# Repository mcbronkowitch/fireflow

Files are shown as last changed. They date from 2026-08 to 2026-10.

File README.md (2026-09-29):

<p align="center">
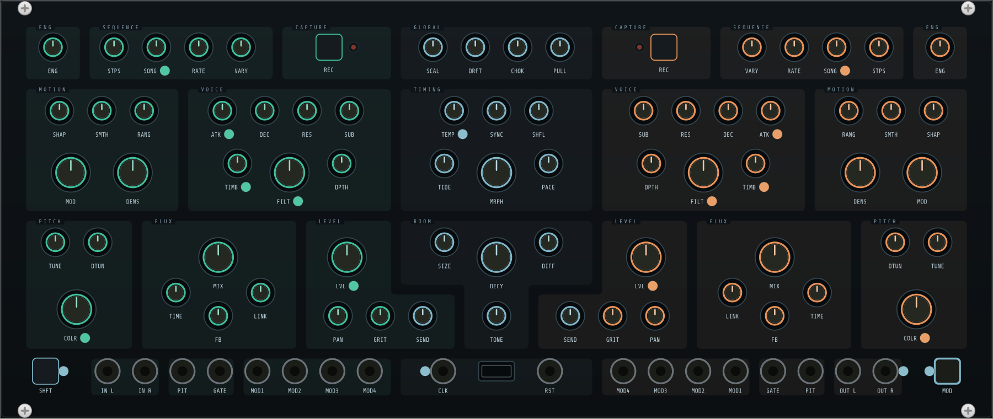
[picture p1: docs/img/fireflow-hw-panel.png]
The 60 HP FireFlow hardware panel: a dark plate with two mirrored halves — green A on the left, copper B on the right — each holding ENG, SEQUENCE and CAPTURE at the top, then MOTION and VOICE, then PITCH, FLUX and LEVEL. The centre column carries GLOBAL with SCAL, DRFT, CHOK and PULL, a TIMING gro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
  
</p>

# FireFlow — a modulation-first ambient groovebox

A digital instrument built around a single idea: **modulation is the
instrument**. Two symmetric parts, each driven by a performable modulation
engine, feeding a selectable sound source.

It runs today on the desktop and inside VCV Rack. The hardware target is a
**standalone Daisy Patch Submodule prototype**, brought up in milestone M6.

**Build log, audio demos and photos:** [fireflow.ton-k.de](https://fireflow.ton-k.de/)

> **⚠️ Not yet running on hardware.** The modulation engine currently exists
> only as a portable C++ core, verified with the desktop **offline renderer**
> (unit tests + audio/CV render) and playable through the VCV Rack host.
> Selected CPU workloads have been measured on a real Daisy Seed, and the control
> hardware is being measured on a test coupon; the firmware that turns the engine
> into a playable device is milestone M6, and it has not been built.

## What makes it different

The **modulation system is the primary interface**, and the sound engine is
whatever you point it at — not a sound engine you happen to be able to
modulate.

Each part currently points at one of five: a **polyphonic synth voice**, a
**granular texture deck** that granulates live input or a loaded sample,
**WAVE**, a digital-glassy PPG-style wavetable voice, **BODY**, a resonator
that morphs along a physical axis from plucked string through prepared piano to
struck bell, or **BBD**, a voiceless bucket-brigade delay that processes
whatever reaches it — audio input or the other deck — instead of playing
notes. The deck is deliberately not a second melodic instrument — it
is the room the synth part plays in; WAVE covers the bell, vocal-formant,
hollow-resonant, and bright-digital corner; BODY is the struck and bowed one,
and it can be excited by its own echo, by the other deck, or by the audio
input; BBD is the one deck with nothing to trigger — it has no notes, so its
five modulation lanes drive the delay's clock, feedback and mix instead of
pitch and timbre, and its own voice row retunes ATTACK/DECAY/RESONANCE/SUB/
FILT into the delay's freeze, tail, feedback tilt, input level and loss-pole
brightness. All five sit behind the same five modulation lanes and the same
voice row, so no knob goes dead when you flip the engine.

That voice-row **SOURCE** control is contextual — **TIMB** on Synth, **FRAME**
on WAVE, **MATL** on BODY, **ORG** on Sampler, and **DRIVE** on BBD — while
**Detune A/B** remains an independent per-part setting.

On the texture deck, **STEP** walks a `SliceMap` of transients marked while the
buffer is recorded or loaded: each phrase fire spawns one grain on a real
attack in the material. MOTION moves that walk from ordered playback at zero
toward free traversal. **DENS** controls runtime grain overlap; **COLOR**
becomes **FEEL** in STEP, deriving accents from the material, and spreads the
cloud's pitch in FLOW. Material without enough transients falls back to the
even tempo grid automatically, so drones and pads stay playable. FLOW still
moves continuously across the same lanes regardless of engine.

Melodic **STEP** lanes keep two persistent full-pattern snapshots, A and B.
**FORM** chooses how those phrases are composed — TWO MOTIFS, ONE + VAR,
HIERARCHICAL, CALL / RESPONSE, or OSTINATO — while **SONG** independently
arranges them as AAAB, ABAB, ABBB, BUILD, ROTATE, MIRROR, or OFF. Structural
changes land on phrase boundaries; OFF keeps A evolving while B remains stored.
On the Rack panel the PLAY row is **STEP · FORM · SONG · NEW**. NEW rebuilds
the A/B pair and, on a Sampler, also spawns a grain immediately.

Those STEP notes are not all the same note. Each deck already ranks the slots
of its groove, and **DENSE** decides how far down that ranking it fires — so
the first slot to sound is the anchor and the ones DENSE reveals sit under it.
That ranking *is* the accent: it scales how hard a note is struck and how long
it rings (the ring-time half only once **DEC** is up), which gives a dense
pattern a contour instead of a machine pulse. No knob was added for it.

Each of the two **parts** is a **SuperModulator** — one performable macro
surface (RATE, SHAPE, DENSITY, SMOOTH, RANGE, MOD) sitting on top of
**five independent modulation lanes**, one per target. Every lane has its own
phase, its own random stream and its own probability dice, running at a fixed
musical ratio of the master rate. Shared character, independent motion: the
melody can rise while the filter falls. (A single output driving all targets
would just move everything in unison — a tremolo, not an instrument.)

Each lane can run as a smooth LFO (**FLOW**), a stepped sequence (**STEP**), or
grow, loop, or erode over time (**ENTROPY**). A center section -- **MORPH / COUPLE / DRIFT / SPOT / SETTLE** -- makes the
interaction between the two parts playable. One shared **Oliverb**-based
ambient reverb turns the room into an instrument (Doppler SIZE and a DECAY that
blooms past 100 %), while each deck has its own **SEND** dry/send mix into that
shared room (the centre **ROOM** group holds the reverb itself). CV + gate
outputs extend the modulation to the rest of the rack.

The full design intent lives in
[`docs/superpowers/specs/`](docs/superpowers/specs/); this README is a
self-contained summary of it.

## Architecture at a glance

One portable engine core, three hosts. No hardware type ever crosses into
`engine/`, so the exact same code runs in the desktop renderer, the VCV Rack
module, and (later) on the hardware prototype.

<p align="center">
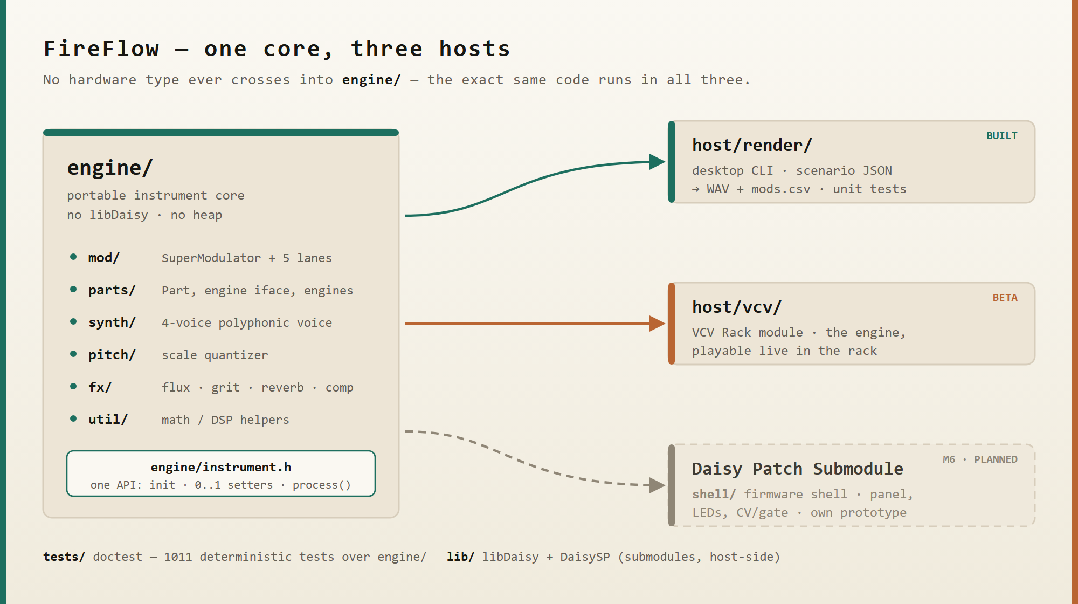
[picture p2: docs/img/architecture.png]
Architecture diagram: one portable engine/ core (mod, parts, synth, pitch, fx, util behind a single engine/instrument.h API) feeds three hosts — host/render (desktop CLI → WAV + mods.csv, built), host/vcv (VCV Rack module, beta) and the Daisy Patch Submodule prototype (shell/ firmware shell, M6, pl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
  
</p>

`Instrument` (`engine/instrument.h`) is the complete public API: `init(sample_rate)`,
normalized `0..1` parameter setters, and `process(in, out, size)`.

## Try it on the desktop (no hardware)

The engine is fully testable offline. You need a host C++ toolchain
(**clang** or gcc), **CMake**, and **Ninja**. doctest and nlohmann/json are
vendored under `third_party/`, so no test dependencies are fetched.

```bash
# optional: source a local env.sh to put your toolchain on PATH and set CC/CXX
source env.sh

cmake -S . -B build -DCMAKE_BUILD_TYPE=Release
cmake --build build
```

Run the unit tests:

```bash
ctest --test-dir build --output-on-failure
```

Configure with `-DCMAKE_BUILD_TYPE=Release`. Two of the six tests (`spky_tests`
and `ctrl_identity`) compare rendered audio against stored SHA-256 references,
and those were generated from an optimised build — a Debug configuration renders
slightly different floats and fails them with `SYNTH reference moved`.

Render a scenario to audio + a modulation trace. A scenario is a JSON timeline
of parameter changes (see `host/render/scenarios/`):

```bash
./build/render.exe host/render/scenarios/demo_step_melody.json out.wav mods.csv
```

This writes:

- **`out.wav`** — the rendered audio.
- **`mods.csv`** — every lane's output plus pitch CV / gate per part, decimated
  for plotting. Ideal for *seeing* what FLOW / STEP / MELODY actually do.

`demo_step_melody` is a good starting point: a fixed 16-step melody that loops
identically, then varies (GROW) or regenerates into new motivic phrases (RENEW)
as MELODY is dialled off center — and cycles the phrase principle.

## Play it now — VCV Rack (beta)

For a hands-on feel of the concept there's a **VCV Rack plugin** (`host/vcv/`)
that runs the same engine live — turn the knobs and hear the modulation engine
long before the M6 firmware. It's now a **beta**: real, playable Rack modules and
a permanent part of the workflow, not yet a finished instrument.

The plugin ships **two modules over the one engine core**. **FireFlow** is the
full surface: every engine setter on its own knob. **FireFlow HW Draft** is a
design study of the 60 HP hardware panel M6 is heading for, on the same engine.
Details in [`host/vcv/README.md`](host/vcv/README.md).

<p align="center">
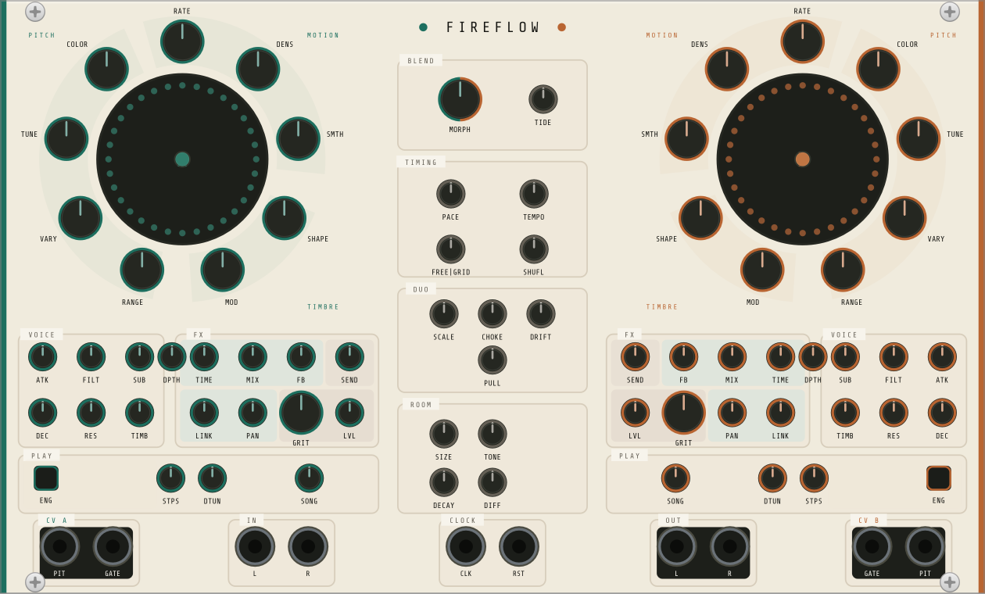
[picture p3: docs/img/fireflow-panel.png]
The FireFlow Rack module: two mirrored halves on a bone-coloured plate — green A on the left, copper B on the right — each with nine macro knobs orbiting an LED ring inside MOTION, TIMBRE and PITCH, above VOICE, FX and PLAY rows. The centre column holds BLEND, TIMING, DUO and ROOM, with the FIREFLO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
  
</p>

You can also just listen first: the [build log](https://fireflow.ton-k.de/)
carries recordings from most milestones, next to the story of how they came
about.

**[Download the latest release](https://github.com/mcbronkowitch/fireflow/releases/latest)**
— `.vcvplugin` builds for Windows, Apple Silicon and Linux, currently **2.22.0**
(both modules: Synth, Sampler, WAVE, BODY, BBD and FEED, the independent
FORM/SONG phrase arranger, the STEP mod grid lock, the PACE modulation
time-stretch, the redrawn 60 HP hardware plate with its excursion lamps, the
STEP accent, PULL's chord gravity, and the MOD layer — hold MOD and every
wreathed knob edits its own modulation depth). Unpack into Rack's user plugin
directory and restart Rack.

Building it yourself needs its own toolchain (a native MinGW/GCC compiler, not
the desktop clang path); the build, install and I/O details live in
[`host/vcv/README.md`](host/vcv/README.md).

## Roadmap

| Milestone | Scope | Status |
|---|---|---|
| **M1** | Portable engine foundation: SuperModulator, five lanes, `Instrument` API, desktop render host + tests | ✅ done |
| **M1.6** | FX: per-part FLUX (tape echo) + GRIT (drive/reduce), shared ambient reverb, FX params as modulation targets | **done** (engine + host) |
| **M2** | Polyphonic synth voice (replaces the M1 test tone) | **done** (engine + host) |
| **M3** | Capture sequencer (freeze the PITCH lane into a loop) | built, then **removed** 2026-07-14 as orthogonal to the melody rework; nothing replaced it |
| **M4** | Center section — MORPH / COUPLE / DRIFT / SPOT / SETTLE | **done** (engine + host) |
| **M4.5** | Ambient reverb v2 — Oliverb port: Doppler SIZE, DECAY > 100 % bloom, TONE; shimmer & LGPL removed | **done** (engine + host) |
| **M4.6** | Dynamics — one-knob comp per part + master limiter w/ master drive (captioned **PUSH** on the panel) | **done** (engine + host) |
| **M4.8** | Reverb dry/wet — equal-power MIX at the master join + clear-on-sleep CPU bypass | **done** (engine + host) |
| **M4.9** | Reverb DIFFUSION knob (replaces DEPTH) — room density 0–0.9, weak line-mod coupling | **done** (engine + host) |
| **M4.10** | Chord layer — COLOR knob, diatonic stacks, voice-leading, live FLOW surface | **done** (engine + hosts; hardware placement deferred) |
| **M5** | Sampler -- the texture deck: granular cloud, live recording + overdub, WAV load/save, Morphagene-style DENS/SCAN/NEW/LEN/ORG controls, clocked slice-groove, FEEL accents, and FLOW cloud dispersion | **done** (engine + hosts; released through 2.11.0) |
| **M5h** | Per-deck **SEND** mix: independent dry/send mix per deck into one shared Oliverb reverb | **done** (engine + VCV panel; released in 2.11.0) |
| **CPU** | Three measured rounds on real hardware: `instrument_worst`'s worst block went from ~156 % of the audio-block budget to 94 %, and back up to 102 % when M5j's tape tap landed (measured at 5.4 % of the block). Since then an optimization ladder (DTCM placement, an ITCM audio hotset, `-O3`) brought the selected gate `instrument_worst_bbd_dtcm` to **96.43 %** of the block on a Daisy Seed, and the whole signal path has been re-measured against it. **The engine's own worst case still does not fit**: on a Patch Submodule `instrument_worst` reads 102.27 % average / 108.62 % maximum, and whether that is a reachable operating point is an open question. Two more caveats live in `docs/roadmap.md`: every workload is more expensive on the submodule than on the Seed (reserve 2.17 points, so no Seed figure may be quoted for a submodule claim), and the intended ITCM placement does not currently link at the optimization level that ships. A debug probe is no longer needed — the bench also reports over USB-CDC. Method and every number in [`bench/`](bench/README.md) and [`docs/bench/`](docs/bench/) | **done** (ongoing as a tool) |
| **M5i** | WAVE: four-voice PPG-style wavetable part engine | **done** (engine + renderer + VCV; 65,024-byte mapped-QSPI bank; hardware-gated; released in 2.13.0) |
| **+ FORM/SONG** | Persistent A/B phrase snapshots: five FORM phrase engines plus AAAB, ABAB, ABBB, BUILD, ROTATE, MIRROR, and OFF SONG arrangements; boundary-safe changes and legacy patch migration | **done** (engine + renderer + VCV; released in 2.13.1) |
| **M5j** | BODY: one-voice-per-deck resonator part engine, morphing string -> metal -> bell, with a sympathetic excitation bus | **done** (engine + renderer + VCV; hardware-gated: `body_2x4` 295078 cycles, 30.7 % of the block, inside the spec's 29-32 % prediction and cheaper than SYNTH) |
| **BBD** | A bucket-brigade delay model, where the clock rate *is* the delay time — so RATE bends stored pitch **only transiently, while it moves**: held steady, a bucket-brigade line's pitch is unity at any clock rate. It first replaced FLUX's tape echo everywhere and now lives on as the fifth part engine only; FLUX itself is a plain tape echo again. `FXT_FLUX_TIME` is a genuine chorus/vibrato modulation lane, and STAGES has moved onto the BBD deck's own pitch lane, captioned **BEND** on the panel | **done** (engine + renderer + VCV; released in 2.17.0/2.17.1, measured on hardware — `inst_bbd_engine_worst` 96.91 % of the block at `-O3`) |
| **Modulation reachability** | Four rounds that made the modulation surface mean what it says: **PACE**, one global time-stretch from ×1/32 to ×4, because TEMPO was inert in the free world and TIDE never reached the melodic lane; the **FLOW melody engine**, so the free mode's melodic lane walks an 8-slot phrase instead of a continuous LFO; the same phrase in **STEP**, which makes FORM and SONG audible at every SHAPE position instead of only above 0.75; and **SMOOTH as a fraction of the lane interval** rather than absolute seconds, so the knob means the same thing at every rate | **done** (engine + hosts; released in 2.21.2) |
| **60 HP plate** | The hardware panel, drawn and playable in Rack as the second module: seven engine-grounded groups, eight CV inputs under the knobs they drive, and a dark anodised plate with framed fields and numbered legends | **done** as a design study (released in 2.21.2/2.21.3; still labelled `DRAFT`, no hardware ordered) |
| **STEP accent** | STEP notes get a contour from the groove rank the deck already computes: the anchor slot is loudest and longest, the slots DENSE reveals sit under it, on velocity and — once DEC is up — on ring time. No new control, no new randomness, FLOW unaffected; SYNTH, WAVE and BODY only | **done** (engine; released in 2.21.4) |
| **LED feedback** | What the panel shows while it runs: a lamp tracks the modulation **excursion**, never the knob position — one per texture lane, plus a phrase lamp per deck, a ceiling lamp for the limiter's audible onset, and the two modifier lamps. Nineteen lamps on the hardware plate, up from ten | **done** (engine + VCV `FireflowHW`; released in 2.21.5; four brightness constants still wait on real hardware) |
| **FEED** | Sixth part engine: a ring of six two-operator FM pairs per deck, free-running, where BOND morphs each modulator's input from its own feedback into its neighbour's output — the motion is the coupling, not an LFO on top | **done** (engine + hosts; released in 2.21.6; measured on a Patch Submodule, seventeen by-ear constants still first-try) |
| **M5l** | PULL: chord gravity between the two decks — a bipolar centre knob draws one deck's melody onto the other's sounding chord | **done** (engine + both VCV panels; released in 2.21.8; no listening pass yet) |
| **MOD layer** | Hold MOD and every wreathed knob shows and edits its own modulation depth instead of its sound value. The depth knobs are bipolar: right of noon the lane's continuous output, left of noon the same lane sampled and held on its own slots, noon off | **done** (engine + VCV `FireflowHW`; released in 2.21.7 and 2.21.10) |
| **AIR** | Noise/formant texture engine (working title): filtered noise through a resonant bank — wind, breath, vowel colours without sample material | planned (no spec yet) |
| **M5k** | ZAP: monophonic percussion part engine | planned (spec ready; not implemented) |
| **M6** | Hardware prototype: bring-up on a Daisy Patch Submodule — panel, controls, LEDs, CV/gate I/O, preset persistence | planned after AIR and M5k (panel design **done**, see above; **bring-up under way on a test coupon** — built 2026-09-17, measured in five rounds up to 2026-09-28; the panel scan's part 1 is built and measured on the coupon, part 2, the panel's table, waits on the pin map of Rev A, one board since 2026-09-28) |

Per-milestone detail and current status live in [`docs/roadmap.md`](docs/roadmap.md).

## Hardware prototype (M6)

The instrument's own hardware is a **standalone Daisy Patch Submodule**
prototype — panel, controls, LEDs, CV/gate I/O and preset persistence — planned
as milestone **M6**, after the two remaining engine milestones. Its **panel is
designed**, and you can turn it: the plugin's second module, **FireFlow HW
Draft**, is that 60 HP surface on the same engine, generated from
`host/vcv/res/gen_hw_panel.py` and guarded against the spec's own coordinates.

The **bring-up is under way on a test coupon** (`hardware/coupon/`): a small
board carrying the real multiplexers, shift registers, pots and reference
dividers, built on 2026-09-17 and driven by the probe firmware in `shell/`.
Five measurement rounds have run on it — settle time, crosstalk, the codec's
tone, the wait between conversions, and the pots themselves — each written up
under `docs/hardware/` (`settle-measured.md` … `pots-measured.md`). **Part 1 of
the panel scan is built and measured on the coupon**: it reads the mux pattern
cleanly and plays the engine from three of the coupon's pots
(`docs/hardware/scan-measured.md`). **Part 2**, the table for a whole panel —
70 pots, keycaps, LEDs — waits on the pin map of Rev A, which is one board
since 2026-09-28.

CPU headroom on the target MCU is not guesswork, though. Selected workloads are
measured on real Daisy hardware (a Daisy Seed, which carries the same STM32H750
at 480 MHz as the Patch Submodule) — method and every number in
[`bench/`](bench/README.md) and [`docs/bench/`](docs/bench/).

The original Spotykach firmware this project started from was removed from the
tree on 2026-09-29; [`docs/upstream-firmware.md`](docs/upstream-firmware.md)
says where it went and what of it stayed.

## License & credits

MIT — see [`LICENSE`](LICENSE) (Copyright © 2026 Synthux Academy, Bastian Tonk).

FireFlow began as a fork of
[Synthux-Academy/Spotykach](https://github.com/Synthux-Academy/Spotykach), the
official firmware for the Spotykach hardware, and reuses parts of it; it is now
an independent project with its own hardware target. It was called **spotymod**
until 2026-08-04 — releases up to and including 2.18.x carry that name.
Bundled and submodule dependencies are documented in
[`THIRD_PARTY.md`](THIRD_PARTY.md). Original firmware credits are in
[`CREDITS.md`](CREDITS.md).

Built with AI pair-programming — the **HAL 9000** co-author in the git history
is [Claude](https://www.anthropic.com/claude) (Anthropic). 🔴

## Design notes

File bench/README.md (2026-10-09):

# bench

## What this is

A measurement app that has never shipped and never will. It boots the Daisy
Seed straight into a cycle-counting harness instead of the FireFlow firmware,
runs a fixed table of workloads, and reports cycle counts and checksums back
over the debug probe. The shipping firmware is `shell/`, with its own
`Makefile` and `main.cpp`; nothing under `bench/` touches it, and the two
share exactly one board-init file, `src/hw/board.h`. This directory has its
own `Makefile`, its own `main.cpp`, and links against `alt_sram.lds` — the
same BOOT_SRAM placement `shell/` uses — so the timing context (SRAM vs SDRAM
latency) matches production.

## Profiles, and one command per profile

The bench image cannot hold every workload family at once — at `d294556` it
linked with 40 bytes of `SRAM_EXEC` and 24 bytes of `SRAM` to spare, and the
next engine took it over. A profile selects which families an image
contains.

`bench/profiles.py` is the source of truth for what ships. On this branch:

| profile | families | purpose |
|---|---|---|
| `system` | system | carries the WAVE acceptance gate; fits comfortably |
| `body` | system, body | the M5j gate: prices the BODY mode bank and KS pair |
| `bbd` | bbd | the BBD gate, on its own; no system anchor (reports undetermined) |
| `sweep` | system, sweep | the cost-curve round; system anchor prevents undetermined verdict |
| `regress` | system, bbd | gate rows and BBD kernel rows in one image, for any gate-versus-BBD A/B (introduced by the 2026-08-04 signal-path round); **`axi` only — `--itcm-hot` cannot pass placement at any optimization level, see below** |
| `ablate` | system, instr | the instrument-level ablation; measures the worst-case instrument build |
| `full` (default) | system, voice, mem, mod, abl, bbd, body, sampler | the complete run, as before profiles existed |

**`regress --itcm-hot` cannot produce a usable image, at any optimization
level, and the failure is not yours.** `spky::BbdLine::Process` is a weak
symbol; under `regress` the linker keeps the copy in the bench-harness TU
`build/workloads_bbd.o`, which `itcm_hot.lds` does not list, so the surviving
symbol lands outside ITCM and `itcm_placement.py` fail-closes. At `-O3` a
second, independent failure sits on top: the hot section overflows the 64 KiB
region and does not link. Do **not** add `workloads_bbd.o` to the hotset —
that places bench-harness code in ITCM and distorts every measurement ever
taken there. Run `regress` with `axi` until the hotset definition is reworked
(M6 work). Measured in
`../docs/bench/2026-08-04-2101349-signal-path-regression.md`.

**`full` currently fails to link, and that is deliberate, not broken.** The
engine has outgrown the image; no profile change fixes that on its own (see
the history above), and the point of profiles is to make forward progress
possible without hiding the debt. Running `python run.py` with no
`--profile` resolves to `full` and fails at the link step with an
SRAM/SRAM_EXEC region overflow. For a build that actually links and
measures today, name a profile:

```
python run.py --profile system
```

From `bench/`. This builds the bench firmware for the named profile,
verifies that the separately programmed WAVE bank matches the current
linked QSPI payload, loads only the SRAM side of the image through the
debug probe, and captures its semihosting output **twice** (`--repeat 2` is
the default — see "Anchor mode's audio" below for what that means out
loud), compares the two runs' unique row sets and checksums, enforces every
 gate the profile declares on every run, and writes both complete captures
 to `../docs/bench/YYYY-MM-DD-<githash>-<profile>-<layout>-<optimization>.md`
 and `.csv`. The layout is `axi` by default or `itcm-hot` with `--itcm-hot`.
 The optimization identity is `o2` (the default, `-O2`), `o3` (`-O3`), or
 `o3-lto` (`-O3 -flto`), selected with `--optimization`. The CSV carries a
 run index, the profile name, the execution layout, optimization identity, the live QSPI
 payload digest, and a SHA-256 device fingerprint on every row; the Markdown records those
identities, a gate ledger (which gates ran and passed, and which were not
applicable and why), and both offline/anchor tables. Exit code 0 means at
least two runs passed every gate the profile declares and both were
persisted. A missing/extra/duplicate row, checksum drift, identity drift,
non-numeric WAVE result, WAVE result slower than SYNTH, or WAVE maximum at
or above the 960,000-cycle block budget exits nonzero and writes no
accepted evidence. Every profile-derived callback anchor must appear exactly
once with finite numeric values, and every decision-gate row must be numeric;
malformed/timeout gate data exits nonzero before CSV, Markdown, or a combined
program-and-run receipt is persisted. A valid over-budget DTCM+BBD result is
still archived as rejected evidence rather than being treated as malformed.

Useful flags: `--profile NAME` (default `full`; see the table above and
`bench/profiles.py` for what ships), `--repeat N` (default and minimum 2),
`--out-dir DIR` (default `../docs/bench`), `--build-only`, `--no-build`,
 `--timeout SECONDS` (default 600, per run), `--interface CFG` (see below),
 `--program-qspi`, `--itcm-hot`, and `--optimization {o2,o3,o3-lto}`.
 `--itcm-hot` links the pre-registered audio hotset into ITCM and makes
 `run.py` inspect the linked ELF before any QSPI helper or benchmark SRAM load.
 The preflight fails closed if `nm`, `objdump`, or `readelf` is unavailable,
 or if the hot section, load segment, representative symbols, or DTCM
 instrument storage are missing or misplaced. Use the flag consistently for
 build, QSPI binding, and measurement so the host can reject an AXI/ITCM
 mix-up.

The bench builds without `-ffast-math -funroll-loops`. The Makefile used to
name them in `C_USR_FLAGS`, which libDaisy never reads; the completed
compiler-mode selection deliberately did not activate them, and the dead line
was removed on 2026-10-09. The benchmark reports its requested `o2`, `o3`, or `o3-lto`
identity; the measured winner is `o3`, the shipping firmware sets
`override OPT := -O3` (`shell/Makefile`), and LTO remains rejected.

## Programming the WAVE bank

The 65,024-byte bank is a loadable `.qspiflash_data` section at
`0x90100000`. It sat at `0x90040000` until 2026-08-07, which is the Daisy
bootloader's own target address for a `BOOT_SRAM` app image — see
*Two transports* below for the map and why that address is off limits.
It is deliberately not part of the debug probe's SRAM load. The build creates
four distinct artifacts:

- `build/bench.elf`: authoritative linked image and map source;
- `build/bench-sram.elf`: `.qspiflash_data` removed; the ELF OpenOCD loads
  for measurement;
- `build/bench-qspi.bin`: only `.qspiflash_data`, exactly 65,024 bytes;
- `qspi_programmer/build/qspi-programmer.elf`: a temporary SRAM-only helper
  used solely to erase, write, compare, and hash that raw payload.

Do not use `make program-dfu` for this custom layout. libDaisy's generic rule
expects one flat `build/bench.bin` beginning at the BOOT_SRAM app address;
an image spanning SRAM and QSPI is not that format. `run.py` builds only the
ELF and extracts the two physical payloads explicitly.

Before the first WAVE run, or whenever `bench-qspi.bin` changes, run the
four steps below. Every command names `--profile system`: it is the only
profile that links today (see "Profiles, and one command per profile"
above — the WAVE bank itself, `engine/synth/wt_bank.cpp`, is compiled
unconditionally regardless of profile, so any linking profile would carry
the same 65,024 bytes, but `system` is also the profile that exercises the
WAVE acceptance gate this bank is for), and steps 1, 3, and 4 must agree on
it exactly: the identity check in step 4 compares that rebuild's
ELF/SRAM-ELF/QSPI/programmer-ELF hashes against the receipt step 3 wrote,
and a different profile produces a different ELF even when the QSPI bytes
are unchanged.

1. Build with `python run.py --profile system --build-only`.
2. Connect the ST-Link to the Seed's SWD header and power the Seed.
3. Run `python run.py --profile system --no-build --program-qspi --build-only`.
   Do not put the Seed into DFU mode. (`--no-build` means this step doesn't
   use `--profile` to rebuild anything — it just re-derives the QSPI payload
   from whatever `bench.elf` step 1 left behind — but passing `system` here
   too keeps the sequence consistent and avoids relying on that detail.)
4. Run `python run.py --profile system --repeat 2`.

For an ITCM-hotset experiment, append `--itcm-hot` to commands 1, 3, and 4.
Each command then performs the same mandatory linked-placement preflight
before programming or loading the target.
Do not reuse an AXI QSPI receipt for an ITCM run (or vice versa): the receipt
is bound to the exact ELF, and the firmware-reported `BENCH_BEGIN` layout is
checked before any evidence is accepted.

The programming command uses OpenOCD to load the helper below `0x24040000`
and the raw payload at `0x24040000`; it never programs internal flash. The
helper erases one 64 KiB external-QSPI block at offset `0x100000`, writes
exactly 65,024 bytes, invalidates the mapped cache, compares every byte at
`0x90100000`, and reports the live SHA-256 plus the MCU UID over semihosting.
Only an exact success record writes `build/qspi-verified.json`. The receipt
binds that target-verified digest and UID to `bench.elf`,
`bench-sram.elf`, `bench-qspi.bin`, and the helper ELF.
Even with `--no-build`, `run.py` re-inspects `bench.elf` and regenerates both
physical artifacts before accepting the receipt.

### The receipt breaks on any engine change, and step 1 is not optional

The heading above says "whenever `bench-qspi.bin` changes", which understates
it. The receipt binds the verified digest to the **ELF hashes**, so *any*
change under `engine/` invalidates it even though the bank's 65,024 bytes are
untouched. The failure looks like this:

```
ERROR: QSPI verification receipt does not match current payload (artifacts)
```

That message names the artifacts, not the bank, and it does not mean the QSPI
is corrupt or that a different Seed is attached — those have their own checks
(the live digest comparison and the MCU UID match). It means the binding is
stale. The fix is to re-run steps 1 and 3; nothing needs erasing.

**Do not skip step 1 and go straight to step 3.** With `--no-build`, step 3
binds to whatever `bench.elf` is lying on disk. If step 4 then relinks
anything — and it will, after an engine change, because step 4 rebuilds — the
hashes it computes differ from the ones step 3 wrote and the run aborts with
the message above, having already reprogrammed the bank for nothing. Build
first, bind second, measure third. Running it in the other order costs a full
programming cycle and reads like a hardware fault.

Every measurement also SHA-256 hashes the 65,024 live bytes through the
Seed's memory-mapped QSPI interface before `BENCH_BEGIN`; the host compares
 that firmware-reported digest with the extracted payload. `BENCH_BEGIN` also
 reports the Seed's 96-bit MCU UID, the `axi` or `itcm-hot` execution layout,
 and the requested optimization identity. The UID must strictly match the
 programming receipt, and every repeat must report the requested layout and
 optimization. Together these checks catch a different
 Seed, a later QSPI overwrite, blank/wrong QSPI, or a stale/mixed execution
 layout even if an old local receipt remains. Public CSV and Markdown evidence
 persist the payload digest and a stable SHA-256 fingerprint of that UID,
 not the raw device identifier. The exact audit receipt
 (`qspi-verified.json`) intentionally retains the raw UID because it is the
 device-binding record used to reject a different Seed. The tracked O2/O3
 receipts already follow that policy; their bytes and hashes are unchanged by
 this documentation correction. Hardware evidence is refused from a dirty Git
 tree.

Programming this address overwrites the leading bank region and therefore
invalidates whatever BOOT_SRAM/BOOT_QSPI application was previously stored
in the Daisy bootloader's app slot; remnants beyond the 65,024-byte write may
remain. The bench itself starts directly from SRAM through OpenOCD.

## Hardware setup

The measurement itself uses the debug probe's SWD cable: 4 wires (SWDIO,
SWCLK, GND, and 3V3, or just GND+SWD if the probe supplies its own power)
from the ST-Link to the Seed's SWD header. The Seed's micro-USB port is usable
as a power source but is not used for DFU or reporting. If anchor mode is
going to run (it always does, as part of the family-1 sweep), have
monitors connected to the Seed's audio out at **low volume** first — see
below for what you'll actually hear.

## The probe

This desk's probe is an ST-Link V3, and openocd needs `stlink-dap.cfg` to
get a real DAP out of it — that's `run.py`'s default and the value
confirmed working in Task 1. Plain `stlink.cfg` auto-selects the older
`hla_swd` transport, under which `spotykach-sram.cfg`'s
`transport select dapdirect_swd` line is an error, not a fallback path.

If a different probe is on the desk, the other candidates to try via
`--interface` are `cmsis-dap.cfg` (CMSIS-DAP probes) and `stlink.cfg`
(older ST-Link V2/V2-1 hardware, accepting the `hla_swd` limitation). Both
are untested against this bench.

## Reading the table

- **avg cyc / max cyc** — DWT cycle counter reading for the workload's
  `process()`, averaged and maxed over the repeated calls in one bench pass.
- **avg % / max %** — the same, as a percentage of `BUDGET_CYCLES` (960 000
  cycles: 480 MHz core clock, 96-sample block, 48 kHz). Over 100% means the
  workload alone would blow the audio block budget.
- **checksum** — an 8-hex-digit accumulator folded from every sample the
  workload produced. It exists so the compiler cannot optimise the workload
  away as dead code, and it is what the `--repeat 2` determinism check
  compares between runs. A workload whose output legitimately depends on
  uninitialized memory or wall-clock timing will show up here as drift.
- **TIMEOUT** — the row's `avg_cyc` field reads the literal string `TIMEOUT`
  (and `pct_avg`/`pct_max` are empty) when the workload ran past 10× the
  block budget; the runner aborts it rather than letting one bad workload
  hang the whole sweep. A `TIMEOUT` row still carries a `max_cyc` and a
  `checksum` from the point it was cut off.

## Fallbacks

**(a) If the SRAM load ever stops working**, use `--transport usb`, which
is that bootloader image path and now exists. Still do not reach for
libDaisy's generic `make program-dfu`: it programs one flat
`build/bench.bin` covering SRAM *and* QSPI, which is not this layout.
`run.py` writes `build/bench-sram.bin` — the ELF with `.qspiflash_data`
removed, flattened — and the bank is a separate write.

**(b) If semihosting itself is not available** — a board with no debug pins
soldered on, for instance — use the USB transport. It is no longer a
fallback sketch; it is built, measured, and described in *Two transports*
below. It was written here as untested for a long time; it is not untested
any more, and what it costs is known to the cycle.

## Two transports

`BENCH_TRANSPORT` picks how a number leaves the board. `semihost` is the
default and the transport every capture in `docs/bench/` before 2026-08-07
was taken over.

| | `semihost` | `usb` |
|---|---|---|
| Wire | SWD, ARM `bkpt 0xAB` serviced by openocd | USB-CDC |
| Loader | openocd writes the SRAM image directly | `dfu-util` via the Daisy bootloader |
| Needs | an ST-Link on the SWD header | the bootloader in internal flash, and the cable that already powers the board |
| Repeats | openocd resets between them | the bench returns to the bootloader itself |
| Costs | nothing | **+0.66 % of the block budget** |

Run it with `python run.py --profile regress --transport usb`. `--port`
defaults to `auto`, which takes whichever serial port appears after the
image is loaded — the board is in DFU while being written and only
enumerates as CDC once the new image runs, so it cannot be named in
advance.

**The first run of a session needs two button presses**: tap RESET, then
BOOT during the bootloader's 2-second window. After that the bench jumps
back with `DAISY_INFINITE_TIMEOUT` after `BENCH_END` and waits there, so
every following repeat is unattended. If the Daisy bootloader is not on the
board at all, install it first: hold BOOT, tap RESET, release, then
`make program-boot`.

### Numbers from the two transports are not interchangeable

USB-CDC costs **6,370 cycles per block, 0.66 % of the budget**, measured on
one Seed with everything else held constant. The cause is not the memory
map — `g_axi_layout_guard` holds every measurement object at an identical
address in both branches — it is the peripheral: the host sends a
start-of-frame every 1 ms, a block is 2 ms, and two interrupts land inside
every measured window.

The full comparison is `docs/bench/2026-08-07-transport-semihost-vs-usb.md`.
Compare like with like: a submodule capture belongs against a Seed capture
over the *same* transport, where the surcharge cancels. USB captures carry
a `-usb` suffix in their filename for exactly this reason.

### The QSPI map

| Region | From | To | What |
|---|---|---|---|
| Bootloader | `0x90000000` | `0x90040000` | four 64 KiB sectors, reserved |
| App image | `0x90040000` | `0x90100000` | where `dfu-util` writes a `BOOT_SRAM` image |
| WAVE bank | `0x90100000` | +65,024 B | `.qspiflash_data` |
| Free | | `0x90800000` | |

**Do not put anything back at `0x90040000`.** libDaisy's
`core/Makefile` sets `FLASH_ADDRESS = QSPI_ADDRESS` for `APP_TYPE =
BOOT_SRAM`, so that is the address the next `dfu-util` invocation
overwrites. The bank lived there until 2026-08-07 and it was never
noticeable, because with a probe attached openocd loads SRAM directly and
QSPI belongs to the bank alone. Without a probe the two collide. The
shipping firmware links the same `alt_sram.lds` and had the same defect.

The bank can be written over DFU (`dfu-util -a 0 -s 0x90100000 -D
build/bench-qspi.bin -d ,0483:df11`) on a board with no probe. It cannot be
read back: the Daisy bootloader answers a QSPI *upload* with a single 4 KiB
block repeated across the whole range, identical at every address, so an
upload is not weaker evidence than a probe readback — it is none. The
probe-free proof is the firmware's own: it hashes the bank in place and
reports the digest in `BENCH_BEGIN`, which `run.py` checks as line one
arrives.

## The one hard rule, and which transport it belongs to

**On `semihost`,** the bench binary requires an attached, running openocd
session. Its `report.cpp` talks to the host by executing `bkpt 0xAB` (the
semihosting breakpoint) and blocking for a response; without a debugger
serving that breakpoint, the very first one halts the core forever. From
the outside that looks exactly like a hang — no crash, no error, just a
Seed that never gets anywhere near `BENCH_END`. If a run seems stuck, check
that openocd is actually attached before assuming the firmware is broken.

**On `usb`,** the equivalent trap is silence. `StartLog(true)` returns when
the CDC endpoint is configured, which is not when the host has opened the
port and started reading, and everything written in between is lost. This
already happened once: a capture arrived with 28 rows, no `BENCH_BEGIN`,
and the protocol starting in the middle. `transport_open()` therefore
spends three seconds sending throwaway lines before anything that counts —
`run.py` ignores every line before `BENCH_BEGIN`, so they are free.

## What anchor mode's audio actually proves, and what it does not

Anchor mode attempts five named workloads and re-runs the subset present in
the selected profile inside a real audio callback. The `system` profile emits
four anchors: Oliverb, the DTCM+BBD decision gate, its AXI comparison, and
`instrument_worst`. The callback drives `CpuLoadMeter` for the anchored
percentages. The DAC
output during that segment is **not** the workload's audio — it is one
value per block (`process()`'s return, the same checksum accumulator used
everywhere else in this bench) held flat across all 96 samples of that
block. That produces a roughly 500 Hz staircase built out of accumulator
sums, not a rendering of the reverb tail or the synth voice underneath it.

Consequently **every workload sounds like the same harsh buzz**, and the
anchored segments cannot be told apart by ear. This is a
**non-silence detector**, nothing more: it distinguishes "this callback
computed something" from "the optimiser deleted this workload as dead
code." The checksum is the actual anti-dead-code guarantee — it is
non-zero, it is reproducible across the two repeat runs, and it is
data-dependent by construction. Do not read the monitor output as a
listening test, and do not promise anyone they will hear a reverb, a
synth voice, or anything resembling FireFlow's actual sound in this mode.

**Anchor mode's final segment sounds broken on purpose.** `instrument_worst`
runs at roughly 160% of the block budget offline, so inside the real
callback it cannot finish before the next block is due; the DAC ends up
fed underrun garbage for that segment. That is not a bug in the bench — it
is the offline number, confirmed by ear. The block-count limit built into
the anchor callback (it stops itself after a fixed number of blocks) is
what ends that segment; an earlier version of this harness used a
foreground delay loop to pace itself instead, and because the over-budget
workload starves the very thread that delay loop needed to run on, that
version did not stop on its own — it ran for minutes until killed by hand.

Since `--repeat 2` is the default, anchor mode runs **twice** per `run.py`
invocation — expect two bursts of this harsh buzz, not one, with the
broken-on-purpose segment inside each.

One more thing the bench does that is easy to miss: it stamps
`boot_info.version` into the STM32H750's battery-backed backup SRAM and
does not restore the previous value afterwards. That marks the board as
having a "v6.1 bootloader present" for any firmware load that checks that
flag later. This has been judged harmless — it doesn't change what the
bootloader does — but it was undocumented until now, so future debugging
of boot-related oddities on this specific board should know the bench is a
possible source.

## `instrument_worst` measures the reverb in SRAM

`Instrument::init` wires its reverb pointer through `fx_mem()`, and
`bench/mem.cpp`'s `fx_mem()` hands back `&g_rev_sram` unconditionally --
there is no SDRAM variant reachable from the instrument rows. So
`instrument_worst` (and `instrument_init`) pay the SRAM reverb's cost, not
the SDRAM one. The bench's own SRAM-vs-SDRAM measurement for the same
Oliverb (`oliverb_solo_sram` vs `oliverb_sdram`, family 3) puts that
difference at roughly 1.1x -- small next to the grain-read proxy's 5.3x,
but not zero. If a future production build moves the reverb buffer to
SDRAM, expect `instrument_worst`'s headline percentage to rise by roughly
two points, not to hold at the figure recorded here.

## Row order is state, not just presentation

The `abl` instrument rows share one `Instrument` (`g_abl_inst`) and each
`setup_worst()` re-inits it, which clears the FLUX tape (`DeLine::Init`
memsets), the reverb buffer (`FxEngine::Init` calls `Clear`) and the reverb
loop filters (reset in `Oliverb::Init`). Even so, **inserting
`inst_worst_nogrit` before `inst_worst_choked` changed the choked row's
checksum** (`995dbd34` → `cd90d415`) while its cost moved 0.001 %
(841 869 → 841 859 cycles). Some state still carries between these rows and
the three obvious candidates above are not it; the cause is unpinned.

Consequences: a checksum shift on a row you did not touch, after inserting a
row *before* it, is expected rather than alarming — but it means **abl
checksums are only comparable between runs whose table order matches**, and
a genuine determinism regression could hide behind the same signature. The
same trap is documented in `workloads_system.cpp` for `g_inst_ctr`. Append
new `abl` rows at the end of the table when you can.

## The sampler family, and the two things it changed

`workloads_sampler.cpp` prices the M5 texture deck. Two structural
consequences worth knowing before touching anything near it:

**1. The bench's 64 KB arena left the SRAM region.** `Part` embeds a
`SamplerEngine` (1 392 B), and the bench's globals hold four bare `Part`s and
two `Instrument`s, so the sampler merge pushed `.bss` 6 168 bytes past the
256 KB `SRAM` region and the bench stopped linking. `alt_sram.lds` gained a
`.sram_exec_bss` section and `bench/mem.h` a `BENCH_SRAM_EXEC_BSS` macro;
`g_sram` now lives there.

This is **not** a change of measurement conditions. `SRAM_EXEC` and `SRAM` are
the same physical AXI SRAM — one 512 KB block at `0x24000000`, split into a
code half and a data half by the `MEMORY` block, same bus, same latency, same
MPU cache attributes. `grain_read_sram` measures exactly what it measured
before. The section is additive and empty in `shell/` (measured 2026-09-29),
so no shipping symbol moved either.

What it *is*: a warning. `SRAM_EXEC` now sits at **93 %** and `SRAM` at 82 %.
The next thing that overflows will be code, not data, and there is no third
half to move it to.

**2. The sampler rows own the SDRAM arena.** They run **last** in `main.cpp`
because `SamplerEngine::load_sample` takes two `float*`, so the 8 MB
`sdram_arena()` doubles as the source material both channels are copied from
(L from the front, R from an offset view — the offset is what makes both
windows land inside it exactly). Family 3 is done with the arena by then, and
every sampler `setup()` refills what it is about to read.
Anything appended after the sampler family must not assume the arena still
holds what family 3 put there.

Also note `fx_mem()` now fills `sampler_buf[]` and `sampler_frames` for every
`Instrument` the bench builds, not just the sampler rows. This costs the synth
rows nothing in the measured window — `SampleBuffer::init` → `clear()` takes
the `_size == 0` fast path on a buffer nothing has written to, and an
unselected engine's `process()` is never called — so their numbers are
unchanged. Only `setup()` touches it.

**What the rows found.** `inst_sampler_worst` is the same box as
`instrument_worst` with both parts swapped to the sampler, and it is *cheaper
on the mean block and more expensive on the worst* — the peak clears 100 % of
the budget while the mean stays under it. Anyone reading the sampler rows for
a "does it fit" answer has to read the max column, not the avg column.

The first reading of that shape was "a spawn burst," and it was wrong. The
ablation rows below exist because that guess did not survive being measured:
`inst_sampler_nomotion` moved the peak by 0.3 points, and `_slowspawn` — 75x
fewer spawns — made the peak *worse*. What it actually was is grain-count
variance. The spawn interval carries MOTION's ±75 % jitter while the grain
length does not, so short intervals stack grains and the live count wanders
5..11 where DENS asked for 8; per-block cost is linear in that count. Counted
exactly rather than timed (`Grain::process` calls per block), the worst case
spread 1.36x with the jitter and 1.01x without.

`kSpawnHeadroom` (`sampler_config.h`) caps the live count at
`ceil(overlap) + kSpawnHeadroom`. At the shipping value of 2,
`sampler_flow_worst` reads 1.18x peak-to-mean instead of 1.33x, and
`sampler_worst_nomotion` — the row that settles the mechanism, and the reason
it has to be a SOLO row — reads 1.01x on hardware, matching the offline count
exactly. The constant also sets how far tape mode may stretch a grain, so its
value is an ear decision; the table is at the constant.

Two traps this left behind, both worth knowing before adding a row here:

- **A `_nomotion` row at the instrument level does not remove MOTION.**
  `Part::_active` defaults to all-true, so zeroing a target's base leaves its
  lane still swinging it. The first version of that row measured the
  unablated peak and read as "not MOTION" — the wrong answer, arrived at
  confidently. It now calls `set_target_active(..., false)`.
- **After the cap, a high peak-to-mean ratio means a low mean, not a high
  peak.** The ceiling makes the worst block constant (the ceiling's worth of
  grains); what the SIZE lane varies is the mean, by sweeping `grain_len`
  over a factor of ~300. `inst_sampler_slowspawn`'s 1.6x is that, not a
  burst.

One thing deliberately **not** a row: `SamplerEngine::init()` on a buffer
holding content ends in `clear()`, which memsets 16 MB of SDRAM. That is real
and it is expensive — far past 10x the block budget, so as a table row it
would only ever print `TIMEOUT`. It belongs nowhere near an audio thread, and
this paragraph is the record of it.

## Adding a workload

Add one row to the relevant `kXxxWorkloads[]` table (`workloads_system.cpp`
for family 1, `workloads_daisysp.cpp` for family 2, `workloads_memory.cpp`
for family 3, `workloads_mod.cpp` for the modulation plane, `workloads_abl.cpp`
for the ablation rows, `workloads_bbd.cpp` for the bucket-brigade delay,
`workloads_sampler.cpp` for the texture deck) with a
family tag, a name, a setup function and a process function. A new *table*
additionally needs its `extern` in `workload.h`, an entry in `runner.cpp`'s
`find_workload` arrays (and its loop bound), a loop in `main.cpp`, and the
source in the `Makefile` — five places, none of them automatic, because table
order is execution order and must not depend on link order. Workload **basenames must stay unique across the whole bench**,
not just within one file's table — libDaisy's Makefile flattens every
source path with `notdir` when it builds the object list, so two files
named e.g. `voice.cpp` in different directories would collide at link time
even though their paths differ.

## The bbd family, and why its rows are worst cases on purpose

`bbd_ceiling` runs `BbdEcho` with the clock pinned to `kClockMaxHz` and
`STAGES` at `kMaxStages` — the combination that maximises tick rate and cell
array size at once. It is a ceiling, not a typical patch, because the design's
whole CPU claim ("the taps pay for the BBD and nothing more") is only settled
by the worst case: cost here is driven by clock Hz, not by delay time, so a
typical setting would still leave the ceiling unmeasured. `bbd_line_only`
strips the compander and drive path to split the ceiling's cost between the
model and the surrounding device; `bbd_walk_sdram` isolates the line's
sequential-write memory access pattern.

## WAVE direct-engine gate

`system/synth_2x4` and `system/wave_2x4` are an intentionally matched
direct-engine pair. Each row owns two engines seeded `3` and `4`, initializes
them at 48 kHz, sets decay to `1`, cycle to 2 s, and FLOW false, and triggers
the exact pitches `{0.25, 0.35, 0.45, 0.55}` on both engines. One measured
call processes both engines for exactly the 96-sample block, accumulates all
four L/R outputs, and folds both active-voice counts into the checksum.

The 2026-07-24 Task 8 firmware gate now builds. The generated ARM-only
placement puts the 65,024-byte `kBankSamples` at `0x90040000`. Serial system
rows construct their measured objects in one max-sized lifetime arena;
construction of the next row destroys the previous group before reusing the
same aligned AXI storage. The 64 KiB `g_sram` measurement arena remains in
physical AXI SRAM. The linker split was moved 736 bytes inside that same
contiguous 512 KiB AXI block; no measured object changed bus, cache, or
latency class.

The accepted build-only map is deliberately recorded because the margins are
tight:

```text
DTCMRAM     8,604 / 131,072 bytes   6.56%
SRAM_EXEC 262,864 / 262,880 bytes  99.99%  (16 bytes free)
SRAM      261,384 / 261,408 bytes  99.99%  (24 bytes free)
QSPIFLASH  65,024 / 8,126,464 bytes 0.80%
```

`build/bench.elf`, `build/bench-sram.elf`, and the exact 65,024-byte
`build/bench-qspi.bin` are produced. The receipt-bound `build/bench.elf` used
for the final runs is 3,728,648 bytes. `g_sram` maps to `0x240302d0`,
`g_system_arena` to `0x240606c0`, and `kBankSamples` to `0x90040000`.

The first full hardware traversal exposed a bench-only failure after
`modal_voice`, while setting up `string_voice`. The fault was an imprecise
bus error (`CFSR=0x00000400`) in newlib `rand`: its first call lazily
allocated a 24-byte state object, then allocator metadata/state writes crossed
the AXI boundary at `0x24080000`. The linked image had `_ebss=end=0x2407ffe8`,
leaving exactly 24 bytes and no room for allocator overhead.

The harness therefore supplies its own deterministic, heap-free `rand` and
`srand`. Its five-byte logical state occupies eight aligned bytes in DTCM;
the linked `rand` symbol comes from `build/rand_shim.o`, whose undefined-symbol
set is empty. A bench-only NOLOAD layout reservation absorbs the removed
newlib text so all measured engine objects retain the accepted AXI addresses.
Production firmware and DaisySP are unchanged. Before this shim, the corrected
accepted map used 8,596 DTCM bytes; the eight-byte state accounts for the
8,604-byte figure above.

Because `.dtcmram_bss` is NOLOAD and the startup handler clears only the AXI
`_sbss.._ebss` range, `main` explicitly calls the shim's `srand(1)` after
hardware initialization and before any workload. This both overwrites retained
DTCM state on every debug reset and keeps the target `srand` entry point in the
linked image. The final symbols are `srand=0x240010f4` and
`rand=0x24001104`; disassembly shows the call from `main` before the first
`run_workload`.

The controller completed two full hardware runs on 2026-07-25 from commit
`8c5f2e1`. Both reached `BENCH_END`; the fail-closed controller accepted
identical unique 68-row sets and checksums; and both verified that the live
QSPI SHA-256 and MCU UID matched the programming receipt. The persisted
payload digest is
`ac234ac7f7540ed5cd0e8b8496b84fca8084a3b2c05cc513aa4dad8ed811fc27`;
the stable, non-raw device fingerprint is
`1157cbd949e6c4100daa57d61d85e016d57e733f949f39e9a967add1e5e22dc8`.

| run | `synth_2x4` avg/max | `wave_2x4` avg/max |
|---|---:|---:|
| 1 | 340,347 / 346,106 | 308,497 / 312,180 |
| 2 | 340,342 / 346,105 | 308,503 / 311,962 |

In both runs WAVE is lower than Synth on both average and maximum cycles, and
both WAVE maxima are below the 960,000-cycle block budget. Task 8 therefore
passes its direct-engine acceptance gate. The generated
`docs/bench/2026-07-25-8c5f2e1.md` and `.csv` persist both complete runs,
including both anchor sets, the QSPI digest, and the hashed device fingerprint.

The `66d359d` attribution values came from minimal diagnostic binaries because
the full parent bench did not link. Those diagnostics retained the exact
parent engine code and the exact Task 8 workload setup/process: 96-sample
blocks, a 100-block warmup, then 1,000 blocks measured with DWT. Parent
`lane_step_shape00` measured 27,971 / 29,042 average/maximum cycles versus
28,040 / 29,050 in the current full bench, changes of +0.247% / +0.028%.
Parent `synth_1_voice` measured 52,967 / 53,880 versus 55,576 / 56,570,
changes of +4.925% / +4.993%. The displayed parent diagnostic average/maximum
cycle values—not a checksum claim—were exact repeats across two captures.
The current full captures differ slightly in cycles as recorded above, while
their checksum comparison reported no drift. Both parent/current changes are
within this bench's documented cross-build noise. The roughly 11,614-cycle
lane figure in an older report predates intervening lane and workload-shuffle
changes; it is not the `66d359d` diagnostic comparator.

The verdict is protected by the receipt-bound live-payload check, target UID
check, full-run terminator, repeat-run checksum comparison, heap-free random
shim, explicit reset-safe random seed, fixed QSPI bank placement, and unchanged
measured AXI object addresses. Production firmware and DaisySP remain
unchanged.

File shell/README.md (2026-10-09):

# `shell/` — die erste Firmware, die die Engine enthält

Der Shell ist die kleinste Firmware, die `engine/` auf einem Daisy Patch
Submodule laufen lässt: Board hoch, den Speicher injizieren, den `FxMem`
verdrahten, `spky::Instrument::process()` im Audio-Callback. Er ist der
Beweis, dass der portable Engine-Kern die Werkbank verlässt — bis hierhin
lief `engine/**` ausschließlich unter den Desktop-Hosts, den CMake-Tests und
der Bench. Seit dem 8. August 2026 läuft er auf dem Zielboard und liefert
dort messbar Signal (siehe „Der Selbsttest" unten).

Was er ausdrücklich **nicht** ist: kein UI, keine Panel-Logik, kein
Preset-System, keine Bedienelemente. Er startet an einem festen
Betriebspunkt (`set_rate 0.4`, `set_density 0.6` auf Part A, 96 BPM) und
bleibt dort. Dass dieser Punkt tatsächlich klingt, ist nicht geraten,
sondern vorher auf dem Desktop gemessen: derselbe Betriebspunkt als
Szenario durch `build/render.exe` liefert über 5 s Peak −7,5 dBFS und RMS
−26,9 dBFS. Die Boot-Default-Engine ist `ENGINE_SYNTH`, es muss also keine
Klangquelle erst gewählt werden. Der erste Poti kommt in Task 6 des
Phase-0-Plans dazu, nicht hier.

**The line against the other firmware tree**, because the two get confused:
**`bench/`** is the measuring tool — the same linkage, but packed with workload
families, a report transport and measurement arenas, and with full DaisySP
including the LGPL modules, because it never ships. **`shell/`** is the start
of the firmware that will ship. The two share exactly one board-init file,
`src/hw/board.h`, on purpose: if each had its own board init, no comparison
between bench numbers and shell behaviour would mean anything. (The repo root
used to hold a third tree, the upstream Spotykach firmware; it was removed on
2026-09-29 — see [`docs/upstream-firmware.md`](../docs/upstream-firmware.md).)

## Bauen

**Once per clone:** fetch the submodules and build the two libraries, from the
repo root. (This used to be the root `Makefile`'s `make libs` target.)

```bash
git submodule update --init --recursive
PATH="/c/Program Files/DaisyToolchain/bin:/c/Program Files/Git/usr/bin:$PATH"
make -C lib/libDaisy -j8
make -C lib/DaisySP -j8
```

Eigene Toolchain, ARM GCC über `make`. **Niemals `source env.sh`** — das ist
die Clang-Umgebung für Engine, Tests und Render-Host, und die beiden dürfen
sich nicht mischen.

```bash
PATH="/c/Program Files/DaisyToolchain/bin:/c/Program Files/Git/usr/bin:$PATH"
cd shell && make -j8 images
```

**Never use libDaisy's `make program-dfu` or `all` for this firmware**: they
build and flash the flat, unguarded `shell.bin`. Use `images` and the two
`dfu-util` commands below.

`images` (nicht `all`) ist der richtige Zielname. libDaisys Standardziel
baut ein flaches `shell.bin` über SRAM (`0x24000000`) **und** QSPI
(`0x90100000`) hinweg — rund 17 MB, fast alles Füllbytes, an die falsche
Adresse gezielt. `images` zerlegt stattdessen dieselbe gelinkte ELF in die
zwei physischen Artefakte, genau wie `bench/qspi_tools.py` es für die Bench
tut:

| Artefakt | Inhalt | Ziel |
|---|---|---|
| `build/shell-sram.bin` | everything except the bank and the boot-only code | DFU nach `0x90040000` |
| `build/shell-qspi.bin` | the bank, then the boot-only code | `0x90100000`; flash whenever its md5 changed |

Belegung beim ersten grünen Build (2026-08-08, `-O2`):

| Region | belegt | verfügbar | |
|---|---|---|---|
| SRAM_EXEC (Code) | 183 416 B | 262 880 B | 69,8 % |
| SRAM (`.bss`, davon ~131 KB Reverb) | 199 940 B | 261 408 B | 76,5 % |
| SDRAM (Echo, BBD, Sampler) | 36 581 376 B | 64 MiB | 54,5 % |

Läuft eine Region über, **nicht** an Puffergrößen drehen: `build/shell.map`
lesen und den Posten benennen, der überläuft. Die Bench kennt dasselbe
Problem und hat es dokumentiert.

## Flashen

Das Submodule hat **keine SWD-Pins**. Alles geht über DFU (USB), es gibt
keinen Debug-Probe-Weg und keinen Semihosting-Weg auf diesem Board.

```bash
dfu-util -a 0 -s 0x90100000 -D build/shell-qspi.bin
dfu-util -a 0 -s 0x90040000:leave -D build/shell-sram.bin
```

Das Board muss dafür im DFU-Modus sein: **RESET drücken, dann BOOT im
Zwei-Sekunden-Fenster.** Anders als die Bench springt der Shell am Ende
nicht selbst in den Bootloader zurück — die Bench tut das, weil sie
wiederholt geflasht wird, der Shell soll laufen. Jedes Neuflashen kostet
also die zwei Tastendrücke.

**Always flash both images, QSPI first**, as above. `shell-qspi.bin` carries
the wavetable bank (`.qspiflash_data`, at `0x90100000`) **and** the boot-only
code that executes in place from QSPI (`.qspi_cold`, at `0x90110000`; the list
and its rules are in `qspi_cold.ld`, the link-time guard is
`qspi_placement.py`). The SRAM image calls into that code at fixed addresses,
so the two images of one build are a pair. **A mismatched pair** -- a new
`shell-sram.bin` over an older shell's or the bench's QSPI contents -- jumps
into whatever lies at those addresses during boot: it hard-faults or hangs
before USB comes up, so the board stays dark and no serial port appears. The
cure is flashing the matching `shell-qspi.bin` (DFU buttons again), then the
SRAM image.

The QSPI command has no `:leave`, so the bootloader stays in DFU mode and the
SRAM command follows directly; only if dfu-util then reports no DFU device,
press RESET, then BOOT within two seconds, and run the SRAM command. The bank
keeps `0x90100000`, where `bench/` and `bench/audition` expect it; coming back
from a bench or audition session, flash both images again before the shell
runs.

## Der Selbsttest, und warum es ihn gibt

Das Submodule hat keine Klinkenbuchse. „Macht es Ton" lässt sich ohne
Verdrahtung also nicht hören — aber messen: mit `SHELL_SELFTEST=1` läuft der
Shell seinen eigenen Ausgang eine Sekunde lang (500 Blöcke à 96 Samples)
über einen Peak-Detektor und legt das Urteil auf die User-LED.

| LED | Bedeutung |
|---|---|
| dunkel, bleibt dunkel | `main()` kam nie bis `StartAudio` — Init, SDRAM oder Audio |
| schnelles Flackern, 10 Hz | wir warten, der Callback kommt nicht durch |
| **Dauerlicht** | Callback lief 500 Blöcke, der Ausgang führte Signal |
| langsames Blinken, 2 Hz | Callback lief, der Ausgang war still |

Vier Zustände statt zwei, weil „dunkel" sonst gleichzeitig *still* und
*hängt beim Booten* hieße — das wäre kein Beweis, sondern ein Rätsel.

```bash
make -j8 SHELL_SELFTEST=1 images
```

**Default ist aus, und das ist der wichtige Teil:** der Detektor sitzt im
Audio-Callback und kostet dort Zyklen. Task 6 misst an genau dieser Stelle
den Shell-Aufschlag; ein mitgeschleppter Selbsttest liefe in diese Zahl
hinein.

**Ergebnis 2026-08-08, Submodule `3859386B3330`: Dauerlicht.** Vorher wurde
einmal bewiesen, dass die LED überhaupt „still" sagen *kann* — dasselbe
Image mit `kSilenceFloor` künstlich auf `1.0f` (über dem erwarteten Peak von
0,42) blinkt langsam. Ohne diesen Gegenbeweis wäre Dauerlicht keine Messung,
sondern eine Zusicherung. Was damit **nicht** gezeigt ist: wie es klingt.
Der Ausgang ist nicht verdrahtet, das Hören steht aus.

## Offener Befund: ein Störton auf der Blockrate

**Der Shell klingt, aber er klingt nicht sauber.** Am 8. August 2026 auf dem
zweiten Submodule (Seriennummer `385138563330`, Audio auf 3,5-mm-Buchsen)
gehört und gemessen: ein Störton mit konstanter Amplitude auf der
Audio-Blockrate, dazu hörbares Zerren des Synths. **Der Shell ist damit
nicht fertig, sondern gerade so weit, dass man den Fehler sehen kann.**

Was gemessen ist — Aufnahme über ein Audiointerface, FFT, Vergleich gegen
den Desktop-Render desselben Betriebspunkts:

| Beobachtung | Zahl |
|---|---|
| Störton relativ zum Gesamt-RMS, Board | 4,9 dB darunter |
| dieselbe Größe, Desktop-Render | 33,0 dB darunter |
| **Überschuss** | **28 dB** |

Was dadurch **ausgeschlossen** ist, jeweils durch eine eigene Messung:

- **Die Hardware.** Ein intern erzeugter Sinus und ein reiner Durchleiter
  laufen durch denselben Codec, dieselbe DMA, dieselbe Analogstufe, dieselbe
  Masse und dasselbe USB — und sind sauber (Störton −90 dBFS statt
  −59 dBFS). Kein Lötfehler, kein Brummen, keine Versorgungsfrage.
- **Der Audioeingang.** Der Durchleiter zeigt ihn als praktisch still
  (RMS −73,8 dBFS, kein Anteil auf der Blockrate).
- **Die Optimierung.** Der Ton überlebt den Wechsel von `-O2` auf `-O3`
  unverändert (−58,5 → −59,5 dBFS). `-O2` war trotzdem ein echter Fehler in
  diesem Makefile und ist korrigiert.
- **Das Steuerraster der Engine.** `Center::kCtrlInterval` steht fest auf 96
  Samples und hängt nicht an der Blockgröße. Bei Blockgröße 192 **wandert**
  der Ton von 500 Hz auf 250 Hz mit. Er gehört also zur **Blockgrenze**,
  nicht zum Steuerraster.

- **Eine CPU-Überlast.** Das war die naheliegende Erklärung, und sie ist
  **widerlegt**. `SHELL_CPU_PROBE=1` misst an diesem Betriebspunkt
  **62,78 % avg, 65,30 % max, 48,42 % min** (5 000 Blöcke, `sr=48000`,
  `block=96`, vom Board selbst gemeldet). Das sind 35 Punkte Luft. Zur
  Einordnung: die Bench-Zeile `instrument_init` liegt bei 66,58 / 77,96 %,
  die Messung ist also plausibel. Der Callback hält seine Frist.

Die Sonde hat nebenbei eine falsche Annahme korrigiert: die Blockgröße ist
**96**, nicht 48. Eine frühere Schätzung aus Phasendauern eines
Diagnose-Images war falsch — deshalb meldet die Sonde `sr` und `block` jetzt
selbst mit, denn eine Last in Prozent ist ohne die Blockgröße, gegen die sie
gerechnet wurde, bedeutungslos.

- **Die Blockarithmetik der Engine.** `tests/test_block_size_invariance.cpp`
  rendert denselben Betriebspunkt mit `n=1` und mit `n=96` und verlangt
  Übereinstimmung besser als −60 dB relativ zum Signal. Der Test ist grün.
  (Er hat eine echte Lücke geschlossen: `host/render/main.cpp` ruft
  `process(..., 1)` auf — **ein** Sample pro Aufruf, die gesamte
  Desktop-Historie ist mit `n=1` entstanden, die Firmware ruft mit `n=96`
  auf.)

### Und was es stattdessen ist

**Der Störton steht nicht in den Samples.** Ein Bau, in dem die Engine voll
läuft, ihr Ergebnis aber verworfen wird und der Callback nur Nullen
schreibt, liefert den Ton bei **exakt demselben Pegel**:

| Bau | RMS | 500 Hz |
|---|---|---|
| Engine, Ausgang normal | −54,6 dBFS | −59,5 dBFS |
| Engine läuft, Ausgang auf Stille gezwungen | −59,7 dBFS | **−59,5 dBFS** |
| Engine läuft, Stille, **Blockzeit leergedreht** | −63,9 dBFS | **−67,0 dBFS** |
| Engine aus, Durchleiter (Referenz) | −73,8 dBFS | −90,1 dBFS |

Er erreicht den Ausgang also, **ohne den Signalweg zu benutzen** — eine
Einkopplung, kein Rechenfehler. Und er hängt daran, wie die Rechenaktivität
innerhalb des Blocks verteilt ist: wird die Leerlauflücke mit einer
`nop`-Schleife gefüllt, fällt er um **7,5 dB**.

Nicht um mehr, und das ist die ehrliche Einschränkung dieses Versuchs: die
Füllschleife ist nur *zeitlich* konstant, nicht *inhaltlich*. Der
Engine-Anteil rechnet mit SDRAM und FPU, der Füllanteil dreht `nop` — das
Stromprofil bleibt im Blocktakt moduliert, nur schwächer. Der Versuch stützt
die Erklärung „block-periodisches Aktivitätsprofil", er beweist sie nicht,
und **zwischen Versorgungsrippel, Masseeinkopplung und Abstrahlung trennt er
gar nicht.**

**Konsequenz, und sie ist wichtiger als die Ursache:** das ist ein Befund
über den **Aufbau**, nicht über die Engine. Kein Grund, an `engine/` etwas
zu ändern. Für Phase 1 heißt es dagegen sehr wohl etwas — Entkopplung,
Trennung von analoger und digitaler Versorgung und der Abstand zwischen
Codec-Analogteil und den Schaltströmen des MCU gehören auf dem eigenen PCB
bewusst entworfen und nicht gehofft.

**Der nächste Schritt, wenn jemand die Ursache wirklich will:** denselben
Betriebspunkt auf einem Daisy Seed mit dessen eigenem Audioausgang messen.
Zeigt der es auch, steckt es im Modul; zeigt er es nicht, im Trägerboard.
Das ist eine Messung und keine Vermutung, und sie kostet einen Boardwechsel.

## Panel scan part 2: Rev A's pin map (P6a)

Spec: `docs/superpowers/specs/2026-10-02-rev-a-p6a-panel-scan-design.md`.

**The step model.** Rev A enables one 4051 per sense pin per step (P2 §3),
so a step reads up to four channels: 24 steps, 48 ms a sweep. `mux_plan.h`
calls this *parallel*. The coupon probes keep the *sequential* model they
were measured with (`kCouponChain`, unchanged). The coupon play image
(`SHELL_PANEL_SCAN=1 SHELL_COUPON_PROBE=1`) runs the coupon's wiring with
Rev A's model (`kCouponPlayChain`): the 4067 and the 4051 live together.

Since P6a, `mux_plan.o` builds with `-Os` and the firmware drops the `kParams`
name strings (`SPKY_NO_PARAM_NAMES`), so a `SHELL_MUX_PROBE` re-run is not
like-for-like with the 2026-08-23 bench numbers.

**The table is generated.** `python shell/gen_panel_map.py` writes
`shell/generated_panel_map.h` from `hardware/reva/panel-map.json`,
`hardware/reva/blocks.py` and `control/params.hpp`. Never edit the header;
`shell_panel_map_guard` regenerates and compares it. Since P6b-1 the 73 rows
split 70 that send the shared control law's id of their own name (the
`FireflowHW` control at that position) and 3 reserved (`ROOT_A`, `ROOT_B`,
`REV_MOD`: pots on the plate that send nothing and have no parameter yet).
P6a's "safe"/"unmapped" split is retired. A pot added to the panel with no
`control/params.hpp` id stops the generator until it gets one or is reserved.

**Keys and LEDs.** Every step reads the 165 in the same pass as the write;
keys debounce over three reads (6 ms). LED bits only ever travel in the latch
that carries the mux address (P2 §4). On Rev A the keys have no function yet.

**The span** comes from CAL_GND and CAL_3V3 once per sweep; until a sweep has
measured a valid one, no knob reaches the engine.

**Reading it.** The coupon prints part 1's `SHELL_PLAY` line plus
`SHELL_PLAY_IO keys= presses= adc11= adc12=`. Rev A prints eight
`SHELL_PLAY_V r=<first row> <up to ten values>` lines — 73 rows, so the
last line carries three (row order and names are in
the generated header's comments; values ×1000, −1000 = never emitted: no valid span yet, i.e. calibration
never succeeded) and one
`SHELL_PLAY` summary line with key mask and press counts. Both images then
print `SHELL_PLAY_LAW cyc_last=<n> cyc_max=<n>`: the shared control law's
cost in DWT cycles, the last block's tick and the worst since the first
second (the first 500 blocks are left out of the maximum, which reads 0
until then, so a cold-cache boot tick cannot pin it) (spec
2026-10-09-rev-a-p6b1 §6: above 9600 cycles, one point, the tick moves to
every second block). **Measured on the coupon, init patch, `-O2`
(2026-10-09): `cyc_last` 11 800, `cyc_max` 13 900** (1.23 and 1.45 points),
over the 9600 budget; the tick stays once per block by decision (spec §6,
"Outcome"). Plan B is the two-block split, triggered by clicks or by
`cyc_max` above 2.9 points on the Rev A board with the full panel.

**Coupon session** (spec §7) on the coupon play image:
1. All three pots reach both stops; at rest their printed values do not change.
2. Press SW1 five times: `presses=5`; LED_1 is lit while SW1 is held.
3. Hold SW1, pots untouched: `rv2`/`rv4`/`rv6` do not change.
4. Jumper `TP_ADC12` (D9) to `TP_AGND` and `TP_ADC11` (D8) to `TP_A3V3`:
   `adc11` reads near `zero`, `adc12` near `rail`. Swap the jumpers: they
   swap. (The coupon's test points carry its netlist's old D8/D9 names; P2 §2
   corrected them.)

## The shared control law (P6b-1)

Spec: `docs/superpowers/specs/2026-10-09-rev-a-p6b1-shared-control-law-design.md`.

The playing images no longer hand a pot to an engine setter. A pot that
emits writes `lo + v·(hi − lo)` of its parameter's VCV range into a knob
vector (`knob_from_pot()`, rounded for a parameter Rack snaps), and once per
audio block `control_tick()` runs the whole vector through
`control::ControlLaw` — the law `FireflowHW` runs in Rack — so every pot
drives what its VCV twin drives. At boot the vector is the init patch,
depths included, and the law is re-armed as for a patch restore. Rev A's
ATTACK rows carry STAGES as an alternate id (`ControlEntry::alt`, from
`panel-map.json`'s `ids`), written while the deck is on the BBD
(`knob_target()`). The law
builds with `-O2` (`control_tick.o`; it was `-Os` first, like `mux_plan.o`): at `-O3` the Rev A
image kept 2.7 KB of `SRAM_EXEC` free, under the spec's 8 KB floor; with
`-Os` it keeps 10 088 B. The generated tables in `control/params.hpp` being
`inline` and linked once brought that to 11 584 B; the ATTACK alternate and
the `cyc_max` warm-up then cost 376 B, leaving 11 208 B (2026-10-09).
After the retiming setters' unchanged-value early-outs and the repeated
squaring in `ModLane::_update_slew`, which took newlib's double `pow` out of
the image (it had no other caller), 19 592 B are free (2026-10-09). The
law's sent-value cache (a setter is called only when its value changed) and
two reorderings in `mv()` and the depth loop then cost 1 704 B, leaving
17 888 B (2026-10-09). `-O2` for the law instead of `-Os` cost 960 B more
and took the tick from 15 800 to 11 800 cycles: 16 928 B free (2026-10-09).

**Known divergences from VCV (P6b-1)** — spec §8:

- Depths are the init patch's and cannot be edited (P6b-2).
- After a BBD edge the hardware's FLUX stays at its pot value; VCV's knob
  drops to zero. The law's events are ignored: a physical pot cannot be
  turned back.
- A Sampler deck is silent: no factory sample, no REC yet.
- No CLOCK, RESET or CV on the hardware.
- The ATTACK pot is two Rack knobs at one position: it writes STAGES
  ("BBD Bend") while its deck's ENGINE is on the BBD and ATTACK otherwise,
  as FireflowHW shows them. Turning ENGINE does not copy the pot's position
  into the newly shown parameter: that one keeps its last value until the
  pot moves, where Rack shows the other knob at its own value.

## Where the work stands, and where it goes next

*Rewritten 2026-09-28 in English, like everything added to the repo since
mid-August. The section it replaces (German, last touched 2026-08-23) still
pointed at a first pot on a breadboard `74HC4051`; that path was overtaken by
the test coupon. Git history has the old text.*

**What this shell is today: the measuring firmware for the control
hardware.** Since 2026-09-17 it drives the test coupon (`hardware/coupon/`) —
a small board with the real 74HC4067/4051 multiplexers, the 595/165 chain,
seven pots and fixed reference dividers — through a family of probe images,
each behind its own build switch, each with a host reader and a guard, each
written up under `docs/hardware/`:

| switch | what it measures | reader | write-up |
|---|---|---|---|
| `SHELL_COUPON_PROBE=1` (alone) | bring-up: every channel, rescanned live | `read_coupon.py` | `hardware/coupon/README.md` |
| `+ SHELL_SETTLE_PROBE=1` | settle time after a channel change | `read_settle.py` | `settle-measured.md` |
| `+ SHELL_XTALK_PROBE=1` (`SHELL_XTALK_RV4`) | crosstalk from the board's own digital edges | `read_xtalk.py` | `crosstalk-measured.md` |
| `+ SHELL_TONE_PROBE=1` (`SHELL_TONE_DC`) | the codec's own output against a settled channel | `read_tone.py` | `codec-tone-measured.md` |
| `+ SHELL_WAIT_PROBE=1` | the wait between conversions | `read_wait.py` | `wait-measured.md` |
| `+ SHELL_POT_ROUND=1` (on settle or wait) | the pots at mid travel, both questions | `read_pots.py` | `pots-measured.md` |
| `+ SHELL_SCAN_CHECK=1` | the panel scan's pattern: clean at one step per block, with the engine running | `read_scan_check.py` | `scan-measured.md` |
| `SHELL_PANEL_SCAN=1` (± `SHELL_COUPON_PROBE=1`) | the playing image: the scan drives the engine through the board's control table | `SHELL_PLAY` line | — |

The probe switches are mutually exclusive; the Makefile refuses a
combination that makes no sense. Older switches still in the Makefile —
`SHELL_SELFTEST`, `SHELL_CPU_PROBE`, `SHELL_MUX_PROBE`, `SHELL_IDLE_FILL` —
belong to the August engine-on-board work above.

**Two results from August still hold and still steer the design.** The mux
scan goes **in the audio callback**: it costs less than the CPU measurement
resolves, and a foreground scan raised the block-rate tone by 7.3 dB while
the callback left it unmoved (2026-08-23,
[`docs/bench/2026-08-23-978cbaf-shell-mux-placement.md`](../docs/bench/2026-08-23-978cbaf-shell-mux-placement.md)).
And the engine's CPU reserve on this board is **~2.9 points**, measured
directly (`docs/bench/2026-08-19-3def5d5-feed-axi-o2-patch_sm-usb.md`) — no
Seed number may stand in for it.

**What the coupon has settled** (details in the write-ups): the ADC clock is
6.146 MHz, not the 12.29 MHz libDaisy's comments imply; a channel change
settles within 2.0–4.8 µs at pot impedance, measured on real pots; and a
channel read once per audio block at the working sampling rung reads a pot up
to ~650 counts low, which the 387.5-cycle rung removes at every wait.

**And the scan budget is done** (arithmetic,
[`docs/hardware/scan-budget.md`](../docs/hardware/scan-budget.md)): the long
rung is not needed. The ~650 counts come from converting after an idle. The
pattern this shell already runs never idles: libDaisy's free-running DMA,
twelve channels, `SPEED_16CYCLES_5`, `OVS_32`. It reads at pot impedance what
the long rung reads, and it fits one mux step per block, written in the
callback and read one block later, with ~300 µs to spare. Full sweep 64 ms on
the 16:1, 48 ms on the 8:1.

**Next, in order:**

1. **Part 1 of the panel scan is done.** Spec
   [`docs/superpowers/specs/2026-09-28-coupon-panel-scan-design.md`](../docs/superpowers/specs/2026-09-28-coupon-panel-scan-design.md),
   measured on the coupon and written up in
   [`docs/hardware/scan-measured.md`](../docs/hardware/scan-measured.md).
   Board session 2 played `SHELL_PANEL_SCAN` on the coupon, and RV2, RV4 and
   RV6 all moved the engine audibly, and all three reached both stops (RV4's
   low stop in a later read the same day). **Part 2 (P6a) is built**: the
   Rev A scan, the generated table (70 rows at P6a, 73 since the 9 mm panel pass; keyed by global mux 0-9 plus
   channel, unique; the sense pin rides along as a host-tested check field),
   35 pots sending, the four keys on the 165, and the span calibrated from
   two channels. Code space is tight: `SRAM_EXEC` is 99.10 % on the coupon
   play image and 99.35 % on the Rev A play image. The coupon session
   (2026-10-03, `docs/hardware/scan-measured.md`) passed checks 1–3; check 4,
   D8/D9 as ADC_12/ADC_11, is deferred to P7 bring-up by decision.
2. **Skipped on the coupon, by decision (Bastian, 2026-09-28):** round one's
   four RV4 cases (`SHELL_XTALK_RV4=1`) — the scan check already read every
   channel clean in the real pattern, with the engine running — and a second
   populated board, which is worth building only once a control-PCB decision
   hangs on the LED-word finding (`crosstalk-measured.md` row 7). Both remain
   runnable; neither blocks anything.

**The switch headers are written while the Makefile is parsed, not by a
rule** — with a rule, the build produced two byte-identical images for two
switch positions on 2026-08-23, because make has one-second resolution here
and the header landed in the same second as `main.o`. The reasoning sits in
the Makefile above `SWITCH_HEADERS`; whoever tidies it away reopens a
measurement trap. `cmp` two switch positions before flashing either.

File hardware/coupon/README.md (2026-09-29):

# The FireFlow test coupon

A 100 x 80 mm, 4-layer board built around one **Daisy Patch Submodule**, whose
sole job is answering the eight measurement points the M6 hardware envelope
spec puts before panel layout can start —
[`docs/superpowers/specs/2026-08-08-fireflow-hardware-envelope-design.md`](../../docs/superpowers/specs/2026-08-08-fireflow-hardware-envelope-design.md)
§5, addendum 2026-08-30 — chief among them the ADC mux settle time
(`docs/hardware/settle-budget.md`'s prediction, confirmed here rather than on
a breadboard, because the model is linear in node capacitance and a
breadboard's jumper-wire capacitance has no defined value). It is not a
prototype of the instrument: both mux chip footprints, an unpopulated `COM`
capacitor pad, a probe point on `COM`, two pot values side by side, hard-tied
rail neighbours, fixed-divider reference channels, the real 74HC595/74HC165
chain, and the supply topology as a switchable 0R link are the whole circuit.
The full layout act — placement, zone plan, routing — and its reasoning live
in [`docs/superpowers/specs/2026-08-31-coupon-layout-design.md`](../../docs/superpowers/specs/2026-08-31-coupon-layout-design.md).

## Building it

Two generators, run in order, each under a different interpreter:

```
"C:\Users\bernd\AppData\Local\Programs\KiCad\10.0\bin\python.exe" scripts\build.py
"C:\Users\bernd\AppData\Local\Programs\KiCad\10.0\bin\python.exe" scripts\build_pcb.py
```

Both need KiCad's own Python (`pcbnew` is not on the system interpreter's
path) — `build.py` first, because `build_pcb.py` places parts from
`netlist.build()`, the same intent `build.py`'s own proof chain already
checked against the exported schematic netlist. `build.py` writes
`coupon.kicad_sch`, the ERC report and the schematic PDF; `build_pcb.py`
writes `coupon.kicad_pcb` and runs ten proof steps in order, aborting on the
first red one — net comparison, courtyard/shadow placement sanity, plane
connectivity, stitch-copper hygiene, ratsnest, the five analog rules of the
layout spec's Section 4, a final DRC pass (`proof/drc.rpt`), and render +
Gerber/drill export. `scripts/review.py` (same interpreter, once
`build_pcb.py` has written a board — Section 6 of its output reads
`coupon.kicad_pcb` through `check_layout.py`) writes `proof/review.md`, the
sheet meant for actually reading: requirements, channel plan, the Eurorack
connector, BOM, known ERC violations, and the layout section — placement
table, the four numeric analog-rule measurements, and the two families of
measured-but-not-gated deviations (the long 0R ties and the moat-crossing
address bus, both below).

## Stuffing it

`scripts/assembly_plan.py` draws the sheet you actually solder from, because
the fabricated board cannot be read: 0805 parts sit on a 2 mm pitch and their
reference designators need about 5 mm, so the silkscreen overlaps itself and
the analog corner is one grey smear. The board renders under `proof/` have the
same problem for the same reason.

```
python scripts\assembly_plan.py
```

**This one runs under the system interpreter** — it reads `coupon.kicad_pcb`
and nothing else, so no `pcbnew`, no symbol libraries, no KiCad install. Every
number in it is read rather than transcribed: placement, rotation, courtyard
and pad positions come from the footprints, and the part values come from each
footprint's own `Value` property — the same field the BOM in `proof/review.md`
reports. Re-run it after any placement change and the drawing follows; there is
no hand-kept table to drift.

It writes two sheets:

- **`proof/coupon-assembly.svg`** — the working sheet. The whole board, the
  analog corner enlarged, and a stuffing list with one row per reel. All 78
  parts named, coloured by value, with pad 1 marked at its measured position
  (the notch end on the SOIC chips) and a bar on each LED's `_K` pad.
- **`proof/coupon-overview.svg`** — the same geometry at a width that survives
  a narrow column, with eight numbered zones instead of 78 labels. This is the
  one the journal prints, with the assembly sheet linked beside it.

Labels are placed by search, and the script checks its own work: a slot is
rejected if it touches a part body, another label, a leader already drawn or
the board outline, and a leader may not cross a part unless nothing legal is
left. It prints how many labels needed that fallback (one, as of this writing)
and exits non-zero if any part ends up unlabelled or any two labels overlap.

The website keeps its own copies under different names:

```
python scripts\assembly_plan.py --out-dir ..\..\..\FireFlow_Website\public\media\site --prefix fireflow-hw-coupon
```

**`coupon.kicad_pcb` is generated fresh by every `build_pcb.py` run, but the
file is byte-reproducible.** `pcbnew` orders every UUID-keyed item —
footprints, the individual track/via segments sharing a net, and the zone
filler's own bookkeeping — by whatever random UUIDs that run happened to
mint, so an unseeded build reorders on every run even with no source edit
at all (measured, fix-round probe, 2026-09-02: two unseeded builds from the
identical committed source diffed at 26226 lines — `git diff --no-index`,
default context, `| wc -l`; the exact count varies run to run since it
depends on which random UUIDs each pair of builds draws, but it is
reliably five figures).
`hardware/gen/kipcb.py`'s `new_board()` seeds `pcbnew`'s UUID generator with a fixed constant
before creating anything, which makes that whole order reproduce identically
— two from-scratch builds under the same seed produced a 0-diff
`coupon.kicad_pcb`. Regenerating and committing the file is therefore safe
and expected; a real content change is the only thing that should still show
up in `git diff`.

**Every other generated file still shows as modified after each run — that
is expected, and it is timestamps only.** All 32 of them (every gerber,
`coupon.drl`, both board PNGs, `drc.rpt` and `drc-placement.rpt`) embed a
`CreationDate`/wall-clock line KiCad regenerates on every export; the
content underneath is unchanged (confirmed by diffing a gerber with its
`CreationDate`/`Created by ... date` lines excluded: 0 lines differ). Discard
this churn with `git checkout -- hardware/coupon/fab` and, under `proof/`,
every file EXCEPT `review.md` (`coupon-board-front.png`,
`coupon-board-back.png`, `drc.rpt`, `drc-placement.rpt`) — `review.md` is
`review.py`'s own real content, not timestamp noise, and committing it is
the point of that step.

## The two solder jumpers switch one way only

Envelope spec §5 point 8 asks for the supply and ground topology "as a
switchable 0R link, not as a second board variant: the same copy with and
without is the better measurement." **On this board the "without" half of
that does not exist.** `AGND` and `A+3V3` reach the rest of the world
through `JP_GND` and `JP_3V3` and through nothing else — the Eurorack header
grounds pins 3..6 to `GND` (`scripts/netlist.py:139`) and the submodule's A10
feeds `+3V3` (`:97`). Open both jumpers and the analog island is unpowered
and unreferenced; both muxes lose VCC. Point 8 is not met as built, and no
ordering of the measurements recovers it. A second board does not either:
its open state is the same off state.

**What the open state is still good for, and only before the jumpers are
soldered:** meter `TP_AGND` against `TP_GND`, and `TP_A3V3` against
`TP_3V3`. Both must read open. Continuity there means copper crosses the
1.0 mm moat somewhere it should not — a defect in exactly the separation
point 8 is about, and one that is invisible for good once the jumpers are
bridged. A continuity check is an unpowered measurement anyway, so this costs
nothing but the order it is done in.

**Do not power the board with the jumpers open.** It is tempting — the
digital half needs neither of them — but the six address and enable nets run
from `U_SR1` straight into both muxes, whose `VCC` is `A+3V3` and whose `GND`
is `AGND` (`scripts/netlist.py:149`). With `JP_3V3` open that `VCC` floats
while `U_SR1` drives those inputs at 3.3 V, which forward-biases the muxes'
input clamp diodes and powers the chips parasitically through their own
address pins — above the absolute maximum rating of `VCC + 0.5 V`, with
latch-up as the failure mode. The current involved is microamps and it will
very probably survive, but nothing is gained by finding out. Nor can it be
avoided by not running the scan: `~OE` is tied to `GND` and `~SRCLR` to
`+3V3` (`:258`), so the 595 outputs are driven from the instant power is
applied, with whatever the shift register powered up holding. **Meter first,
then bridge both jumpers, then apply power** — in that order, once.

**What does not work is a second join by wire.** The only two places where
both planes are probeable are `TP_AGND` at (10.00, 66.00) and `TP_GND` at
(94.00, 3.00) — 105.0 mm apart, the board's full diagonal. A wire that long
is a component and not a connection, the same trap the `COM` rule below
names.

**A substitute for the lost A/B, neither reviewed nor measured:** change the
link's impedance instead of removing it. A ferrite bead or a small resistor
across `JP_GND`'s pads answers "how good does the single join have to be" at
the designed star point. It costs one rework cycle on a pad, and whether an
0603 lands cleanly on `SolderJumper-2_P1.3mm_Open_Pad1.0x1.5mm`'s 1.3 mm
pitch is unchecked.

**Struck 2026-09-28: point 2's "capacitor at `COM`" case will not be
measured.** Bastian decided against the capacitor test; `C_COM16`/`C_COM8`
stay unpopulated on every board, and "fit none" (`docs/hardware/settle-budget.md`
§4 finding 1) stays arithmetic. The paragraph below is kept as the record of
what that board would have needed.

**A second board for point 2's "capacitor at `COM`" case need not be fully
stuffed.** It needs the submodule and its sockets, `J_PWR`, the bulk caps,
both jumpers, `U_SR1`/`U_SR2`, one mux, `R_REFA1`/`R_REFA2`, the decoupling
caps and the capacitor under test. No pots, no button, no 165, no LEDs —
LEDs only if the round is chasing noise rather than time, which is the load
they are there for (`scripts/design.py:115`).

## Bringing it up

**First powered board, 2026-09-17.** Everything populated except the seven
pots, both solder jumpers bridged, and every measurement below taken with the
Patch Submodule *out* of its sockets. That is the whole scope of what a
module-less power-up can prove: `+3V3` reaches the board only through the
submodule's A10 (`scripts/netlist.py:97`), so with the module out no chip on
either side of the moat has a supply. A dead board is the expected state here,
not a fault.

**Nothing has to be counted, and no reference designator has to be read off
the silkscreen.** Two signatures identify everything:

- **Which bulk-cap pad is ground.** Probe between a pad of `C_BP12` and a pad
  of `C_BN12`, all four combinations: exactly one reads 0 Ω, and those are the
  two ground pads. The opposite combination is +12 V against -12 V.
- **Which socket pin is which.** With one probe on a ground pad, walk the
  other along bank A's ten pins. Exactly two read 0 Ω (A4, A7 — same column,
  one per row), exactly one reads ~1.6 kΩ (A10, `+3V3`), the rest are open.
  A1 and A5 being open is correct: with no module, ±12 V has no DC path to
  ground at all.

Bank A is the 2×5 group at the lower right of the module outline, beside
`J_PWR`, long axis horizontal. Holding the board component side up with the
pot/jack edge at the bottom and the header to the right: **lower row, right to
left, is A1..A5; upper row, right to left, is A10..A6**, so A1 and A10 share
the column nearest the header. (Pad coordinates: `scripts/placement.py`'s
module docstring, transformed by the 180° placement.)

Measured, in the order taken:

| check | reading | what it proves |
|---|---|---|
| across `C_BP12`, across `C_BN12` | 16–17 MΩ, climbing | no short on either ±12 V rail; nothing but the cap loads them |
| `C_BP12` pad vs `C_BN12` pad, 4 combinations | one at 0 Ω, opposite open | rails separated; identifies both ground pads |
| across `C_B3V3` (`+3V3` vs `GND`) | **1.6 kΩ** | see below |
| same, with `SW1` held down | **1.4 kΩ** | `R_BTN` and the button |
| bank A sweep against ground | A4, A7 at 0 Ω; A10 at 1.6 kΩ; rest open | the pin numbering, without counting |
| A1 vs `J_PWR`'s north pins, A5 vs its south pins | 0 Ω (0.1 Ω probe contact) | the ±12 V copper reaches the module |
| **powered:** A1, A5, A10 against A7 | -12 V, +12 V, **0 V** | polarity, and that nothing feeds `+3V3` |

**The 1.6 kΩ is the single most informative reading on the board, and it is
not a fault.** Three reference dividers sit across the analog rail —
`R_REFA1/A2` 20k, `R_REFC1/C2` 20k, `R_REFB1/B2` **2k** — and in parallel
they predict 1.67 kΩ, with the 1k divider dominating. Pressing `SW1` puts
`R_BTN`'s 10k in parallel and predicts 1.43 kΩ. Both landed. Because the
dividers hang on `A+3V3`/`AGND` while the meter sat on `+3V3`/`GND`, that one
reading also proves **both jumpers conduct** — the current goes out through
`JP_3V3` and back through `JP_GND`.

Two practical notes:

- **Park the black probe in A7, not A4.** Both are ground. A7's neighbours A6
  and A8 are unconnected, so a slipped probe there does nothing; A4's
  neighbour is A5 at +12 V.
- **The bulk caps hold ±12 V for minutes after power-off.** Against their own
  measured 16 MΩ leakage and nothing else, the time constant is about 160 s
  (arithmetic from the measured value, not timed). Meter A1 and A5 down to
  ~0 V before the module goes in, or bleed them through a resistor.

**What was not measured, and cannot be any more:** the moat continuity check
this README asks for above — `TP_AGND` open against `TP_GND`, `TP_A3V3` open
against `TP_3V3`. The jumpers were bridged first, and after that both pairs
read 0 Ω whether the moat is clean or shorted. On this board that answer is
gone for good.

**The seven pots went in the same evening, 2026-09-17** — the RV09 vertical
parts from `order-bom.md`, RV3/RV4/RV7 at 20 k and the other four at 10 k. The
support lugs were slightly too large for the board's slots and were clipped
off; each pot hangs on its three solder joints alone, with no glue under the
body. RV4, the tight position between `JP_GND` and `R_SP11`, clears both
with a visible gap, and its case reads open against GND (checked
2026-09-28, board unpowered). (This README said "still unpopulated" until 2026-09-28; the board had
not been in that state since the 17th.)

With the pots in, the bring-up scan read all seven wipers at **63481…63485**
at the clockwise stop, against 63484…63486 on the rail-tied reference channels
(commit `084d702`'s message; no capture is committed). The counter-clockwise
readings were taken but not recorded. That is a **wiring check, not a
characterisation**: at either stop a pot's source impedance is near zero, so
neither reading says anything about settle time or the wait effect. The
hard case — mid travel, R/4, 2.5 kΩ at 10 k and 5 kΩ at 20 k — was measured
on 2026-09-28 on RV2, RV4 and RV6: [`docs/hardware/pots-measured.md`](../../docs/hardware/pots-measured.md).
For that round the pots were set to mid travel on the bring-up scan, to what
`REF_A` reads there, and not touched until both probe images had run.

## Layer and zone map

4 copper layers, y growing downward from the board's top-left corner:

| layer | carries |
|---|---|
| `F.Cu` | signal routing, both plane nets' stitching vias/tracks |
| `In1.Cu` | ground -- **two filled zones**, `GND` under the digital half of the board and `AGND` under the analog half, joined only at `JP_GND` |
| `In2.Cu` | supply -- **two filled zones**, `+3V3` under digital and `A+3V3` under analog, joined only at `JP_3V3`, sourced from the module's own A10 (+3V3 OUT) |
| `B.Cu` | signal overflow where `F.Cu` is blocked, plus the address/enable bus (see below) |

`±12V` is never a plane -- it runs as short, wide (0.8 mm) point-to-point
track, IDC header -> SM supply pins -> bulk caps, per the layout spec's
Section 3.

The board splits into two domains, full board width each, with a 1.0 mm moat
between them (narrow enough that both solder jumpers' fixed 1.3 mm pad pitch
still straddles it): **digital**, y 1..47.6 mm (the shift-register chain,
LEDs, Eurorack header, bulk caps), and **analog**, y 48.6..79 mm (both
muxes, the pots, reference dividers, the audio jack). This is a horizontal
split, not the left/right one the layout spec's Section 3 describes on
paper -- the Patch Submodule's own pad layout decided it: rotated 180 deg so
its sense pins (A2/A3) and audio pins (B1/B2) face the board's bottom edge,
both analog anchors end up on the module's south side, so analog is
everything below it and digital is everything else. `placement.py`'s module
docstring has the full measured reasoning (probed pad coordinates, why 90/270
deg were never an option).

**Two known deviations are measured, printed by `check_layout.py` and
`review.py`'s Section 6, and deliberately not gated** -- fixing either is a
placement-level rework, not something Task 6 (or any task before an order)
attempts:

- **Six of the eight 0R neighbour ties sit well away from the mux pin they
  carry**, against "directly at the mux pin" of the layout spec's Section 4
  rule 3. The measured spread is a continuum, not a few outliers — only
  `R_LO3` (5.99 mm) and `R_HI1` (8.88 mm) are genuinely at their pin, and
  the three longest (`R_HI3` 20.56 mm, `R_HI4` 22.53 mm, `R_LO4` 22.77 mm)
  are barely further out than `R_HI2` (18.97 mm) and `R_LO2` (20.05 mm).
  Read the table in `proof/review.md`, not a count. The longest three sit
  where they do because the only F.Cu approach within reach also carries the
  8:1 mux's own enable pin, which cannot lose its route.

  **What this is expected to cost — reasoned, not measured.** These ties
  hold the *neighbour* channels at a rail while the measured channel settles
  (`docs/hardware/settle-budget.md` §6). A neighbour tied through 0 R is a
  static node: 22 mm of copper leaves it essentially at the rail, and a node
  held at constant DC is a poor aggressor. Charge injection at the address
  switch decays through the extra trace inductance in nanoseconds, against a
  1.6 µs window. So this is expected to be irrelevant to the experiment the
  coupon exists to run — rule 3 is good hygiene here, not a hard
  requirement. The coupon itself is the instrument that would settle it;
  settle-budget.md §5 names crosstalk as what its model is blindest to.
- **Five of the address/enable bus's six nets cross the moat on the board's
  west edge, 70-74 mm from the star point** `JP_GND`, against Section 3's
  "beside the star point." All six originate at `U_SR1`, which sits in the
  far-west digital column (beside the LEDs) rather than beside `JP_GND` on
  the far east -- the crossing follows the source pin, not a routing choice
  that could have moved it without re-placing `U_SR1`.

The same fix (re-pitching the 8:1's column and its west approach) would
touch both. Nobody has done that work yet.

## Before this board is ordered

**Populate copies, never rework one board** -- the fab ships a handful of
identical boards either way, and any question a stuffed board could answer
by soldering something differently is answered by populating a second copy,
not by reworking the first. **Jumper the digital side freely, but never the
`COM` node or the audio path** -- everywhere else a wire is a connection;
on `COM` or on `AUDIO_OUT_L`/`AUDIO_OUT_R` a wire is a component, and the
whole point of measuring on a board instead of a breadboard is that neither
of those paths carries an unmodelled jumper-wire capacitance.

One thing still needs hands on a real board, and one that used to is now
closed (`docs/roadmap.md`'s M6 section carries the up-to-date status):

1. ~~**The Eurorack bus board**~~ -- **closed 2026-09-02, metered.** This
   was the one connection on the whole board with no part datasheet behind
   it: an IDC 2x5 box header's own drawing is mechanical only, and the
   pinout comes from Doepfer's A-100 standard instead.

   **The standard was read first, and it does answer pins 7/8** -- the
   16-pin ribbon runs in pairs (-12V, GND, GND, GND, +12V, +5V, CV, Gate)
   and the 10-pin connector is its first ten conductors, so 3..8 are all
   `GND` and +5 V starts no earlier than 11/12. `review.py`'s Section 3
   carries the sources. **7/8 stay open regardless**, as insurance against a
   non-standard board rather than against a +5 V that the standard does not
   put there; it costs two ground pins.

   **Then the bench answered the part no document could:** Bastian metered
   the bus board and it follows the standard -- red stripe on `-12V`, `GND`
   on 3..8, `+12V` on 9/10. Polarity was the only failure mode that costs
   the board, and it is confirmed the right way round, so this stops being
   an order blocker. Pins 7/8 stop mattering altogether rather than merely
   reading as expected: they are open here, so whatever the bus carries
   there cannot arrive.

   **The shroud deviates from Doepfer's own advice on purpose.** Doepfer
   recommends against keyed headers on bus boards, because mis-keyed boards
   and cables are common. This board keeps one anyway: a rotated or
   row-shifted plug is +/-12 V into the Patch SM, and the notch is what
   makes that impossible. Its one cost cannot be tested until the board
   exists -- a cable keyed the other way will not seat at all -- so that is
   an assembly-time check, not an order blocker. If the plug does not go in,
   the fault is the key and the answer is a different cable, never a cut-off
   nose.

   **Where the notch actually points, measured from the committed
   `coupon.kicad_pcb` on 2026-09-02** -- so nobody re-measures it: the header
   sits at (88.00, 22.00), rotation 0 deg, its pins running south to
   (90.54, 32.16), so the long axis is north-south. The shroud's outer wall
   is x 84.82..93.72, y 16.90..37.26; its **west** inner wall (x 86.02)
   breaks between y 25.03 and y 29.13, with both break ends running out to
   x 84.82. That gap is the polarising notch: 4.10 mm wide, centred on
   y 27.08, which is the pin-5/6 row and the header's own centre. Pin 1 is
   in the x 88.00 column, the notch side. **So the notch faces west, into
   the board.** That was never a free choice -- the footprint fixes the
   notch against the pin numbering and the numbering comes from the
   netlist; the only free parameter was the rotation, and it is 0 deg.

   **Mechanically this is clear on both sides.** Nothing is placed west of
   the header in the y 17..37 band (the nearest neighbour that way is `SW1`
   at y 8, well north). East of it, `C_BN12`/`C_B3V3`/`C_BP12`/`TP_3V3` sit
   on x 96.5 between the shroud and the board's east edge at x 100, but they
   are flat 0805/testpoint parts passing under a plug that rests on the
   shroud. The ribbon can therefore fold either way: 6.3 mm to the east
   edge, or out over open board to the west.
2. **The Patch Submodule's own land-pattern dimensions** -- vendored from
   Electrosmith's KiCad library
   ([`hardware/lib/README.md`](../lib/README.md)), unproven until a module
   actually seats in a fabricated board.

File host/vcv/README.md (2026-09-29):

# FireFlow — VCV Rack host

A third host over the shared portable engine (`engine/`), alongside the desktop
render host (`host/render/`) and the future Daisy firmware shell (M6). **No
engine code is duplicated**: this plugin compiles the exact same `engine/*.cpp`
sources against the VCV Rack SDK.

```
host/vcv/
├── Makefile              Rack plugin build (points SOURCES at ../../engine)
├── plugin.json           Rack plugin manifest
├── src/
│   ├── plugin.{hpp,cpp}  plugin entry + model registration
│   ├── Fireflow.cpp      Module: param→engine mapping, process(), widget
│   ├── generated_panel.hpp      GENERATED (enums + control table)
│   └── generated_hw_panel.hpp   GENERATED, the HW draft's table
└── res/
    ├── gen_panel.py      single source of truth for the panel layout
    ├── Fireflow.svg      GENERATED faceplate
    ├── gen_hw_panel.py   the same, for the 60 HP hardware draft
    └── FireflowHW.svg    GENERATED faceplate (see "FireFlow HW Draft" below)
```

## Design: one control per function (VCV-native)

The hardware Spotykach drives its ~60 parameters through capacitive pads +
hold/combo gestures (a layer that is firmware milestone **M6**, not yet built).
VCV has no clean equivalent for pad gestures, so this host deliberately maps
**every engine setter to its own dedicated knob/switch/button** — a wider panel
than the hardware, but the full engine is playable today without waiting on M6.

The visual language follows the residency devlog ("workbench paper"): a warm
paper plate with ink lettering, solder-green accents on part A (left) and
copper-orange on part B (right); MORPH wears a split green/copper collar
because it bridges the two parts. Each part's
32-LED ring is a **live** custom widget (`SpkyRing` in `src/Fireflow.cpp`): it
draws in the light layer and lights a moving dot per modulation lane from
`Instrument::lane_output()` / `lane_fired()`, so the rings animate with the
engine (mirroring the upstream Spotykach firmware's LED ring). The SVG only
provides the dim housing.
The shared centre column beside MORPH used to also carry **PUSH**, the
master drive into the output limiter; PUSH is gone (spec 2026-08-09
hw-control-reduction task 9, "push steht immer auf 0.4") and the drive is
now a fixed-by-ear constant — see [COUPLE, DRIFT, and
LVL/COMP](#couple-drift-and-lvlcomp) below for it and its two siblings.

## TIMING

**SHUFFLE** is one shared control for both parts: `0` is a straight grid and
full travel gives a classic `2:1` long/short pair. It warps only STEP timing;
FLOW stays straight. Live changes latch at each lane's next pair boundary so
the active pair finishes intact, while external CLOCK pulses, resets, phrase
downbeats, and the transport's raw-phase anchors stay straight.

## SONG

Each Part's PLAY row reads **STEP · SONG**. FORM and the NEW pad are gone
(spec 2026-08-09 hw-control-reduction): SONG alone walks a curated 14-rung
ladder through the (Principle, SongMode) grid and re-rolls the phrase on
every rung change — turn the knob, the melody develops differently.

Every rung pairs one of five phrase engines with one of seven arrangements.
The five phrase engines are **TWO MOTIFS**, **ONE + VAR**, **HIERARCHICAL**,
**CALL / RESPONSE**, and **OSTINATO** — they create the musical material.
The seven arrangements decide when the two persistent phrase snapshots A and
B are heard:

- **AAAB**, **ABAB**, and **ABBB** repeat their named four-phrase sequence.
- **BUILD** follows `AAAB · AABB · ABBB · AABB`.
- **ROTATE** follows `AAAB · AABA · ABAA · BAAA`.
- **MIRROR** follows the deterministic, non-repeating Thue–Morse A/B stream.
- **OFF** disables arrangement by playing A continuously; A still evolves,
  while the stored B phrase is retained for returning to another rung.

The factory SONG setting is rung **6** (`{0, 6}`, "no alternation, two
generators"), not the ladder's first rung — chosen to preserve the approved
HIERARCHICAL/AAAB boot sound (`song_ladder_at(6)`). SONG changes wait for
the next STEP phrase boundary, and every rung change queues a fresh A/B pair
and restarts the arrangement at its first phrase — the gesture the retired
NEW pad used to fire on demand. On a Sampler it also jumps the tape head back
to ORGANIZE and spawns a grain immediately.

## DENSITY

Each part's **DENSITY** knob (orbit caption `DENS`) picks how many of a
phrase's slots are actually used, out of however many the current mode has.
In **STEP** that has always meant thinning the step grid — k of the deck's
`STEPS` fire, the rest hold the previous note. **As of the FLOW melody
engine, it means the same thing in FLOW too**: the free mode's melodic lane
now walks an 8-slot phrase instead of running a continuous LFO, and DENSITY
selects how many of those eight notes the drone actually plays — one
standing note at the low end, up to a full eight-note melody at the top.
Before this, DENSITY was a step-grid-only control and moved no audio at all
in FLOW (`docs/attic/2026-08-13-glow-macro-audit.md`, Result 3); it is not
step-grid-only any more, on either part. On a Sampler deck DENSITY is
repurposed entirely — see the Sampler controls table below.

## SOURCE and Detune

Each part has one physical **SOURCE** control. Its live caption follows the
selected ENG — see [Engine-dependent captions](#engine-dependent-captions)
below for the full table across all five engines. SOURCE-lane modulation
moves the selected source around the knob's base value.

Each part also has one physical **DETUNE** knob, independent of SOURCE
(spec 2026-08-09 hw-control-reduction task 10) and no longer a
context-menu spread — it is a panel control now, applying a quadratic
taper: the first ~20 ct of travel is where the fine beating lives, so a
linear map would squeeze it into a fifth of the knob. The ceiling is
`105 ct` on Synth/Wave; on Body the engine's own `kDetuneScale` (4/3)
stretches the same 0..105 spread to a 0..140 ct rail. Deck A boots on
Synth and defaults to `6 ct`; deck B boots on Body and defaults to
`24 ct` (the same by-ear spread the old shared knob produced there).

The **Drive A** / **Drive B** context-menu sliders are gone (task 9):
they never reached the engine (BBD's drive target has always been a mod
lane, not a panel/menu control — see `bbd_engine.cpp`), so the dead
menu-only patch state was retired along with its `DriveQuantity`.

## COUPLE, DRIFT, and LVL/COMP

**COUPLE** swallowed the old SYNC switch (task 7): SYNC was the right-hand
end of COUPLE's own axis. Below the knob's midpoint (`kCoupleZoneSplit =
0.5`) is the **FREE** world — SYNC off, COUPLE drives the Kuramoto phase
lock between the two parts. At or above the midpoint is the **GRID**
world — SYNC on, COUPLE instead sets how tightly the texture lanes follow
the shared grid. Each zone sweeps its own 0..1 range across its half of
the knob's travel, so both worlds keep their full spread.

**DRIFT**'s left stop (the bottom `kDriftSettleZone = 0.02` of travel, not
just the literal zero) is the old **SETL** panic pad: parking the knob
there fires `Instrument::settle()` once, on the edge into the zone, not
continuously while held — a knob is not a momentary button, so this is
edge-triggered (`DriftSettleState`/`driftSettled` in `Fireflow.cpp`) rather
than re-firing on every control tick the knob spends parked there. Above
the zone, DRIFT's own 0..1 range is rescaled to fill the remaining travel.

**LVL/COMP** is one physical knob (`COMP_A`/`COMP_B`, printed `LVL`): the
lower four-fifths (`kLvlCompSplit = 0.8`) is pure per-part output level —
the engines are quiet by design, so this knob was always used as a volume
control in practice. The top fifth instead engages the compressor with
make-up gain, topping out at `kCompTop = 0.7` — the old knob's working
compression amount — so full compressor drive is no longer reachable from
the panel (deliberate: task 5/9's factory patches never asked for more).

Three controls are fixed-by-ear constants with no panel control at all
(task 9): the shared centre column's old **PUSH** master-drive knob is
pinned to `0.40`, and the reverb's **REV_SMEAR** (diffuser-LFO wash) and
**REV_MOD** (tail-delay wobble) are pinned to `0.30` and `0.15`.

## Engine-dependent captions

Nine controls change their caption with the deck's `ENG`. The words live in
`DYNAMIC_CAPTIONS` in `res/gen_panel.py` and reach both the SVG and Rack from
there — the C++ holds no caption word at all.

| Control | Synth | Sampler | Wave | Body | BBD | Feed |
|---|---|---|---|---|---|---|
| MELODY | `VARY` | `SCAN` | `VARY` | `VARY` | `VARY` | `VARY` |
| ATTACK | `ATK` | `ATK` | `ATK` | `HIT` | — (`BEND` occupies the slot) | `RISE` |
| DECAY | `DEC` | `DEC` | `DEC` | `DAMP` | `TAIL` | `FALL` |
| RES | `RES` | `RES` | `RES` | `CHAR` | `TILT` | `RATIO` |
| SUB | `SUB` | `LEN` | `SUB` | `EXCIT` | `INPUT` | `SUB` |
| FILT | `FILT` | `FILT` | `FILT` | `BRITE` | `LOSS` | `BRITE` |
| SOURCE | `TIMB` | `ORG` | `FRAME` | `MATL` | `DRIVE` | `BOND` |
| DETUNE | `DTUN` | `DTUN` | `DTUN` | `DTUN` | `DTUN` | `SPRD` |
| DEPTH | `DPTH` | `SCAT` | `DPTH` | `SWAY` | `RPTS` | `DPTH` |

DETUNE joined the table with FEED (spec 2026-08-18). It had been a fixed
`DTUN` plate, and on a FEED deck a fixed plate would lie: there the knob is
SPREAD, and it reaches the engine as `LANE_SIZE`'s base rather than through
`set_voice_detune` — the same re-point the sampler's SUB → `LANE_SIZE` already
uses.

DEPTH is the base of `LANE_MOTION`, the lane every engine already reads as
something (spec 2026-08-19 voice-knobs-dpth-edge): stereo width and per-voice
drift on Synth/Wave, drift alone on Body (`SWAY`), grain spawn-position and
spawn-interval jitter on the Sampler (`SCAT`), the feedback amount on the BBD
(`RPTS`), and the FM index on Feed. The host never wrote this base at all
until 2026-08-18, when Feed's `DPTH` knob reached it through a per-engine
ternary that left the other five pinned to Part's compiled-in `0.5`; this
pulls the ternary so DPTH reaches all six. The knob's init default stays
`0.5`, which is that same compiled-in base and `feed_cfg::kDepthBase`, so an
untouched patch sounds the same as before on five engines. The Sampler is the
exception: it reads the base through `sampler_cfg::kMotionBaseScale = 0.5`, so
the knob's default lands at base `0.25` there, not the degenerate `0.5` that
used to flatten the spawn-position jitter.

EDGE was a fourth VOICE knob, a bipolar trim on each engine's own "second
filter" (spec 2026-08-19 voice-knobs-dpth-edge, §4), shipped alongside DEPTH
2026-08-19 and withdrawn 2026-08-20 after a listening pass found it did not
earn its panel space (plan `2026-08-20-edge-knob-removal`; the
measurements are in the repo root's `docs/by-ear-decisions.md`). The knob
slot is free space by decision, not re-flowed.

GRIT itself is bipolar (spec 2026-08-09 hw-control-reduction task 4): there is
no separate mode pad any more. The knob's sign picks the mode -- left of
centre is Reduce (bit-crush), right of centre is Drive (saturation) -- and its
magnitude is the mix. A small dead zone around centre gives "off" a reachable
resting spot on a real pot.

`REC` is drawn only on a Sampler deck; it has never done anything on the other
four.

## Sampler

ENG is patch-compatible in the exact order **Synth = 0**, **Sampler = 1**,
**Wave = 2**, **Body = 3**. States 2 and 3 select the portable wavetable and
resonator engines and are never treated as Sampler. Patches saved before Body
existed store only 0..2, so their meaning is unchanged. The context-menu
test-tone development override remains limited to state 1; it cannot replace
Wave or Body. The latch has no halo for Synth, a warm halo for Sampler, an
ice-blue halo for Wave, and a green one for Body.

**ENG** (per part, latched) selects **Synth**, **Sampler**, **Wave**, or
**Body**. **Body** is a resonator that morphs from plucked string through
prepared piano to struck bell; its excitation sources — the deck's own FLUX
echo, the other deck, and the audio input — are checkboxes in the same
context menu.

**The "other deck" checkbox (menu item `Route: other deck (BODY excite,
SAMPLER feed+rec, BBD feed)`) is not Body-only.** It also drives the
audio-rate cross-deck bus (spec 2026-07-31 bbd-part-engine): the engines
that consume that bus today are **Sampler** and **BBD**, so turning this on
for either deck audibly routes (and, for Sampler, records) the neighbouring
deck's output — where on earlier releases the same checkbox did nothing for
either. A patch saved with it on for a Sampler or BBD part will sound
different after updating to a build with the cross-deck bus. It also has a
second, easy-to-miss effect regardless of whether the neighbour is making
sound: the external **audio input** is summed with the neighbour's tap and
the sum is soft-clipped (`fast_tanh`) before reaching the engine, so
enabling this checkbox puts the deck's own audio-in monitoring/recording
through that same soft clip — audibly softer than the normal dry-at-unity
monitor, even with a silent neighbour. Neither behaviour is a bug; it is
what routing two decks' audio through one shared flag necessarily does. A
**BBD** deck defaults this checkbox ON the moment ENG lands on BBD (see
below) precisely so it always has something to echo.

**Sampler** is a granular texture deck over the shared record buffer. Flipping ENG to
Sampler on an empty part autoloads the embedded first four bars of the
project author's own 110 BPM bass loop (`res/factory.wav`) so the deck makes
sound on the very first gesture; it never overwrites content already in the
buffer, and a deliberate *Clear sample* stays cleared even if you flip ENG
back and forth. On a Synth, Wave or Body part, ENG is the only mode control — REC is inert
there.

**REC** (per part, latched) records from **IN L/R** into that part's buffer
while the sampler is free to keep playing what it already has (fill-follows:
the granular cloud reads whatever's been written so far, so the deck never
goes silent while filling). Starting a recording clears any remembered
sample path/factory flag — once REC has touched the buffer, its content no
longer matches a file on disk or the factory sample, so *Save sample…* is
the only way to keep it. The REC LED has three states: **pulsing** (2 Hz)
while recording, a **steady brightness proportional to fill level** once the
part holds content and isn't recording, and **dark** when the part is empty
or on a non-Sampler engine — the light tracks ENG, not leftover buffer state, so switching
a part away from Sampler doesn't relight it.

**Four controls take on a different job the moment ENG says Sampler.**
The parameter IDs don't change — for the hardware this is a merge of existing
controls, not a new set of them — only what turning the knob does:

| Control | Sampler caption | Sampler meaning | Range |
|---|---|---|---|
| MELODY | `SCAN` | tape-head advance; the deck's VARY job is parked at LOOP here | centre is a true dead zone; linear out to real time at three-quarters of travel, then linear up to 4×; sign is direction |
| DENSITY | `DENS` | groove density *and* grain overlap — one word because both mean sparser | 1…8, continuous; the MOTION lane modulates around it |
| SUB | `LEN` | grain length | 1 ms…42 s |
| SOURCE | `ORG` | read position in the material | full material length |

MELODY drove variation and scan at once until 2026-08-03. It now drives scan
alone on a Sampler deck, so the deck's phrases stop renewing by themselves —
a `SONG` rung change is the gesture that asks for a fresh pair.

SCAN's dead zone is exact and deliberate: a frozen tape head has to stay
frozen even through knob noise, so nothing moves for the first couple of
percent off centre. From there it ramps in gently and linearly, and real
time lands on a fixed, refindable knob position three-quarters of the way
out rather than somewhere you have to hunt for — the last quarter is the
steepest stretch of the curve, carrying the head up to four times real time
in either direction.

**SCAN springt beim ENG-Flip sofort auf die Knopfposition — offene Frage
(F-07, Review 2026-07-22).** VARY trägt im Synth VARIATION und im Sampler
SCAN, und die Init-Werte stehen für VARIATION an den Extremen (−0.728 und
−1.0). Als SCAN gelesen sind das −0.97× und −4× Realtime rückwärts: der
erste Flip auf Sampler lädt die Factory-Drone und schickt den Lesekopf im
selben Control-Tick rückwärts los, praktisch schon bei Realtime, ohne dass
jemand etwas angefasst hat. (Seit 2026-08-03 parkt die VARIATION-Hälfte
selbst bei LOOP, sobald ENG auf Sampler steht — SCAN liest aber weiterhin
direkt dieselbe rohe Knopfposition, unabhängig von diesem Park, also bleibt
das hier beschriebene Verhalten unverändert.)

Das ist als Fehler gemeldet worden, ist aber genau das Verhalten, das
"Known limitations" weiter unten bewusst wählt: Knopfposition gilt über den
Engine-Wechsel hinweg, ohne getrenntes Gedächtnis und ohne Soft-Takeover,
weil die Hardware kein Soft-Takeover hat. Ein Soft-Takeover wurde gebaut und
wieder zurückgenommen — über Patch-Laden hinweg dicht zu bekommen verlangt
persistenten Zustand, also genau das, was diese Zeile ausschließt. Die
Entscheidung liegt beim Autor des Instruments, nicht in der Engine.
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

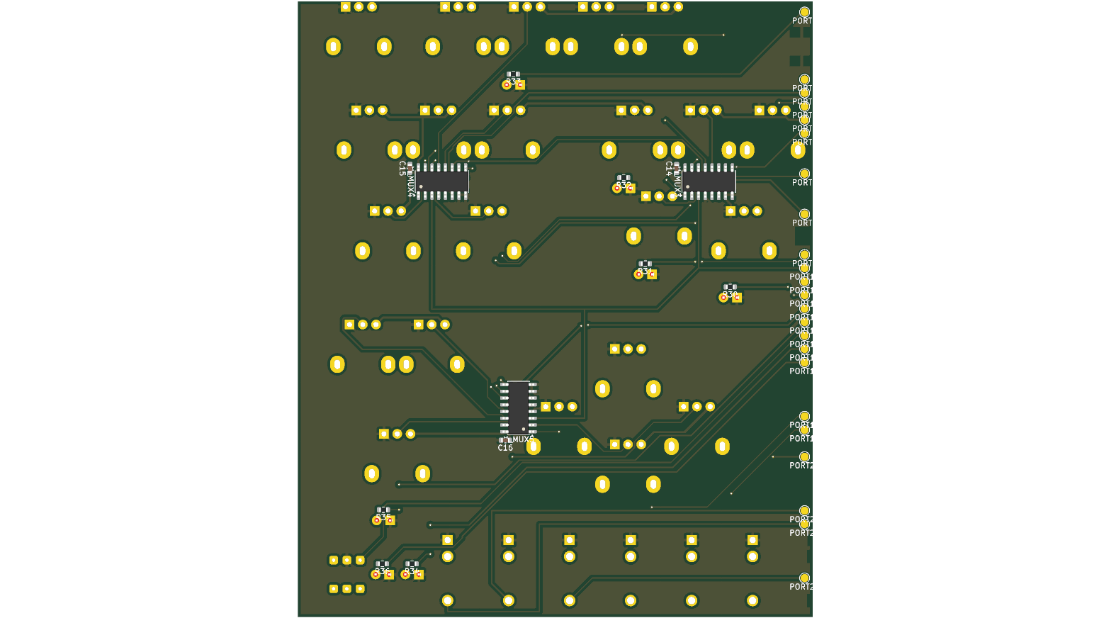
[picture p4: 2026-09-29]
docs/hardware/routing-spike/freerouting-2L-bottom.png

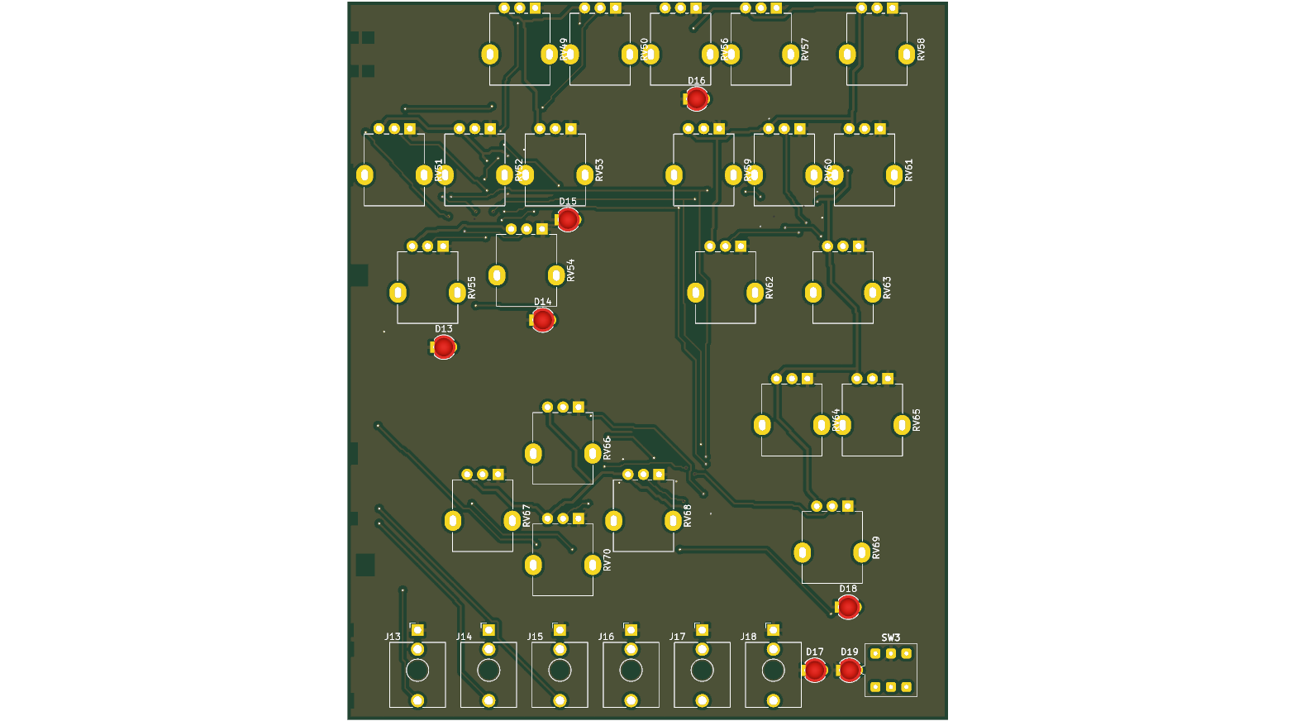
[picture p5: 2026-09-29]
docs/hardware/routing-spike/own-2L-top.png

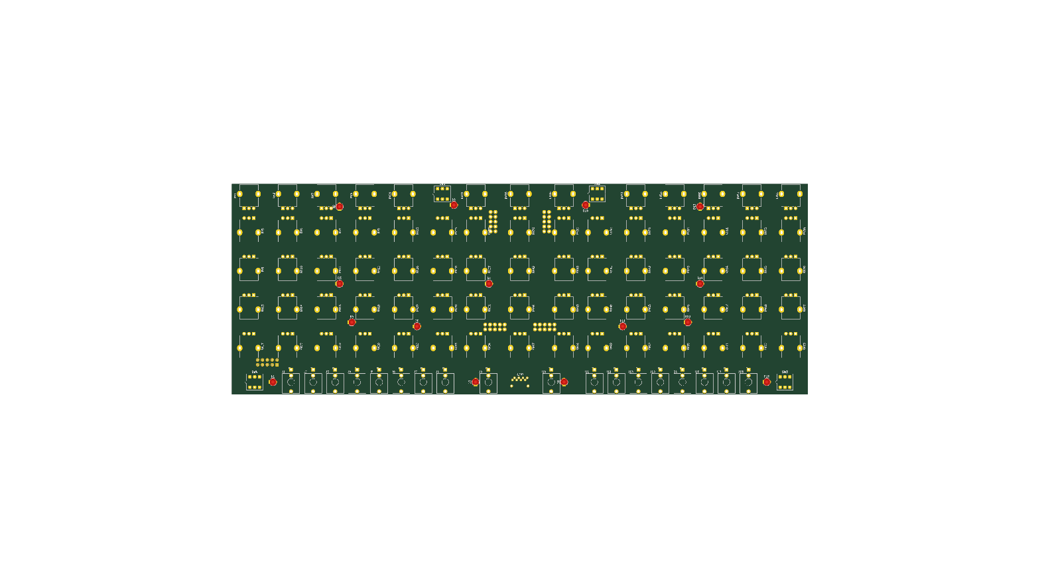
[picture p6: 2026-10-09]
docs/hardware/placement/reva-placed-top.png

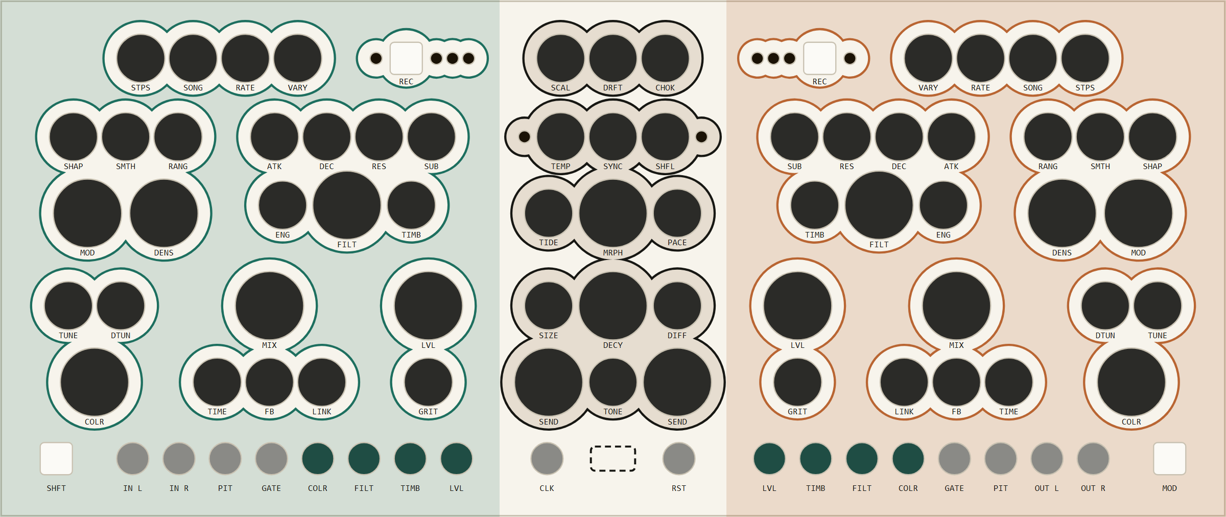
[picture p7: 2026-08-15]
docs/hardware/2026-08-10-hw-panel-redistribution.png

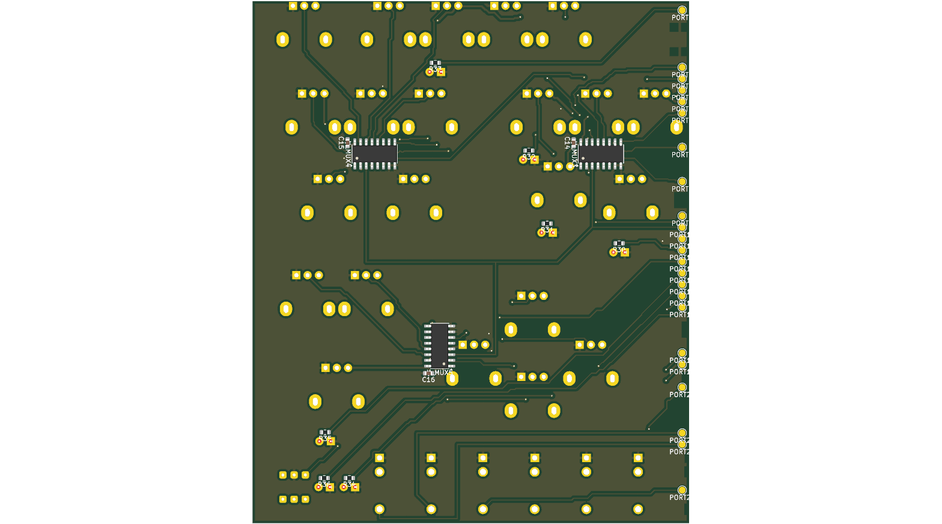
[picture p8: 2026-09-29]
docs/hardware/routing-spike/own-2L-bottom.png

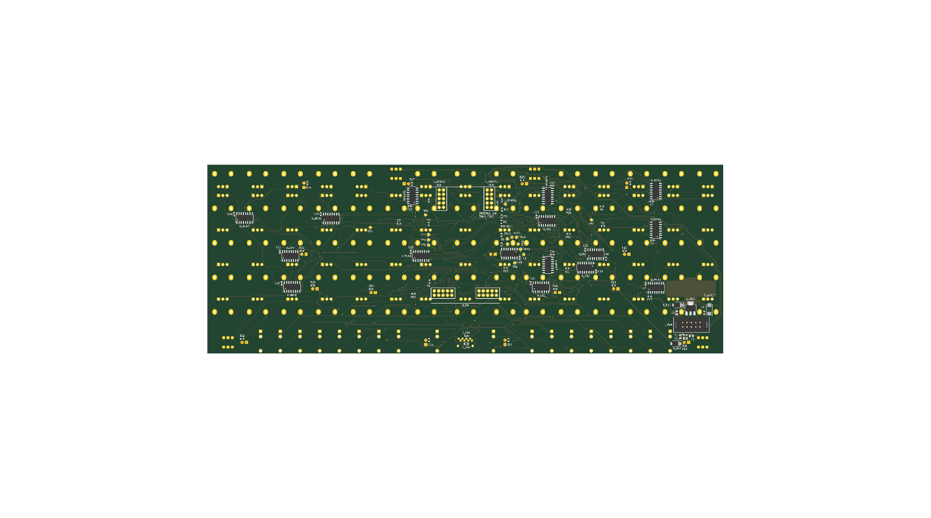
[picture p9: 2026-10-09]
docs/hardware/routing/reva-routed-bottom.png

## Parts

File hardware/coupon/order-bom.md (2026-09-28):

# Coupon parts order

**Both orders are placed. Boards: JLCPCB, 2026-09-02, $22.02. Parts: Reichelt,
2026-09-03, 14.19 € + 5.95 € shipping.** This file stays as the record of what
was bought and why, and as the list to repeat from if a second board gets
populated. The pots, which stopped being a stock item on 2026-09-16, were
bought separately from Amazon and are soldered in since 2026-09-17 — see "The
pots" below. **Nothing is left to order for the first board.**

What to buy to populate one coupon. The board itself was ordered from JLCPCB
on 2026-09-02 (5 pieces, bare boards, no assembly), so everything here is
hand-soldered. Derived from `proof/review.md` Section 4, which stays the
authority on what the design contains — this file only adds where to get it
and how much of it.

Prices and stock checked 2026-09-03 at reichelt.de, incl. 19 % VAT. They will
drift; the article numbers are the durable part.

## One supplier: Reichelt

Everything that has to be bought fits in a single domestic order — no customs,
no second shipping fee. **14.19 € + 5.95 € shipping**, in stock, 1–2 working
days. (That total is the cart's own figure, checked 2026-09-03 with all
thirteen lines in it; the per-line sums below add to 14.21 € because the
tiered resistor prices round differently line by line.)

| qty | part | Reichelt no. | needed | each | sum |
|---:|---|---|---:|---:|---:|
| 50 | Resistor 0805, 0 Ω, 1 % | `SMD-0805 0,00` | 16 | 0.015 € | 0.75 € |
| 25 | Resistor 0805, 1.0 kΩ, 1 % | `SMD-0805 1,00K` | 10 | 0.015 € | 0.38 € |
| 25 | Resistor 0805, 10 kΩ, 1 % | `SMD-0805 10,0K` | 5 | 0.015 € | 0.38 € |
| 25 | MLCC 0805, 100 nF, 50 V, X7R | `CL21B104KBCNNNC` | 5 | 0.05 € | 1.25 € |
| 10 | MLCC 0805, 10 µF, **25 V**, X5R | `CL21A106KAYNNNE` | 4 | 0.13 € | 1.30 € |
| 20 | LED 0805 green, 500 mcd | `0805G3C-KHC-B` | 8 | 0.13 € | 2.60 € |
| 4 | 74HC595, SO-16 | `74HC 595D NXP` | 2 | 0.24 € | 0.96 € |
| 2 | 74HC165, SO-16 | `74HC 165D NXP` | 1 | 0.25 € | 0.50 € |
| 2 | 74HC4051, SO-16 | `74HC 4051D NXP` | 1 | 0.35 € | 0.70 € |
| 2 | 74HC4067, SO-24 | `SMD HC 4067` | 1 | 0.83 € | 1.66 € |
| 4 | Female header 2×10, 2.54 mm, straight — **cut to 2×5, see below** | `MPE 094-2-020` | 4 | 0.67 € | 2.68 € |
| 2 | Box header 10-pin, straight | `WSL 10G` | 1 | 0.15 € | 0.30 € |
| 5 | Tactile switch 6×6 mm, h 8 mm | `TASTER 9305` | 1 | 0.15 € | 0.75 € |

Order quantities are above the per-board need on purpose: 0805 parts get lost,
and the fab ships five boards while `README.md`'s rule is to populate a second
copy rather than rework the first.

### Two things to check rather than trust

- **The module sits on four 2×5 sockets, not two 2×10.** The landing
  pattern (`hardware/lib/DaisyKiCad/Daisy-Boards.pretty/DAISY_PATCH_SM.kicad_mod`,
  pad coordinates read 2026-09-15) is four separate 2×5 groups: banks A and
  D lie horizontally on the module's left edge with 25.5 mm between the two
  groups, banks B and C vertically on its right edge with 15.8 mm between
  them. No straight 2×10 strip fits either side. The four 2×10 strips above
  are still the right purchase: cut each one down to a 2×5 — the position
  under the cut is lost, so a 2×10 yields one intact 2×5 plus a 2×4 offcut —
  and the four cuts give exactly the four sockets the pattern needs. Buying
  four 2×5 female headers outright is the cleaner alternative. The asymmetry
  is also what makes a rotated module impossible to seat: horizontal groups
  on one edge, vertical on the other.

- **The LED must be a bright type, not a cheap one.** `R_LED*` is 1 kΩ off the
  3V3 rail, so the LEDs run at roughly **1.2 mA**, not 20 mA. A 12 mcd@20 mA
  part lands near 0.7 mcd and is barely visible; the 500 mcd part above gives
  about 30 mcd at the same current. Any high-efficiency green 0805 will do —
  the brightness figure is what matters, not the article number.
- **`SMD HC 4067` is the right part — checked 2026-09-03, no longer an open
  question.** The board's footprint is `SOIC-24W` and the narrow SO-24 variant
  would not fit, and Reichelt's search listing states only "SO-24" without a
  width. The article page settles it: manufacturer part number
  **`CD74HC4067M`** (Texas Instruments), which is exactly what `netlist.py`
  names, and the `M` suffix is the wide body.

## Not bought, and why

- **The seven pots (RV1–RV7)** — 4 × 10 k and 3 × 20 k linear. Were "from
  stock" until 2026-09-16, when the stock parts turned out to be bodies too
  large to reach the board without flying leads. Bought from Amazon instead
  and fitted on 2026-09-17: see "The pots" below.
- **`J_AUDIO`, the 3.5 mm jack** — left unpopulated for now. It serves **none
  of the eight measurement points** in `proof/review.md` Section 1, the
  measurement rig is mono anyway (see `netlist.py`'s comment on the part), and
  the left channel already reaches a probe pad at `TP_AUDIO_L`. Reichelt does
  not carry the CUI SJ1 series and has no part with this pad pattern; a
  Thonkiconn does not substitute (measured: its three pins sit in a straight
  line at y 0 / 3.1 / 11.4 mm with 1.2–1.4 mm drills, against this footprint's
  scattered 2.0 mm holes at (0,0), (3.5,4.5) and (8.3,−5.0) — and it is mono,
  with no ring contact). If the jack is wanted later, buy the actual
  **SJ1-3513N** from Digikey or Mouser on the back of an order that already
  clears their free-shipping threshold.
- **`C_COM16` / `C_COM8`** — deliberately unpopulated, per requirement 2, and
  staying that way: the capacitor test they existed for was struck on
  2026-09-28, so no capacitor for them is ever bought.
- **The ten test points and both solder jumpers** — bare pads; the jumpers are
  bridged with solder.

## The pots: RV09 vertical, and what to check

The stock parts turned out to be oversized bodies that reach the board only on
flying leads, and that is the one thing this coupon may not be built with:
`docs/hardware/settle-budget.md` §6 puts the confirmation on a fabricated board
precisely because a wired node is an undefined multiple of the assumed 65 pF.
Run through `tools/settle_budget.py` with the wire modelled as extra node
capacitance at `COM` (1.5 pF/cm, the pessimistic placement), 5 cm still lands
inside the same 16.5-cycle sampling window and the same 0.16 block — but at
20 cm the 74HC4067 falls into the next window, and the crosstalk and noise
points stop meaning anything long before that. So the pots go on the board.

**What was bought: an RV09 9 mm vertical, 2.5 mm pitch, in 10 k and 20 k** —
Amazon `B01HO8EFXI` (10 k) and `B01HO8ELFA` (20 k), 6.99 € per 10 pieces each,
checked 2026-09-16, which covers all seven positions with spares. **Fitted on
the first board on 2026-09-17**, RV3/RV4/RV7 at 20 k and the rest at 10 k. The
pin row went in; the support lugs were slightly too large for the slots and
were clipped off, and the pots hang on their three solder joints with no glue.
The checks below were written before the parts arrived and stay as the list
for the next board.

**Reichelt cannot supply the pair.** Its only 9 mm vertical part is the ALPS
`RK09K113-LIN10K` (manufacturer `RK09K1130A0H`, 1.10 €), and that line carries
10 k, 50 k and 100 k — **no 20 k**, so requirement 4 of `proof/review.md`
Section 1 ("10 k and 20 k side by side on one mux") cannot be met from there.
The package is electrically irrelevant either way; the resistance is the device
under test.

Board figures below read from the committed board and the footprint,
2026-09-03 and 2026-09-16.

- **Pin row:** three 1.0 mm holes at **2.5 mm pitch**, spanning 5.0 mm. The
  RV09 pitch matches, but check the legs are round enough for a 1.0 mm hole
  rather than flattened.
- **Support lugs — expect them not to fit.** The board draws the Alpha
  RD901F-40-00D pattern: two oval slots 1.1 × 1.8 mm, **7.5 mm to the side** of
  the pin row and **9.6 mm between centres**. Other 9 mm families use their own
  spacing; the ALPS `RK09K1130A0H` drawing, for one, gives 1.6 × 2.1 mm holes
  at 7.0 mm from the pin row and 10.6 mm across the pair — a miss on every
  count, whether that 10.6 is read outer-to-outer or centre-to-centre. Measure
  the lugs before pressing anything down. If they miss, clip them off; the pot
  then hangs on three solder joints, so add a dab of hot glue under the body
  before anything gets turned. **On the first board the Amazon RV09's lugs
  missed (slightly too large) and were clipped; no glue was added.**
- **A standing body claims far less board area** — roughly the 9.8 mm square
  between the pin row and the lug slots, instead of a 20 mm body reaching out
  over its neighbours. **Checked on the first board, 2026-09-28:** RV4's body
  clears both `JP_GND` and `R_SP11` with a visible gap, and its case reads
  open against GND on a continuity meter (board unpowered). No Kapton is
  fitted, and none is needed there.
- **If a right-angle part gets used after all**, the old clearance measurements
  still apply: the pots sit in two rows, RV1–RV4 at y 50.5 mm and RV5–RV7 at
  y 65.0 mm, pin rows running east–west, leaving **14.5 mm between the rows**
  and **15.0 mm from the lower row to the board's south edge** — point the
  lower row's shafts south, over the edge, and the upper row's north. **RV4 is
  the tight one:** `JP_GND` sits 1.5 mm north of it and `R_SP11` 1.3 mm south,
  so its body rests on neighbours whichever way it faces. A pot case is metal
  and would lie flat across the analog section's parts and traces, so Kapton
  under every body.
- **If short of pots:** the channel plan measures only **RV2 (10 k), RV4
  (20 k) and RV6 (10 k)**; the rest are companion channels. Populate those
  three first.
- **If the pots are log rather than linear:** still usable. Peak source
  impedance is R/4 regardless of taper — it just no longer occurs at mid
  travel but where the track splits 50/50, far to one side on a log part. Find
  that position with a meter instead of trusting the knob.

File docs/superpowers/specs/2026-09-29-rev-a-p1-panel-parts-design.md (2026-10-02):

# Rev A P1 — panel parts, cut file and grip test

**Date:** 2026-09-29
**Status:** approved in conversation (Bastian), to be reviewed as written
**Parent:** [`2026-09-28-rev-a-master-plan-design.md`](2026-09-28-rev-a-master-plan-design.md), sub-project P1
**Deadlines:** parts and acrylic ordered **Fri 9 Oct 2026**; panel freeze (H1)
**Fri 6 Nov 2026**

P1 is the mechanical track of Rev A: choose every panel-mounted part, export
a cut file from the panel generator, build a mechanical-only acrylic plate
with the real parts in it, test it by hand, and freeze the panel.

## 1. Parts — decided

Counted from the generator on 2026-09-28 (`gen_hw_panel.py`, positions with
`hw_class`): **14 big and 56 small knob positions = 70 pots** (`ATTACK_A/B`
and `STAGES_A/B` share a knob each), **4 keys** (`REC_A`, `REC_B`, `MODBTN`,
`SHIFTBTN`), **18 jacks**, **19 LEDs**, one SD slot.

| Part | Type | Qty (+spare) | Source |
|---|---|---|---|
| Pots | **Genuine Alpha 9 mm vertical, RD901F-40 family, T18 knurled shaft, B10K linear** — one type for all 70 positions; big and small differ by cap only | 70 (+7) | Thonk |
| Big caps | Davies 1900H clone, T18 (12 mm Ø × 16 mm) | 14 (+2) | Thonk |
| Small caps | Thonk Micro Knobs, T18 (7.7 mm Ø × 13.85 mm) | 56 (+6) | Thonk |
| Jacks | Thonkiconn PJ398SM mono | 18 (+2) | Thonk |
| Jack nuts | Knurled nuts, bag of 50 — the jacks ship without nuts (the pots bring their own nut and washer) | 1 bag | Thonk |
| Keys | Thonk low-profile push buttons, round cap (caps sold separately, packs of 5) | 4 (+2) | Thonk |
| LEDs | 3 mm flat-top THT | 19 (+6) | Thonk |

**Cap colours (Bastian, 2026-10-02)** follow the plate's part colours: part A
green, the centre dark blue, part B orange. Counted from the generator by
region (`_A` / `_B` suffix, everything else centre; every suffix agrees with
its side of the 152.40 centre line):

| Region | Colour | Big (1900H) | Small (Micro) | Keys |
|---|---|---|---|---|
| Part A | Green | 6 (+1) | 22 (+2) | 1 (`REC_A`) |
| Centre (GLOBAL, TIMING, ROOM) | Dark Blue | 2 | 12 (+2) | 2 (`SHIFTBTN`, `MODBTN`) |
| Part B | Orange | 6 (+1) | 22 (+2) | 1 (`REC_B`) |

`REV_MIX_A/B` (SEND) sit in their part's LEVEL frame and count with that part.
The key caps come as Thonk's taster pack (3 each red, yellow, green, blue):
no orange key cap exists, so `REC_B` takes red or yellow, chosen on the board.

Rationale and rejected options, briefly:

- **Genuine Alpha, not a clone.** The coupon's Amazon RV09 clone missed the
  footprint's support-lug slots. The coupon footprint is KiCad's own
  `Potentiometer_Alpha_RD901F-40-00D_Single_Vertical`, i.e. drawn for the
  genuine part; the fit is *expected*, not yet confirmed (§6).
- **One pot type.** One footprint, one hole size, one order line, and the
  coupon's measured pot facts apply everywhere.
- **Rejected: ALPS RK09K with a capless 6 mm knurled plastic shaft** for the
  small knobs (Reichelt, 1.10 €). It would have saved about 90 € per set, but
  it has no threaded bushing — the pot hangs on its solder joints — and a
  different footprint. Bastian's decision: Alphas throughout.
- **Rejected: 8 mm square keycaps** (E-Switch TL1105 + cap). Not stocked by
  Thonk, and the switch needs a riser to reach the panel. The drawing changes
  from an 8 mm square to a round cap (§3).
- **No standoffs.** The 70 pots and 18 jacks, all nutted to the panel across
  the full 305 mm, hold the board — the usual Eurorack construction (Mutable,
  Befaco). The plate therefore gets no M3 holes. The envelope spec's
  2026-09-28 note calling for mid-board standoffs is corrected the same day
  as this spec.
- **LEDs without spacers.** They are soldered with the panel screwed on and
  pushed into their holes, so they sit flush by construction.
- **Centre detents: none for now.** The bipolar knobs (at least `CHOKE` and
  `PULL`; the full list is taken from the engine ranges in
  `engine/param_table.h` during planning) get the plain pot and a firmware
  dead zone at centre. Thonk's centre-detent B10K was out of stock on
  2026-09-28; if it is back by the Rev A order, those positions take it.
- **ENGINE** stays a plain pot that the firmware splits into five zones. No
  9 mm Alpha with five detents exists; the matching Alpha rotary switch
  (`SR1712F`) is hard to get.

**Order: one set now, the second in December.** One set is about £170 of
parts at Thonk's listed prices (pots ~£96 at the 50+ break, caps ~£53, the
rest ~£20), roughly **240 € delivered** once shipping, 19 % import VAT and the
carrier's fee are added — an estimate; the cart is read back before ordering.
The second set, for the second Rev A board, is ordered in the Rev A review
week (11–18 Dec) after the grip test has had its say. Thonk (UK) charges no
VAT at checkout for EU orders, and its FAQ warns that import charges fall due
on delivery.

## 2. The acrylic plate — decided

- **Clear acrylic GS, 3 mm**, laser-cut at formulor.de, with a **1:1 paper
  print of the real plate artwork** underneath (A3, holes cut out). The clear
  plate carries the parts; the print shows the legends, so the grip test also
  tests readability, with no engraving cost.
- **Price:** 20.49 € for 3 mm opaque black and 23.15 € for 3 mm fluorescent
  (Formulor quote 2026-09-28, neutral test file of the same size and hole
  count, shipping extra). Clear is not quoted yet; expected in that range.
- **Thickness:** 3 mm acrylic against the 2 mm aluminium of Rev A. The pot
  and jack threads are expected to take the extra millimetre (to check on the
  parts, §6).
- **One correction cut** (~20 €, a few days) is budgeted.
- **Order timing:** the acrylic is ordered on 9 Oct together with the parts,
  with hole sizes from the datasheets, not after the parts arrive. If a hole
  is wrong, the budgeted correction cut pays for it; waiting would cost two
  weeks of the grip test.

## 3. Generator changes

Hole sizes and the satellite rule live in `host/vcv/res/gen_hw_panel.py`; the
three outputs come from a separate generator, `host/vcv/res/gen_hw_cut.py`,
which places nothing. Nothing is drawn by hand.

1. ~~**Body radii follow the real caps.**~~ **Deferred 2026-09-29 (Bastian)**
   to the correction round after the grip test, before the freeze.
   `BODY_R["S"]` feeds the LEVEL band's x positions and the derivation of
   `Y_B2K`, so shrinking it to the Micro Knob's 3.85 moves controls; and the
   header's `kFfPadR` is also used by the big module's ENGINE latch. The cut
   file needs only hole sizes, which are independent, so the drawing gets one
   round, after the test, instead of two.
2. **Cut export.** A new output, `res/FireflowHW-cut.svg`, in Formulor's
   convention: pure blue (RGB 0,0,255) hairlines are cut, units are mm, one
   closed path per hole. Contents:

   | Feature | Size |
   |---|---|
   | Plate outline | 128.5 mm high; width **304.4 mm** — 304.8 nominal minus 0.4, trimmed 0.2 off each side (assumption from Doepfer's A-100 table, where 20 HP is 101.30 of 101.60 mm; to check against a bought 60 HP blank) |
   | Pot hole | 7.0 mm (Alpha M7 bushing; to confirm on the part) |
   | Jack hole | 6.0 mm |
   | Key hole | 6.2 mm (Thonk low-profile button, recommended cutout) |
   | LED hole | 3.1 mm |
   | SD slot | 11 × 6 mm, as the generator already places it |
   | Mounting | four 5.2 × 3.2 mm stadium slots, 7.5 mm in from the left edge and 57 HP apart, 3.0 mm from top and bottom (DIY convention; assumption) |

3. **Print export.** `res/FireflowHW-print.pdf` (or SVG): the plate artwork at
   exactly 1:1, with each hole's outline drawn so it can be cut out, and a
   100 mm scale bar to check the printer did not scale.
4. **Hole list.** `res/FireflowHW-holes.json`: one entry per hole —
   `{id, kind, x_mm, y_mm, d_mm}` (or `w_mm`/`h_mm` for the slot), origin at
   the plate's top-left, y down. This is the single source P4 places the
   board's parts from; the cut file and the print are drawn from the same
   list, never from separate coordinates.

## 4. The guard

A new guard next to `res/test_hw_panel.py`, wired into ctest the same way
(`CMakeLists.txt`, the block that already runs the two panel guards). It
asserts:

- every pot, jack, key and LED of the generated panel has **exactly one**
  hole in `FireflowHW-holes.json`, at its own coordinate (0.01 mm), and the
  cut file contains exactly those holes;
- no two holes overlap, and **at least 2.0 mm of material** stays between
  any two hole edges (acrylic cracks at thin webs);
- no hole enters the rail zones; holes keep 2.0 mm to the plate edges, the
  rail slots the Eurorack-standard 1.4 mm;
- the print export's scale bar measures 100 mm in the file.

Each assertion is shown red once (a shifted hole, a thin web) before it is
trusted.

**Found by the guard before anything was cut (2026-09-29):** the four jack-row
satellite LEDs (`MODBTN_L`, `SHIFTBTN_L`, `SYNC_L`, `CEIL_L`) sat at their
anchor's class radius + 1.5 mm, leaving 0.85–0.95 mm of material to the real
key and jack holes. They now sit at `SAT_D` = 6.7 mm (key hole 3.1 + web
2.0 + LED hole 1.55, rounded up). Whether the jack nuts cover `SYNC_L` and
`CEIL_L` is a §6 measurement; the keys have no nut, so `MODBTN_L` and
`SHIFTBTN_L` stay uncovered.

## 5. Grip test and freeze

**Checklist**, results written to `docs/hardware/grip-test.md`:

1. Pinch two neighbouring knobs at once, in every group.
2. Turn each knob without brushing its neighbours' caps.
3. Patch all 18 jacks with real cables; note every knob, key, LED and legend
   a cable or plug covers.
4. Read every legend from playing distance, through the print.
5. Press all four keys; note reach and accidental presses. **Moved to the
   first Rev A board (2026-10-02):** the keys sit on the board, not in the
   acrylic (§6), so the plate cannot hold them.
6. Note anything that fails as *position*, *size* or *legend*; each gets a
   fix in the generator, not in a file.

**Freeze, Fri 6 Nov (H1):** the generator commit that passes the grip test is
tagged `panel-freeze-2026-11-06`. After that tag the panel geometry changes
only with Bastian's explicit approval.

## 6. What gets measured, not assumed

When the parts arrive, before the grip test (a caliper and the coupon, which
carries the RD901F footprint):

- the genuine Alpha's support lugs in the coupon's slots — confirms the P4
  footprint;
- pot bushing thread and length against 3 mm acrylic and 2 mm aluminium;
- jack thread against 3 mm. The keys have no thread and no nut (Thonk
  datasheet, checked 2026-10-02): an 8.5 × 8.5 mm body sits on the board and
  only the 6 mm cap passes the 6.2 mm hole, so the acrylic plate does not
  hold them and they are not tested on it;
- **the panel-to-board height** set by a pot and a jack seated on a board —
  the number the depth budget (15 mm module + 1.6 mm board + this gap, about
  10 mm expected) is still missing;
- whether the Alpha has an anti-rotation tab, and where.

Each result goes into `docs/hardware/grip-test.md` with the date.

## Out of scope

Rev A footprints and placement (P4), the aluminium plate's finish and maker
(P5), anything electrical (P2/P3).

## Sources

Thonk: [Alpha 9 mm T18](https://www.thonk.co.uk/shop/alpha-9mm-pots-vertical-t18/),
[1900H T18](https://www.thonk.co.uk/shop/1900h-t18/),
[Micro Knobs](https://www.thonk.co.uk/shop/micro-knobs/),
[Thonkiconn](https://www.thonk.co.uk/shop/thonkiconn/),
[low-profile buttons](https://www.thonk.co.uk/shop/low-profile-push-buttons/),
[3 mm LEDs](https://www.thonk.co.uk/shop/new-style-flat-top-leds/),
[EU customs FAQ](https://www.thonk.co.uk/ufaqs/as-an-eu-customer-will-i-have-to-pay-customs-charges-and-vat-when-i-receive-my-thonk-parcel/).
Rejected alternative: [Reichelt RK09K113-LIN10K](https://www.reichelt.com/de/en/alps-rotary-potentiometer-linear-6-mm-mono-10-k-vertical-rk09k113-lin10k-p73815.html).
Laser: [formulor.de](https://www.formulor.de/so-funktionierts).

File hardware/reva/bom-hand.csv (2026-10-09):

Source | Qty | Part | Footprint | Designators
Electrosmith | 1 | Patch Submodule, socketed | DAISY_PATCH_SM | U_SM
Thonk | 15 | 3 mm flat-top LED | LED_D3.0mm | D1,D2,D3,D4,D5,D6,D7,D8,D9,D10,D11,D12,D13,D14,D15
Thonk | 73 | Alpha RD901F-40 9 mm, T18 shaft, B10K | Potentiometer_Alpha_RD901F-40-00D_Single_Vertical | RV1,RV2,RV3,RV4,RV5,RV6,RV7,RV8,RV9,RV10,RV11,RV12,RV13,RV14,RV15,RV16,RV17,RV18,RV19,RV20,RV21,RV22,RV23,RV24,RV25,RV26,RV27,RV28,RV29,RV30,RV31,RV32,RV33,RV34,RV35,RV36,RV37,RV38,RV39,RV40,RV41,RV42,RV43,RV44,RV45,RV46,RV47,RV48,RV49,RV50,RV51,RV52,RV53,RV54,RV55,RV56,RV57,RV58,RV59,RV60,RV61,RV62,RV63,RV64,RV65,RV66,RV67,RV68,RV69,RV70,RV71,RV72,RV73
Thonk | 4 | Thonk low-profile button, momentary; pin 1 closes to 2 | SW_Push_LP_Button | SW1,SW2,SW3,SW4
Thonk | 18 | Thonkiconn PJ398SM mono | Jack_3.5mm_QingPu_WQP-PJ398SM_Vertical_CircularHoles | J1,J2,J3,J4,J5,J6,J7,J8,J9,J10,J11,J12,J13,J14,J15,J16,J17,J18
hand-soldered | 4 | 2x5 female socket for the Patch SM, cut from a 2x10 strip; its holes belong to U_SM's footprint | (no footprint) | J_SM1,J_SM2,J_SM3,J_SM4
hand-soldered | 1 | Yamaichi PJS008U-3000-0 vertical microSD, THT (P4-1 spec §4.2) | SD_Yamaichi_PJS008U-3000-0 | J_SD
hand-soldered | 1 | shrouded keyed 2x5 box header; pin 1 = -12 V | IDC-Header_2x05_P2.54mm_Vertical | J_PWR

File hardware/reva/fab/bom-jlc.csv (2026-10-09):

Comment | Designator | Footprint | LCSC
10u 25V | C1,C3,C5 | C_0805_2012Metric | C15850
100n | C2,C4,C7,C8,C9,C10,C11,C12,C13,C14,C15,C16,C17,C18,C19,C20,C21,C22,C_SD1 | C_0603_1608Metric | C14663
22u 25V | C6 | C_0805_2012Metric | C45783
SS14 | D_N12,D_P12 | D_SMA | C2480
1k | R1,R2,R3,R4,R5,R6,R7,R8,R9,R10,R11,R12,R13,R18,R19,R20,R21,R22,R23,R24,R25,R26,R27,R28,R29,R30,R31,R32 | R_0603_1608Metric | C21190
10k | R14,R15,R16,R17 | R_0603_1608Metric | C25804
74HC165 | U_IN1 | SOIC-16_3.9x9.9mm_P1.27mm | C5613
74HC4051 | U_MUX0,U_MUX1,U_MUX2,U_MUX3,U_MUX4,U_MUX5,U_MUX6,U_MUX7,U_MUX8,U_MUX9 | SOIC-16_3.9x9.9mm_P1.27mm | C9386
AMS1117-3.3 | U_REG | SOT-223-3_TabPin2 | C6186
74HC595 | U_SR1,U_SR2,U_SR3,U_SR4,U_SR5 | SOIC-16_3.9x9.9mm_P1.27mm | C5947

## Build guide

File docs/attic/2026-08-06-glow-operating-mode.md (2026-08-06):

# Glow Operating Mode (P_MODE) Implementation Plan

> **For agentic workers:** REQUIRED SUB-SKILL: Use superpowers:subagent-driven-development (recommended) or superpowers:executing-plans to implement this plan task-by-task. Steps use checkbox (`- [ ]`) syntax for tracking.

**Goal:** Give the Glow flow layer a drawn operating mode — FLOW/free or STEP/synced — so terrains stop being step sequencers with no grid, and re-measure every gate that mode change moves.

**Architecture:** One new global parameter `P_MODE` (2 steps) appended at the tail of `SPKY_FLOW_PARAMS`, drawn per terrain from archetype weights. Because `Instrument::set_sync` is global and `set_step` takes mode *and* count together, the three parameters `P_MODE`/`P_STEPS_A`/`P_STEPS_B` move out of the stateless `apply_param` into a helper owned by `Flow`, which holds all three values in `_pushed[]`. During a blend `P_MODE` switches at phase 0 and ducks both decks together, deliberately collapsing the per-deck stagger for that one press.

> **CORRECTION 2026-08-06, post-implementation — the last sentence above is WRONG; do not re-execute it.** Collapsing the stagger was built, escalated as **Critical** in review, and replaced. It leaves the carrier deck's `P_ENGINE` switch — which stays at `kCarrierStaggerFrac`, the stagger being a by-ear decision the project owner re-affirmed — unducked in the open at `press + 1.5 s`, where `duck()` computes `u = 6` and returns the send unchanged. What shipped: the carrier gets a **second** duck at the press for the global `set_sync` flip, and **keeps** its stagger duck. Authority is `engine/flow/flow.cpp` `begin_blend()` and the corrected spec §5.2.

**Tech Stack:** C++17, clang + Ninja, doctest (vendored in `third_party/`), CTest.

**Spec:** `docs/superpowers/specs/2026-08-06-glow-taste-structure-design.md` §5, §5.1–5.3, §8.

## Global Constraints

- Build engine/tests with clang + Ninja, never MSVC. `source env.sh` first, then
  `cmake -S . -B build -DCMAKE_BUILD_TYPE=Release`. **`-DCMAKE_BUILD_TYPE=Release`
  is not optional** — a Debug configure makes `spky_tests` and `ctrl_identity`
  fail with "SYNTH reference moved".
- Run tests with `ctest --test-dir build --output-on-failure`, or the single
  binary `./build/spky_tests -ts="<test suite>"` for a faster loop.
- Commit trailer is `Co-Authored-By: HAL 9000 <293417720+bea-ton-k@users.noreply.github.com>`.
- **Every test must be proven RED once** before its implementation lands. A test
  that cannot fail gets fixed, even if this plan mandated it.
- No bit-exactness gates. Renders are sanity checks, not checksums.
- FireFlow is in dev alpha: saved patches may change what they sound like. Do
  not add migrations or compatibility shims.
- `P_MODE` **must be the last entry** of `SPKY_FLOW_PARAMS`. Base draws are keyed
  `kStreamParamBase + uint32_t(param)` (`terrain.cpp:160`); inserting it anywhere
  else re-seeds every later parameter's stream.

## File Structure

| File | Responsibility after this plan |
|---|---|
| `engine/flow/flow_params.h` | `P_MODE` at enum tail; `apply_param` no longer handles `P_MODE`/`P_STEPS_A`/`P_STEPS_B` |
| `engine/flow/taste.h` | `kModeW[ARCH_COUNT]`; placeholder `P_MODE` base rule |
| `engine/flow/terrain.cpp` | draws `P_MODE` from `kModeW` in a new stage |
| `engine/flow/flow.cpp` | `push_mode_and_steps()` helper; `switch_phase_for` and the duck schedule know about `P_MODE` |
| `engine/flow/flow.h` | declares the helper |
| `tests/test_flow_mode.cpp` | **new** — enum tail, routing invariant, draw distribution, blend behaviour |
| `tests/test_flow_taste.cpp` | completeness check still green with `P_MODE` |
| `engine/flow/terrain.cpp` (comment) | re-measured `distance()` commentary |
| `tests/test_flow_audio.cpp` | re-measured RMS band, blend gate, churn gate |

---

### Task 1: P_MODE exists, at the tail, with a placeholder row

**Files:**
- Modify: `engine/flow/flow_params.h:70` (append to `SPKY_FLOW_PARAMS`)
- Modify: `engine/flow/taste.h` (add `kModeW`, add placeholder base rule)
- Create: `tests/test_flow_mode.cpp`
- Modify: `CMakeLists.txt:165` (register the new test file)

**Interfaces:**
- Produces: `P_MODE` (ParamId, range `0..1`, 2 steps; 0 = FLOW/free, 1 = STEP/synced);
  `inline const float kModeW[ARCH_COUNT]` = probability of STEP/synced per archetype.

- [ ] **Step 1: Write the failing test**

Create `tests/test_flow_mode.cpp`:

```cpp
// tests/test_flow_mode.cpp
#include "doctest/doctest.h"
#include "flow/taste.h"
#include "flow/flow_params.h"
using namespace spky::flow;

TEST_CASE("flow mode: P_MODE is the last parameter") {
    // Base draws are keyed kStreamParamBase + param (terrain.cpp). If P_MODE
    // is not last, every parameter after it gets a different RNG stream and
    // every existing terrain code resolves to a different sound.
    CHECK(P_MODE == P_COUNT - 1);
    CHECK(kParams[P_MODE].lo == 0.f);
    CHECK(kParams[P_MODE].hi == 1.f);
    CHECK(kParams[P_MODE].steps == 2);
}

TEST_CASE("flow mode: archetype weights are probabilities, drone lowest") {
    for (int a = 0; a < ARCH_COUNT; ++a) {
        CAPTURE(a);
        CHECK(kModeW[a] >= 0.f);
        CHECK(kModeW[a] <= 1.f);
    }
    // A drone is the archetype that normally wants no step sequencer.
    for (int a = 0; a < ARCH_COUNT; ++a)
        if (a != ARCH_DRONE) CHECK(kModeW[ARCH_DRONE] < kModeW[a]);
}
```

- [ ] **Step 2: Run test to verify it fails**

Register the file first — add `tests/test_flow_mode.cpp` to the `spky_tests`
source list in `CMakeLists.txt` after line 165, then:

```bash
source env.sh
cmake -S . -B build -DCMAKE_BUILD_TYPE=Release && cmake --build build
```

Expected: **compile error**, `'P_MODE' was not declared in this scope`. That is
the RED for this task.

- [ ] **Step 3: Append P_MODE at the enum tail**

In `engine/flow/flow_params.h`, extend the last line of the `SPKY_FLOW_PARAMS`
macro (currently `X(P_TEMPO_BPM, 50.f, 140.f, 0)`):

```cpp
  X(P_TEMPO_BPM, 50.f, 140.f, 0) \
  /* The terrain's operating mode, spec 2026-08-06 §5. 0 = FLOW/free (lanes
     breathe in their own kLaneRatio relationships, no grid), 1 = STEP/synced
     (step sequencer on the divisions.h ladder). ONE global value, not one per
     deck: Instrument::set_sync is global (instrument.h:274), so a per-deck
     mode would need SYNC on and off at once.
     MUST STAY LAST. Base draws are keyed kStreamParamBase + param
     (terrain.cpp:160) -- inserting a param before this one re-seeds every
     later stream and re-resolves every terrain code. */ \
  X(P_MODE,       0.f, 1.f,  2)
```

- [ ] **Step 4: Add kModeW and the placeholder base rule**

In `engine/flow/taste.h`, after the `kTextureW` block:

```cpp
// P_MODE draw weights (spec 2026-08-06 §5): probability that a terrain of this
// archetype comes out STEP/synced rather than FLOW/free. A drone normally has
// no step sequencer at all; an arp is one almost by definition.
// Order: {ARCH_DRONE, ARCH_PULSE, ARCH_ARP, ARCH_FRAGMENT}.
inline const float kModeW[ARCH_COUNT] = { 0.15f, 0.90f, 0.95f, 0.75f };
```

And in `kBaseRules`, alongside the other discrete world picks:

```cpp
// P_MODE: drawn from kModeW, NOT from this span. The row exists only so the
// coverage test has no hole -- exactly like the P_ENGINE_A/B rows above. Do
// not tune it expecting audible effect.
{ P_MODE,     {{0.f,1.f},{0.f,1.f},{0.f,1.f},{0.f,1.f}} },
```

- [ ] **Step 5: Run tests to verify they pass**

```bash
cmake --build build && ./build/spky_tests -ts="*" -tc="flow mode:*"
ctest --test-dir build --output-on-failure
```

Expected: the two new cases PASS, and `test_flow_taste.cpp`'s existing
"every param is owned" coverage check stays green because of the placeholder row.

- [ ] **Step 6: Commit**

```bash
git add engine/flow/flow_params.h engine/flow/taste.h tests/test_flow_mode.cpp CMakeLists.txt
git commit -m "feat(flow): the terrain gets an operating mode, and it sits at the enum tail"
```

---

### Task 2: Route mode and steps together, out of apply_param

**Files:**
- Modify: `engine/flow/flow_params.h:95-163` (`apply_param`: drop three cases)
- Modify: `engine/flow/flow.h:76` (declare the helper)
- Modify: `engine/flow/flow.cpp:434-441` (push tail calls the helper)
- Modify: `tests/test_flow_mode.cpp`

**Interfaces:**
- Consumes: `P_MODE` from Task 1.
- Produces: `void Flow::push_mode_and_steps(bool force);` — private; reads
  `_pushed[P_MODE]`, `_pushed[P_STEPS_A]`, `_pushed[P_STEPS_B]` and issues
  `set_sync` plus both `set_step` calls.

- [ ] **Step 1: Write the failing test**

Append to `tests/test_flow_mode.cpp`:

```cpp
#include "flow/flow.h"
#include "instrument.h"

TEST_CASE("flow mode: steps never run without a grid") {
    // The failure this guards: STEP mode on with SYNC off is a step sequencer
    // at a free-running rate, which is what Glow shipped with. No reachable
    // tick may show that combination.
    for (uint32_t master = 1; master <= 200; ++master) {
        spky::Instrument inst;
        inst.init(48000.f);
        Flow f;
        f.init(&inst, 100.f);
        TerrainState st; st.master = master;
        f.wake(st);
        for (int i = 0; i < 50; ++i) f.tick();
        CAPTURE(master);
        CHECK(inst.step_on(spky::PART_A) == inst.synced(spky::PART_A));
        CHECK(inst.step_on(spky::PART_B) == inst.synced(spky::PART_B));
    }
}
```

`Instrument` has no public part accessor — it exposes named observers instead
(`form(p)`, `song(p)` at `instrument.h:62-66`). Add two more in that style:

```cpp
    // Observers for the mode invariant (spec 2026-08-06 §5): steps and grid
    // are one decision, and a test must be able to see both halves of it.
    bool step_on(int p) const { return _parts[p].mod().step_on(); }
    bool synced(int p) const  { return _parts[p].mod().synced(); }
```

`SuperModulator::synced()` already exists (`super_modulator.h:160`); add its
twin beside it:

```cpp
bool step_on() const { return _step_on; }
```

- [ ] **Step 2: Run test to verify it fails**

```bash
cmake --build build && ./build/spky_tests -tc="flow mode: steps never run without a grid"
```

Expected: FAIL on the first master — `step_on()` is true (hardcoded at
`flow_params.h:107`) while `synced()` is false (nothing ever calls `set_sync`).
This is the RED that proves the bug the whole plan exists for. Record the
failure output in the commit message.

- [ ] **Step 3: Remove the three cases from apply_param**

In `engine/flow/flow_params.h`, delete the `P_STEPS_A` and `P_STEPS_B` cases and
add a comment where they were:

```cpp
    // P_MODE, P_STEPS_A and P_STEPS_B are deliberately NOT handled here.
    // set_step() takes mode AND count together and set_sync() is global, so
    // routing them needs all three values at once -- which this per-param,
    // stateless function cannot see. Flow::push_mode_and_steps() owns them.
    case P_MODE: case P_STEPS_A: case P_STEPS_B: break;
```

- [ ] **Step 4: Add the helper**

Declare in `engine/flow/flow.h` beside the other private helpers:

```cpp
    void push_mode_and_steps(bool force);
```

Implement in `engine/flow/flow.cpp`, above `recompute_and_push`:

```cpp
// P_MODE + P_STEPS_A/B, pushed as one unit (spec 2026-08-06 §5.3).
// apply_param cannot express this: set_step takes mode and count together, and
// set_sync is global across both parts (instrument.h:274). Issuing them here,
// from _pushed[], means no tick can ever observe steps without a grid.
void Flow::push_mode_and_steps(bool force) {
    if (!_inst) return;
    const bool step = _pushed[P_MODE] > 0.5f;
    const int  sa = int(clamp_to(kParams[P_STEPS_A], _pushed[P_STEPS_A]) + 0.5f);
    const int  sb = int(clamp_to(kParams[P_STEPS_B], _pushed[P_STEPS_B]) + 0.5f);
    if (!force && step == _mode_now && sa == _steps_now[0] && sb == _steps_now[1])
        return;
    _mode_now = step; _steps_now[0] = sa; _steps_now[1] = sb;
    _inst->set_sync(step);
    _inst->set_step(PART_A, step, sa);
    _inst->set_step(PART_B, step, sb);
}
```

Add the three state members to `engine/flow/flow.h` beside `_pushed`:

```cpp
    bool _mode_now = false;         // last pushed mode, for the change guard
    int  _steps_now[2] = { -1, -1 }; // last pushed step counts
```

- [ ] **Step 5: Call it from the push tail**

In `recompute_and_push`, after the per-parameter loop closes (`flow.cpp:441`):

```cpp
    }
    // All three of this unit's values are now in _pushed[]; route them as one.
    push_mode_and_steps(force);
}
```

- [ ] **Step 6: Run tests to verify they pass**

```bash
cmake --build build && ctest --test-dir build --output-on-failure
```

Expected: the invariant case PASSES for all 200 masters. Other flow tests may
now fail on changed audio — that is Task 5's work; note which, do not fix here.

- [ ] **Step 7: Commit**

```bash
git add engine/flow/flow_params.h engine/flow/flow.h engine/flow/flow.cpp engine/mod/super_modulator.h tests/test_flow_mode.cpp
git commit -m "fix(flow): mode and step count are one push, so steps can never run without a grid"
```

---

### Task 3: Draw P_MODE from the archetype weights

**Files:**
- Modify: `engine/flow/terrain.cpp:164-168` (after the stage 1-2 overrides)
- Modify: `tests/test_flow_mode.cpp`

**Interfaces:**
- Consumes: `kModeW` (Task 1), `pick_weighted` (already in `terrain.cpp:20`).
- Produces: `Terrain::base[P_MODE]` is 0.f or 1.f, never an intermediate value.

- [ ] **Step 1: Write the failing test**

Append to `tests/test_flow_mode.cpp`:

```cpp
#include "flow/terrain.h"

TEST_CASE("flow mode: the draw follows kModeW per archetype") {
    int n[ARCH_COUNT] = {}, step[ARCH_COUNT] = {};
    for (uint32_t master = 1; master <= 4000; ++master) {
        TerrainState st; st.master = master;
        const Terrain t = generate(st);
        // The value is a clean discrete, never something in between.
        CHECK((t.base[P_MODE] == 0.f || t.base[P_MODE] == 1.f));
        n[t.arch]++;
        if (t.base[P_MODE] > 0.5f) step[t.arch]++;
    }
    for (int a = 0; a < ARCH_COUNT; ++a) {
        if (n[a] < 100) continue;              // too few to judge
        const float got = float(step[a]) / float(n[a]);
        CAPTURE(a); CAPTURE(got); CAPTURE(kModeW[a]);
        CHECK(got > kModeW[a] - 0.08f);
        CHECK(got < kModeW[a] + 0.08f);
    }
}
```

- [ ] **Step 2: Run test to verify it fails**

```bash
cmake --build build && ./build/spky_tests -tc="flow mode: the draw follows kModeW per archetype"
```

Expected: FAIL — `base[P_MODE]` comes from the placeholder base rule's uniform
`{0,1}` span, so it is a continuous value (the first `CHECK` fires immediately)
and the STEP share sits near 0.5 for every archetype.

- [ ] **Step 3: Draw it in terrain.cpp**

In `generate()`, directly after the stage 1-2 override block
(`t.base[P_ROOT] = float(root);`):

```cpp
    // Stage 3b: operating mode (spec 2026-08-06 §5). Its base-rule row is a
    // placeholder like the ENGINE rows -- the real draw is this weighted coin,
    // taken from the param's OWN stream so it rerolls exactly when a full
    // terrain does. Written as a clean 0/1 so nothing downstream has to guess
    // where the rounding boundary is.
    {
        Rng r = make_stream(st.master, kStreamParamBase + uint32_t(P_MODE), 0);
        const float w[2] = { 1.f - kModeW[t.arch], kModeW[t.arch] };
        t.base[P_MODE] = float(pick_weighted(r, w, 2));
    }
```

- [ ] **Step 4: Run tests to verify they pass**

```bash
cmake --build build && ./build/spky_tests -tc="flow mode:*"
```

Expected: PASS. Every archetype's measured STEP share sits within 0.08 of its
weight.

- [ ] **Step 5: Prove the test can fail**

Temporarily change `kModeW[ARCH_DRONE]` to `0.90f`, rebuild, confirm the case
goes RED with the drone row out of tolerance, then revert.

> **CORRECTION 2026-08-06, post-implementation — this perturbation cannot work.**
> It is self-referential: `kModeW` feeds **both** the draw in `terrain.cpp` and
> the tolerance window the test asserts against (`got > kModeW[a] - 0.08f`).
> Moving the weight moves the target and the goalposts by the same amount, so
> the case stays green by construction. To redden it, perturb only one side —
> e.g. hard-code a literal probability in the generator's `P_MODE` draw, or
> assert against a literal in the test. A genuine RED was obtained instead on
> that case's other new assertion (`judged == ARCH_COUNT`) by raising the
> `n[a] < 100` skip threshold.

- [ ] **Step 6: Commit**

```bash
git add engine/flow/terrain.cpp tests/test_flow_mode.cpp
git commit -m "feat(flow): drones stop drawing a step sequencer they never wanted"
```

---

### Task 4: P_MODE switches at phase 0, under a double duck

**Files:**
- Modify: `engine/flow/flow.cpp:288-292` (`switch_phase_for`)
- Modify: `engine/flow/flow.cpp` (`begin_blend`, the `_duck_t` schedule)
- Modify: `tests/test_flow_mode.cpp`

**Interfaces:**
- Consumes: `P_MODE` draw (Task 3), `push_mode_and_steps` (Task 2).
- Produces: `switch_phase_for(P_MODE) == 0.f`; on a mode-changing press both
  `_duck_t[0]` and `_duck_t[1]` are set to the press instant.

- [ ] **Step 1: Write the failing test**

> **CORRECTION 2026-08-06, post-implementation — the sentinel in this snippet is
> vacuous.** `if (a.master && b.master) break;` is meant to stop once both a FLOW
> and a STEP terrain have been found, but `TerrainState::master` **defaults to 1,
> not 0** (`engine/flow/terrain.h`), so both sides are already truthy on entry and
> the loop breaks on its first iteration with `a` and `b` possibly unset. The
> `REQUIRE(a.master != 0)` guards below are vacuous for the same reason. Use
> explicit `have_flow` / `have_step` bools instead — which is what the shipped
> cases in `tests/test_flow_mode.cpp` do. Note also that this case's premise
> (both decks ducked *instead of* the stagger) is superseded; see the Task 4
> Step 4 correction below.

Append to `tests/test_flow_mode.cpp`:

```cpp
TEST_CASE("flow mode: a mode change ducks both decks at the press") {
    // P_MODE belongs to no deck, and set_sync is global -- so it cannot ride
    // the carrier stagger without flipping the texture deck's whole clocking
    // 1.5 s after that deck's own duck had already closed. A mode change is a
    // whole-terrain event: it goes at phase 0 with BOTH decks ducked.
    spky::Instrument inst;
    inst.init(48000.f);
    Flow f;
    f.init(&inst, 100.f);

    // Find two terrains that differ in mode.
    TerrainState a, b;
    for (uint32_t m = 1; m < 500; ++m) {
        TerrainState s; s.master = m;
        if (generate(s).base[P_MODE] > 0.5f) { b = s; } else { a = s; }
        if (a.master && b.master) break;
    }
    REQUIRE(a.master != 0);
    REQUIRE(b.master != 0);

    f.wake(a);
    for (int i = 0; i < 20; ++i) f.tick();
    const bool before = inst.step_on(spky::PART_A);

    f.wake(b);                       // instant, no blend: the mode really moved
    f.tick();
    CHECK(inst.step_on(spky::PART_A) != before);

    // Now the blended path: the mode must be live within one tick of the
    // press, not a quarter of the ramp later.
    f.wake(a);
    for (int i = 0; i < 20; ++i) f.tick();
    f.restore_undo(b, true);
    REQUIRE(f.undo());               // blends toward b
    f.tick();
    CHECK(f.blend_phase() < kCarrierStaggerFrac);
    CHECK(inst.step_on(spky::PART_A) == (generate(b).base[P_MODE] > 0.5f));
}

TEST_CASE("flow mode: P_MODE is scheduled with the texture deck, not the carrier") {
    CHECK(spky::flow::switch_phase_for_test(P_MODE) == 0.f);
}
```

Expose the scheduler for the test next to the existing `terrain_for_test`
pattern in `engine/flow/flow.h`:

```cpp
#ifdef SPKY_TESTING
    float switch_phase_for_test(int p) const { return switch_phase_for(p); }
#endif
```

and a free wrapper beside `terrain_of`:

```cpp
#ifdef SPKY_TESTING
inline float switch_phase_for_test(int p) {
    static Flow probe; return probe.switch_phase_for_test(p);
}
#endif
```

- [ ] **Step 2: Run test to verify it fails**

```bash
cmake --build build && ./build/spky_tests -tc="flow mode: P_MODE is scheduled*"
```

Expected: FAIL — `deck_of(P_MODE)` returns −1, so `switch_phase_for` falls
through to `_carrier_deck` and returns `kCarrierStaggerFrac` (0.25), not 0.

- [ ] **Step 3: Schedule P_MODE at phase 0**

In `engine/flow/flow.cpp`, amend `switch_phase_for`:

```cpp
float Flow::switch_phase_for(int p) const {
    // P_MODE is a whole-terrain event, not a per-deck one: set_sync is global
    // (instrument.h:274), so its switch flips BOTH decks' rate mapping at once.
    // Riding the carrier would jump the texture deck's clocking 1.5 s after
    // that deck's own duck had closed -- exactly what the stagger prevents. So
    // it goes at the press, with the texture deck, and begin_blend() opens both
    // ducks for it.
    if (p == P_MODE) return 0.f;
    int d = deck_of(p);
    if (d < 0) d = _carrier_deck;
    return d == _carrier_deck ? kCarrierStaggerFrac : 0.f;
}
```

- [ ] **Step 4: Duck both decks when the mode moves**

> **CORRECTION 2026-08-06, post-implementation — DO NOT RE-EXECUTE THIS STEP AS
> WRITTEN.** The `if (mode_moves) _duck_t[0] = _duck_t[1] = _t;` line below (and
> the comment block above it, which repeats the collapse and the gate-coverage
> claim) was built and then escalated as **Critical** in review. Overwriting the
> carrier's slot moves its duck off `kCarrierStaggerFrac`, leaving the carrier
> deck's own `P_ENGINE` switch — which stays at 1.5 s, the stagger being a by-ear
> decision the project owner re-affirmed — in the open, where `duck()` computes
> `u = 6` and returns the send unchanged. The shipped design instead makes
> `_duck_t` a **two-slot-per-deck** schedule and *adds* a duck:
> `if (mode_moves) _duck_t[_carrier_deck][1] = _t;`, with `duck()` combining a
> deck's slots by maximum. The gate-coverage claim in the snippet's comment is
> also wrong: only the press-instant duck lands inside `kBlendGateWindowS`; the
> stagger duck is still structurally outside it. Authority: `engine/flow/flow.cpp`
> `begin_blend()`, the corrected spec §5.2, and the `kBlendGateWindowS` comment
> in `engine/flow/taste.h`.

In `begin_blend`, where `_duck_t` is scheduled, add the mode case. The existing
code sets the texture deck's duck at `_t` and the carrier's at
`_t + kCarrierStaggerFrac * kBlendS`; override the carrier when the incoming
terrain's mode differs from the outgoing one:

```cpp
    // A mode change collapses the stagger on purpose: both decks' clocking
    // flips at the press, so both ducks open there too. A mode-changing NEW is
    // a harder cut than a same-mode one, which is honest -- the terrain is
    // going from ambient to rhythm or back. Both ducks then fall inside
    // kBlendGateWindowS, so the level gate actually covers this transition.
    const bool mode_moves =
        (_terrain.base[P_MODE] > 0.5f) != (_prev_terrain.base[P_MODE] > 0.5f);
    if (mode_moves) _duck_t[0] = _duck_t[1] = _t;
```

- [ ] **Step 5: Run tests to verify they pass**

```bash
cmake --build build && ./build/spky_tests -tc="flow mode:*"
```

Expected: both new cases PASS.

- [ ] **Step 6: Listen to it once**

Build the VCV module and press NEW until a mode change happens (a drone
followed by an arp will usually do it):

```bash
cd host/vcv && ./build-local.sh
```

`ModLane::set_step` entering step mode sets `_song.new_pending`
(`lane.cpp:156-158`), so a mode flip regenerates phrase material under the
double duck. Confirm by ear that this reads as a transition rather than a
glitch. If it does not, record what you heard in the plan — do not retune the
duck constants silently, they are by-ear values.

- [ ] **Step 7: Commit**

```bash
git add engine/flow/flow.cpp engine/flow/flow.h tests/test_flow_mode.cpp
git commit -m "feat(flow): a mode change is a whole-terrain cut, ducked on both decks"
```

---

### Task 5: Re-measure every gate the mode moved

**Files:**
- Modify: `engine/flow/terrain.cpp:241-257` (the `distance()` commentary)
- Modify: `engine/flow/taste.h` (`kFixedSeedRmsMin/Max`, `kBlendSpikeDb`, `kBlendDropDb`, `kDiscreteChurnMax` if they move)
- Modify: `tests/test_flow_audio.cpp`
- Create: `bench/measure_mode_gates.cpp` (throwaway measuring harness, deleted in the last step)

**Interfaces:**
- Consumes: everything from Tasks 1–4.
- Produces: re-measured constants, each with a comment naming the measurement
  that produced it.

**This task is measurement, not tuning.** Every number below is *measured and
then written down*, never nudged until a test goes green. If a gate cannot be
made green by an honest measurement, that is a finding about the mode change,
and it gets reported rather than absorbed.

- [ ] **Step 1: Run the full suite and record what is red**

```bash
source env.sh && cmake --build build && ctest --test-dir build --output-on-failure 2>&1 | tee /tmp/mode-gates-before.txt
```

Write the list of failing cases into the commit message draft. Expect
`test_flow_audio.cpp` cases; `check_render_hash.cmake` should stay green (it
drives the render host over engine scenarios, not the flow layer) — if it went
red, stop and investigate, because that means the mode work touched the engine
core.

- [ ] **Step 2: Measure the terrain distance distribution**

Write `bench/measure_mode_gates.cpp`:

```cpp
// Throwaway: re-measures the numbers quoted in terrain.cpp's distance()
// comment after P_MODE joined the parameter table. Deleted once the comment
// is updated.
#include "flow/terrain.h"
#include "flow/taste.h"
#include <cstdio>
#include <algorithm>
using namespace spky::flow;

int main() {
    float mn = 1e9f, mx = -1e9f, sum = 0.f;
    int same_arch = 0, same_arch_clears = 0, n = 0;
    for (uint32_t i = 1; i <= 20000; ++i) {
        TerrainState a, b; a.master = i * 2 - 1; b.master = i * 2;
        const Terrain ta = generate(a), tb = generate(b);
        float base = 0.f;
        for (int p = 0; p < P_COUNT; ++p)
            base += std::fabs(ta.base[p] - tb.base[p])
                  / (kParams[p].hi - kParams[p].lo);
        base /= float(P_COUNT);
        mn = std::min(mn, base); mx = std::max(mx, base); sum += base; ++n;
        if (ta.arch == tb.arch) {
            ++same_arch;
            if (base >= kDistanceMin) ++same_arch_clears;
        }
    }
    std::printf("base-patch mean: min %.4f mean %.4f max %.4f (n=%d)\n",
                mn, sum / float(n), mx, n);
    std::printf("same-archetype pairs %d, of which clear kDistanceMin: %d\n",
                same_arch, same_arch_clears);

    Rng seq; seq.seed(12345);
    TerrainState cur; cur.master = 1;
    int same = 0;
    for (int i = 0; i < 3000; ++i) {
        const TerrainState nxt = draw_new(cur, seq);
        if (generate(nxt).arch == generate(cur).arch) ++same;
        cur = nxt;
    }
    std::printf("draw_new returned a same-archetype terrain %d times in 3000\n",
                same);
    return 0;
}
```

Add it to `bench/CMakeLists.txt` following the pattern of the existing bench
targets, build, and run it:

```bash
cmake --build build --target measure_mode_gates && ./build/bench/measure_mode_gates
```

- [ ] **Step 3: Rewrite the distance() commentary with the measured numbers**

Replace the numbers in `terrain.cpp:241-257` with what Step 2 printed, and add
one sentence naming why they moved:

```cpp
// Re-measured 2026-08-06 after P_MODE joined the parameter table (spec
// §5.1): the mean is over P_COUNT params, so one more param changes the
// denominator, and a mode mismatch contributes a full 1.0/P_COUNT of its own.
// Over 20 000 random terrain pairs the base-patch mean spans
// <MIN> (min) / <MEAN> (mean) / <MAX> (max) ... draw_new returned a
// same-archetype terrain <N> times in 3 000 calls.
```

Keep the closing paragraph unchanged: `kDistanceMin` and the flat `0.25` stay
by-ear knobs and must not be "fixed" from the code side.

- [ ] **Step 4: Re-measure the audio gates**

For each red case in `test_flow_audio.cpp`, read the comment in `taste.h` that
records how its constant was originally measured, and repeat *that* measurement
against the new mode-drawing generator:

- `kFixedSeedRmsMin/Max` — windowed RMS across the same 8 terrains at all macros
  0.5. Record the new band and set the constants with the same margins the old
  comment describes (two orders of magnitude below `kCalmCornerRmsMax` on the
  low side, below full scale on the high side).
- `kBlendSpikeDb` / `kBlendDropDb` — the differential press-vs-control
  comparison inside `kBlendGateWindowS`. The mode change now ducks **both**
  decks at phase 0, which falls inside the 1.0 s window, so the carrier deck's
  transition is measured here for the first time. If the measured spike exceeds
  6 dB, report it: it means the double duck is not covering the transition, and
  that is a design finding for the spec, not a constant to raise.
- `kDiscreteChurnMax` — `P_MODE` is a discrete and can now change; confirm the
  per-60 s churn count with static macros still fits, and if not, state the new
  measured maximum.

Update each constant's comment to say it was re-measured on 2026-08-06 and what
the measurement was.

- [ ] **Step 5: Re-choose kHouseCode by ear**

`kHouseCode` is documented in `taste.h:43-49` as a placeholder chosen by a
render pass that could only judge level, to be re-chosen by ear once Glow could
be played. Build the VCV module, press NEW until a terrain is worth waking on,
and read its code from the module:

```bash
cd host/vcv && ./build-local.sh
```

Replace `kHouseCode` and rewrite its comment to say it was chosen by ear on
2026-08-06, naming what it sounds like. Delete the paragraph explaining the
render-pass placeholder.

- [ ] **Step 6: Delete the measuring harness and run everything**

```bash
git rm bench/measure_mode_gates.cpp
# revert the bench/CMakeLists.txt entry too
cmake -S . -B build -DCMAKE_BUILD_TYPE=Release && cmake --build build
ctest --test-dir build --output-on-failure
```

Expected: fully green.

- [ ] **Step 7: Commit**

```bash
git add engine/flow/terrain.cpp engine/flow/taste.h tests/test_flow_audio.cpp bench/CMakeLists.txt
git commit -m "test(flow): the mode change moved four gates, so all four were measured again"
```

---

## Done when

- `ctest --test-dir build --output-on-failure` is green.
- No reachable tick has `step_on() != synced()` on either deck.
- `P_MODE == P_COUNT - 1`, asserted by test.
- Every constant that moved carries a comment naming its new measurement and
  its date.
- `kHouseCode` was chosen by ear, not by render.

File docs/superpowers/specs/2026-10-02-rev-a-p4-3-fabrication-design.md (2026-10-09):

# FireFlow Rev A — P4-3: fabrication data

**Date:** 2026-10-02
**Status:** approved (Bastian, 2026-10-02); implemented on branch reva-p4-3-fab
**Parent:** the Rev A master plan
(`docs/superpowers/specs/2026-09-28-rev-a-master-plan-design.md`), sub-project
P4, the layout generator. Follows P4-1
(`docs/superpowers/specs/2026-09-29-rev-a-p4-1-placement-design.md`) and P4-2
(`docs/superpowers/specs/2026-09-30-rev-a-p4-2-routing-design.md`, merged
2026-10-01).

## 1. What P4-3 delivers

P4-1 §1 cut P4 into three parts; P4-3 is the last one: **silkscreen (master
plan working rule 3), assembly sheet, Gerbers, JLC BOM and CPL.** It also
closes P4-1's hand-off: the placed footprints carry no schematic `(path …)`
links, so "Update PCB from schematic" and parity checks do not match them
(roadmap, 2026-09-30; P4-2 spec §8).

P4-3 has two halves:

- **(a) Board content, inside the existing chain.** The committed
  `hardware/reva/kicad/reva.kicad_pcb` stays the one finished board. It gains
  schematic links, footprint fields, DNP flags and a readable silkscreen, and
  KiCad's schematic parity reports nothing against it.
- **(b) Export, a new stage.** `hardware/reva/fab.py` turns the committed board
  into the order package: Gerbers, drill files, the JLC CPL, the JLC BOM, the
  assembly sheet and renders, with its own checks and guard.

Like P4-1 and P4-2, P4-3 runs now, before the panel freeze (6 Nov). The
pipeline and every check are built and green against today's board. The
order-ready package is **not** committed until the panel pass has left no
known entry without a sign-off; it is then one re-run (§9). *(Amended
2026-10-08, §4.4.6: this said "has emptied the known lists"; a deliberate
entry with a sign-off no longer blocks.)*

## 2. Decisions taken in brainstorming (Bastian, 2026-10-02)

1. **Pipeline now, package later.** Everything in §1 is built and runs on
   today's board. Outputs land in `hardware/reva/out/fab/` (gitignored).
   `fab.py --release` writes the committed package to `hardware/reva/fab/` and
   refuses while a known entry has no sign-off or a rotation entry is
   unverified (§4.4.3, §4.4.6). The refusal is not a ctest gate, so ctest
   stays green before the freeze. *(Amended 2026-10-08: this said "while a
   known list is non-empty"; see §4.4.6.)*
2. **Front silkscreen: outlines and polarity only.** The front disappears
   behind the plate and carries only the 112 hand-soldered panel parts.
   Footprint outlines and polarity marks (LED flat, pin 1) stay; reference
   texts are hidden. Which part goes where is on the assembly sheet.
3. **Back references: search, otherwise a list.** Every back-side reference
   gets a free spot near its part found by search. If none exists, it is
   hidden and listed in `NO_ROOM`, a tight known list (a stale or a new entry
   is red). The assembly sheet shows every part.
4. **Approach 1 of three: board content inside the chain.** Schematic links and
   DNP are set at placement; the silkscreen pass is the last step of
   `route.build()`; export is a separate stage. Rejected: a post-processing
   stage that writes the committed board after routing (two board states, and
   `reva_route_guard`'s byte-identity would move to an intermediate file), and
   silkscreen only in the fabrication copy (the committed board would not be
   what gets made, and KiCad parity would stay broken).
5. **Real parity.** The schematic generator writes every Rev A net label as a
   global label, so KiCad names the nets exactly as the board does; the board
   gives unconnected pins KiCad's `unconnected-(…)` net names. KiCad's parity
   check then reports zero and "Update PCB from schematic" changes nothing.
   Fallback, also approved: if the wider global labels do not fit the A3
   sheets (§7), keep local labels and gate parity with an exact naming rule
   (`/<sheet of the symbol>/NAME` ≡ `NAME`, `unconnected-(…)` ≡ no net).
6. **Rule 6 holds for the assembly sheet.** The general part of
   `hardware/coupon/scripts/assembly_plan.py` moves to `hardware/gen/`; the
   coupon keeps its own classes and its output stays byte-identical.

## 3. Measured facts this spec rests on

Probed 2026-10-02 under KiCad 10.0.5 (`kicad-cli`, KiCad's Python) against the
committed board at `91628e8f`, on a scratch copy of `hardware/reva/kicad/` and
`hardware/lib/`. The probe scripts were scratch; the plan's tasks re-derive
every number through the real code.

**Board as committed** (from the file and `out/reva-routed-drc.rpt`):

- 213 footprints. F.Cu: 112 THT panel parts (70 pots, 19 LEDs, 18 jacks,
  4 keys, J_SD). B.Cu: 101 parts — 84 with attribute `smd` (36 R0603,
  23 C0603, 5 C0805, 1 tantalum, 2 D_SMA, 16 SOIC-16, 1 SOT-223), 15 test
  points (`exclude_from_pos_files exclude_from_bom`), U_SM and J_PWR (THT,
  hand-soldered).
- The 84 `smd` parts include the six DNP options (C_LDO_T, C_SENSE0–3, C_SD2);
  `bom-jlc.csv` places 78. **No footprint carries a DNP attribute.**
- References: all visible, 1.0 × 1.0 mm, 0.15 mm stroke (U_SM 1.27 mm), front
  parts on F.SilkS, back parts on B.SilkS. Values on F.Fab/B.Fab. One
  footprint-internal B.SilkS text: U_SM's "INSTALL ON …". No board-level silk.
- DRC silk classes (none gated today, `GATED_DRC` in `route_check.py`):
  `silk_over_copper` 127 (103 of them reference fields), `silk_overlap` 56
  (55 reference fields; 54 entries involve footprint silk shapes on
  B.Silkscreen), `silk_edge_clearance` 38 (36 jack outline segments past the
  edge, 2 jack references). U_SM's "INSTALL ON" text is in 10 entries.
- Vias are tented on both sides (`(tenting (front yes) (back yes))`), so silk
  over a via is not over exposed copper.
- 0 `(path …)` on any footprint; footprint IDs carry no library nickname
  (`C_0805_2012Metric`, not `Capacitor_SMD:C_0805_2012Metric`).

**Gerbers and drill** (`kicad-cli pcb export gerbers` / `drill`, defaults):

- 27 files: 26 layers plus `reva-job.gbrjob`; drill is one combined
  `reva.drl` (1207 coordinate lines). `--excellon-separate-th` exists.
- Two runs four seconds apart differ in all 27 Gerber files and the drill
  file, only in date lines: `%TF.CreationDate,…*%` and `G04 Created by KiCad
  (PCBNEW 10.0.5) date …*` in every Gerber, `; DRILL file KiCad 10.0.5 date …`
  and `; #@! TF.CreationDate,…` in the drill file, `"CreationDate"` in the job
  file. With those lines removed, 0 of 27 Gerber files and the drill file
  differ. `--no-x2` does not help: the date moves into a `G04 #@!` comment.

**Positions** (`kicad-cli pcb export pos --format csv --units mm --side both`):

- 198 rows (213 − 15 test points), header
  `Ref,Val,Package,PosX,PosY,Rot,Side`, side `bottom` for back parts.
- PosY is negated against the board: C1 is `70.62, -57.48` in the file and
  `(70.62, 57.48)` in the DRC report.
- Filters exist: `--smd-only`, `--exclude-dnp`, `--exclude-fp-th`,
  `--bottom-negate-x`, `--use-drill-file-origin`.

**Schematic parity** (`kicad-cli pcb drc --schematic-parity --format json`):

- Committed board: 597 items, 199 each of `footprint_symbol_mismatch` (the
  library nickname), `footprint_symbol_field_mismatch` (missing `LCSC` and the
  other symbol fields) and `net_conflict`.
- With path, full footprint ID, every symbol field and DNP set on each
  footprint (pcbnew API: `SetPath`, `SetFPID`, `SetField`, `SetDNP`,
  `SetSheetname`, `SetSheetfile`, `SetExcludedFromPosFiles` all exist): 199
  items, all `net_conflict`, all naming:
  - 177: the schematic names a net from a local label `/<sheet>/NAME`
    (sheets `chains`, `mux_sense_0`–`3`, `power`), the board `NAME`.
  - the rest (22 in this first probe; **40 as measured in Task 3, see the
    correction below**): an unconnected pin, which the schematic names
    `unconnected-(…)` and the board leaves without a net.
- The schematic has 120 local label names, **none on more than one sheet**,
  and 180 global labels. Turning every local label global merges no nets.
- **Parity matches footprints to symbols by reference, not by path.** The same
  199 items came back with correct paths, with paths that keep the root sheet
  (wrong) and with R1's and R2's paths swapped. Parity therefore cannot prove
  the paths; §5.1 checks them separately.
- KiCad's netlist (`kicad-cli sch export netlist --format kicadsexpr`) gives
  each component `(sheetpath (tstamps "/<sheet uuid>/"))` and
  `(tstamps "<symbol uuid>")` — C1: sheet `565f096c-…`, symbol `7b439dd9-…`.
  The footprint path is their concatenation; the root sheet does not appear.
  The export prints "the schematic has annotation errors" and still writes the
  file; the cause is probed in the next bullet.
- Probed during execution, 2026-10-02: the annotation warning comes from the
  five references without a trailing digit (`C_LDO_T`, `J_PWR`, `J_SD`,
  `U_REG`, `U_SM`). Appended a 9 to each in a copy of the schematic, the same
  export printed nothing. The export exits 0 while warning and writes the full
  file. The netlist holds 213 components, one per board footprint, and every
  one carries `tstamps`, the five bare-named ones included (U_REG:
  `bde6db50-…`). The other four of the 217 schematic references, J_SM1–J_SM4,
  are `(on_board no)` and absent from the netlist, as they are from the board.
  The netlist is multi-line s-expression text; read it with a parser, not a
  single-line regex. `kicad-cli sch erc` on the same schematic reports 3
  violations (`pin_not_driven` 2, `pin_to_pin` 1) and no annotation class.
- 217 schematic symbols carry references, 213 footprints. J_SM1–J_SM4 (the
  module's sockets) have no footprint, and parity did not report them.
- **Correction, 2026-10-02 (Task 3).** Task 3 measured 40 single-pad
  `unconnected-(…)` nets, not 22: the jacks' TN pins have no pin name, and
  KiCad names their net `unconnected-(J1-PadTN)`. The earlier "199 each"
  counts were very likely capped by KiCad's per-type report limit (an
  inference, not probed).
- Probed during execution, 2026-10-02 (Task 6), `kicad-cli` 10.0.5 on the
  committed board after Task 4, with the plan's flags (`--layers` the 11 names,
  `export drill --excellon-separate-th`, `export pos --format csv --units mm
  --side both --smd-only --exclude-dnp`):
  - Gerber files, 11 plus the job file `reva-job.gbrjob` (dropped from the
    package): `reva-F_Cu.gtl`, `reva-In1_Cu.g1`, `reva-In2_Cu.g2`,
    `reva-B_Cu.gbl`, `reva-F_Mask.gts`, `reva-B_Mask.gbs`,
    `reva-F_Silkscreen.gto`, `reva-B_Silkscreen.gbo`, `reva-F_Paste.gtp`,
    `reva-B_Paste.gbp`, `reva-Edge_Cuts.gm1`.
  - Drill files: `reva-PTH.drl` with 1207 coordinate lines (slots are one line
    with `G85`) and `reva-NPTH.drl`, written with 0 holes: the board has no
    NPTH pad. Both counts equal pcbnew's (vias plus pads with a drill).
  - CPL: 78 data rows plus the header `Ref,Val,Package,PosX,PosY,Rot,Side`
    (English, fields quoted), all `bottom`. The six package names:
    `C_0603_1608Metric` (19), `C_0805_2012Metric` (4), `D_SMA` (2),
    `R_0603_1608Metric` (36), `SOIC-16_3.9x9.9mm_P1.27mm` (16),
    `SOT-223-3_TabPin2` (1). The 78 designators are those of `bom-jlc.csv`.
  - Edge.Cuts in the Gerber spans X 2 to 302.8 mm and Y -9.25 to -119.25 mm
    (300.8 x 110.0): Gerber y is the board's y negated, as the CPL's is, so one
    extent serves both checks.
  - Date forms: the five patterns in `normalise()` cover every one; after
    normalising, `grep 20[0-9][0-9]-` finds only the fixed date.

**Line endings.** On the development machine (`core.autocrlf=true`)
`hardware/reva/build.py` writes `bom-hand.csv`, `bom-jlc.csv`, `review.md`,
`kicad/fp-lib-table` and `kicad/sym-lib-table` with LF over a CRLF checkout;
`git status` then lists all five as modified with an empty diff. With
`text eol=lf` for those paths in `.gitattributes`, a fresh checkout should
write LF and `git status` should stay empty after `build.py` (the expected
effect). Observed: after the change, `build.py` left `git status` clean in the
P4-3 worktree; the "modified" state did not reproduce there before the change,
so the trap and its fix were not seen side by side.

**Router.** `route.py:271` skips any net with fewer than two terminals, so the
single-pad `unconnected-(…)` nets (40, not 22: see the Task 3 correction in the
parity bullets above) add no routing work.

## 4. Design

### 4.1 Pipeline and files

```
python hardware/reva/build.py            schematic (global labels), BOMs, review
KIPY   hardware/reva/place.py            placed board; paths, fields, DNP set here
KIPY   hardware/reva/route.py [--write]  routed board; silk.apply() last; commits
KIPY   hardware/reva/fab.py [--release]  order package from the committed board
```

| File | Role |
|---|---|
| `hardware/gen/sch_writer.py` | option: every label global (Rev A on, coupon off) |
| `hardware/gen/kipcb.py` | `link_part` sets path, full footprint ID, fields, DNP, sheet name/file on a placed footprint; `set_pad_net` |
| `hardware/reva/place.py` | computes each footprint's link from the schematic module; names unconnected pads |
| `hardware/reva/silk.py` (new) | the silkscreen pass, a pure function on a board |
| `hardware/reva/route.py` | calls `silk.apply()` after the zone fill |
| `hardware/reva/route_check.py` | new steps §5.1 |
| `hardware/reva/fab.py` (new) | the export stage |
| `hardware/reva/fab_check.py` (new) | its checks, §5.2 |
| `hardware/gen/assembly.py` (new) | label search, overlap check and SVG, from the coupon |
| `hardware/reva/test_fab.py` (new) | `reva_fab_guard` |
| `.gitattributes` | `text eol=lf` for the five generated text files |

### 4.2 Schematic links (board half)

- **Global labels.** `sch_writer` gains a switch that emits every net label as
  a global label. Rev A's `build.py` sets it; the coupon does not, and its
  regenerated schematic must come out byte-identical to the committed one.
  `hw_gen_coupon_guard` compares nets only, so the plan proves the bytes
  itself. The P3
  files are regenerated; `reva_build_guard` and `reva_check_guard` (ERC
  against the waivers) must stay green on the new files.
- **Footprint links.** `place.py` reads, for each reference, the symbol UUID
  and its sheet's UUID from the module that builds the schematic (the uuid5
  keys in `sch_writer.Uuids`), never from a hand-copied table. After all parts
  are placed, `kipcb.link_part` gives each footprint the path
  `/<sheet uuid>/<symbol uuid>`, the full footprint ID (`nickname:name`),
  every symbol field (LCSC, Description, Datasheet …), DNP, Sheetname and
  Sheetfile. (One pass at the end rather than inside `add_part`, which has
  six call sites in `place.py`; amended with the plan, 2026-10-02.) The 15 test points keep
  `exclude_from_pos_files` and `exclude_from_bom`.
- **Unconnected pads.** `place.py` gives each pad whose pin the schematic
  leaves unconnected KiCad's `unconnected-(<ref>-<pin name>-Pad<n>)` net
  (measured form: `unconnected-(J_PWR-Pin_7-Pad7)`,
  `unconnected-(U_IN1-~{Q7}-Pad7)`). The name is composed in `place.py`;
  parity (§5.1) is the independent check that KiCad names it the same.
- **Docstring debt.** `kipcb.new_board`'s docstring says `SetPath` is never
  called and matching is by reference; it is rewritten with this change.

### 4.3 Silkscreen (`silk.py`)

`silk.apply(board)` runs last in `route.build()`, after the zone fill, so
`reva_route_guard`'s byte-identity covers it. For development it runs alone on
`out/reva-routed.kicad_pcb` in seconds (`KIPY hardware/reva/silk.py`), without
a 223 s route.

- **Front.** Every front footprint's reference is hidden. Outlines and
  polarity marks stay as the footprint draws them.
- **Back.** Every back reference is set to 1.0 mm height, 0.15 mm stroke.
  Candidates are generated around the footprint's courtyard: four sides,
  rotation 0° or 90°, growing distance in fixed steps up to a cap. The first
  candidate wins that lies entirely inside the board edge with margin, over no
  mask opening (pads; vias are tented) and over no other silk (text or
  footprint graphic, including references already placed). Placement order is
  fixed (sorted by reference) so the result is deterministic.
- **No room.** A reference without a free candidate is hidden and must be in
  `NO_ROOM`, a module-level set in `silk.py` with one reason comment per
  entry. The plan's first silk run measures the list; it is not guessed here.
- **Footprint-internal text** (U_SM's "INSTALL ON …"): moved like a
  reference if it is free-standing user text, otherwise hidden and printed on
  the assembly sheet instead. The plan measures which applies.
- **What is gated is text**, as rule 3 says: height, and no text over a pad or
  over other silk. The verdict comes from KiCad's DRC, not from the placer's
  own collision model (§5.1), so the check does not grade its own homework.
  Overlap of pure footprint graphics is counted and printed, not gated; JLC
  clips silk off pads in any case.

### 4.4 Export (`fab.py`)

`KIPY hardware/reva/fab.py [--release] [--sabotage NAME] [--out DIR]` reads
the committed board and its project (schematic next to it) and writes to
`hardware/reva/out/fab/`:

#### 4.4.1 Gerbers and drill

- `kicad-cli pcb export gerbers --layers` with exactly eleven layers: F.Cu,
  In1.Cu, In2.Cu, B.Cu, F.Mask, B.Mask, F.Silkscreen, B.Silkscreen, F.Paste,
  B.Paste, Edge.Cuts. Protel extensions (the default).
- `kicad-cli pcb export drill --excellon-separate-th`: PTH and NPTH files.
- **Dates are normalised, not deleted:** each date field in the lines listed
  in §3 is replaced by one fixed constant, so every file stays a valid Gerber
  or Excellon file and two exports are byte-identical. The job file is not
  part of the package.
- `reva-gerbers.zip` is written with fixed member timestamps and sorted
  members, so the zip is byte-stable too.

#### 4.4.2 CPL

- Source: `kicad-cli pcb export pos --format csv --units mm --side both
  --smd-only --exclude-dnp`. Expected 78 rows, the BOM's placements; the plan
  measures it.
- Rewritten to JLC's columns `Designator,Mid X,Mid Y,Layer,Rotation`: layer
  `Bottom` for KiCad side `bottom`, coordinates as KiCad writes them (the
  Gerbers use the same absolute origin), rotation plus the correction of
  §4.4.3.

#### 4.4.3 Rotation corrections (`ROT_FIX`)

JLC's part library does not always share KiCad's zero orientation. `ROT_FIX`
in `fab.py` has one entry per footprint name in the CPL (today R0603, C0603,
C0805, D_SMA, SOIC-16, SOT-223): a correction in degrees and a `verified`
field. `verified` stays empty until Bastian has looked at JLC's placement
preview, which JLC shows on a quote upload, free and without an order; it then
carries the date. **No machine can prove a rotation**, and the table says so.

A per-footprint offset cannot fix a bottom-side sign error, because that error
depends on each part's own rotation. So `BOTTOM_SIGN` (+1 or −1, with its own
`verified` field) is separate: the CPL rotation of a bottom part is
`(BOTTOM_SIGN × KiCad rotation + ROT_FIX[package]) mod 360` (amended with the
plan, 2026-10-02). `--release` refuses while any entry or `BOTTOM_SIGN` is
unverified.

#### 4.4.4 BOM

`fab.py` copies P3's `hardware/reva/bom-jlc.csv` into the package unchanged.
There is no second BOM writer; §5.2 checks the copy against the board.

#### 4.4.5 Assembly sheet

The general part of `hardware/coupon/scripts/assembly_plan.py` — board
reading, label search, overlap check, SVG writing — moves to
`hardware/gen/assembly.py`; the coupon script keeps its own part classes and
calls it. Gate for the move: the coupon's `proof/coupon-assembly.svg` and
`coupon-overview.svg` come out byte-identical.

Rev A gets two sheets, `reva-assembly-front.svg` and
`reva-assembly-back.svg`:

- **Front:** the 112 panel parts, each labelled with its panel id (the
  footprint Value), LED polarity marked.
- **Back:** the hand-soldered parts (U_SM's sockets, J_PWR with pin 1, J_SD's
  pins), every SMD reference including those in `NO_ROOM`, and the DNP parts
  marked as such.

#### 4.4.6 Renders and release

- Front and back renders of the committed board (`kicad-cli pcb render`),
  looked at every iteration (rule 2).
- `order_ready` prints the open items: every entry of the known lists of
  `place_check.py` and `route_check.py` that has no sign-off (see the
  amendment below), every `NO_ROOM` entry (informational
  only — the assembly sheet covers them), and every unverified `ROT_FIX` entry.
- `--release` runs every check, refuses on any open known-list entry or
  unverified rotation, and otherwise writes the package to
  `hardware/reva/fab/`: `gerbers/`, `reva-gerbers.zip`, `bom-jlc.csv`,
  `cpl-jlc.csv`, both assembly sheets, both renders.
- *Amended 2026-10-08 (Task 7c, Bastian): release sign-off.* A known-list
  entry that is deliberate design, not an open defect, carries a sign-off
  next to its list: `SIGNED_OFF[(check, key)] = {"by", "date", "why"}` in
  `place_check.py` / `route_check.py`, in the style of `BOTTOM_SIGN`'s
  `verified`.
  - "Open" means a known entry without a complete sign-off. Only those block
    `--release` and count in `order_ready`.
  - A sign-off whose entry is no longer listed also blocks, so it cannot go
    stale.
  - The checks' own gating is unchanged: a signed-off entry is still a known
    item there.
  - First use: the two audio jack zones IN_L/SHIFTBTN_L and MODBTN_L/OUT_R
    (spec 2026-10-07 §5.3: the lamp sits between key and jack).

### 4.5 Line endings

`.gitattributes` gets `text eol=lf` for `hardware/reva/bom-*.csv`,
`hardware/reva/review.md` and `hardware/reva/kicad/*-lib-table`, with a comment
on why (§3). It is committed with the schematic regeneration (§4.2), which
rewrites those files anyway.

## 5. Checks

Same pattern as P4-1 and P4-2: every gated step has a sabotage `<step>` and a
sabotage `<step>_missing` that proves the step is red when it measures
nothing, plus a WHY phrase that must appear on the step's own lines.
`check_sabotage_coverage` enforces completeness. Net names, footprint names and
references come from the modules that build the board, never copied as
literals; thresholds live in the check file.

### 5.1 Board content (`route_check.py`, `reva_route_guard`)

| Step | Green means | Sabotage | `_missing` |
|---|---|---|---|
| `silk_height` | every visible silk text ≥ 1.0 mm | one reference at 0.8 mm | no text examined |
| `silk_front` | no visible reference on a front footprint | one front reference shown | no front footprint examined |
| `silk_clear` | DRC: no `silk_over_copper`, no `silk_overlap` with a text among its items, except entries in a new `KNOWN_PANEL["silk"]` (expected empty once front references are hidden; the plan measures it) | one back reference moved onto its own pad | the DRC report's silk entries not read |
| `no_room` | hidden back references == `NO_ROOM` (judged by `check_kit.judge`) | one entry added; one hidden reference shown | no back footprint examined |
| `paths` | every footprint's path == KiCad netlist's `sheetpath tstamps` + `tstamps` for that reference; every netlist component except those without a footprint has one | R1's and R2's paths swapped | no component read from the netlist |
| `parity` | `--schematic-parity` reports 0 items, **and** a board copy with one field changed (R1's LCSC) reports ≥ 1 (positive control, every run; a path change would not show, §3) | one footprint field changed | the schematic hidden from the run |

The `paths` check exists because parity matches by reference (§3); its
independent reader is KiCad's own netlist export, not our uuid5 function. The
parity positive control exists because a parity run that does not find the
schematic could report zero.

### 5.2 Export (`fab_check.py`, `reva_fab_guard`)

| Step | Green means | Sabotage |
|---|---|---|
| `gerber_set` | exactly the eleven layer files and two drill files, none empty; Edge.Cuts extent == the board outline (300.8 × 110 mm) at its absolute position (`place`'s X0, −Y1, X1, −Y0, Gerber y up); `reva-gerbers.zip` holds exactly the directory's files, sorted, byte for byte | one layer dropped from the export list; the zip rewritten without `reva-PTH.drl` |
| `drill` | hole count in the PTH and NPTH files == PTH pads + vias and NPTH holes counted by pcbnew | one hole line deleted |
| `cpl` | designators: CPL == BOM == board SMD footprints without DNP; every position within 0.01 mm of pcbnew's footprint position (Y sign per §3); every layer `Bottom`; every point inside the Gerber's Edge.Cuts extent; every rotation == `(sign × Rot + ROT_FIX[Package]) mod 360` recomputed from kicad-cli's raw position file with the run's tables (sign = `BOTTOM_SIGN` on the bottom side), within 0.001° | one row dropped; one row shifted 0.1 mm; one row's Y sign flipped; one row's rotation +90°; a DNP flag cleared |
| `rot_table` | every footprint name in the CPL has a `ROT_FIX` entry; `BOTTOM_SIGN` is ±1 | one entry removed; `BOTTOM_SIGN` set to 0 |
| `bom_lcsc` | every BOM line's LCSC == the `LCSC` field of each of its footprints | one footprint field changed |
| `assembly` | every part labelled on its sheet, no label overlaps another | one label forced onto another |

Each has a `_missing` sabotage (empty output directory, empty CPL, empty table,
empty BOM, no part read). Determinism is the guard's (§6), not a step.

## 6. Guard and outputs

- `reva_route_guard` (existing) keeps rebuilding the committed board byte for
  byte, now including links and silkscreen, and proves §5.1 red.
- `reva_fab_guard` (new, `test_fab.py`, re-execs under KiCad's Python like
  `test_route.py`): two exports byte-identical after normalisation; every
  §5.2 step green on the committed board; every sabotage red with its WHY
  phrase on its own lines.
- The coupon: a regenerated `coupon.kicad_sch` and regenerated assembly SVGs
  byte-identical to the committed ones prove the label switch and the
  `assembly.py` move. No existing guard compares those bytes
  (`hw_gen_coupon_guard` compares nets); the plan decides whether the
  comparison becomes a permanent guard or a one-time proof in a task.
  Probed during execution, 2026-10-02: the committed `coupon.kicad_sch` is
  not byte-equal to the generator's output even before this change (it
  differs in 74LS165 vs 74HC165, the U_SM position, the generator string and
  the root uuid). The label switch is proven instead by generator output
  before == after, byte for byte.
- Committed now: the board, the regenerated schematic and BOMs, renders under
  `docs/hardware/fab/`. Committed at release: `hardware/reva/fab/`.

## 7. Risks, and what the plan does about them

- **Global labels are wider.** `sch_writer.label_width` charges a global label
  its arrow (`LABEL_PAD`), so sheets grow. The plan's first task probes whether
  all ten sheets still fit A3. If not, the fallback of decision 5 applies, and
  the spec is amended before work continues.
- **ERC on global labels.** KiCad warns "Global label only appears once in the
  schematic". Every local-label net today has at least two pins on its sheet,
  so this should not fire; `reva_check_guard` decides.
- **Annotation warning.** The netlist export warns of annotation errors that
  ERC does not show. Probed 2026-10-02 (§3): the cause is the five references
  without a trailing digit (`C_LDO_T`, `J_PWR`, `J_SD`, `U_REG`, `U_SM`); the
  export exits 0 and every component carries `tstamps`, so the `paths` step
  can rely on it. The warning stays until those references are renamed, which
  this spec does not do.
- **Named unconnected pads change the board.** Pads that had no net now have
  one. The router skips them (§3), but DRC and the routed checks may see new
  items; one re-route measures it.
- **A back reference may have no room in the dense field west of the
  module.** That is decision 3's list, not a failure.
- **JLC assembly of a 300.8 × 110 mm board on the bottom side** is assumed,
  not confirmed, and the price is not quoted. Both are checked on the first
  quote upload, together with the rotation preview; anything above about 50 €
  is Bastian's call (rule 9).

## 8. Not in P4-3

- The panel pass and its re-run (place → route → fab): after the grip test.
- The aluminium plate: P5.
- JLC stock check: at the schematic freeze (13 Nov) and before the order
  (rule 5).
- Silkscreen artwork beyond references, outlines and polarity marks.

## 9. Timeline

- **Now, before 6 Nov:** the whole pipeline; the committed board gains links
  and silkscreen; ctest green with `reva_fab_guard`.
- **After the panel pass:** `place.py` → `route.py --write` → `fab.py`;
  a quote upload to verify `ROT_FIX` and the assembly assumptions;
  `fab.py --release`; order on 18 Dec.

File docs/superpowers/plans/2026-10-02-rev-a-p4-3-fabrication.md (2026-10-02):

# Rev A P4-3 Fabrication Data Implementation Plan

> **For agentic workers:** REQUIRED SUB-SKILL: Use superpowers:subagent-driven-development (recommended) or superpowers:executing-plans to implement this plan task-by-task. Steps use checkbox (`- [ ]`) syntax for tracking.

**Goal:** Give the committed Rev A board schematic links with real KiCad parity and a readable silkscreen, and build the export stage that turns it into JLC's order package (Gerbers, drill, CPL, BOM, assembly sheets), every step gated by checks that can each go red.

**Architecture:** The schematic writer gains an all-global-labels switch so KiCad names nets as the board does. Placement links every footprint to its symbol (path, full footprint ID, fields, DNP) and names unconnected pads. A new pure pass `hardware/reva/silk.py` runs last in `route.build()`. `route_check.py` gains `paths`, `parity` and four silk steps. A new stage `hardware/reva/fab.py` with `fab_check.py` and the guard `reva_fab_guard` exports the package to `hardware/reva/out/fab/`, and to `hardware/reva/fab/` only on `--release` with empty known lists and verified rotations. The coupon's assembly-sheet code moves to `hardware/gen/assembly.py` and draws Rev A's two sheets.

**Tech Stack:** Python 3.11 under KiCad 10.0.5 (`pcbnew`), `kicad-cli` (netlist, DRC with schematic parity, Gerber/drill/position export, render), plain-script guards wired into ctest.

**Spec:** `docs/superpowers/specs/2026-10-02-rev-a-p4-3-fabrication-design.md`

## Global Constraints

- Work happens in the worktree `C:\Users\bernd\Documents\AI\FireFlow\.claude\worktrees\reva-p4-3-fab` on branch `reva-p4-3-fab`. Another agent works in the main checkout at the same time: never write there, never `git stash` (the stack is shared), never merge or push.
- Units mm, y down; board coordinates equal panel coordinates. Outline x 2.0–302.8, y 9.25–119.25 (`place.X0, Y0, X1, Y1`).
- Silkscreen (master plan rule 3): every visible silk text ≥ **1.0 mm** high, stroke **0.15 mm**; no text over a pad (mask opening) or over other silk. Front references hidden; front outlines and polarity marks stay. Back references placed by search; a reference with no free spot is hidden and listed in `silk.NO_ROOM`.
- Parity: `kicad-cli pcb drc --schematic-parity` reports **0** items on the committed board. Footprint paths are `/<sheet uuid>/<symbol uuid>` (no root), checked against KiCad's own netlist export, because parity matches by reference (spec §3).
- Gerbers: exactly F.Cu, In1.Cu, In2.Cu, B.Cu, F.Mask, B.Mask, F.Silkscreen, B.Silkscreen, F.Paste, B.Paste, Edge.Cuts. Drill with `--excellon-separate-th`. Every date field replaced by `FIXED_DATE = "2000-01-01T00:00:00+00:00"` (Gerber/drill ISO form) or `"2000-01-01 00:00:00"` (the `G04 Created by` line). Zip with fixed member timestamps, sorted members.
- CPL: from `kicad-cli pcb export pos --format csv --units mm --side both --smd-only --exclude-dnp`; columns `Designator,Mid X,Mid Y,Layer,Rotation`; Layer `Bottom`; rotation `(BOTTOM_SIGN * rot + ROT_FIX[package]) % 360`. `ROT_FIX` entries and `BOTTOM_SIGN` each carry a `verified` date that stays `None` until Bastian has looked at JLC's placement preview.
- BOM: P3's `hardware/reva/bom-jlc.csv`, copied unchanged. No second BOM writer.
- `fab.py --release` refuses while any `KNOWN_PANEL` list (place_check, route_check) is non-empty or any rotation entry is unverified. The refusal is not a ctest gate.
- Checks: every gated step has a sabotage `<step>` and `<step>_missing`, and each sabotage has a phrase (WHY) only its failure prints, on that step's own lines. A step that examined nothing is red. Thresholds live in the check file. Net names, footprint names and references are imported from the module that builds them, never copied as literals. Overlap of pure silk graphics is counted, never gated.
- The coupon: `hardware/coupon/coupon.kicad_sch`, `proof/coupon-assembly.svg` and `proof/coupon-overview.svg` stay byte-identical.
- Findings are not the implementer's to paper over. STOP and report verbatim when: a Rev A sheet does not fit A3 with global labels; parity leaves an item that is not one of the spec's two naming forms; `NO_ROOM` would exceed 25 references; the CPL does not have 78 rows; drill hole counts disagree with pcbnew; a `KNOWN_PANEL` list would need a new entry.
- Never commit `hardware/reva/bom-hand.csv`, `bom-jlc.csv`, `review.md`, `kicad/fp-lib-table` or `kicad/sym-lib-table` (Bastian's rule; their content does not change in this plan — if it does, STOP). Never commit anything under `hardware/reva/out/`.
- Tooling: KIPY = `/c/Users/bernd/AppData/Local/Programs/KiCad/10.0/bin/python.exe`; system `python` has no pcbnew. KICAD_CLI = `/c/Users/bernd/AppData/Local/Programs/KiCad/10.0/bin/kicad-cli.exe`. Never prefix a shell command with `cd`; no shell writes to repo files (Edit/Write only — no `sed -i`, `>`, `>>`, `tee`); no write (`rm`, `mv`, `git add`, `git commit`) behind `&&` or `;`. Long compounds go into a scratchpad script.
- ctest (after committing, from the worktree): `source env.sh` then `cmake -S . -B build -DCMAKE_BUILD_TYPE=Release` then `ctest --test-dir build -R "hw_gen|reva|coupon" --output-on-failure`. **The controller re-runs the suite at every task boundary; on this project implementers have reported green suites that were red. Paste the real summary line.**
- Before sabotaging a file by hand for a RED proof, copy it to the scratchpad and restore from there — never `git checkout <file>` (it discards uncommitted implementation). Python files edited by a script come back LF; use Edit.
- pcbnew traps: `board.Remove` corrupts the next save (use `board.Delete`); a flipped footprint's pads report F.Cu from `GetLayerName()` (use `IsOnLayer`); `kipcb.new_board()` seeds the UUIDs and must be the first pcbnew object; `SaveBoard` writes a `.kicad_pro` beside the board; delete `__pycache__` before a size-neutral RED proof.
- Everything written into the repo is English. Commit trailer: `Co-Authored-By: HAL 9000 <293417720+bea-ton-k@users.noreply.github.com>`.

## Review Focus

1. **JLC's bottom-side rotation convention.** A per-footprint offset cannot fix a sign error that depends on the part's own rotation, so `BOTTOM_SIGN` is separate from `ROT_FIX` and verified on its own. Pinned in Task 6: `rot_table` red when `BOTTOM_SIGN` is not ±1, and the guard proves `--release` refuses an unverified `BOTTOM_SIGN`.
2. **The panel pass re-run.** After the hole list changes, stale `NO_ROOM` or `KNOWN_PANEL` entries must turn red rather than ride along, and `--release` must accept once the lists are empty. Pinned in Task 8: the guard runs `release_blockers()` against emptied lists and verified rotations and expects none.
3. **CPL and Gerbers on one origin.** JLC overlays the CPL on the Gerbers; a sign or origin slip puts every part off the board. Pinned in Task 6: `cpl` requires every CPL point inside the Edge.Cuts extent read from the exported Gerber, proven red by the `cpl_outside` sabotage.
4. **DNP and test points leaking into the order.** DNP parts and the 15 test points have footprints but must not be placed by JLC. Pinned in Task 6: `cpl` compares against the board's `smd` footprints minus DNP minus `exclude_from_pos_files`, and a sabotage clears C_LDO_T's DNP flag.
5. **Dates in another time zone or locale.** The normaliser must catch every date form, not just today's. Pinned in Task 6: `normalise()` unit cases with `+02:00`, `Z`, `-05:00` and both `G04` forms.

## File map

| File | Status | Responsibility |
|---|---|---|
| `.gitattributes` | modify | `text eol=lf` for the five generated text files (spec §4.5) |
| `hardware/gen/project.py` | modify | `Project(..., global_labels=False)` |
| `hardware/gen/sch_writer.py` | modify | `kind()` honours `global_labels`; `symbol_uuid()`, `sheet_uuid()`, `symbol_path()` pure helpers |
| `hardware/gen/test_sch_writer.py` | modify | the switch and the helpers |
| `hardware/reva/build.py` | modify | sets `global_labels=True` |
| `hardware/reva/kicad/*.kicad_sch` | regenerate | global labels |
| `hardware/gen/kipcb.py` | modify | `link_part()`, `set_pad_net()`; `new_board` docstring |
| `hardware/reva/place.py` | modify | `link_footprints()` at the end of `build()` |
| `hardware/reva/route.py` | modify | calls `silk.apply()` after the fill |
| `hardware/reva/silk.py` | create | the silkscreen pass and `NO_ROOM` |
| `hardware/reva/route_check.py` | modify | steps `paths`, `parity`, `silk_height`, `silk_front`, `silk_clear`, `no_room` |
| `hardware/reva/test_route.py` | modify | sections for the new steps (coverage is automatic) |
| `hardware/reva/kicad/reva.kicad_pcb` | regenerate | linked, silkscreened board |
| `hardware/gen/assembly.py` | create | board reader, label search, overlap check, SVG (from the coupon) |
| `hardware/coupon/scripts/assembly_plan.py` | modify | imports the moved code |
| `hardware/gen/test_assembly.py` | create | coupon SVGs byte-identical; `hw_gen_assembly_guard` |
| `hardware/reva/fab.py` | create | the export stage |
| `hardware/reva/fab_check.py` | create | the export checks and sabotages |
| `hardware/reva/test_fab.py` | create | `reva_fab_guard` |
| `CMakeLists.txt` | modify | `hw_gen_assembly_guard`, `reva_fab_guard` |
| `docs/hardware/fab/` | create | renders and assembly sheets of the first green run |
| `docs/superpowers/specs/2026-10-02-rev-a-p4-3-fabrication-design.md` | modify | dated amendments from the probes |
| `docs/roadmap.md` | modify | entry |

---

### Task 1: Worktree setup, baseline, and the annotation warning

No production code. Sets up the worktree's build, records the baseline, and finds the cause of the netlist export's annotation warning (spec §7) before Task 3 relies on that export.

**Files:**
- Create (untracked, gitignored): `env.sh` in the worktree root, a copy of the main checkout's `env.sh`
- Create (scratchpad, not committed): `probe_annotation.py`
- Modify: `docs/superpowers/specs/2026-10-02-rev-a-p4-3-fabrication-design.md` (§3, a bullet "Probed during execution, 2026-MM-DD")

**Interfaces:**
- Consumes: nothing.
- Produces: a working `source env.sh`; the baseline ctest line; the annotation warning's cause, and whether `kicad-cli sch export netlist` exits 0 while printing it.

- [ ] **Step 1: Copy env.sh into the worktree**

Read `C:\Users\bernd\Documents\AI\FireFlow\env.sh` with the Read tool and write the identical content to `C:\Users\bernd\Documents\AI\FireFlow\.claude\worktrees\reva-p4-3-fab\env.sh` with the Write tool. It is gitignored (`.gitignore:10`). Then:

Run: `git status --short`
Expected: empty (env.sh does not show).

- [ ] **Step 2: Baseline ctest**

Run: `source env.sh` then `cmake -S . -B build -DCMAKE_BUILD_TYPE=Release` then `cmake --build build` then `ctest --test-dir build -R "hw_gen|reva|coupon" --output-on-failure`
Expected: every listed test passes. Write the summary line (`100% tests passed, 0 tests failed out of N`) into your report. If anything is red on the untouched branch, STOP and report it.

- [ ] **Step 3: Write the annotation probe**

`<scratchpad>/probe_annotation.py` (system Python):

```python
"""Why does kicad-cli's netlist export warn of annotation errors? Throwaway."""
import os, re, shutil, subprocess, tempfile
WT = r"C:\Users\bernd\Documents\AI\FireFlow\.claude\worktrees\reva-p4-3-fab"
CLI = r"C:\Users\bernd\AppData\Local\Programs\KiCad\10.0\bin\kicad-cli.exe"
K = os.path.join(WT, "hardware", "reva", "kicad")

def export(kdir):
    out = os.path.join(kdir, "probe.net")
    r = subprocess.run([CLI, "sch", "export", "netlist", "--format", "kicadsexpr",
                        "-o", out, os.path.join(kdir, "reva.kicad_sch")],
                       capture_output=True, text=True, encoding="utf-8", errors="replace")
    return r.returncode, (r.stdout + r.stderr).strip(), out

tmp = tempfile.mkdtemp()
kd = os.path.join(tmp, "hardware", "reva", "kicad")
shutil.copytree(K, kd)
shutil.copytree(os.path.join(WT, "hardware", "lib"), os.path.join(tmp, "hardware", "lib"))
rc, msg, out = export(kd)
print("as committed: rc", rc, "|", msg)
refs = set()
for f in os.listdir(kd):
    if f.endswith(".kicad_sch"):
        refs |= set(re.findall(r'\(reference "([^"#][^"]*)"\)', open(os.path.join(kd, f), encoding="utf-8").read()))
bare = sorted(r for r in refs if not r[-1].isdigit())
print("references without a trailing digit:", bare)
# hypothesis: KiCad treats a reference without a trailing number as unannotated
for f in os.listdir(kd):
    if f.endswith(".kicad_sch"):
        p = os.path.join(kd, f)
        t = open(p, encoding="utf-8").read()
        for r in bare:
            t = t.replace('"%s"' % r, '"%s9"' % r)
        open(p, "w", encoding="utf-8", newline="\n").write(t)
rc2, msg2, _ = export(kd)
print("with a digit appended: rc", rc2, "|", msg2)
net = open(out, encoding="utf-8").read()
for r in bare:
    m = re.search(r'\(comp \(ref "%s"\).*?\(tstamps "([^"]+)"\)\s*\(units' % re.escape(r), net, re.S)
    print("netlist", r, "tstamps", m.group(1) if m else "MISSING")
shutil.rmtree(tmp, ignore_errors=True)
```

- [ ] **Step 4: Run it**

Run: `python <scratchpad>/probe_annotation.py`
Expected: three answers. (a) Does the export exit 0 while warning? (b) Does appending a digit silence the warning (hypothesis)? (c) Does every bare-named part still carry `tstamps` in the netlist? If the warning has another cause, find it (try `kicad-cli sch erc --format json` on the same copy and look for annotation classes) and report it. If any part is missing from the netlist or lacks `tstamps`, STOP: Task 3's `paths` step cannot rely on the export.

- [ ] **Step 5: Amend the spec and commit**

Add a bullet to spec §3 under "Schematic parity": "Probed during execution, 2026-MM-DD: the annotation warning comes from …; the export exits …; every component carries `tstamps`." Replace the matching §7 risk bullet's guess with the finding.

```bash
git add docs/superpowers/specs/2026-10-02-rev-a-p4-3-fabrication-design.md
git commit -m "docs(spec): P4-3 the netlist export's annotation warning, probed" -m "Co-Authored-By: HAL 9000 <293417720+bea-ton-k@users.noreply.github.com>"
```

---

### Task 2: Global labels for Rev A, and line endings

**Files:**
- Modify: `hardware/gen/project.py` (constructor), `hardware/gen/sch_writer.py` (`kind()` in `write_project`, new helpers after `class Uuids`), `hardware/gen/test_sch_writer.py`, `hardware/reva/build.py` (`project()`), `.gitattributes`
- Regenerate: `hardware/reva/kicad/*.kicad_sch` (and whatever else `build.py` writes — see the never-commit list)

**Interfaces:**
- Consumes: nothing new.
- Produces:
  - `Project(..., global_labels=False)`; attribute `project.global_labels: bool`.
  - `sch_writer.sheet_uuid(project_name: str, sheet_name: str) -> str`
  - `sch_writer.symbol_uuid(project_name: str, ref: str, unit: int = 1) -> str`
  - `sch_writer.symbol_path(project_name: str, sheet_name: str, ref: str, unit: int = 1) -> str` — `"/<sheet uuid>/<symbol uuid>"`, the footprint path KiCad uses (root sheet omitted).
  All three compute the same uuid5 as `Uuids.__call__` without touching its used-key set.

- [ ] **Step 1: Write the failing tests**

Append to `hardware/gen/test_sch_writer.py`, before `main()`:

```python
def check_global_labels(failures):
    """Spec P4-3 §4.2: with global_labels every net label is global, and
    KiCad's netlist names the demo's sheet-local net without a sheet prefix."""
    proj = demo.project()
    local_nets = [n for n in {net for p in proj.parts() for net in p.nets.values()}
                  if n not in proj.power
                  and len({s.name for s in proj.sheets for p in s.parts if n in p.nets.values()}) == 1]
    if not local_nets:
        failures.append("global_labels: the demo fixture has no sheet-local net to test")
        return
    proj.global_labels = True
    with tempfile.TemporaryDirectory() as d:
        W.write_project(proj, d)
        text = "".join(open(os.path.join(d, f), encoding="utf-8").read()
                       for f in sorted(os.listdir(d)) if f.endswith(".kicad_sch"))
        if "(label " in text:
            failures.append("global_labels: a local label was written")
        # Raw names on purpose: check.export_netlist() normalizes the
        # "/sheet/" prefix away, which is exactly what this test must see.
        sch = os.path.join(d, proj.name + ".kicad_sch")
        net = os.path.join(d, proj.name + ".net")
        rc, _out = check.run([ksexp.KICAD_CLI, "sch", "export", "netlist", "-o", net, sch],
                             "kicad-cli sch export netlist", quiet=True)
        names = check.parse_exported_netlist(net) if rc == 0 else {}
        for n in local_nets:
            if n not in names:
                failures.append("global_labels: KiCad does not name %r without a prefix (has %s)"
                                % (n, sorted(k for k in names if n in k)))

def check_path_helpers(failures):
    """symbol_path() equals the instance path the writer puts in the file,
    minus the root sheet -- the form KiCad's netlist gives a footprint."""
    proj = demo.project()
    with tempfile.TemporaryDirectory() as d:
        W.write_project(proj, d)
        seen = 0
        for s in proj.sheets:
            text = open(os.path.join(d, s.name + ".kicad_sch"), encoding="utf-8").read()
            for p in s.parts:
                if p.ref.startswith("#"):
                    continue
                # The file carries the instance path "/<root>/<sheet>" and the
                # symbol's own (uuid ...); the footprint path joins sheet and symbol.
                want = W.symbol_path(proj.name, s.name, p.ref)
                sheet, sym = W.sheet_uuid(proj.name, s.name), W.symbol_uuid(proj.name, p.ref)
                inst = '(path "/%s/%s" (reference "%s")' % (W.Uuids(proj.name)("root"), sheet, p.ref)
                if want != "/%s/%s" % (sheet, sym) or inst not in text or '(uuid "%s")' % sym not in text:
                    failures.append("symbol_path(%s) %s does not match %s.kicad_sch" % (p.ref, want, s.name))
                seen += 1
        if not seen:
            failures.append("path helpers: no symbol examined")
```

Add `check_global_labels(failures)` and `check_path_helpers(failures)` to `main()` next to the existing calls. `check.run(args, what, quiet)` returns `(rc, output)` and `check.parse_exported_netlist(path)` returns `{net name: {(ref, pin)}}` (`hardware/gen/check.py:28`, `:39`). The demo fixture (`hardware/gen/fixtures/demo.py`) has a sheet-local net by its docstring; the test fails loudly if it does not.

**RED proof for `check_global_labels`:** it must fail before Step 3 for the right reason — the output must contain "a local label was written" (the demo writes its local net as a local label today), not an AttributeError from the attribute assignment.

- [ ] **Step 2: Run them to verify they fail**

Run: `python hardware/gen/test_sch_writer.py`
Expected: FAIL — `AttributeError: module 'gen.sch_writer' has no attribute 'symbol_path'`, or the global-label failure lines.

- [ ] **Step 3: Implement**

`hardware/gen/project.py`, constructor signature and body:

```python
    def __init__(self, name, title, sheets, power=None, domain_rails=None,
                 holes=None, waivers=None, paper="A3", flat=False, comments=(),
                 lib_dirs=None, ground="GND", global_labels=False):
        ...
        self.ground = ground
        # P4-3: every net label global, so KiCad names each net exactly as
        # the board does (no "/sheet/" prefix) and schematic parity holds.
        self.global_labels = global_labels
```

`hardware/gen/sch_writer.py`, in `write_project`'s `kind()`:

```python
    def kind(net):
        if net in project.power:
            return "power"
        if project.flat or project.global_labels or len(net_sheets[net]) > 1:
            return "global"
        return "local"
```

and after `class Uuids`:

```python
def _uuid5(project_name, *key):
    return str(uuid.uuid5(Uuids.NS, "/".join(str(x) for x in (project_name,) + key)))

def sheet_uuid(project_name, sheet_name):
    """The UUID write_project gives sheet `sheet_name` (key "sheet", name)."""
    return _uuid5(project_name, "sheet", sheet_name)

def symbol_uuid(project_name, ref, unit=1):
    """The UUID write_project gives unit `unit` of symbol `ref` (key "sym")."""
    return _uuid5(project_name, "sym", ref, unit)

def symbol_path(project_name, sheet_name, ref, unit=1):
    """A footprint's schematic link: "/<sheet uuid>/<symbol uuid>". KiCad's
    netlist omits the root sheet (probed 2026-10-02, P4-3 spec §3)."""
    return "/%s/%s" % (sheet_uuid(project_name, sheet_name), symbol_uuid(project_name, ref, unit))
```

`Uuids.__call__` keeps its own body (it also honours `Uuids.random` for the check tool's sabotage); the helpers must produce the same strings, which `check_path_helpers` proves.

`hardware/reva/build.py`, in `project()`: add `global_labels=True,` to the `Project(...)` call.

- [ ] **Step 4: Run the writer test**

Run: `python hardware/gen/test_sch_writer.py`
Expected: PASS (no failure lines, exit 0).

- [ ] **Step 5: Regenerate Rev A and measure the A3 fit**

Run: `python hardware/reva/build.py`
Then: `python hardware/gen/check.py --project hardware/reva/build.py --full --out <scratchpad>/reva-check`
Expected: the check tool's full level is green, including the paper-fit rule (`W.fits`). If any sheet no longer fits A3, STOP: report the sheet and its height. The spec's fallback (decision 5) needs Bastian before it is built.

Run: `git status --short`
Expected: only `hardware/reva/kicad/*.kicad_sch` (and `.gitattributes` after Step 6). If `bom-*.csv`, `review.md` or a lib table show up, run `git diff --ignore-cr-at-eol --stat -- <file>`; a real content change is a STOP.

- [ ] **Step 6: Line endings**

Append to `.gitattributes`:

```
# 2026-10-02 (P4-3 spec §4.5): build.py writes these five files with LF. With
# core.autocrlf=true a checkout writes CRLF, the index keeps the CRLF size, and
# every build.py run then leaves them "modified" with an empty diff. eol=lf
# makes the checkout write LF too. Proven: fresh checkout + build.py, status empty.
hardware/reva/bom-*.csv          text eol=lf
hardware/reva/review.md          text eol=lf
hardware/reva/kicad/*-lib-table  text eol=lf
```

Then prove it: delete the five files with the shell (`rm hardware/reva/bom-hand.csv hardware/reva/bom-jlc.csv hardware/reva/review.md hardware/reva/kicad/fp-lib-table hardware/reva/kicad/sym-lib-table`, one call), restore them (`git checkout -- <the five paths>`, one call — safe here: they carry no uncommitted work), run `python hardware/reva/build.py`, then `git status --short`.
Expected: only `.gitattributes` and the regenerated `.kicad_sch` files.

- [ ] **Step 7: Prove the coupon untouched**

`generate_schematic.main(out_dir)` takes the output directory (`hardware/coupon/scripts/generate_schematic.py:41`). Put this in `<scratchpad>/coupon_sch.py` and run it with system `python`:

```python
import filecmp, os, sys, tempfile
WT = r"C:\Users\bernd\Documents\AI\FireFlow\.claude\worktrees\reva-p4-3-fab"
sys.path[:0] = [os.path.join(WT, "hardware"), os.path.join(WT, "hardware", "coupon", "scripts")]
import generate_schematic as g
d = tempfile.mkdtemp()
g.main(d)
same = filecmp.cmp(os.path.join(d, "coupon.kicad_sch"),
                   os.path.join(WT, "hardware", "coupon", "coupon.kicad_sch"), shallow=False)
print("coupon schematic byte-identical:", same)
sys.exit(0 if same else 1)
```

Expected: `True` (the coupon is flat, so `kind()` already returned "global" for it).

- [ ] **Step 8: Guards, then commit**

Run: `python hardware/reva/test_build.py` and `python hardware/gen/test_coupon_netlist.py`
Expected: both exit 0.

```bash
git add .gitattributes hardware/gen/project.py hardware/gen/sch_writer.py hardware/gen/test_sch_writer.py hardware/reva/build.py hardware/reva/kicad/*.kicad_sch
git commit -m "hw(reva): P4-3 Rev A writes every net label global; generated text files are LF" -m "Co-Authored-By: HAL 9000 <293417720+bea-ton-k@users.noreply.github.com>"
```

Then ctest as in Global Constraints; the controller re-runs it.

---

### Task 3: Schematic links on the board, gated by `paths` and `parity`

**Files:**
- Modify: `hardware/gen/kipcb.py` (new `link_part`, `set_pad_net`; `new_board` docstring), `hardware/reva/place.py` (new `link_footprints`, called last in `build()`), `hardware/reva/route_check.py` (steps `paths`, `parity`, their sabotages), `hardware/reva/test_route.py` (only if a new step needs an `EXTRA`/`PROBES` entry — coverage of the sabotage tables is automatic)
- Regenerate: `hardware/reva/kicad/reva.kicad_pcb` (via `route.py --write`), `docs/hardware/routing/*.png`

**Interfaces:**
- Consumes: `sch_writer.symbol_path(project_name, sheet_name, ref, unit=1)` (Task 2); `build.project()` with `global_labels=True`.
- Produces:
  - `kipcb.link_part(fp, part, path: str, sheet_name: str, sheet_file: str) -> None`
  - `kipcb.set_pad_net(board, fp, number: str, net_name: str) -> int` (pads changed)
  - `place.link_footprints(s, proj) -> list[str]` (the unconnected net names it created, sorted)
  - `route_check` steps `"paths"` and `"parity"`; module constants `KICAD_DIR`, `LIB_DIR`, `SCH`; `PATHS_EMPTY`, `PARITY_EMPTY` phrases.
  - On the board: every footprint has `GetPath().AsString() == "/<sheet uuid>/<symbol uuid>"`, `GetFPIDAsString() == part.footprint`, fields `Datasheet`, `Description`, plus `LCSC`/`Source`/`PanelId` where the part has them, `IsDNP() == part.dnp`.

- [ ] **Step 1: Write the failing steps in `route_check.py`**

Add near the other module constants (after `PLANE_NETS`):

```python
HERE_RC = os.path.dirname(os.path.abspath(__file__))
KICAD_DIR = os.path.join(HERE_RC, "kicad")
LIB_DIR = os.path.normpath(os.path.join(HERE_RC, "..", "lib"))
SCH = os.path.join(KICAD_DIR, "reva.kicad_sch")
PATHS_EMPTY = "paths measured nothing: no component read from KiCad's netlist"
PARITY_EMPTY = "parity positive control found nothing"
PARITY_CONTROL = ("R1", "LCSC", "C0")   # this field, changed on a copy, must show up
_NETLIST_PATHS = None                    # {ref: path}, per process: the schematic does not change in a run
_PARITY_CACHE = {}                       # link key -> parity items
```

Add the steps (before `STEPS`):

```python
def _netlist_paths():
    """{ref: footprint path} from KiCad's own netlist export of the committed
    schematic: the component's sheetpath tstamps joined with its tstamps
    (P4-3 spec §3). Components without a footprint (J_SM1..4) are left out.
    This is the independent reader: it never calls sch_writer's uuid5."""
    global _NETLIST_PATHS
    if _NETLIST_PATHS is None:
        tmp = tempfile.mkdtemp(prefix="reva_net_")
        try:
            net = os.path.join(tmp, "reva.net")
            subprocess.run([ksexp.KICAD_CLI, "sch", "export", "netlist", "--format", "kicadsexpr",
                            "-o", net, SCH], capture_output=True)
            out = {}
            if os.path.exists(net):
                root = ksexp.parse_file(net)
                for c in ksexp.children(ksexp.child(root, "components"), "comp"):
                    if not ksexp.children(c, "footprint"):
                        continue
                    sheet = str(ksexp.child(ksexp.child(c, "sheetpath"), "tstamps")[1])
                    out[str(ksexp.child(c, "ref")[1])] = sheet + str(ksexp.child(c, "tstamps")[1])
            _NETLIST_PATHS = out
        finally:
            shutil.rmtree(tmp, ignore_errors=True)
    return dict(_NETLIST_PATHS)

def check_paths(s, pcb_path, prefix):
    want = {} if getattr(s, "paths_missing", False) else _netlist_paths()
    if not want:
        return False, PATHS_EMPTY, []
    have = {fp.GetReference(): fp.GetPath().AsString() for fp in s.board.GetFootprints()}
    bad = []
    for ref in sorted(set(want) | set(have)):
        if ref not in have:
            bad.append("%s: in KiCad's netlist, no footprint on the board" % ref)
        elif ref not in want:
            bad.append("%s: footprint with no component in KiCad's netlist" % ref)
        elif have[ref] != want[ref]:
            bad.append("%s: path %s, KiCad's netlist says %s" % (ref, have[ref] or "(none)", want[ref]))
    return not bad, "%d footprints against KiCad's netlist, %d wrong" % (len(have), len(bad)), bad

def _link_key(board):
    """What schematic parity depends on: footprint ids, fields, DNP, pad nets."""
    key = []
    for fp in sorted(board.GetFootprints(), key=lambda f: f.GetReference()):
        fields = tuple(sorted((f.GetName(), f.GetText()) for f in fp.GetFields()))
        nets = tuple(sorted((str(p.GetNumber()), p.GetNetname()) for p in fp.Pads()))
        key.append((fp.GetReference(), fp.GetFPIDAsString(), fp.IsDNP(), fields, nets))
    return tuple(key)

def _parity_items(pcb_path, with_schematic=True):
    """kicad-cli's schematic-parity items for a copy of `pcb_path` laid out as
    the committed project (schematic, project file, lib tables, hardware/lib),
    or None when kicad-cli wrote no report."""
    tmp = tempfile.mkdtemp(prefix="reva_parity_")
    try:
        kd = os.path.join(tmp, "hardware", "reva", "kicad")
        os.makedirs(kd)
        for name in sorted(os.listdir(KICAD_DIR)):
            sch = name.endswith(".kicad_sch")
            if (sch and with_schematic) or name.endswith(".kicad_pro") or name.endswith("-lib-table"):
                shutil.copyfile(os.path.join(KICAD_DIR, name), os.path.join(kd, name))
        shutil.copytree(LIB_DIR, os.path.join(tmp, "hardware", "lib"))
        board = os.path.join(kd, "reva.kicad_pcb")
        shutil.copyfile(pcb_path, board)
        out = os.path.join(tmp, "parity.json")
        subprocess.run([ksexp.KICAD_CLI, "pcb", "drc", "--schematic-parity", "--format", "json",
                        "-o", out, board], capture_output=True)
        if not os.path.exists(out):
            return None
        with open(out, encoding="utf-8") as fh:
            return json.load(fh).get("schematic_parity", [])
    finally:
        shutil.rmtree(tmp, ignore_errors=True)

_PARITY_REF_RE = re.compile(r"(?:Footprint|of) (\S+)")

def _parity_lines(items):
    out = []
    for it in items:
        refs = sorted({m for x in it.get("items", []) for m in _PARITY_REF_RE.findall(x.get("description", ""))})
        out.append("parity item %s on %s" % (it.get("type"), "/".join(refs) or "?"))
    return sorted(out)

def check_parity(s, pcb_path, prefix):
    with_sch = not getattr(s, "parity_missing", False)
    key = (with_sch, _link_key(s.board))
    if key not in _PARITY_CACHE:
        items = _parity_items(pcb_path, with_sch)
        # positive control: the same board with one field changed must show it
        ctrl_pcb = prefix + "-parity-control.kicad_pcb"
        b = pcbnew.LoadBoard(pcb_path)
        ref, field, val = PARITY_CONTROL
        b.FindFootprintByReference(ref).SetField(field, val)
        pcbnew.SaveBoard(ctrl_pcb, b)
        control = _parity_items(ctrl_pcb, with_sch)
        _PARITY_CACHE[key] = (items, control)
    items, control = _PARITY_CACHE[key]
    if items is None or not control:
        return False, "%s (control %s)" % (PARITY_EMPTY, "no report" if control is None else "0 items"), []
    lines = _parity_lines(items)
    return not lines, "schematic parity: %d items (positive control %d)" % (len(lines), len(control)), lines
```

Add the imports the module lacks (`json`, `shutil`, `subprocess`, `tempfile`, `from gen import ksexp`) — check the existing import block first. Add `("paths", check_paths), ("parity", check_parity),` to `STEPS` before `("report", report)`.

Sabotages (next to the others) and their table entries:

```python
def _sab_paths(s):
    """R1's and R2's schematic links swapped: parity cannot see it (it matches
    by reference, spec §3), only the netlist comparison can."""
    a, b = s.board.FindFootprintByReference("R1"), s.board.FindFootprintByReference("R2")
    pa, pb = a.GetPath(), b.GetPath()
    a.SetPath(pb)
    b.SetPath(pa)

def _sab_paths_missing(s):
    s.paths_missing = True

def _sab_parity(s):
    """C2's LCSC field changed: one footprint_symbol_field_mismatch."""
    s.board.FindFootprintByReference("C2").SetField("LCSC", "C1")

def _sab_parity_missing(s):
    """The schematic left out of the parity copy: the positive control finds nothing."""
    s.parity_missing = True
```

```python
SABOTAGES.update({"paths": _sab_paths, "paths_missing": _sab_paths_missing,
                  "parity": _sab_parity, "parity_missing": _sab_parity_missing})
TURNS_RED.update({"paths": "paths", "paths_missing": "paths",
                  "parity": "parity", "parity_missing": "parity"})
WHY.update({"paths": "KiCad's netlist says", "paths_missing": PATHS_EMPTY,
            "parity": "parity item footprint_symbol_field_mismatch on C2",
            "parity_missing": PARITY_EMPTY})
```

Write these into the existing dict literals rather than with `.update()` if that reads better next to the others; the content is what matters.

- [ ] **Step 2: Run the route checks on today's committed board to see them RED**

Put in `<scratchpad>/rc_on_committed.py` (KIPY) — it runs the checks on a copy of the committed board without routing:

```python
import os, shutil, sys
WT = r"C:\Users\bernd\Documents\AI\FireFlow\.claude\worktrees\reva-p4-3-fab"
sys.path[:0] = [os.path.join(WT, "hardware"), os.path.join(WT, "hardware", "reva")]
import route as R, route_check as RC, check_kit as CK
out = os.path.join(WT, "hardware", "reva", "out", "probe")
os.makedirs(out, exist_ok=True)
pcb = os.path.join(out, "committed.kicad_pcb")
shutil.copyfile(R.COMMITTED, pcb)
s = R.Routed().reload(pcb)
s.known = {k: set(v) for k, v in RC.KNOWN_PANEL.items()}
s.skip_render = True
names = sys.argv[1:] or ["paths", "parity"]
CK.run_steps([st for st in RC.STEPS if st[0] in names], s, pcb, os.path.join(out, "committed"))
```

Run: `"$KIPY" <scratchpad>/rc_on_committed.py paths parity`
Expected: `RED ... paths` with 213 "path (none)" lines and `RED ... parity` with ~199 items. If either is green, the check is vacuous — fix it before going on. Note the wall time of one parity call (two DRC runs).

- [ ] **Step 3: Implement the links**

`hardware/gen/kipcb.py`, after `add_part`:

```python
def link_part(fp, part, path, sheet_name, sheet_file):
    """The footprint's schematic link (P4-3 spec §4.2): KiCad path, the full
    footprint ID with its library nickname, the symbol's fields, DNP and the
    sheet it sits on -- everything schematic parity compares."""
    lib, _, name = part.footprint.partition(":")
    fp.SetFPID(pcbnew.LIB_ID(lib, name))
    fp.SetPath(pcbnew.KIID_PATH(path))
    fp.SetSheetname(sheet_name)
    fp.SetSheetfile(sheet_file)
    # the same properties sch_writer gives the symbol, in the same order
    fp.SetField("Datasheet", "")
    fp.SetField("Description", part.note)
    for key, val in (("LCSC", part.lcsc), ("Source", part.source), ("PanelId", part.panel_id)):
        if val:
            fp.SetField(key, val)
    fp.SetDNP(bool(part.dnp))

def set_pad_net(board, fp, number, net_name):
    """Put every pad of `fp` numbered `number` on `net_name`; returns the count."""
    n = 0
    for pad in fp.Pads():
        if str(pad.GetNumber()) == str(number):
            pad.SetNet(_net(board, net_name))
            n += 1
    return n
```

Rewrite the `new_board` docstring paragraph that says `SetPath`/`GetPath` are never called: paths are now set by `link_part` from the schematic's deterministic uuid5s, and the seeded KIID generator is unrelated to them (a second board in one process would still collide on KIIDs, which is the remaining reason for the warning).

`hardware/reva/place.py`:

```python
from gen import sch_writer as W   # with the other gen imports

def unconnected_net(part, number):
    """KiCad's name for the net of a pin the schematic leaves unconnected
    (forms probed 2026-10-02: unconnected-(J_PWR-Pin_7-Pad7),
    unconnected-(U_IN1-~{Q7}-Pad7)); schematic parity checks it."""
    return "unconnected-(%s-%s-Pad%s)" % (part.ref, part.sym.pin(number)["name"], number)

def link_footprints(s, proj):
    """P4-3 spec §4.2: every footprint linked to its symbol, every unconnected
    pin on KiCad's unconnected-(...) net. Returns the net names created."""
    sheet_of = proj.sheet_of()
    made = []
    for p in proj.parts():
        fp = s.board.FindFootprintByReference(p.ref)
        if fp is None:
            continue
        sheet = sheet_of[p.ref]
        kipcb.link_part(fp, p, W.symbol_path(proj.name, sheet, p.ref), sheet, sheet + ".kicad_sch")
        for number in p.unconnected():
            name = unconnected_net(p, number)
            if kipcb.set_pad_net(s.board, fp, number, name):
                made.append(name)
    return sorted(made)
```

and at the end of `build()`, after `place_smd(s, proj)`: `s.unconnected = link_footprints(s, proj)` (add `self.unconnected = []` to `Placed.__init__`).

- [ ] **Step 4: Probe the placed board's parity before routing**

Run: `"$KIPY" hardware/reva/place.py`
Expected: GREEN as before (place_check does not look at net names it does not know; if a step goes red over the new nets, report which and why before changing the check).

Then run the parity part of Step 2's script against `hardware/reva/out/reva-placed.kicad_pcb` (copy the script, swap the path). Expected: 0 parity items and a positive control ≥ 1; `paths` green. If `unconnected-` items remain, compare the names KiCad expects (item text) with `unconnected_net()`: pins carrying a no-connect flag (`p.nc`) are the likely difference. Fix the rule so KiCad agrees and say what you changed. Any other residue is a STOP (spec §2.5).

- [ ] **Step 5: Re-route and commit the board**

Run: `"$KIPY" hardware/reva/route.py --write`
Expected: GREEN in every step including `paths` and `parity`; "copied to hardware/reva/kicad/reva.kicad_pcb". Report the router line (nets, vias, length, seconds) against P4-2's (580 vias, 11803.5 mm): the 22 single-pad nets are skipped by the router (`route.py:271`), so routing should be unchanged; a change is reported, not hidden.

- [ ] **Step 6: The guard, including the RED proofs**

Run: `python hardware/reva/test_route.py`
Expected: "all routing checks passed"; the four new sabotages are each red on their own step with their own phrase. Note the wall time and compare it to the 3600 s ctest TIMEOUT; if it exceeds 2400 s, report it (the parity cache keys on the link state, so only the parity sabotages should pay for new DRC runs).

- [ ] **Step 7: Commit**

```bash
git add hardware/gen/kipcb.py hardware/reva/place.py hardware/reva/route_check.py hardware/reva/test_route.py hardware/reva/kicad/reva.kicad_pcb docs/hardware/routing
git commit -m "hw(reva): P4-3 footprints carry their schematic links; paths and parity checks" -m "Co-Authored-By: HAL 9000 <293417720+bea-ton-k@users.noreply.github.com>"
```

ctest; the controller re-runs it.

---

### Task 4: The silkscreen pass, gated by four silk steps

**Files:**
- Create: `hardware/reva/silk.py`
- Modify: `hardware/reva/route.py` (`Routed.__init__`, `build()`), `hardware/reva/route_check.py` (steps `silk_height`, `silk_front`, `silk_clear`, `no_room`; `KNOWN_PANEL["silk"]`; sabotages), `hardware/reva/test_route.py` (only if `check_known_names`' name rule must learn the `"silk"` key — it is empty, so it should not)
- Regenerate: `hardware/reva/kicad/reva.kicad_pcb`, `docs/hardware/routing/*.png`

**Interfaces:**
- Consumes: the linked board of Task 3; `kipcb.courtyard_boxes(board) -> {ref: (l, t, r, b)}` in mm.
- Produces:
  - `silk.apply(board) -> silk.Report` with `report.placed: dict[str, tuple]` (ref → (side, gap_mm, angle)), `report.hidden: list[str]` (sorted; a hidden U_SM user text appears as `"U_SM:text"`).
  - `silk.NO_ROOM: dict[str, str]` (ref → measured reason).
  - `Routed.silk` (the report) set by `route.build()`.
  - `route_check` steps `"silk_height"`, `"silk_front"`, `"silk_clear"`, `"no_room"`; phrases `SILK_EMPTY`, `FRONT_EMPTY`, `CLEAR_EMPTY`, `ROOM_EMPTY`; constant `SILK_MIN_MM = 1.0`.

- [ ] **Step 1: Write the failing steps in `route_check.py`**

```python
SILK_MIN_MM = 1.0       # master plan working rule 3 (the check's own copy, not silk.py's)
SILK_TEXT_CLASSES = ("silk_over_copper", "silk_overlap")
# kicad-cli 10.0.5 item lines for silk text (probed 2026-10-02 on the routed board):
#   @(281.9400 mm, 73.6100 mm): Reference field of RV64
#   @(...): Footprint text of U_SM (INSTALL ON
_TEXT_ITEM_RE = re.compile(r"^\s*@\([^)]*\): (?:Reference field|Value field|Footprint text|Text) ", re.M)
SILK_EMPTY = "silk_height measured nothing: no visible silkscreen text"
FRONT_EMPTY = "silk_front measured nothing: no front footprint"
CLEAR_EMPTY = "silk_clear measured nothing: no silk text judged"
ROOM_EMPTY = "no_room measured nothing: no back footprint"

def _silk_texts(board):
    """(ref, kind, height mm, side) of every visible text on F/B.Silkscreen."""
    out = []
    for fp in board.GetFootprints():
        items = [("reference", fp.Reference()), ("value", fp.Value())]
        items += [("text", it) for it in fp.GraphicalItems() if isinstance(it, pcbnew.PCB_TEXT)]
        for kind, t in items:
            if t.IsVisible() and t.GetLayer() in (pcbnew.F_SilkS, pcbnew.B_SilkS):
                out.append((fp.GetReference(), kind, pcbnew.ToMM(t.GetTextSize().y),
                            "B" if t.GetLayer() == pcbnew.B_SilkS else "F"))
    return out

def check_silk_height(s, pcb_path, prefix):
    texts = [] if getattr(s, "silk_height_missing", False) else _silk_texts(s.board)
    if not texts:
        return False, SILK_EMPTY, []
    low = sorted(t for t in texts if t[2] < SILK_MIN_MM - 1e-6)
    return (not low, "%d silk texts, %d below %.1f mm" % (len(texts), len(low), SILK_MIN_MM),
            ["silk text below %.1f mm: %s %s %.2f mm" % (SILK_MIN_MM, r, k, h) for r, k, h, _ in low])

def check_silk_front(s, pcb_path, prefix):
    front = [] if getattr(s, "silk_front_missing", False) else \
        [fp for fp in s.board.GetFootprints() if not fp.IsFlipped()]
    if not front:
        return False, FRONT_EMPTY, []
    shown = sorted(fp.GetReference() for fp in front if fp.Reference().IsVisible())
    return (not shown, "%d front footprints, %d with a visible reference" % (len(front), len(shown)),
            ["visible front reference: %s" % r for r in shown])

def check_silk_clear(s, pcb_path, prefix):
    texts = [] if getattr(s, "silk_clear_missing", False) else _silk_texts(s.board)
    if not texts:
        return False, CLEAR_EMPTY, []
    txt, err = _drc(s, pcb_path, prefix)
    if err:
        return False, err, []
    found = {}
    for block in re.split(r"(?=^\[)", txt, flags=re.M):
        m = re.match(r"^\[([a-z0-9_]+)\]", block)
        if not m or m.group(1) not in SILK_TEXT_CLASSES or not _TEXT_ITEM_RE.search(block):
            continue
        refs = sorted(set(CK._REF_RE.findall(block)))
        found["%s %s" % (m.group(1), "/".join(refs))] = "silk text over a pad or other silk"
    ok, details, n_known = _judge(s, "silk", found)
    return ok, "%d silk texts judged, %d text entries (%d known)" % (len(texts), len(found), n_known), details
```

Add `"silk": set()` to `KNOWN_PANEL` with the comment `# silk text entries the panel pass must clear; expected none (P4-3 spec §5.1)`. Check `CK._REF_RE` matches "Reference field of RV64" and "Footprint text of U_SM (INSTALL ON" (it ends at line end with an optional layer; the U_SM line has a trailing "(INSTALL ON" — if `_REF_RE` misses it, use a local regex `r"(?:field|text|pad \S+ \[[^\]]*\]|PTH pad \S* ?\[[^\]]*\]|Pad \S+ \[[^\]]*\]) of ([A-Za-z_]+[A-Za-z_0-9]*)"` and say so).

```python
def check_no_room(s, pcb_path, prefix):
    import silk as SK
    back = [] if getattr(s, "no_room_missing", False) else \
        [fp for fp in s.board.GetFootprints() if fp.IsFlipped()]
    if not back:
        return False, ROOM_EMPTY, []
    found = {fp.GetReference(): "reference hidden, no free spot"
             for fp in back if not fp.Reference().IsVisible()}
    for fp in back:
        for it in fp.GraphicalItems():
            if isinstance(it, pcbnew.PCB_TEXT) and it.GetLayer() == pcbnew.B_SilkS and not it.IsVisible():
                found[fp.GetReference() + ":text"] = "footprint text hidden, no free spot"
    known = set(SK.NO_ROOM) | set(getattr(s, "extra_no_room", ()))
    ok, details, n_known = CK.judge(known, found)
    details = [d.replace("[NEW]", "[NEW] hidden back reference not in NO_ROOM") for d in details]
    return ok, "%d back footprints, %d hidden (%d listed)" % (len(back), len(found), n_known), details
```

Add the four steps to `STEPS` before `("report", report)`, after `parity`.

Sabotages:

```python
def _sab_silk_height(s):
    """R1's reference at 0.8 mm."""
    s.board.FindFootprintByReference("R1").Reference().SetTextSize(
        pcbnew.VECTOR2I(pcbnew.FromMM(0.8), pcbnew.FromMM(0.8)))

def _sab_silk_height_missing(s):
    s.silk_height_missing = True

def _sab_silk_front(s):
    s.board.FindFootprintByReference("RV1").Reference().SetVisible(True)

def _sab_silk_front_missing(s):
    s.silk_front_missing = True

def _sab_silk_clear(s):
    """R1's reference moved onto its own pad 1 and shown."""
    fp = s.board.FindFootprintByReference("R1")
    pad = [p for p in fp.Pads() if str(p.GetNumber()) == "1"][0]
    fp.Reference().SetVisible(True)
    fp.Reference().SetPosition(pad.GetPosition())

def _sab_silk_clear_missing(s):
    s.silk_clear_missing = True

def _sab_no_room(s):
    """R1's reference hidden although it had room: a NEW hidden reference."""
    s.board.FindFootprintByReference("R1").Reference().SetVisible(False)

def _sab_no_room_stale(s):
    """R2 listed although its reference is shown: a stale entry."""
    s.extra_no_room = ("R2",)

def _sab_no_room_missing(s):
    s.no_room_missing = True
```

Table entries: `TURNS_RED` maps each to its step (`no_room_stale` → `no_room`); `WHY`: `silk_height` → `"silk text below 1.0 mm: R1"`, `silk_height_missing` → `SILK_EMPTY`, `silk_front` → `"visible front reference: RV1"`, `silk_front_missing` → `FRONT_EMPTY`, `silk_clear` → `"silk_over_copper R1"`, `silk_clear_missing` → `CLEAR_EMPTY`, `no_room` → `"hidden back reference not in NO_ROOM"`, `no_room_stale` → `"listed as known but no longer fails"`, `no_room_missing` → `ROOM_EMPTY`. If R1 turns out to be in `NO_ROOM` after Step 4, pick another listed-free resistor for the three R1 sabotages and say which.

Create `hardware/reva/silk.py` with only `NO_ROOM = {}` for now (so `check_no_room` imports).

- [ ] **Step 2: See the steps RED on today's board**

Run: `"$KIPY" <scratchpad>/rc_on_committed.py silk_height silk_front silk_clear no_room`
Expected: `silk_height` green (all references are 1.0 mm today, spec §3); `silk_front` RED with 112 lines; `silk_clear` RED with many `silk_over_copper …`/`silk_overlap …` NEW entries; `no_room` green (nothing hidden yet). A green `silk_front` or `silk_clear` here means the check is vacuous.

- [ ] **Step 3: Write `silk.py`**

```python
#!/usr/bin/env python3
"""Rev A silkscreen pass (P4-3 spec §4.3). A pure function on a board:

    silk.apply(board) -> Report

route.build() calls it last, after the zone fill. Standalone, to iterate in
seconds on a saved board without routing:

    KIPY hardware/reva/silk.py [board.kicad_pcb]   (default out/reva-routed.kicad_pcb)

writes out/reva-silk.kicad_pcb, runs kicad-cli DRC on it and prints the silk
text entries, and renders the back to out/reva-silk-bottom.png.

Front: references hidden (the plate covers the front; the assembly sheet says
what goes where). Back: every reference 1.0 mm, placed by a search around its
courtyard; a reference with no free spot is hidden and must be in NO_ROOM.
Collision boxes are deliberately simple (KiCad's own text bounding box, pad
and silk-graphic bounding boxes grown by a gap); KiCad's DRC is the judge
(route_check silk_clear), so a miss here shows up there, never silently.
"""
import os
import re
import sys

HERE = os.path.dirname(os.path.abspath(__file__))
HW = os.path.normpath(os.path.join(HERE, ".."))
for _p in (HW, HERE):
    if _p not in sys.path:
        sys.path.insert(0, _p)

import pcbnew               # noqa: E402
from gen import kipcb      # noqa: E402

TEXT_MM = 1.0                                   # rule 3's floor, used as the size
STROKE_MM = 0.15
PAD_GAP_MM = 0.15                               # text box to a mask opening
SILK_GAP_MM = 0.15                              # text box to other silk
EDGE_GAP_MM = 0.5                               # text box to the board edge
GAPS_MM = (0.2, 0.5, 0.9, 1.4, 2.0, 2.7, 3.5)   # from the courtyard, nearest first
SLIDES_MM = (0.0, 0.8, -0.8)
SIDES = ("S", "N", "E", "W")
ANGLES = (0, 90)

# Back references (and footprint texts, "<ref>:text") with no free spot,
# measured by the first run (P4-3 Task 4); each entry says what blocked it.
NO_ROOM = {
}

class Report:
    def __init__(self):
        self.placed = {}
        self.hidden = []

def _natural(ref):
    m = re.match(r"([A-Za-z_]+?)(\d*)$", ref)
    return (m.group(1), int(m.group(2)) if m.group(2) else -1) if m else (ref, -1)

def _grow(bb, mm):
    g = pcbnew.FromMM(mm)
    return (bb.GetLeft() - g, bb.GetTop() - g, bb.GetRight() + g, bb.GetBottom() + g)

def _hits(a, boxes):
    return any(a[0] < b[2] and a[2] > b[0] and a[1] < b[3] and a[3] > b[1] for b in boxes)

def _inside(a, area):
    return a[0] >= area[0] and a[1] >= area[1] and a[2] <= area[2] and a[3] <= area[3]

def _obstacles(board):
    """Back mask openings and back silk graphics, as grown boxes (nm)."""
    out = []
    for fp in board.GetFootprints():
        for pad in fp.Pads():
            if pad.IsOnLayer(pcbnew.B_Mask):
                out.append(_grow(pad.GetBoundingBox(), PAD_GAP_MM))
        for it in fp.GraphicalItems():
            if it.GetLayer() == pcbnew.B_SilkS and not isinstance(it, pcbnew.PCB_TEXT):
                out.append(_grow(it.GetBoundingBox(), SILK_GAP_MM))
    return out

def _candidates(box_mm, w_mm, h_mm):
    """Text centres around a box (l, t, r, b), nearest ring first."""
    l, t, r, b = box_mm
    cx, cy = (l + r) / 2, (t + b) / 2
    for gap in GAPS_MM:
        for side in SIDES:
            for slide in SLIDES_MM:
                if side == "S":
                    yield side, gap, (cx + slide, b + gap + h_mm / 2)
                elif side == "N":
                    yield side, gap, (cx + slide, t - gap - h_mm / 2)
                elif side == "E":
                    yield side, gap, (r + gap + w_mm / 2, cy + slide)
                else:
                    yield side, gap, (l - gap - w_mm / 2, cy + slide)

def _search(text, box_mm, area, blocked):
    """Move `text` to the first free candidate; returns (side, gap, angle) or None."""
    for angle in ANGLES:
        text.SetTextAngleDegrees(angle)
        text.SetPosition(kipcb._pt((box_mm[0] + box_mm[2]) / 2, (box_mm[1] + box_mm[3]) / 2))
        bb = text.GetBoundingBox()
        w, h = pcbnew.ToMM(bb.GetWidth()), pcbnew.ToMM(bb.GetHeight())
        for side, gap, (x, y) in _candidates(box_mm, w, h):
            text.SetPosition(kipcb._pt(x, y))
            tb = _grow(text.GetBoundingBox(), 0.0)
            if _inside(tb, area) and not _hits(tb, blocked):
                return side, gap, angle
    return None

def apply(board):
    rep = Report()
    edge = board.GetBoardEdgesBoundingBox()
    area = _grow(edge, -EDGE_GAP_MM)
    blocked = _obstacles(board)
    size = pcbnew.VECTOR2I(pcbnew.FromMM(TEXT_MM), pcbnew.FromMM(TEXT_MM))
    court = kipcb.courtyard_boxes(board)
    fps = sorted(board.GetFootprints(), key=lambda f: _natural(f.GetReference()))
    for fp in fps:
        if not fp.IsFlipped():
            fp.Reference().SetVisible(False)
    # footprint texts on the back first (U_SM's "INSTALL ON THIS SIDE"), so the
    # references avoid them; searched around their own box, starting in place
    for fp in fps:
        for it in fp.GraphicalItems():
            if not (isinstance(it, pcbnew.PCB_TEXT) and it.GetLayer() == pcbnew.B_SilkS):
                continue
            key = fp.GetReference() + ":text"
            here = _grow(it.GetBoundingBox(), 0.0)
            if _inside(here, area) and not _hits(here, blocked):
                rep.placed[key] = ("in place", 0.0, it.GetTextAngleDegrees())
            else:
                b = it.GetBoundingBox()
                spot = _search(it, (pcbnew.ToMM(b.GetLeft()), pcbnew.ToMM(b.GetTop()),
                                    pcbnew.ToMM(b.GetRight()), pcbnew.ToMM(b.GetBottom())), area, blocked)
                if spot is None:
                    it.SetVisible(False)
                    rep.hidden.append(key)
                    continue
                rep.placed[key] = spot
            blocked.append(_grow(it.GetBoundingBox(), SILK_GAP_MM))
    for fp in fps:
        if not fp.IsFlipped():
            continue
        ref = fp.GetReference()
        t = fp.Reference()
        t.SetVisible(True)
        t.SetTextSize(size)
        t.SetTextThickness(pcbnew.FromMM(STROKE_MM))
        spot = _search(t, court[ref], area, blocked)
        if spot is None:
            t.SetVisible(False)
            rep.hidden.append(ref)
            continue
        rep.placed[ref] = spot
        blocked.append(_grow(t.GetBoundingBox(), SILK_GAP_MM))
    rep.hidden.sort(key=_natural)
    return rep

def main(argv=None):
    from gen import pcb_proof as PP
    import check_kit as CK
    argv = sys.argv[1:] if argv is None else argv
    src = argv[0] if argv else os.path.join(HERE, "out", "reva-routed.kicad_pcb")
    board = kipcb.load(src)
    rep = apply(board)
    out = os.path.join(HERE, "out", "reva-silk.kicad_pcb")
    kipcb.save(board, out)
    print("placed %d, hidden %d: %s" % (len(rep.placed), len(rep.hidden), ", ".join(rep.hidden)))
    rpt = os.path.join(HERE, "out", "reva-silk-drc.rpt")
    try:
        PP.drc(out, rpt)
    except RuntimeError as e:
        print("drc:", e)
    txt = open(rpt, encoding="utf-8", errors="replace").read() if os.path.exists(rpt) else ""
    n = 0
    for block in re.split(r"(?=^\[)", txt, flags=re.M):
        if block.startswith(("[silk_over_copper]", "[silk_overlap]")) and \
                re.search(r"\): (?:Reference field|Value field|Footprint text|Text) ", block):
            n += 1
            print("  " + " | ".join(l.strip() for l in block.splitlines()[:4]))
    print("silk text entries:", n)
    PP.render(out, os.path.join(HERE, "out", "reva-silk-bottom.png"), "bottom")
    return 0

if __name__ == "__main__":
    sys.exit(main())
```

Check before running: `kipcb._pt` exists (it is used by `add_part`); `kipcb.courtyard_boxes` returns mm tuples for every footprint, flipped ones included; `pcb_proof.drc(pcb, rpt)` raises `RuntimeError` on a missing report and `pcb_proof.render(pcb, png, side)` has that signature (`hardware/gen/pcb_proof.py:36`, `:77`). `PCB_TEXT.GetTextAngleDegrees()` and `SetTextAngleDegrees()` exist (probed 2026-10-02).

- [ ] **Step 4: Iterate standalone until KiCad's DRC shows no silk text entry**

First produce the routed board without committing: `"$KIPY" hardware/reva/route.py` (no `--write`; writes `out/reva-routed.kicad_pcb`).
Then, as often as needed: `"$KIPY" hardware/reva/silk.py`
Expected at the end: "silk text entries: 0", and a hidden list. **Look at `out/reva-silk-bottom.png`** (rule 2) and describe it in the report: are references next to their parts and readable?

If KiCad still reports text entries the placer thought free, grow the placer's gaps (`PAD_GAP_MM`, `SILK_GAP_MM`, `EDGE_GAP_MM`) in `silk.py` — never filter the check. If more than 25 references end up hidden, STOP and report with the PNG.

Fill `NO_ROOM` with the hidden list, one entry per line, the value naming what blocked it (e.g. `"R12": "every ring to 3.5 mm meets a pad or silk (dense field west of U_SM)"`). U_SM's text appears as `"U_SM:text"` only if it was hidden.

- [ ] **Step 5: Wire it into the route**

`hardware/reva/route.py`: `import silk` with the other local imports; in `Routed.__init__` add `self.silk = None`; at the end of `build()`, after `kipcb.fill_zones(s.board)`: `s.silk = silk.apply(s.board)`. In `main()`, after the router line, print `"silk: placed %d, hidden %d" % (len(s.silk.placed), len(s.silk.hidden))`.

- [ ] **Step 6: Route, check, commit the board**

Run: `"$KIPY" hardware/reva/route.py --write`
Expected: GREEN in every step, including the four silk steps; router line unchanged against Task 3 (silk does not touch copper). Look at `docs/hardware/routing/reva-routed-bottom.png` and `-top.png`.

Run: `python hardware/reva/test_route.py`
Expected: "all routing checks passed"; each of the nine new sabotages red on its own step with its own phrase. Report the wall time.

- [ ] **Step 7: Commit**

```bash
git add hardware/reva/silk.py hardware/reva/route.py hardware/reva/route_check.py hardware/reva/test_route.py hardware/reva/kicad/reva.kicad_pcb docs/hardware/routing
git commit -m "hw(reva): P4-3 readable silkscreen: front references hidden, back references placed by search" -m "Co-Authored-By: HAL 9000 <293417720+bea-ton-k@users.noreply.github.com>"
```

ctest; the controller re-runs it.

---

### Task 5: The assembly-sheet code moves to `hardware/gen/assembly.py`

A refactor with one gate: the coupon's two committed sheets come out byte-identical (line endings normalised — the working tree is CRLF, the script writes LF). Independent of Tasks 3–4.

**Files:**
- Create: `hardware/gen/assembly.py`, `hardware/gen/test_assembly.py`
- Modify: `hardware/coupon/scripts/assembly_plan.py`, `CMakeLists.txt` (new `hw_gen_assembly_guard`)

**Interfaces:**
- Consumes: `gen.ksexp`.
- Produces (`gen/assembly.py`):
  - constants `ADVANCE, ASCENDER, DESCENDER`; palette `INK, MUTED, RULE, PAPER, BOARD, ALERT`
  - `read_board(path, classify) -> (parts: list[dict], size: tuple)` — the coupon's reader with `classify(value, footprint) -> str` passed in; every part dict additionally carries `"side": "F" | "B"` (from the footprint's `(layer ...)`) and `"dnp": bool` (from `(attr ... dnp)`); a part with `dnp` gets `cls = "dnp"`.
  - `boxes_hit(box, others) -> bool`, `segment_hits(x0, y0, x1, y1, boxes) -> bool`
  - `class View(parts, ox, oy, scale, region=None, font=9.5, margin=135, big=frozenset(), style=None, bounds=None)` with `place_labels() -> list`, `check() -> list[str]`, `draw(out, grid=10, moat=True)`; `bounds=(x0, y0, x1, y1)` replaces the hard-wired `(0.0, 0.0, 100.0, 80.0)` full-view default (default `None` keeps it); `style` maps a class to `(fill, stroke)`; `big` is the set of refs that carry their name inside their outline.
  - `open_svg(out, width, height)`, `scale_bar(out, x, y, scale, mm=10)`

- [ ] **Step 1: Write the guard first**

`hardware/gen/test_assembly.py`:

```python
#!/usr/bin/env python3
"""hw_gen_assembly_guard: the assembly-sheet code lives in hardware/gen/
(P4-3 spec §4.4.5); the coupon's two committed sheets still come out
byte-identical. Line endings are normalised: the script writes LF, a Windows
checkout holds CRLF.

    python hardware/gen/test_assembly.py      # exit code is the verdict
"""
import os
import subprocess
import sys
import tempfile

HERE = os.path.dirname(os.path.abspath(__file__))
HW = os.path.normpath(os.path.join(HERE, ".."))
SCRIPT = os.path.join(HW, "coupon", "scripts", "assembly_plan.py")
PROOF = os.path.join(HW, "coupon", "proof")
SHEETS = ("coupon-assembly.svg", "coupon-overview.svg")

def lf(path):
    with open(path, "rb") as fh:
        return fh.read().replace(b"\r\n", b"\n")

def main():
    fails = []
    with tempfile.TemporaryDirectory() as d:
        rc = subprocess.call([sys.executable, SCRIPT, "--out-dir", d, "--prefix", "coupon"])
        if rc:
            fails.append("assembly_plan.py exited %d" % rc)
        for name in SHEETS:
            got = os.path.join(d, name)
            if not os.path.exists(got):
                fails.append("%s was not written" % name)
            elif lf(got) != lf(os.path.join(PROOF, name)):
                fails.append("%s differs from hardware/coupon/proof/%s" % (name, name))
    try:
        sys.path.insert(0, HW)
        from gen import assembly  # noqa: F401
    except ImportError as e:
        fails.append("gen.assembly does not import: %s" % e)
    for f in fails:
        print("FAIL", f)
    print("FAILED: %d" % len(fails) if fails else "assembly sheets unchanged")
    return 1 if fails else 0

if __name__ == "__main__":
    sys.exit(main())
```

Check `assembly_plan.py --prefix coupon` really names its outputs `coupon-assembly.svg` / `coupon-overview.svg` (read its `main()`); adjust the prefix if the default naming differs.

- [ ] **Step 2: Run it — RED for the right reason**

Run: `python hardware/gen/test_assembly.py`
Expected: exactly one failure, "gen.assembly does not import"; the two sheets already match. (If the sheets do not match on an untouched tree, STOP: the committed proof is stale, and that is not this task's to fix.)

- [ ] **Step 3: Move the code**

Create `hardware/gen/assembly.py` with the module docstring "Assembly sheets drawn from a KiCad board file -- moved from hardware/coupon/scripts/assembly_plan.py for Rev A (P4-3 spec §4.4.5)" and move, verbatim, from `assembly_plan.py`: the palette constants, `ADVANCE/ASCENDER/DESCENDER`, `read_board`, `boxes_hit`, `segment_hits`, `class View`, `open_svg`, `scale_bar`. Then make exactly these changes in the moved code:

1. `read_board(path)` → `read_board(path, classify)`; it calls the passed `classify` where it called the module's. Add `"side"` and `"dnp"` to each part dict; when `dnp` is true set `cls = "dnp"`.
2. `View.__init__` gains `big=frozenset(), style=None, bounds=None`; it stores `self.big`, `self.style`; every use of `BIG` becomes `self.big`, every `STYLE[...]` becomes `self.style[...]`; `region or (0.0, 0.0, 100.0, 80.0)` becomes `region or bounds or (0.0, 0.0, 100.0, 80.0)`, and `self.windowed` stays `region is not None`.

`assembly_plan.py` keeps `STYLE`, `CLASS_ORDER`, `CLASS_NAME`, `BIG`, `classify`, `ZONES`, `write_assembly`, `write_overview`, `write`, `main`, imports the rest (`from gen.assembly import ...`), and passes `classify` to `read_board` and `big=BIG, style=STYLE` to every `View(...)`.

- [ ] **Step 4: Run the guard — GREEN**

Run: `python hardware/gen/test_assembly.py`
Expected: "assembly sheets unchanged", exit 0.

- [ ] **Step 5: Prove it can go red**

Copy `hardware/gen/assembly.py` to the scratchpad. Change `ADVANCE = 0.602` to `ADVANCE = 0.61` with Edit, delete `hardware/gen/__pycache__`, run the guard. Expected: FAIL naming both sheets. Restore the file from the scratchpad copy (not with git), run again: green.

- [ ] **Step 6: Register and commit**

`CMakeLists.txt`, next to `hw_gen_coupon_guard`:

```cmake
add_test(NAME hw_gen_assembly_guard
         COMMAND ${Python3_EXECUTABLE}
                 ${CMAKE_CURRENT_SOURCE_DIR}/hardware/gen/test_assembly.py
         WORKING_DIRECTORY ${CMAKE_CURRENT_SOURCE_DIR})
```

```bash
git add hardware/gen/assembly.py hardware/gen/test_assembly.py hardware/coupon/scripts/assembly_plan.py CMakeLists.txt
git commit -m "hw(gen): the assembly-sheet code moves to hardware/gen for Rev A; coupon sheets unchanged" -m "Co-Authored-By: HAL 9000 <293417720+bea-ton-k@users.noreply.github.com>"
```

ctest (re-configure first so the new test registers); the controller re-runs it.

---

### Task 6: The export stage `fab.py` and its checks

**Files:**
- Create: `hardware/reva/fab.py`, `hardware/reva/fab_check.py`
- Modify: `docs/superpowers/specs/2026-10-02-rev-a-p4-3-fabrication-design.md` (§3 amendment: the measured package names, drill file names and counts, CPL row count)

**Interfaces:**
- Consumes: the committed board (`route.COMMITTED`) with links and DNP (Task 3); `hardware/reva/bom-jlc.csv`; `gen.pcb_proof.render`; `gen.ksexp.KICAD_CLI`.
- Produces (`fab.py`):
  - constants `OUT`, `RELEASE`, `DOCS`, `LAYERS` (11 names), `FIXED_DATE`, `FIXED_DATE_SP`, `ZIP_TIME`, `ROT_FIX: dict[str, dict]` (`{"deg": int, "verified": str | None}`), `BOTTOM_SIGN: dict` (`{"sign": int, "verified": str | None}`)
  - `normalise(text: str) -> str`
  - `class Fab` (state: `board_path`, `out`, `rot_fix`, `bottom_sign`, sabotage flags)
  - `prepare(board_src, out, sabotage="") -> Fab` (loads the board, applies a board-level sabotage, saves `out/board/reva.kicad_pcb`)
  - `export(s) -> None` (gerbers, drill, CPL, BOM copy, zip, renders; Task 7 adds the sheets)
  - `release_blockers(place_known=None, route_known=None, rot_fix=None, bottom_sign=None) -> list[str]`
  - `main(argv=None) -> int` with `--board`, `--out`, `--sabotage`, `--write`, `--release`, `--release-dir`
- Produces (`fab_check.py`): `STEPS`, `SABOTAGES`, `TURNS_RED`, `WHY`, `BOARD_SABOTAGES` (applied before export), `run(s) -> bool`, `sabotage(s, name)`, phrases `GERBER_EMPTY`, `DRILL_EMPTY`, `CPL_EMPTY`, `ROT_EMPTY`, `BOM_EMPTY`.

- [ ] **Step 1: Measure the export's names on today's board**

Run, writing into the scratchpad:
`"$KICAD_CLI" pcb export gerbers --layers F.Cu,In1.Cu,In2.Cu,B.Cu,F.Mask,B.Mask,F.Silkscreen,B.Silkscreen,F.Paste,B.Paste,Edge.Cuts -o <scratchpad>/g hardware/reva/kicad/reva.kicad_pcb`
`"$KICAD_CLI" pcb export drill --excellon-separate-th -o <scratchpad>/g/ hardware/reva/kicad/reva.kicad_pcb`
`"$KICAD_CLI" pcb export pos --format csv --units mm --side both --smd-only --exclude-dnp -o <scratchpad>/pos.csv hardware/reva/kicad/reva.kicad_pcb`
Then `ls <scratchpad>/g`, `head -3 <scratchpad>/pos.csv`, `cut -d, -f3 <scratchpad>/pos.csv | sort | uniq -c`, `grep -c . <scratchpad>/pos.csv`.
Expected: 11 Gerber files plus (probably) a job file; two drill files; the CPL has 78 data rows (+ header). Record the exact file names, the six package names and the row count. If the row count is not 78, STOP and report which designators differ from `bom-jlc.csv`.

- [ ] **Step 2: Write `fab_check.py` (the checks first)**

```python
#!/usr/bin/env python3
"""Checks on the Rev A order package (P4-3 spec §5.2), in P4-1/P4-2's pattern:
every gated step has a sabotage and a `_missing` one with its own phrase, and
a step that examined nothing is red. Thresholds live here, not in fab.py."""
import csv
import os
import re

import pcbnew
import check_kit as CK

POS_TOL_MM = 0.01
EDGE_TOL_MM = 0.01
BOARD_W_MM, BOARD_H_MM = 300.8, 110.0          # P4-1 spec §2.1, the outline
EXPECTED_LAYERS = ("F.Cu", "In1.Cu", "In2.Cu", "B.Cu", "F.Mask", "B.Mask", "F.Silkscreen",
                   "B.Silkscreen", "F.Paste", "B.Paste", "Edge.Cuts")
DRILL_FILES = ("reva-PTH.drl", "reva-NPTH.drl")  # Step 1 measured; correct here if they differ

GERBER_EMPTY = "gerber_set measured nothing: no file in the gerber directory"
DRILL_EMPTY = "drill measured nothing: no drill file read"
CPL_EMPTY = "cpl measured nothing: no CPL row read"
ROT_EMPTY = "rot_table measured nothing: no package examined"
BOM_EMPTY = "bom_lcsc measured nothing: no BOM line read"

_COORD_RE = re.compile(r"X(-?\d+)Y(-?\d+)D0[123]\*")
_HOLE_RE = re.compile(r"^X-?[\d.]+Y-?[\d.]+", re.M)

def _gerber_name(layer):
    return "reva-%s." % layer.replace(".", "_")

def edge_extent(gerber_dir):
    """(x0, y0, x1, y1) in mm of Edge.Cuts, read from the exported Gerber
    (format 4.6, so coordinates are in 1e-6 mm; Gerber y points up)."""
    names = [n for n in os.listdir(gerber_dir) if n.startswith(_gerber_name("Edge.Cuts"))]
    if len(names) != 1:
        return None
    pts = [(int(x) / 1e6, int(y) / 1e6) for x, y in
           _COORD_RE.findall(open(os.path.join(gerber_dir, names[0]), encoding="utf-8").read())]
    if not pts:
        return None
    xs, ys = [p[0] for p in pts], [p[1] for p in pts]
    return min(xs), min(ys), max(xs), max(ys)

def check_gerber_set(s, _a=None, _b=None):
    gdir = os.path.join(s.out, "gerbers")
    names = sorted(os.listdir(gdir)) if os.path.isdir(gdir) else []
    if not names:
        return False, GERBER_EMPTY, []
    bad = []
    for layer in EXPECTED_LAYERS:
        hits = [n for n in names if n.startswith(_gerber_name(layer))]
        if len(hits) != 1:
            bad.append("missing layer %s" % layer if not hits else "layer %s twice: %s" % (layer, hits))
        elif os.path.getsize(os.path.join(gdir, hits[0])) == 0:
            bad.append("empty layer file %s" % hits[0])
    for d in DRILL_FILES:
        if d not in names or os.path.getsize(os.path.join(gdir, d)) == 0:
            bad.append("missing or empty drill file %s" % d)
    known = {n for n in names for l in EXPECTED_LAYERS if n.startswith(_gerber_name(l))} | set(DRILL_FILES)
    bad += ["unexpected file %s" % n for n in names if n not in known]
    ext = edge_extent(gdir)
    if ext is None:
        bad.append("Edge.Cuts has no coordinates")
    else:
        w, h = ext[2] - ext[0], ext[3] - ext[1]
        if abs(w - BOARD_W_MM) > EDGE_TOL_MM or abs(h - BOARD_H_MM) > EDGE_TOL_MM:
            bad.append("Edge.Cuts extent %.3f x %.3f mm, outline is %.1f x %.1f" % (w, h, BOARD_W_MM, BOARD_H_MM))
    return not bad, "%d files, edge %s" % (len(names), "%.2f x %.2f mm" % (ext[2] - ext[0], ext[3] - ext[1]) if ext else "?"), bad

def _board_holes(board):
    pth = sum(1 for t in board.GetTracks() if t.Type() == pcbnew.PCB_VIA_T)
    npth = 0
    for fp in board.GetFootprints():
        for p in fp.Pads():
            if p.GetDrillSize().x <= 0:
                continue
            if p.GetAttribute() == pcbnew.PAD_ATTRIB_NPTH:
                npth += 1
            elif p.GetAttribute() == pcbnew.PAD_ATTRIB_PTH:
                pth += 1
    return {"reva-PTH.drl": pth, "reva-NPTH.drl": npth}

def check_drill(s, _a=None, _b=None):
    gdir = os.path.join(s.out, "gerbers")
    files = {} if getattr(s, "drill_missing", False) else \
        {d: open(os.path.join(gdir, d), encoding="utf-8").read()
         for d in DRILL_FILES if os.path.exists(os.path.join(gdir, d))}
    if not files:
        return False, DRILL_EMPTY, []
    want = _board_holes(s.board)
    bad, parts = [], []
    for d in DRILL_FILES:
        n = len(_HOLE_RE.findall(files.get(d, "")))
        parts.append("%s %d" % (d, n))
        if n != want[d]:
            bad.append("%s holes: file %d, board %d" % (d.split("-")[1].split(".")[0], n, want[d]))
    return not bad, ", ".join(parts), bad

def _read_csv(path):
    if not os.path.exists(path):
        return []
    with open(path, encoding="utf-8", newline="") as fh:
        return list(csv.DictReader(fh))

def _bom_refs(rows):
    return {r.strip() for row in rows for r in row["Designator"].split(",") if r.strip()}

def _placeable(board):
    """Board footprints JLC places: SMD, not DNP, not excluded from position files."""
    return {fp.GetReference(): fp for fp in board.GetFootprints()
            if fp.GetAttributes() & pcbnew.FP_SMD and not fp.IsDNP() and not fp.IsExcludedFromPosFiles()}

def check_cpl(s, _a=None, _b=None):
    rows = [] if getattr(s, "cpl_missing", False) else _read_csv(os.path.join(s.out, "cpl-jlc.csv"))
    if not rows:
        return False, CPL_EMPTY, []
    bom = _bom_refs(_read_csv(os.path.join(s.out, "bom-jlc.csv")))
    board = _placeable(s.board)
    cpl = {r["Designator"]: r for r in rows}
    bad = []
    for ref in sorted(set(board) | bom | set(cpl)):
        where = [n for n, src in (("the board", board), ("the BOM", bom), ("the CPL", cpl)) if ref in src]
        if len(where) != 3:
            bad.append("%s: in %s, not in %s" % (ref, " and ".join(where),
                       " and ".join(n for n in ("the board", "the BOM", "the CPL") if n not in where)))
    ext = edge_extent(os.path.join(s.out, "gerbers"))
    for ref, r in sorted(cpl.items()):
        x, y = float(r["Mid X"]), float(r["Mid Y"])
        if r["Layer"] != "Bottom":
            bad.append("%s: layer %s, every placed part is on the bottom" % (ref, r["Layer"]))
        fp = board.get(ref)
        if fp is not None:
            bx, by = pcbnew.ToMM(fp.GetPosition().x), pcbnew.ToMM(fp.GetPosition().y)
            if abs(x - bx) > POS_TOL_MM or abs(y + by) > POS_TOL_MM:   # KiCad's CPL negates y (spec §3)
                bad.append("%s: CPL position %.3f, %.3f, board %.3f, %.3f" % (ref, x, y, bx, -by))
        if ext and not (ext[0] <= x <= ext[2] and ext[1] <= y <= ext[3]):
            bad.append("%s: CPL point %.3f, %.3f outside the Edge.Cuts extent" % (ref, x, y))
    return not bad, "%d CPL rows, %d BOM designators, %d placeable on the board" % (len(cpl), len(bom), len(board)), bad

def check_rot_table(s, _a=None, _b=None):
    packages = set() if getattr(s, "rot_missing", False) else \
        {fp.GetFPID().GetLibItemName().wx_str() for fp in _placeable(s.board).values()}
    if not packages:
        return False, ROT_EMPTY, []
    bad = ["no ROT_FIX entry for %s" % p for p in sorted(packages) if p not in s.rot_fix]
    if s.bottom_sign.get("sign") not in (1, -1):
        bad.append("BOTTOM_SIGN is %r, must be 1 or -1" % s.bottom_sign.get("sign"))
    unverified = sorted(p for p in packages if p in s.rot_fix and not s.rot_fix[p]["verified"])
    line = "%d packages, %d unverified%s" % (len(packages), len(unverified),
                                             "" if s.bottom_sign.get("verified") else ", BOTTOM_SIGN unverified")
    return not bad, line, bad

def check_bom_lcsc(s, _a=None, _b=None):
    rows = [] if getattr(s, "bom_missing", False) else _read_csv(os.path.join(s.out, "bom-jlc.csv"))
    if not rows:
        return False, BOM_EMPTY, []
    bad, n = [], 0
    for row in rows:
        for ref in [r.strip() for r in row["Designator"].split(",") if r.strip()]:
            n += 1
            fp = s.board.FindFootprintByReference(ref)
            have = fp.GetFieldText("LCSC") if fp is not None and fp.HasField("LCSC") else None
            if have != row["LCSC"]:
                bad.append("%s: BOM says %s, the footprint's LCSC field %s" % (ref, row["LCSC"], have))
    return not bad, "%d BOM placements against the board's LCSC fields" % n, bad

STEPS = [("gerber_set", check_gerber_set), ("drill", check_drill), ("cpl", check_cpl),
         ("rot_table", check_rot_table), ("bom_lcsc", check_bom_lcsc)]

def run(s):
    # the step functions take (s, _a, _b) to fit check_kit's runner; there is
    # no board-file path or report prefix to hand them here
    return CK.run_steps(STEPS, s, None, None)

# -- sabotages. BOARD_SABOTAGES change the board or the tables before the
# export; the others change the exported files after it. -----------------------

def _sab_gerber_set(s):
    gdir = os.path.join(s.out, "gerbers")
    os.remove(os.path.join(gdir, [n for n in os.listdir(gdir) if n.startswith(_gerber_name("F.Paste"))][0]))

def _sab_gerber_set_missing(s):
    gdir = os.path.join(s.out, "gerbers")
    for n in os.listdir(gdir):
        os.remove(os.path.join(gdir, n))

def _sab_drill(s):
    p = os.path.join(s.out, "gerbers", "reva-PTH.drl")
    txt = open(p, encoding="utf-8", newline="").read()
    first = _HOLE_RE.search(txt)
    end = txt.index("\n", first.start()) + 1
    open(p, "w", encoding="utf-8", newline="").write(txt[:first.start()] + txt[end:])

def _sab_drill_missing(s):
    s.drill_missing = True

def _rewrite_cpl(s, fn):
    p = os.path.join(s.out, "cpl-jlc.csv")
    rows = _read_csv(p)
    rows = fn(rows)
    with open(p, "w", encoding="utf-8", newline="") as fh:
        w = csv.DictWriter(fh, fieldnames=["Designator", "Mid X", "Mid Y", "Layer", "Rotation"], lineterminator="\n")
        w.writeheader()
        w.writerows(rows)

def _sab_cpl(s):
    _rewrite_cpl(s, lambda rows: [r for r in rows if r["Designator"] != "C1"])

def _sab_cpl_shift(s):
    def shift(rows):
        for r in rows:
            if r["Designator"] == "R1":
                r["Mid X"] = "%.4f" % (float(r["Mid X"]) + 0.1)
        return rows
    _rewrite_cpl(s, shift)

def _sab_cpl_outside(s):
    """R1's Mid Y with its sign flipped: the point leaves the Gerber outline
    (Review Focus 3 -- the one-origin rule needs its own RED)."""
    def flip(rows):
        for r in rows:
            if r["Designator"] == "R1":
                r["Mid Y"] = "%.4f" % -float(r["Mid Y"])
        return rows
    _rewrite_cpl(s, flip)

def _sab_cpl_dnp(s):
    """C_LDO_T loses its DNP flag on the board: the CPL now places it."""
    s.board.FindFootprintByReference("C_LDO_T").SetDNP(False)

def _sab_cpl_missing(s):
    s.cpl_missing = True

def _sab_rot_table(s):
    s.rot_fix.pop(next(k for k in sorted(s.rot_fix) if k.startswith("SOIC")))

def _sab_rot_sign(s):
    s.bottom_sign["sign"] = 0

def _sab_rot_table_missing(s):
    s.rot_missing = True

def _sab_bom_lcsc(s):
    s.board.FindFootprintByReference("C2").SetField("LCSC", "C1")

def _sab_bom_lcsc_missing(s):
    s.bom_missing = True

SABOTAGES = {"gerber_set": _sab_gerber_set, "gerber_set_missing": _sab_gerber_set_missing,
             "drill": _sab_drill, "drill_missing": _sab_drill_missing,
             "cpl": _sab_cpl, "cpl_shift": _sab_cpl_shift, "cpl_outside": _sab_cpl_outside,
             "cpl_dnp": _sab_cpl_dnp, "cpl_missing": _sab_cpl_missing,
             "rot_table": _sab_rot_table, "rot_sign": _sab_rot_sign,
             "rot_table_missing": _sab_rot_table_missing,
             "bom_lcsc": _sab_bom_lcsc, "bom_lcsc_missing": _sab_bom_lcsc_missing}
BOARD_SABOTAGES = {"cpl_dnp", "rot_table", "rot_sign", "bom_lcsc"}
TURNS_RED = {"gerber_set": "gerber_set", "gerber_set_missing": "gerber_set",
             "drill": "drill", "drill_missing": "drill",
             "cpl": "cpl", "cpl_shift": "cpl", "cpl_outside": "cpl", "cpl_dnp": "cpl",
             "cpl_missing": "cpl",
             "rot_table": "rot_table", "rot_sign": "rot_table", "rot_table_missing": "rot_table",
             "bom_lcsc": "bom_lcsc", "bom_lcsc_missing": "bom_lcsc"}
WHY = {"gerber_set": "missing layer F.Paste", "gerber_set_missing": GERBER_EMPTY,
       "drill": "PTH holes: file", "drill_missing": DRILL_EMPTY,
       "cpl": "C1: in the board and the BOM, not in the CPL",
       "cpl_shift": "R1: CPL position",
       "cpl_outside": "outside the Edge.Cuts extent",
       "cpl_dnp": "C_LDO_T: in the board and the CPL, not in the BOM",
       "cpl_missing": CPL_EMPTY,
       "rot_table": "no ROT_FIX entry for SOIC", "rot_sign": "BOTTOM_SIGN is 0",
       "rot_table_missing": ROT_EMPTY,
       "bom_lcsc": "C2: BOM says", "bom_lcsc_missing": BOM_EMPTY}

def sabotage(s, name):
    if name not in SABOTAGES:
        raise SystemExit("unknown sabotage %r; known: %s" % (name, ", ".join(sorted(SABOTAGES))))
    SABOTAGES[name](s)
    print("SABOTAGED: %s" % name)
```

Note how `check_cpl` words a missing designator: `"C1: in the board and the BOM, not in the CPL"` — the WHY phrases above are written to match that wording exactly; keep them in step if you change one. `fp.GetFPID().GetLibItemName().wx_str()` — if the binding returns a `UTF8` object without `wx_str`, use `str(...)`; check once in KIPY.

- [ ] **Step 3: Write `fab.py`**

```python
#!/usr/bin/env python3
"""Rev A order package (P4-3 spec §4.4).

    KIPY hardware/reva/fab.py [--board PCB] [--out DIR] [--sabotage NAME]
                              [--write] [--release] [--release-dir DIR]

Reads the committed board (route.py owns it) and writes to hardware/reva/out/fab/
(gitignored): gerbers/ (11 layers + PTH/NPTH drill, dates normalised),
reva-gerbers.zip, cpl-jlc.csv, bom-jlc.csv (P3's, copied), renders. Runs
fab_check. --write copies renders and assembly sheets to docs/hardware/fab/
when green. --release writes the package to hardware/reva/fab/ and refuses
while a known list is open or a rotation is unverified (release_blockers()).
"""
import argparse
import csv
import os
import re
import shutil
import subprocess
import sys
import zipfile

HERE = os.path.dirname(os.path.abspath(__file__))
HW = os.path.normpath(os.path.join(HERE, ".."))
for _p in (HW, HERE):
    if _p not in sys.path:
        sys.path.insert(0, _p)

import pcbnew                      # noqa: E402
from gen import kipcb, ksexp       # noqa: E402
from gen import pcb_proof as PP    # noqa: E402

COMMITTED = os.path.join(HERE, "kicad", "reva.kicad_pcb")
BOM = os.path.join(HERE, "bom-jlc.csv")
OUT = os.path.join(HERE, "out", "fab")
RELEASE = os.path.join(HERE, "fab")
DOCS = os.path.normpath(os.path.join(HW, "..", "docs", "hardware", "fab"))
LAYERS = ("F.Cu", "In1.Cu", "In2.Cu", "B.Cu", "F.Mask", "B.Mask", "F.Silkscreen",
          "B.Silkscreen", "F.Paste", "B.Paste", "Edge.Cuts")
FIXED_DATE = "2000-01-01T00:00:00+00:00"
FIXED_DATE_SP = "2000-01-01 00:00:00"
ZIP_TIME = (2000, 1, 1, 0, 0, 0)
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

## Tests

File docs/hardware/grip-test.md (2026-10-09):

# Grip test — the acrylic plate (Rev A P1)

Spec: [`2026-09-29-rev-a-p1-panel-parts-design.md`](../superpowers/specs/2026-09-29-rev-a-p1-panel-parts-design.md) §5–§6.
Plate: clear 3 mm acrylic cut from `host/vcv/res/FireflowHW-cut.svg`, with
`FireflowHW-print.svg` printed at 100 % underneath (check the 100 mm bar with
a ruler before cutting the print).

The rail slots leave 1.4 mm of acrylic to the plate edge (Eurorack standard,
fine in aluminium), so screw the acrylic plate only hand-tight with nylon
washers, or rest it in the rails unscrewed.

## Orders

Both placed by Bastian on 2026-10-02, a week ahead of the spec's 9 Oct
deadline. Delivery dates go in the table when the parcels arrive.

| Supplier | What | Price | Arrived |
|---|---|---|---|
| Thonk | One set of panel parts (below) | **£179.01 paid**: £164.51 parts excl. VAT + £14.50 FedEx International Connect Plus (4–7 days). DDU: import VAT and carrier fee still due on delivery | |
| Formulor | The plate: `FireflowHW-cut.svg` as of commit `60fbc37e`, clear acrylic GS 3 mm, P2. Formulor read it as one part, 304.4 × 128.5 mm | **28.14 € paid** | |
| Formulor | The correction cut (2026-10-09): `FireflowHW-cut.svg` as of commit `815dbe3a`, clear acrylic GS **2 mm**, P2. Formulor read it as one part, 304.4 × 128.5 mm, 116 paths (outline + 115 holes) | **24.77 € paid** incl. shipping | |

Thonk cart, 207 items, read back before checkout:

| Qty | Part |
|---|---|
| 77 | Alpha 9 mm vertical, T18 shaft, B10K |
| 7 / 2 / 7 | Davies 1900H T18 — green / dark blue / orange |
| 23 / 14 / 24 | Micro Knobs T18 — green / dark blue / orange |
| 20 | Thonkiconn mono (WQP518MA) |
| 1 | Knurled nuts, bag of 50 |
| 6 | DPDT momentary low-profile push buttons |
| 1 | Low-profile button caps, taster pack (3 each red, yellow, green, blue) |
| 25 | Flat-top 3 mm LEDs, L-424SURDTK (red; Thonk's only single-colour 3 mm LED) |

Green Micro Knobs: Thonk had 23 in stock, so part A's 22 small knobs have one
spare instead of the spec's two.

**Correction cut (ordered 2026-10-09).** Checklist items 1 and 2 failed, so the
plate is cut again from the 9 mm panel pass's file: `FireflowHW-cut.svg` as of
commit `815dbe3a` (the last commit that changed it; 304.4 × 128.5 mm, 115
holes, as `gen_hw_cut.py` prints). Items 1, 2 and 4 are repeated on it; item 3
passed on the first plate.

It is **2 mm**, not 3 mm: clear GS and clear XT were both out of stock in 3 mm
on the order day. 2 mm is the thickness of Rev A's aluminium, so the knob caps
sit at the production height, which suits items 1 and 2 better than the first
plate did. The cost is strength: the 1.4 mm web at the rail slots is weaker in
2 mm acrylic, so this plate rests in the rails or is screwed only hand-tight
with nylon washers.

## Measurements (spec §6)

| Date | What | Result |
|---|---|---|
| | Alpha support lugs in the coupon's RD901F slots | |
| | Pot bushing thread and length vs 3 mm acrylic / 2 mm aluminium | |
| | Jack thread vs 3 mm (the keys have no thread or nut; they sit on the board and are not tested on the acrylic) | |
| | Jack nut outer diameter (does it cover the `CLK_L` LED hole at 6.7 mm, or the combined `SHIFTBTN_L` / `MODBTN_L` holes, 9.50 mm from their jack?) | |
| | Panel-to-board height, pot and jack seated on a board | |
| | Alpha anti-rotation tab: present? where? | |
| | Actual plate width of a bought 60 HP blank, if one is at hand (the cut assumes 304.4 mm) | |
| | Kerf: measure one pot hole and one LED hole (expected ~0.1–0.2 mm over size); the narrowest webs in the file (`FireflowHW-holes.json`, 111 holes without the mounting slots, as printed by `web()` of `test_hw_cut.py`): the two satellite lamps `CLK_L` and `RST_L` to their jacks 2.15 mm; the cluster lamps 3.70 mm (`REC_A_L` / `REC_B_L` to their key) and 4.54 mm (the other pot-cluster lamps to their own pot); `SHIFTBTN_L` / `MODBTN_L` 4.85 mm to their key; `LVL_A_L` / `LVL_B_L` 6.14 mm. Measure the two satellite webs and one cluster web on the correction cut: with the kerf above they should come out about 0.1–0.2 mm below those figures | |

## Checklist (spec §5)

| # | Check | Result | Fix (position / size / legend) |
|---|---|---|---|
| 1 | Pinch two neighbouring knobs at once, every group | **Failed** (2026-10-07): the small caps stand 5.3 mm apart edge to edge, measured from the generator (spec 2026-10-07 §2) | The 9 mm panel pass: every control on a 20.2 mm raster, no two caps closer than 9 mm (smallest gap 9.70 mm in the current generator). Spec [`2026-10-07-panel-nine-mm-raster-design.md`](../superpowers/specs/2026-10-07-panel-nine-mm-raster-design.md), plan [`2026-10-07-panel-nine-mm-raster.md`](../superpowers/plans/2026-10-07-panel-nine-mm-raster.md) |
| 2 | Turn each knob without brushing a neighbour's cap | **Failed** (2026-10-07): same cause as 1 | Same pass |
| 3 | All 18 jacks patched with real cables: what gets covered | **Passed** (2026-10-07): "patching was fine" (Bastian) | none |
| 4 | Every legend readable from playing distance, through the print | | |
| 5 | All four keys: reach, accidental presses | moved to the first Rev A board — the keys sit on the board, not in the acrylic | |

Every fix goes into `host/vcv/res/gen_hw_panel.py`, never into a generated
file. The freeze tag `panel-freeze-2026-11-06` goes on the generator commit
that passes this list. The freeze also needs every `KNOWN_PANEL` entry in
`hardware/reva/place_check.py` (P4-1 spec §5.3) and in `hardware/reva/route_check.py`
(P4-2 spec §5) to carry a `SIGNED_OFF` record, the same rule
`fab.release_blockers()` applies (P4-3 spec §4.4.6); an entry without one blocks
the freeze.

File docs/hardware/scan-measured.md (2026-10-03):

# The panel scan — measured on the coupon

> **This document is board session 1 of the panel scan, part 1.** It records
> what the test coupon said on **2026-09-28**, on one board, in one session:
> five complete run blocks of the scan-check image, with the engine playing
> and the codec running. Its question is the one
> [`scan-budget.md`](scan-budget.md) §7 left for the bring-up: in the shell's
> own ADC pattern, one mux step written per audio block and read back one
> block later, does every channel come out clean?
>
> **The answer, in one line:** **yes.** On all 24 coupon steps, in all five
> blocks, the value read one block after its address was written matches
> the value read with the address parked to within **0.61 counts**, against a
> criterion of 8. That includes the **15 steps whose predecessor sits
> 14 844–62 605 counts away**, and on every one of them the control arm,
> which reads in the same block as the write, misses by **14 843 counts or
> more**. The pots' noise sets the hysteresis at **H = 16**.
>
> **Every number here is either measured or derived, and each one says
> which.** No mechanism is asserted. The instrument is
> `shell/scan_check.cpp`, built behind `SHELL_SCAN_CHECK`, spec
> [`2026-09-28-coupon-panel-scan-design.md`](../superpowers/specs/2026-09-28-coupon-panel-scan-design.md)
> §4. The image that produced every figure below is commit **`c04ba77`**,
> and every `SHELL_SCAN_CFG` line in the capture carries that stamp.

## 1. What the instrument is

The coupon's 24 mux steps (the 4067's 16, then the 4051's 8) are read in
three arms, back to back, in one run block of 4729 audio blocks. Each arm reads
every step 64 times and keeps `n`, `sum`, `min` and `max` of the raw 16-bit
DMA word of the step's live sense pin (`hw.adc.Get()`, not libDaisy's
`AnalogControl`, spec §2).

| arm | per audio block | what it asks |
|---|---|---|
| **S**, the shipping pattern | read the step selected one block earlier, then select the next; 64 full sweeps | the value the playing image will see |
| **P**, parked | select a step, then read it in blocks 5…68 after the select | the reference: the same channel, long settled |
| **0**, lag zero | select a step and read it in the same callback | the control: a read that has had no time |

The quantity is `S − P` per step, within one run block. The criterion is
**|S − P| ≤ 8 counts**, half an LSB of 12 bit, as in every earlier round.
Arm 0 exists so that a clean S means something: gate G3 (§2) requires it to
miss P on every step where missing is possible.

The engine runs at the shell's fixed operating point (`set_tempo_bpm(96)`,
`RATE_A` 0.4, `DENSITY_A` 0.6), audio is started, and nothing the scan reads
reaches the engine. **The scan's tick runs first in the callback, before
`process()`** (spec §2). Derived from the plan's block counts: arm S's 64
reads of a step spread over 3.07 s (64 sweeps of 24 blocks), arm P's over
128 ms, and a run block lasts 9.46 s at 2 ms.

## 2. The run, and its gates

**Measured**, every complete block (`SHELL_SCAN_CFG`, `_HEALTH`, and the
gates `read_scan_check.py` computes):

| | blk 2 | blk 3 | blk 4 | blk 5 | blk 6 |
|---|---:|---:|---:|---:|---:|
| `block`, `sr` | 96, 48000 | 96, 48000 | 96, 48000 | 96, 48000 | 96, 48000 |
| `ticks` / `expected` | 4729 / 4729 | 4729 / 4729 | 4729 / 4729 | 4729 / 4729 | 4729 / 4729 |
| G1: zero, rail (arm P's ties) | 0.1, 63483.4 | 0.1, 63483.4 | 0.1, 63483.4 | 0.1, 63483.3 | 0.1, 63483.2 |
| G1, G2 | pass, pass | pass, pass | pass, pass | pass, pass | pass, pass |
| G3: qualifying steps | 15 | 15 | 15 | 15 | 15 |
| G3: smallest \|0 − P\| on them | 14844.4 | 14844.4 | 14844.4 | 14843.5 | 14843.9 |
| criterion, largest \|S − P\| | pass, 0.48 | pass, 0.42 | pass, 0.61 | pass, 0.50 | pass, 0.53 |

The same 15 steps qualify in every block: 1–8 and 10 on the 4067, 17–20,
22 and 23 on the 4051. A step qualifies when its predecessor is on the same
sense pin and their P means differ by more than 4096 counts; on these 15 the
difference is 14 844 to 62 605 counts. The reader exits 0.

**What G2's tick half checks.** `ticks` is counted by the same callback that
closes the run block (`scan_check.cpp`), so `ticks == 4729` confirms the
double buffer's bookkeeping, not the audio clock. *Reasoned* from the source:
this image has no counter that would show a missed audio block.

**What was not used.** The host opened the port mid-stream. Lines 1–75 are a
partial opening: line 1 is a `blk=0` line, line 2 a truncated `blk=0` line
carrying the `$$` overflow marker with `blk=1`'s first `CH` line fused onto
it, and lines 3–75 the rest of `blk=1`, without its `CFG` line. All 72 of
`blk=1`'s `CH` lines are in the file, the first one fused onto line 2 behind
the stray `blk=0` text. The reader discards all of it. The complete blocks start at
lines 76, 151, 226, 301 and 376; the file ends on `blk=6`'s `END` at line 450.

## 3. The result

Per step, **measured**, the range across the five blocks. `S range` is
arm S's `max − min` over its 64 reads; `0 − P(prev)` is arm 0's mean against
the preceding step's P mean. What sits on each step is `coupon_expect.cpp`'s
table and the netlist's pot assignment
(`hardware/coupon/scripts/netlist.py`).

| step | mux, ch | what | P mean | S − P | S range | 0 − P | 0 − P(prev) | G3 |
|---:|---|---|---:|---:|---:|---:|---:|:---:|
| 0 | 4067, 0 | RV1, 10 k | 33158.3 … 33159.1 | −0.4 … +0.4 | 5–9 | −22426.1 … −22401.8 | — | |
| 1 | 4067, 1 | rail tie | 63483.0 … 63483.5 | −0.4 … +0.3 | 4–6 | −30325.1 … −30324.1 | −0.7 … +0.3 | yes |
| 2 | 4067, 2 | RV2, 10 k | 31656.7 … 31657.0 | 0.0 … +0.3 | 3–5 | +31826.2 … +31826.6 | −0.2 … +0.3 | yes |
| 3 | 4067, 3 | AGND tie | 0.1 | 0.0 … +0.1 | 1–3 | +31656.1 … +31657.0 | −0.4 … +0.2 | yes |
| 4 | 4067, 4 | RV3, 20 k | 48638.6 … 48639.0 | −0.4 … +0.5 | 5–8 | −48638.9 … −48638.5 | −0.1 … 0.0 | yes |
| 5 | 4067, 5 | rail tie | 63482.8 … 63483.2 | 0.0 … +0.5 | 4–6 | −14844.4 … −14843.5 | −0.3 … +0.7 | yes |
| 6 | 4067, 6 | RV4, 20 k | 31677.2 … 31677.8 | 0.0 … +0.5 | 4–8 | +31805.5 … +31805.9 | 0.0 … +0.7 | yes |
| 7 | 4067, 7 | AGND tie | 0.1 … 0.2 | −0.1 … +0.1 | 1–3 | +31677.0 … +31678.0 | −0.3 … +0.5 | yes |
| 8 | 4067, 8 | `REF_A`, 5150 Ω | 31734.0 … 31734.6 | −0.4 … +0.6 | 3–10 | −31734.5 … −31733.9 | −0.1 … 0.0 | yes |
| 9 | 4067, 9 | `REF_B`, 650 Ω | 31736.0 … 31736.5 | −0.1 … +0.5 | 3–8 | −2.4 … −1.3 | −0.2 … +0.5 | |
| 10 | 4067, 10 | AGND tie | 0.0 … 0.2 | 0.0 … +0.2 | 1–3 | +31735.8 … +31736.4 | −0.6 … 0.0 | yes |
| 11–15 | 4067, 11–15 | AGND ties | 0.0 … 0.2 | −0.1 … +0.1 | 1–3 | −0.1 … +0.1 | −0.1 … +0.1 | |
| 16 | 4051, 0 | RV5, 10 k | 30944.4 … 30945.2 | −0.5 … +0.3 | 3–5 | −24961.0 … −24911.9 | *other pin* | |
| 17 | 4051, 1 | rail tie | 63483.2 … 63483.5 | −0.2 … +0.5 | 4–6 | −32538.9 … −32538.6 | −0.6 … +0.2 | yes |
| 18 | 4051, 2 | RV6, 10 k | 31664.3 … 31664.6 | −0.2 … +0.4 | 3–4 | +31819.0 … +31819.6 | +0.1 … +0.5 | yes |
| 19 | 4051, 3 | AGND tie | 0.0 | 0.0 | 0 | +31664.3 … +31664.7 | 0.0 … +0.4 | yes |
| 20 | 4051, 4 | RV7, 20 k | 62605.3 … 62605.7 | −0.3 … +0.3 | 4 | −62605.7 … −62605.3 | 0.0 | yes |
| 21 | 4051, 5 | rail tie | 63483.6 … 63484.0 | −0.4 … +0.2 | 4–5 | −878.5 … −877.9 | −0.2 … +0.3 | |
| 22 | 4051, 6 | `REF_C`, 5150 Ω | 31765.5 … 31766.1 | −0.4 … +0.5 | 3–5 | +31717.5 … +31718.2 | −0.3 … 0.0 | yes |
| 23 | 4051, 7 | AGND tie | 0.0 | 0.0 | 0–1 | +31765.7 … +31766.0 | −0.2 … +0.4 | yes |

**S equals P.** The largest |S − P| anywhere is **0.61 counts** (step 8,
block 4); on the seven pots it is 0.53. *Derived:* the criterion holds with a
factor of 13 to spare. Steps 0 and 16, where the sweep changes sense pin,
are as clean as the rest.

**Arm 0 reads its predecessor.** On every step whose predecessor shares its
sense pin, arm 0 lands within **±0.7 counts** of that predecessor's P mean.
That is the reading spec §4 names as expected for a read with no time after
the write; it is reported, not gated. Step 16's column is not a predecessor
comparison: step 15 is on the 4067, step 16 on the 4051. Step 0 has no
predecessor in the table.

**Every single read was clean, not only the means.** *Derived*, assuming the
hardware average weights its 32 conversions equally: a read whose average
held even one conversion of the previous address would sit about ΔP/32 away
from the rest, at least **464 counts** on the qualifying step with the
smallest ΔP (step 5, 14 844) and **1956** on the largest (step 20, 62 605).
Two legs rule that out for all 15 × 64 × 5 = 4800 reads on those steps. Arm
S's `max − min` on them is 0–10 counts in every block, which rules out a mix
of such reads and clean ones within a step. And |S − P| is at most 0.61
counts on every step, which rules out every read of a step being shifted
alike.

## 4. What it answers for `scan-budget.md` §7

`scan-budget.md` §7 names three things its arithmetic assumed and this run
was to test.

| assumption | what this run says | class |
|---|---|---|
| **The oversampling order** — one channel's 32 conversions back to back | The outcome the documented order predicts, on every step: no read one block after the write carries the previous address (§3). The interleaved alternative puts a group across a whole rotation, which `scan-budget.md` §3's arithmetic does not fit into a block | **derived** from the measured S = P; the order itself was **not timed** |
| **The slack** — the value is clean one block after the write | Holds, with the engine playing at the fixed operating point and the codec running | **measured**, at that operating point only |
| its size, ~303 µs | Nothing here measures it; the run shows it is not negative | **not claimed** |
| **F1 on real pots under a stepping mux** | All seven pots, 10 k and 20 k, on both muxes: S within 0.53 counts of P | **measured** |

**What the placement licenses about other engine loads.** The tick runs
before `process()`, so the interval between a select and its read is the time
between two callback starts. *Reasoned:* `process()`'s duration enters that
interval only if a callback overruns its block, and the 2026-08-19 bench puts
the worst-case instrument 2.9 points inside the block (`scan-budget.md` §2).
That is an argument, not a measurement: the only engine load measured here is
the fixed operating point, and this image could not show a missed block if
there were one (§2).

**Against the long rung.** `scan-budget.md` §7 asked for a comparison with
the pots' long-rung readings from `pots-measured.md`. Those came from the wait
probe's own conversions, not from libDaisy's path, and the two paths read on
different scales (`pots-measured.md` §1). The spec replaced that comparison
with arm P, in the same image. What the two can still be set against is
position, each on its own scale. *Derived:* over this image's own span, RV2,
RV4 and RV6 sit at **x = 0.4987 / 0.4990 / 0.4988**; `pots-measured.md` §3
derived **0.4987 / 0.4992 / 0.4988** from the long rung. Stated as a
correspondence between two instruments; it cannot separate a pot that moved
by a few counts from an instrument that differs by a few.

## 5. The noise, and H

**Measured**, arm S's `max − min` over 64 reads, widest across the five
blocks: RV1 **9**, RV2 5, RV3 8, RV4 8, RV5 5, RV6 4, RV7 4 counts. The
widest in any block is RV1's 9, in block 6.

**H = 16.** Spec §4's rule: the widest pot range across all complete blocks,
rounded up to a multiple of 16, and never below 16. 9 rounds to 16, and so
does the floor, so the measurement did not set the band; the floor did.
`read_scan_check.py` prints `widest S range 9 counts over 5 block(s) -> H=16`,
and `shell/scan_value.h` carries it as `kPotHysteresis = 16`.
`read_scan_check_guard` recomputes H from the committed capture and fails if
the two differ.

**Measured**, the pots' P means across the five blocks: no pot moved more
than **0.8 counts** (RV1 and RV5). *Derived:* the P readings compared, block 2
against block 6, lie about 38 s apart (4 × 9.46 s); the five blocks together
span about 47 s.

What H covers: seven pots standing still, each read over about 3 s at a
time, in one session. It does not cover a pot being turned, a longer drift,
another board, or the panel's own muxes.

## 6. What this rests on

One board: one coupon, one populated copy, one Patch Submodule, the same one
as the pot round. One session, one image, one capture, five complete run
blocks. RV2, RV4 and RV6 were still at mid travel from the pot round; the
other four pots were wherever they had been left. The engine and codec ran
at the one fixed operating point.

Before the app was flashed, the wavetable bank `shell/build/shell-qspi.bin`
was written to `0x90100000`. Whether a bank had been there before could not
be checked. *Observed in the session, not in the capture:* a DFU upload
(`dfu-util -U`) of `0x90100000`, and one of `0x90040000` right after the app
was flashed there, returned the same bytes, matching neither image, so the
upload did not show what the flash holds. Why is not claimed. The engine ran
during the measurement, which is why the bank is recorded here.

| claim | class |
|---|---|
| Every table in §2, §3 and §5 | **measured**, `SHELL_SCAN` lines, five blocks |
| Every mean, `S − P`, `0 − P`, H | **derived**, `read_scan_check.py` |
| The factor of 13, the 3.07 s and 128 ms windows, the pots' x | **derived** |
| No single read held a conversion of the previous address | **derived**, assuming an equal-weight average of 32 |
| The oversampling order is the documented one | **derived** from the outcome; not timed |
| The slack holds with the engine running | **measured**, at the fixed operating point |
| The slack holds at other engine loads | **reasoned** (§4), not measured |
| That `ticks` would show a missed audio block | **not claimed**; it would not (§2) |
| The two DFU uploads returned the same bytes, matching neither image | **observed** in the session, not in the capture; no cause claimed |
| Any mechanism | **none** |

## 7. Open, characterised, deliberately unexplained

- **Arm 0 at steps 0 and 16.** Arm 0 reads **10 732–10 757** counts on step
  0 and **5 983–6 033** on step 16. That is neither the step's own P nor its
  table predecessor's, and it moves 25–49 counts between blocks, where every
  other arm-0 cell holds within 1.03 counts. Both steps change sense pin,
  neither qualifies for G3, and arm S is clean on both. Recorded, not
  explained.
- **The rail.** G1's rail reads 63483.2–63483.4, against the 63485 that
  `kPanelSpan` carries from `settle-measured.md` §7 (2026-09-17). 1.6–1.8
  counts, inside H. Recorded.
- **The size of the slack**, and the scan at any engine load other than the
  fixed operating point (§4).
- **A missed-block counter.** The image cannot show one (§2). If a later image
  measures other engine loads, it needs one.
- **H on a turned pot.** Board session 2 (2026-09-28, image `cbd6270`)
  turned the pots with the playing image. By ear (Bastian), `FILT_A` did not
  step audibly. *Observed, unattributed:* at the end of the second
  recording, after the turning, RV2's emitted value moved by more than 60 raw
  counts over about 10 s, beyond H, while RV4 and RV6 held still; whether the
  knob was being touched was not recorded, and no cause is claimed. RV4's low
  stop, not seen in the session, was read later the same day: all three pots
  fully left gave `rv2=0 rv4=0 rv6=0` on every `SHELL_PLAY` line. The session is recorded in the M6 entry of 2026-09-28 in
  [`docs/roadmap.md`](../roadmap.md).

## 8. How to repeat it

The capture is committed as
[`captures/scan-check-capture-c04ba77.txt`](captures/scan-check-capture-c04ba77.txt)
(450 lines: a partial opening, then five complete blocks from line 76).
`read_scan_check_guard` parses it on every `ctest` run and pins G1, G2, G3
and the criterion on every block, and `kPotHysteresis` against its H. From
the repository root:

```bash
python shell/read_scan_check.py --file docs/hardware/captures/scan-check-capture-c04ba77.txt
```

It exits 0 and prints the per-block tables of §3 and the H line of §5.

On the board: build the image with the Daisy toolchain (never in a shell that
sourced `env.sh`), and before flashing, `cmp` it against the plain
`SHELL_COUPON_PROBE=1` image as spec §6 requires:

```bash
PATH="/c/Program Files/DaisyToolchain/bin:/c/Program Files/Git/usr/bin:$PATH" make -C shell -j8 images SHELL_COUPON_PROBE=1 SHELL_SCAN_CHECK=1
```

Flash over DFU as `shell/README.md` describes: the wavetable bank
(`build/shell-qspi.bin`, to `0x90100000`) on a board that may lack it, then
the app (`build/shell-sram.bin`, to `0x90040000:leave`). Record; this
session's 60 s gave five complete blocks after the one the port opened into:

```bash
python shell/read_scan_check.py COM4 capture.txt 60
```

## P6a coupon session (2026-10-03)

The coupon play image of P6a (`SHELL_PANEL_SCAN=1 SHELL_COUPON_PROBE=1`,
main 757f072b, `SRAM_EXEC` 260524 B) on the coupon, flashed over the Daisy
bootloader's DFU to `0x90040000`. It scans the coupon's wiring with Rev A's
parallel model (`kCouponPlayChain`: the 4067 and the 4051 enabled together).
The serial log was captured with a timestamping pyserial reader for 147 s:
230 `SHELL_PLAY` and 229 `SHELL_PLAY_IO` lines. Checks from spec §7:

1. **Pots: pass.** RV2, RV4 and RV6 each reached both stops: `rv4=1000`,
   `rv2=1000`, `rv6=1000`, and every pot returned to 0. Every rest stretch
   repeats exactly (`rv2=0 rv4=0 rv6=0` over dozens of lines). All of those
   stretches were at the 0 stop; no rest in mid-travel was captured.
2. **Key: pass.** `presses` steps 0 → 1 → 2 → 3 → 4 → 5 over the five
   presses (71.6–74.5 s). It then reads 6 and 7 for the two holds that
   followed. `keys=1` appears in the lines written while the key was down.
   Bastian saw LED_1 lit while SW1 was held.
3. **Held key, pots untouched: pass.** During the long hold (86.5–101.3 s,
   `keys=1 presses=7`) and in every other line with `keys=1` (33 lines in
   all), `rv2`/`rv4`/`rv6` repeat exactly. Caveat: all three pots sat at the
   0 stop during the hold, so this is the weakest position for showing LED
   switching coupling into a wiper.
4. **D8/D9: not run.** No jumpers were at hand for `TP_ADC12`→`TP_AGND` and
   `TP_ADC11`→`TP_A3V3`. Unjumpered, `adc11` and `adc12` float (for example
   6018 / 6463, then 10489 / 7219 one line later), which says nothing about
   the mapping. Deferred to P7 bring-up by decision (Bastian, 2026-10-03),
   where P2 §7 lists it: a swapped mapping would show on Rev A as SENSE_2
   and SENSE_3 trading places, fixed by two entries of `ADC_OF_PIN` in
   `shell/gen_panel_map.py`.

**Also seen:**
- The span stayed valid the whole time: `zero=0`, `rail` 63482–63485.
- `sweeps` rose from 31 to 5093 in 146.5 s of host time, 34.6 sweeps/s. That
  is a 1.81 ms step against the 2 ms the README assumes. Not part of the four
  checks, and not explained here.

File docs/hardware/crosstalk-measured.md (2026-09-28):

# Crosstalk — measured on the coupon

> **This document is the bench half.** It records what the test coupon actually
> said on **2026-09-18**, on one board, in one session, and nothing else. Its
> question is narrow: when the board's own digital side fires one controlled
> event just before the ADC's aperture, how far does a settled multiplexer
> channel move? The answer is in §4, and it names one aggressor out of nine.
>
> Its predecessor is [`settle-measured.md`](settle-measured.md), whose §5 left
> two observations open. This run closes both — §6 below — and it is the reason
> the instrument exists at all. Read `settle-measured.md` §1–§3 first if you
> want to know what the ADC path is; this probe inherits it unchanged and
> re-confirms it in §3.
>
> **Every number here is either measured or derived, and each one says which.**
> Measured means a probe printed it. Derived means it was computed from
> something printed, and the computation is given. Nothing is upgraded from the
> second class to the first, and where the run characterised something without
> explaining it — §8 — it is left characterised. **No mechanism is asserted for
> §4's finding.**
>
> The instrument is `shell/xtalk_probe.cpp`, built behind the
> `SHELL_XTALK_PROBE` switch. Its ADC primitives are the settle probe's, moved
> verbatim into `shell/probe_adc.cpp` and **proven behaviour-identical on this
> board** before anything was built on them: the refactored image reproduced a
> baseline capture with `adc_khz`, all six offset pairs and all four gates
> identical, and the two clock spans bit-identical. That proof is the reason the
> numbers below can be compared to `settle-measured.md`'s at all.

## 1. What the instrument is

The settle probe answers *how long does a channel take to arrive*. This one
holds a channel that has already arrived and asks *what moves it*.

Five **victims**, each read at a fixed address and enable for the whole of its
case, so the sample-and-hold's channel-change transient is not in the
measurement at all (`shell/xtalk_plan.cpp`, `kXtalkVictimTable`):

| victim | channel | mux | `r_src_ohm` | what it is |
|---|---|---|---:|---|
| `REF_A` | group 0, ch 8 | 74HC4067 on `ADC_9` | 5150 Ω | divider |
| `REF_B` | group 0, ch 9 | 74HC4067 on `ADC_9` | 650 Ω | divider |
| `R_SP10` | group 0, ch 10 | 74HC4067 on `ADC_9` | 150 Ω | 0 Ω link to `AGND` |
| `REF_C` | group 1, ch 6 | 74HC4051 on `ADC_10` | 5150 Ω | divider |
| `R_LO3` | group 1, ch 3 | 74HC4051 on `ADC_10` | 150 Ω | 0 Ω link to `AGND` |

**A naming discrepancy worth knowing before you read any table.** Spec §2 calls
`R_SP10` and `R_LO3` "0 Ω to `AGND`", and in the netlist they are exactly that.
`XtalkVictim::r_src_ohm` is "switch `Ron` plus what the netlist wires", so the
plan table enters them at **150 Ω** and every line the instrument prints says
`r_src=150`. This document says 150 Ω, because that is what was printed.
Neither is wrong — they measure different things — and the attribution argument
in §5 is unaffected either way: 150 Ω is 34× below the 5150 Ω dividers and 4.3×
below the 650 Ω one, so it is still the bottom rung by a wide margin. **The spec
should say so.**

A **case** is one victim, one aggressor, and two 16-bit chain words. `word_a` is
parked before the grid; `word_b` is what the event latches. Both carry the
victim's own address and enable bits, and a host test asserts that they agree
there and differ somewhere else — so a crosstalk case can never silently become
a settle-time case. 58 cases in ten rows; the four `row=6` cases need `RV4`
fitted and are **printed as skipped**, never omitted.

The grid is `settle_plan.h`'s: **65 points, 200 ns apart, 0 … 12 800 ns, 64
repeats each**. `d` is the commanded delay between the event and the
conversion's start. The criterion is `|delta(d)| <= 8` counts — half an LSB of
12 bit, expressed in the 16-bit left-aligned counts the ADC returns.

`delta(d)` is always a **difference of two curves on the same victim at the same
sampling rung**: the aggressor case's per-point mean minus its own row-2
control's. The control is a latch pulse with no bit change, so the difference
isolates the bit change from the pulse and the shift that precede it.

## 2. What the instrument cannot see, and what it refuses to say

**The verdict has no grid point to stand on, and the reader says so.** The
firmware printed `scan_settle_ns=2000000` — the audio block period, because
`MuxScan::step()` reads the sense pins for the step it wrote *last* time and
only then clocks out the next address (`shell/mux_scan.cpp:127-150`), so the
block period *is* the settle window. At the 96 samples / 48 kHz `src/hw/board.h`
sets, that is 2 ms, and the grid ends at 12.8 µs — **156× short of it**.

Spec §5's criterion applies at or past that boundary. No grid point reaches it.
A reader applying §5 literally would compute a verdict over an empty set and
print "pass"; `shell/read_xtalk.py` refuses to, and takes the **envelope** path
instead: `max |delta(d)|` over the whole grid, labelled `verdict_basis=envelope`
on every row. That is the more pessimistic of the two and it is what spec §6
licenses — the shipping ADC free-runs a circular DMA, so a pot read lands at an
arbitrary phase relative to any scan event and the envelope is the worst case it
can meet. **It is not a measurement at 2 ms and nothing here labels it as one.**

**Absolute levels are biased and may not be quoted as the node's voltage.** Each
victim is read at the rung `sample_time_index_for()` picks for its impedance,
and `settle-measured.md` §7 measured that rung reading **180–245 counts low in
steady state at 5150 Ω**. Every `delta`, every excursion and every `lit − dark`
below is a difference of two readings at the same rung, where that bias cancels.
The 150 Ω ties are unaffected — §7's ladder is flat for them.

**What was not measured.** The reverse-order sequence (aggressor before victim
park) is round two's, and it ran: [`codec-tone-measured.md`](codec-tone-measured.md) §7. No second board, no second submodule, no rework. The audio
SAI DMA is not running in this image and neither is the shipping firmware's
free-running ADC DMA, which bounds what §6's row-10 result rules out.

## 3. The gates, and the one run they refused

Four gates, printed per block, folded into `gates_ok`. G2 and G4 are the settle
probe's own, reusing its constants — two instruments judging the same board by
two different thresholds is the failure that avoids.

| gate | bound | what it refuses |
|---|---|---|
| **G2** floor | the spread of the reference channel's 64 settled conversions, `b0`, must be 0…64 counts | a run whose conversion noise is large enough that a mean of 64 repeats is no longer decisively inside the 8-count criterion |
| **G4** jitter | `lat_max − lat_min` ≤ one grid step (200 ns), latency mean not negative | a run whose aperture jitter is coarser than the grid it reads |
| **G5** address | every victim inside its `coupon_expect` band against a valid span | a victim that is not where the table says it is — at which point *nothing* in the block means anything |
| **G6** control | `max_d \|mean_control(d) − mean_silent(d)\|` ≤ 8 counts on every victim | a run whose control curve is already past the criterion, against which every aggressor difference is uninterpretable while still looking like a plausible integer |

**Measured, four complete blocks:** `gates_ok=1` in all four.
`b0` = 3, 5, 10, 2 (bound 64). `lat_max − lat_min` = 133, 133, 133, 136 ns
(bound 200). `lat_mean` = 701–704 ns; `lat_min` = **673 ns in all four, and in
every block the previous image captured** — the instrument reproduces across a
reflash. `timeouts=0` throughout. `adc_khz=6146`, matching
`settle-measured.md` §1's independently measured 6.146 MHz in a different image.
G5: all five victims in band, `zero=0`, `rail=65531`, spreads 0–1, `valid=1`.

**G2 refused one run, and that is the gate working.** In five later reads taken
for the reader's bring-up, the **first** read after the port had sat unattached
came back `b0=85` against a bound of 64, `gates_ok=0`, and the reader exited 1
with *"GATES FAILED (instrument floor) — no crosstalk verdict from this run may
be quoted"*. The four reads after it gave `b0` = 8, 6, 4, 5. **Whether that
means "discard the first block after connecting" is a hypothesis, not a finding**
— it is one occurrence and it needs a probe.

**G6 is near-marginal by construction, not by luck, and that matters.** The
firmware prints only the bit, so the reader recomputes the gate's own quantity
per victim from the row-1 and row-2 curves every block already prints:

| victim | R_src | four blocks | five later reads | bound |
|---|---:|---|---|---:|
| `REF_A` | 5150 Ω | 6, 7, 7, 7 | 7, 6, 7, 6, 7 | ≤ 8 |
| `REF_C` | 5150 Ω | 6, 7, 6, 6 | 5, 6, 5, 5, 5 | ≤ 8 |
| `REF_B` | 650 Ω | 5, 5, 6, 5 | 4, 5, 4, 4, 5 | ≤ 8 |
| `R_SP10` | 150 Ω | 1, 1, 1, 1 | 1, 1, 0, 1, 1 | ≤ 8 |
| `R_LO3` | 150 Ω | 0, 0, 0, 0 | 0, 0, 0, 0, 0 | ≤ 8 |

**One count of margin on the worst victim — and part of that margin is the
control event itself, which is exactly what G6 exists to catch.** The
whole-curve mean of `mean_silent(d) − mean_control(d)`, over all 65 points and
all eight Silent curves per victim, is **+1.68…+2.60 at 5150 Ω, +0.29…+0.88 at
650 Ω and +0.00…+0.06 at 150 Ω**. Twenty-four of twenty-four divider offsets are
positive, none negative, and the offset **orders by source impedance**. Wander
does not do that.

So roughly 2 of G6's 6–7 counts on a 5150 Ω victim are a reproducible effect of
the latch pulse and the shift preceding it, and only the remainder is the node's
wander (§6: ~8 counts over the same points). Two consequences:

- **A G6 failure at 7–9 counts would be partly correct, not a misattribution.**
- **The bound must not be widened without measuring it.** G6's null
  distribution is about twice the node's within-curve spread at 5150 Ω, because
  it is a max over 65 points of a difference of two curves each wandering ~8.
  It is designed to sit near its bound on this board.

## 4. The result: the LED word is the only aggressor that breaks the criterion

Largest per-point excursion of a row's curve against **that victim's own
control**, over the whole 65-point grid, worst of the row's cases —
`max_d |mean_row(d) − mean_control(d)|` in 16-bit counts, four complete blocks:

| row | aggressor | `REF_A` 5150 Ω | `REF_C` 5150 Ω | `REF_B` 650 Ω | `R_SP10` 150 Ω | `R_LO3` 150 Ω |
|---|---|---:|---:|---:|---:|---:|
| 1 | Silent (= G6's floor) | 6 / 7 / 7 / 7 | 6 / 7 / 6 / 6 | 5 / 5 / 6 / 5 | 1 | 0 |
| 3 | `MUX8_EN_N` | 5 / 7 / 8 / 6 | — | 5 / 6 / 4 / 4 | 1 | — |
| 4 | `MUX16_EN_N` | — | 4 / 3 / 2 / 5 | — | — | 0 |
| 5 | `MUX_A3` bare | — | 3 / 4 / 3 / 3 | — | — | 0 |
| 6 | `MUX_A3` + `EN16` | skipped | skipped | — | — | skipped |
| 7 | **LED word** | **13 / 15 / 15 / 13** | **9 / 9 / 9 / 9** | **12 / 13 / 12 / 11** | 1 | 0 |
| 9 | ShiftOnly | 6 / 6 / 7 / 5 | 2 / 3 / 3 / 3 | 6 / 7 / 4 / 5 | 0–1 | 0 |
| 10 | Silent, printing | 7 / 7 / 7 / 9 | 5 / 7 / 6 / 6 | 5 / 5 / 6 / 5 | 0–1 | 0 |

**Read the row-1 line first: it is the floor.** Row 1 is Silent, so its
"excursion against the control" is the difference between two curves in which
nothing was deliberately done differently. Rows 3, 4, 5, 9 and 10 sit at that
floor, with one 1-count exception not rounded away: row 3 on `REF_A` reads 8 in
block 3 against a floor of 7 in the same block.

**But a max-over-65-points statistic is weak, and the honest floor is lower than
it looks.** Two curves each wandering ~8 counts will differ somewhere by around
16 by chance alone, so "13–15 against a floor of 7" is thinner than it appears.
The whole-curve statistic is what settles it, and it was sitting in the same
capture:

| victim | direction | points positive of 65 | points negative | whole-curve mean `delta` |
|---|---|---|---|---|
| `REF_A` | dark→lit | 0 / 2 / 6 / 3 | 63 / 60 / 57 / 57 | **−6.77 / −6.80 / −6.26 / −5.89** |
| `REF_A` | lit→dark | 45 / 50 / 50 / 47 | 10 / 10 / 11 / 8 | **+2.20 / +2.06 / +2.38 / +2.49** |
| `REF_C` | dark→lit | 3 / 9 / 3 / 5 | 58 / 54 / 54 / 56 | **−4.09 / −3.71 / −3.92 / −4.23** |
| `REF_C` | lit→dark | 51 / 49 / 51 / 47 | 7 / 9 / 7 / 11 | **+2.72 / +2.75 / +2.75 / +2.23** |
| `REF_B` | dark→lit | 6 / 9 / 7 / 1 | 56 / 55 / 55 / 57 | **−4.88 / −5.03 / −5.49 / −5.22** |
| `REF_B` | lit→dark | 50 / 53 / 52 / 49 | 5 / 6 / 7 / 13 | **+2.69 / +2.55 / +2.72 / +2.62** |
| `R_SP10` | both | 0–3 | 0–1 | −0.02 … +0.03 |
| `R_LO3` | both | 0 | 0 | **+0.00 in all eight cases** |

**Nearly every point of the dark→lit curve is below its control and nearly every
point of the lit→dark curve is above it — on all three dividers, in all four
blocks — and the two directions of the same aggressor, at the same victim,
against the same control, are separated by about 9 counts of mean.** That is not
a peak that could be an outlier; it is 65 points agreeing.

**The null for that statistic is in the same capture.** Rows 3, 4, 5 and 9 — the
aggressors that do nothing — measured the same way give `|mean| ≤ 0.62` on every
one, with the signs roughly balanced. Row 7 is the only row in the table that is
not in that population.

**Spec §4's own discriminator says the same thing:** *"a disturbance that flips
with the edge is coupling, one that does not is the pulse itself."* It flips, on
all three dividers, in all four blocks.

**The shape**, measured over all three dividers and all four blocks: near zero
at `d = 0`, peaking at **3 400–5 600 ns in the dark→lit direction and
1 400–5 200 ns in the lit→dark direction**, decayed back into the noise by the
end of the grid (tail over 10–12.8 µs: `REF_A` −6…+4, `REF_C` −3…+2, `REF_B`
−5…+5). **The two directions are not symmetric** — dark→lit reaches −13…−15
where lit→dark reaches only +7…+10 on the same victim. Printed, not explained.

**Does it scale with source impedance? Not among the dividers.** 13–15 at
5150 Ω (`REF_A`), 11–13 at 650 Ω (`REF_B`), 9 at 5150 Ω (`REF_C`) — so the
650 Ω channel is nearly as disturbed as one 5150 Ω channel and more disturbed
than the other. `REF_C` is the victim on the 4051 and is the smallest of the
three, which is a per-mux observation, not an impedance one. **No mechanism is
asserted for either fact.**

### The verdict, as the reader computes it

`verdict_basis=envelope` on every row of every block, for the reason in §2.

| row | aggressor | `REF_A` 5150 Ω | `REF_C` 5150 Ω | `REF_B` 650 Ω | `R_SP10` 150 Ω | `R_LO3` 150 Ω |
|---|---|---|---|---|---|---|
| 3 | `MUX8_EN_N` | HELD 6–7 | — | HELD 4–6 | HELD 0–1 | — |
| 4 | `MUX16_EN_N` | — | HELD 3–4 | — | — | HELD 0 |
| 5 | `MUX_A3` bare | — | HELD 2–4 | — | — | HELD 0 |
| 6 | `MUX_A3` + `EN16` | skipped | skipped | — | — | skipped |
| 7 | **LED word** | **BROKE, 13–14** | **BROKE, 8–10** | **BROKE, 11–14** | HELD 1 | HELD 0 |
| 9 | ShiftOnly | HELD 4–6 | HELD 2–4 | HELD 4–6 | HELD 0–1 | HELD 0 |
| 10 | Silent, printing | HELD 6–7 | HELD 5–7 | HELD 4–6 | HELD 0–1 | HELD 0 |

**`REF_C`'s row-7 envelope straddles the criterion** — 8 in one read (a pass), 9
in another, 10 in two more. Three of four fail it; one does not. That is a
marginal result and it is reported as one, not rounded to either side.
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

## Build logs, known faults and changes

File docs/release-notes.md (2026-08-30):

<!--
  Body of the CURRENT release. `.github/workflows/build-plugin.yml` feeds this
  file to the GitHub Release via softprops/action-gh-release's `body_path`, so
  whatever stands here when a `v*` tag is pushed becomes that release's text.

  It describes one release, not a changelog: rewrite it in the same commit that
  bumps `host/vcv/plugin.json`, before tagging. Past texts stay in git history.
  Everything below the comment is public.
-->

## FireFlow 2.22.0

**Each deck can now be placed in the stereo field.** A new bipolar `PAN` knob
per deck, centre at noon, unity on both channels there — a centred PAN cannot
move a render at all. The law is a plain balance: turn right and the left
channel comes down, the right stays where it was. Nothing gets louder.

**The reverb stays in the middle.** PAN moves the dry signal only. The send
into the room is taken before the balance, so panning a deck hard left leaves
its reverb tail centred and the cloud intact, rather than dragging the whole
space over with it. This was the decision, not an oversight.

**PAN has a MOD ring, and the two decks mirror each other.** Latch MOD and the
PAN knobs take a depth like any other wreathed control. Deck B reads deck A's
lane **negated**, so the decks always move apart — one goes left as the other
goes right — instead of drifting to the same side together.

That mirror is not cosmetic. Both decks reading their own lane was measured at
a correlation of **+1.0000** whenever the two decks share a RATE: 98.7 % of the
time on the same side, 0.0 % opposite. The modulation lane does not depend on
the deck's seed, so two decks were producing one drift, twice, and the ring
panned the whole mix rather than opening it up.

**What the mirror costs, said plainly:** `MOD B` no longer reaches `PAN B`.
Deck B's pan modulation now runs off deck A's master, so `MOD A` down stills
both pans, and you switch deck B's off at its own depth ring instead. PAN has
had **no listening pass yet** — the balance law, the smoothing time, the lane
it rides and the mirror itself are all first-try values.

**Neither panel borrows Rack's parts any more.** New house knobs, jacks and
keys, drawn rather than pulled from the stock library: the knob caps now carry
their deck's accent colour on collar and pointer, so the hand can tell deck A
from deck B without reading a caption. Dragging, snapping, tooltips and the
right-click menu are unchanged — they are still the framework's.

**The lamps light in the colours the plates already printed.** Every LED bed on
both plates has carried a zone tint for a long while, and a saturated yellow
was painting over all of them. Deck A is teal now, deck B orange, the centre
blue-grey. REC stays red, because on a record light that is the point.

**The hardware plate (`FireflowHW`) is one flat surface.** The tinted zones,
the printed ember silhouette, the fade overlays and the dashed drawing frames
are all struck; zone identity moved into the group fields instead, which is
also why the "DECK A" / "DECK B" legends are gone — the tint says it. `SEND`
moved out of `ROOM` and into `LEVEL`, where it belongs, on a frame that now
reaches past the deck edge to hold it. The jack row lost its group legends: the
caption under each socket already names it.

**One deliberate regression on that plate:** the accent rings marking which
knobs accept modulation are no longer printed — they are drawn, and only while
MOD is latched. Silkscreen cannot switch, and a real aluminium panel would have
to carry them permanently or not at all. This release rehearses "not at all",
so on the hardware draft, which knobs carry a depth is learned rather than read.

This is a development alpha. Saved patches may break between releases.

## Install

Download the `.vcvplugin` for your platform, unpack it into Rack's user plugin
directory and restart Rack. Built against Rack SDK 2.6.6 for Windows x64, Apple
Silicon (mac-arm64) and Linux x64.

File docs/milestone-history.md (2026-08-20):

# FireFlow — Milestone History

*(the project was called spotymod, and before that Spotykach, until 2026-08-04;
the dated entries below keep the name they were written under)*

This is a chronological, commit-level record of how each milestone actually
happened: commit ranges and SHAs, plan defects caught during execution,
review verdicts, test counts, retired scenarios, by-ear/play-test rounds,
and release tags. It was extracted on 2026-07-21 from the assistant's memory
file (which had grown to 79% of the entire memory store) so the detail lives
beside the code instead of in a context window.

`docs/roadmap.md` is the forward-looking, feature-level counterpart: it
already gives the authoritative "what's built, what's planned" status table
and per-milestone feature descriptions through M5 and the CPU rounds. Where this
document repeats a milestone's scope, treat roadmap.md as the summary and
this file as the archive of *how it got there* — commit SHAs, false starts,
reviewer verdicts, and the specific by-ear/play-test iterations, none of
which roadmap.md carries.

Current state (which milestones are merged/pushed/released today) lives in
[`docs/roadmap.md`](roadmap.md), not here — that file is kept current; this one
is not. **This archive stops at 2026-08-04**, the rename; everything after it —
the hardware panel rounds, PACE, the FLOW melody engine, the melody-reachable
round, the flow/Glow removal, the SMOOTH rework, the STEP accent — is recorded
in the roadmap alone. (An earlier version of this paragraph pointed at a
`spotykach-milestone-status` memory; that memory no longer exists.)

---

## M1 — Engine foundation (2026-07-10, merged 2026-07-11)

Plan: `docs/superpowers/plans/2026-07-10-spotykach-modulation-first-engine-foundation.md`.
Merged into `main` via fast-forward on 2026-07-11 (16 commits); branch
`feat/m1-engine-foundation` deleted afterwards. All commits were rewritten to
the GitHub noreply email `29505413+mcbronkowitch@users.noreply.github.com`
(repo `git config user.email` set to it) to pass GH007 push protection —
later work kept using that email. The public fork was renamed `Spotykach` →
`spotymod`.

Delivers the portable `engine/` core (`namespace spky`, no libDaisy, no
heap): `Rng`, waveform bank, RANGE, `ModLane` (FLOW/STEP/EVOLVE incl. rate
wander), `SuperModulator` (5 lanes, ratios ×2/×½/×1/×¾/×1½), `Part` + engine
interface + `TestToneEngine`, `Instrument` public API; plus the desktop
render host (`render` CLI, scenario JSON → WAV + `mods.csv`) and 34 doctest
cases. Build via the desktop build env (clang+ninja+vendored headers, no
MSVC; `source env.sh`).

### Scales layer (2026-07-11, on `main`)

Pitch quantization (13 scales in three groups, SCALE/CHROM/FREE, root) on the
PITCH lane; UI wiring deferred to M6. The list expanded on 2026-07-23.

## M1.6 — FX (2026-07-11)

Implemented subagent-driven from plan `docs/superpowers/plans/2026-07-11-spotykach-fx.md`
(spec `...-fx-design.md`). 11 commits (`2c8300a`..`c5b62d6`), 77 doctest
cases green. Delivers: `daisysp_min` desktop build; `engine/fx/` =
`fx_util.h` (XFade/SoftSwitch ports), `grit.*`, `flux.*` (injected echo
buffers, `Flux::kMaxSamples=240000`), `reverb.*` (`AmbientReverb` =
ReverbSc + optional +12st shimmer, ~530 KB, always static), `part_fx.*`
(chain GRIT→FLUX→FX MIX + equal-power reverb send; ids `FXT_GRIT_INT=0,
FLUX_TIME=1,FX_MIX=2,REV_SEND=3,FLUX_FB=4`); `Part` 2nd FX target row +
`init(sr,seed,echo_l,echo_r)` + 4-output `process`; `Instrument` `FxMem` /
`init(sr,FxMem)` / FX API + shared reverb post-mix; host: 10 scenario
actions, 5 FX CSV cols/part, `dub_delay` / `ambient_wash` demos.

Acceptance verified: bit-exact bypass, determinism, CPU ~1.09× baseline. One
plan test ("grit click-free") was rewritten with user approval to compare
ramped-vs-always-on baseline (the Drive fuzz itself slews >0.1/sample at
intensity 0.7, unrelated to the switch). SoftSwitch API fixed for M2:
`set_on(bool,bool immediate=false)`, `is_on()`, `is_idle()`, `process()`.

**By-ear listen: one real bug found and fixed (commit `2d02b01`).** The
shimmer reverb feedback ran away to +Inf (click then silence in
`ambient_wash` after ~2 s). Root cause: shimmer re-injected the
pitch-shifted wet at a fixed 0.5 gain while the room's own gain is
~1/(1-feedback), so loop gain exceeded 1 at large sizes. Fix: scale shimmer
feedback by `(1-reverb_feedback)` + a SoftClip safety net; added a stability
regression test (78 cases); retuned `ambient_wash.json` to sane levels.
`dub_delay`'s "rubber band" effect turned out to be the intended FLUX TIME
(delay-time) modulation by the STEP lane sweeping 0.19–4.2 s — not a bug, a
taste knob, left as-is.

DaisySP headers leak transitively through `part.h`/`instrument.h` from here
on (fine per plan; PIMPL was noted as an M6 option if a DaisySP-free
non-fx build is ever wanted — never pursued).

## M2 — Polyphonic synth voice (2026-07-11)

Executed via a sequential build-gated workflow (one general-purpose agent per
TDD task, stop-on-failure, plus a final independent constraint/acceptance
auditor) from plan `docs/superpowers/plans/2026-07-11-spotykach-synth-voice.md`.
9 commits `5e9bbc6`..`6e40c27` (fast_sin → MorphOsc → Env → Voice →
SynthEngine → Part engine-select → Instrument API → host scenario/CSV →
demos+docs), 113 doctest cases green. Audit passed all 6 checks, 0
violations: fresh `rm -rf build` rebuild 100%; no libm sine in the voice
audio path (all `std::pow`/`std::exp` control/trigger-rate only); engine
purity (no heap/vector/`<random>`, sole DaisySP header `Filters/svf.h`, sole
`Rng` seeded once in `Voice::init`); `src/`/Makefile/firmware `main.cpp`/
`app.*` untouched; acceptance renders pass (overlapping_voices hits 4
simultaneous voices; flow_drone never silent incl. the prob-0 24–36 s
stretch; determinism byte-identical).

Delivers `engine/synth/` = `fast_sin` (`engine/util/`), `MorphOsc`, `Env`,
`Voice` (2× MorphOsc + sub + `Svf` + env + equal-power pan/drift),
`SynthEngine` (4-voice round-robin, oldest-steal retrigger, FLOW
sustaining-drone w/ auto-trigger+demotion, target map
TIMBRE/FILTER/PITCH/MOTION/LEVEL, control-rate per 96 samples);
`IPartEngine` no-op `set_cycle`/`set_flow`; `Part` boot-default
`ENGINE_SYNTH` + click-free SoftSwitch engine switch + flow/cycle forwarding
+ `trigger_manual`; `Instrument` synth-voice API; host 7 scenario actions +
`voices`/`v0..v3` CSV + `overlapping_voices.json`/`flow_drone.json` demos
(existing 7 scenarios pinned to `test_tone`).

**Two plan defects found and fixed during execution:** (1) the `Env`
retrigger test pre-rolled 24000 samples (0.5 s) but the AD envelope idles at
−80 dB ≈ 0.45 s (~21.6 k samples) → `before==0` failed `CHECK(before>0)`;
corrected to 12000 in both the fork test and the plan doc (implementation
was correct per the locked design decision). (2) plan prose said "+7 voice
cases" but the verbatim block had 6 `TEST_CASE`s — code treated as
authoritative.

Renders were not committed: `renders/` is gitignored in this fork (the
plan's "repo already tracks renders/" premise was false); WAVs are
regenerable. Spec `docs/superpowers/specs/2026-07-11-spotykach-synth-voice-design.md`.
UI wiring (VOICE edit layer, PLAY-tap trigger, engine-switch gesture)
deferred to M6.

## M3 — Capture sequencer (2026-07-12)

Subagent-driven from plan `docs/superpowers/plans/2026-07-12-spotykach-capture-sequencer.md`
(spec `...-capture-sequencer-design.md`). 9 commits `f7c6cc2`..`b30e801`,
137 doctest cases green, pristine. Approach B: new header-only
`engine/mod/capture.h` `CaptureLoop` (two 192-slot double buffers;
`kSlots=192`; `reset`/`record`/`capture_now`/`value`/`fired`/`valid`; a dumb
buffer, no timing of its own — `ModLane` drives slot indexing via one
`_phase_slot()` helper so record & replay share the mapping); `ModLane`
gains `set_capture_loop(CaptureLoop*)` (PITCH lane only, others keep
`nullptr` = unchanged), rolling record of pre-smooth `_target`+fired into
the ring every generative sample (pure write, never touches RNG →
bit-determinism preserved), and a replay rule (`set_replay`/`replaying`):
boundaries come from recorded fired slots, live PROBABILITY dice roll per
fired slot (fail = frozen hold), SMOOTH/RANGE + Part base/depth/TUNE/
quantizer stay live, EVOLVE fully ignored on the replaying lane;
`SuperModulator` owns one `CaptureLoop` wired to `LANE_PITCH` in `init()` +
`capture_now`/`set_replay`/`replaying`/`loop_valid`; `Instrument` per-part
delegation; host `capture_now`/`set_replay` scenario actions +
`a_cap`/`b_cap` CSV cols + `capture_loop.json` demo.

Final Opus whole-branch review: Ready to merge = YES, all 5 acceptance
criteria PASS, no Critical/Important.

**Plan corrections made during execution:** (1) plan said "Part needs no
change" but `Part::mod()` was non-const → added a minimal
`const SuperModulator& mod() const` overload for the const Instrument
accessors. (2) several plan tests compared a sampled target stream across
cycles, which is flaky against a pre-existing ~0.0006/cycle float32
`_phase` drift that jitters samples at the loop's hard ±1 transitions
(slots 0/96) — rewrote determinism/EVOLVE/persistence + Instrument
TUNE/scale tests to drift-immune exact comparisons (two identically-seeded
instances that drift identically, or a snapshot of the frozen 192-slot
buffer), and added a criterion-1 unit test asserting
`target()==loop.value(slot)` at every slot over 3 cycles. (3) Task-2 test
helper `shape=0.9→0.75` (0.9 lands in the S&H blend region where
`_sh_cycle` is RNG-redrawn per cycle; 0.75 = pulse/S&H boundary, zero
random weight).

Known accepted minors (non-blocking): no bounds-check in `CaptureLoop`
(matches `rng.h` caller-guarantees convention); the EVOLVE
phase-rate-guard branch isn't unit-covered (confirmed correct by code
review; an exact test was deemed too fragile). Bit-determinism
independently re-verified. UI wiring (ALT+SEQ gesture, ring step display)
deferred to M6.

### Entropy sequencer (2026-07-12, reworks the lane core)

Subagent-driven from plan `docs/superpowers/plans/2026-07-12-spotykach-entropy-sequencer.md`
(spec `...-entropy-sequencer-design.md`; supersedes a same-day
per-step-S&H spec explicitly banner-marked "do not implement"). 5 fork
commits `f205197`..`f259046`, 145 doctest cases green; residency doc
commits `11bcdfe`+`4980cbe`.

Delivers: bipolar ENTROPY replaces EVOLVE everywhere (`set_entropy` −1..+1
through ModLane/SuperModulator/Instrument; scenario action renamed
`set_evolve`→`set_entropy`; positive = old EVOLVE walk scaled, negative =
walk decays ×(1+0.2·e)/cycle toward neutral, 0 = frozen); looping S&H step
buffer `_seq[32]` per lane (pre-filled at init from seed; STEP reads
`_cur_step % 32`, FLOW slot 0; per-wrap redraw removed — the LOOP contract
now holds in the S&H zone); `_mutate_slot()` on fired steps only (dice =
entropy², GROW `v=(v+r³·lerp(0.5,2,e))·0.9` clamped, ERODE `v·=0.6`
snap-to-0 below 0.02; constants `kGravity`/`kErode`/`kRootSnap` in
lane.cpp, ear-tunable); `shape_value()` fixed so shape==1 returns the S&H
operand exactly (old code left 0.01% pulse bleed).

Master spec updated: switch 2 = ERODE/LOOP/GROW (M6 must map it, detents
±0.4), ENTROPY macro bullet, signal-path diagram. `demo_step_melody.json` =
entropy showcase; capture demos melodized. Final Fable whole-branch review:
Ready to merge = YES.

**Known interaction (judged benign, documented):** positive entropy's
`_ev_shape` walk pulls effective shape below 1.0 → slight pulse bleed in
the S&H zone; two plan test seeds changed 42→14/12 for this confound
(thresholds untouched, reviewer reproduced independently). Accepted polish
backlog: `_ev_*` erode decay never snaps to 0 (LOOP-after-erode not
bit-exact); no freeze-after-wander test; stale EVOLVE comments in
`melody_then_drift.json`.

**By-ear listen DONE (3 rounds, all fixed):** 64th-note rates retuned to
8ths/quarters; demo part B (unconfigured default lanes = pitch siren)
silenced; part A LEVEL S&H clicks → LEVEL target turned off (lesson: STEP+
S&H on LEVEL at low SMOOTH clicks by construction on sustained tones). New
demo `entropy_duet.json`. Dev-diary entry published with 4 embedded
renders.

## M6 firmware shell — spec done (2026-07-12)

Spec `docs/superpowers/specs/2026-07-12-spotykach-firmware-shell-design.md`
(commit `48ded8b`): portable `shell/` UI core (`PanelIn`→`Instrument`+
`LedFrame`, no libDaisy/heap) + a thin `app_mod.cpp` Daisy adapter.
Resolves the accumulated pad-overbooking problem with a targets-first
rule: the plain layer of the 5 per-side pads (PLAY/REV/GRIT/FLUX/SEQ =
target slots 1–5, GRIT=PITCH, SEQ=LEVEL/no-LED) stays the master-spec
targets, and ALL other functions move behind ALT matching the printed
labels — superseding M2's plain PLAY-tap trigger (now ALT+PLAY) and
M1.6's plain FLUX/GRIT gestures (now ALT+FLUX/GRIT); the reverb layer
folds into the FLUX edit layer; Drive↔Reduce becomes a two-zone knob. FX
edit layers stay sticky while ALT is held; scale select is the SHAPE knob,
8 zones inside the PITCH-pad edit layer; MIDI is minimal (clock in + note
ch1/2→A/B); persistence is one versioned QSPI block named `"mod"` (all
hand-set values; COUPLE/DRIFT/MORPH/capture stay volatile); the scenario
host gains panel events + `params.csv`/`leds.csv`. Verified against a
product photo of the real hardware: one big knob per side (TUNE, with a
ring around it), RATE/DEPTH are small blob knobs, input trimmers are
analog-only, and the faceplate already prints "record"/"+alt" hints
confirming the ALT scheme independently. (This spec predates the later
scale-re-home and edit-layer-latch amendments below, and the pad/gesture
scheme was revisited repeatedly through 2026-07-16/17 as CHOKE, FILT, MOD/
TIDE and the step-clock landed — see those sections for what actually
shipped; M6 implementation itself has not started as of M5a.)

## Cross-spec review + amendments (2026-07-12, commit e638cab, residency repo)

Three parallel reviewer agents (UX / embedded / promise-accounting) audited
all 8 specs against the fork; essential findings folded back into the
specs before M4/M5/M6 implementation started. Key amendments implementers
had to honor: (1) M6 scale controls re-home to a global-scale + per-part-mode
model, mode = 3-zone SHAPE knob in the PITCH edit layer (an earlier 8-zone
per-part idea was dropped). (2) ALT-entered edit layers latch; a plain ALT
tap exits. (3) M6 gained 4 engine deltas: `set_pitch_cv_offset` (V/Oct,
pre-quantizer), `trigger_note` (MIDI), master SoftClip at the Instrument
mix, `fast_sin` swap in `shape_value`+`part_fx`. (4) M5 spec amended:
`set_monitor`/`sampler_monitor` input monitoring, loading = clear +
fill-follows. (5) M4 supersedes M1.6's pre-morph reverb send. (6) FX spec
echo-buffer figure corrected to 3.8 MB. (7) M6: pads/sr_165 polled in the
main loop only (never ISR), LED frames composed in the audio tick, factory
state + BOOT-held-at-power-on reset, 100 BPM default, EVOLVE 0.3/1.0 +
SMOOTH floor 0.35 constants, SETTLE also clamps FLUX FEEDBACK bases >0.95,
sampler content gestures, `arm-none-eabi-size` acceptance, first hardware
measurement = METER reverb+shimmer alone.

## M4 — Center section (2026-07-12)

Plan `docs/superpowers/plans/2026-07-12-spotykach-center-section.md` (10
TDD tasks). Executed subagent-driven on `main` via two build-gated
background workflows (`spotykach-m4-center` = tasks 1–7 then correctly
STOPPED at task 8 on a real plan-test bug; `spotykach-m4-finish` =
corrective commit + tasks 9–10 + final whole-branch review) — one
implementer + Opus task-reviewer + one fix pass per task, stop-on-failure.
Fork commits `d784bc7`..`aa6c921` (M4) + `fc41ae2` (docs), base `db7e731`;
170 doctest cases green. Final whole-branch review: approved / ready to
merge, all acceptance criteria PASS, determinism bit-identical (double-
render `cmp`), no libDaisy in engine, `src/` untouched.

Delivers `engine/center/Center` at control rate (per 96 samples) + 4 narrow
hooks: `SuperModulator::set_rate_scale` (COUPLE×DRIFT rate, splits
`_update_rate`→`_apply_rate`, adds `base_hz`/`sync_mode`),
`set_shape_offset`, `Part::set_detune_cents` (post-quantizer; `pitch_cv()`
stays clean), per-lane `ModLane::kick`/`set_shape_offset`/`settle`. MORPH =
equal-power `cos/sin(m·π/2)` on dry AND reverb send (supersedes the M1.6
pre-morph-send rule; morph-0.5 boot = −3 dB/part, a deliberate level
change — no test pins audio so existing tests stayed green); COUPLE =
Kuramoto PLL (geometric-mean convergence + sin phase pull, SYNC-anchor
rule, clamp ×0.5..×2, `kK`=0.15); DRIFT = OU weather walk (τ≈45 s,
tanh-bounded) with 6 hardcoded taps; SPOT per-live-lane kick (phase
permanent, shape decays τ=1.5 s, replaying PITCH lane immune); SETTLE panic
glide. Host: 5 scenario actions + 5 `mods.csv` cols (`morph,couple,drift,
weather,phase_err`) + `couple_lock`/`weather_spot` demos. Zero-effect
invariant (couple 0 + drift 0) verified bit-identical vs a bare
SuperModulator.

**M4 deviations flagged in the final review (non-blocking, ear-check
later):** (a) morph smoother 0.03 s not 0.02 s — inaudible, fine. (b)
DRIFT response ~quadratic not linear — implementers scale the OU noise by
the smoothed `_drift` in `_step_weather()` AND the taps by `_drift` in
`update()`, so `weather()`≈0 at drift 0 and the knob feels exponential;
rationale was SETTLE robustness (smoothed drift never hits exactly 0);
deviates from the spec's linear "scales all taps." If the drift taper ever
feels off, scale only the taps and gate the OU on `_drift_target`. (c)
COUPLE mixed SYNC+FREE was only exercised by a unit test that checks the
anchor is unchanged, NOT that the FREE bank reaches the anchor's rate —
for a large detune the free bank may lock only with a static phase offset.
(Two implementer plan-test bugs were caught & fixed: SPOT decay test was
too strict at the sensitive shape-0.5 pulse edge → rebased to shape 0.2 +
relative-decay; the morph-isolation test demanded the shared-reverb tail
vanish within 1 s → split into exact dry-isolation + decaying-send-
isolation.)

Residency-repo M4 docs: plan committed (`201f4e8`); dev-diary "Center
section" entry + `couple_lock`/`weather_spot` web renders (`83b4c1a`).

### M4 by-ear pass (2026-07-12)

User heard `weather_spot`/`couple_lock` pitch wandering wildly and set the
rule: **pitch must not be a drastic target of other (center-section)
modulations.** Root cause (found via CSV, not the center module): both
demos drove the PITCH lane full-range (default `range` 1.0 + high base) = a
3-octave siren; SPOT/DRIFT were negligible there. Fixes: (1)
`SuperModulator::spot` now skips `LANE_PITCH` entirely (live or replaying)
— pitch immune to the stumble, the other 4 lanes still lurch; commit
`5c09ddf`, proven byte-identical pitch column with vs without SPOT. (2)
Both demos retuned to stepped pentatonic melodies in a moderate unipolar
range with low pitch bases; commit `42acefe`. Residency spec/plan/dev-diary
updated + web renders re-encoded (`69aaa88`). 170 tests still green.

## M4.5 — Ambient Reverb v2 (Oliverb port) (2026-07-13)

Spec `docs/superpowers/specs/2026-07-12-spotykach-ambient-reverb-v2-design.md`
(commit `fe29fdd`), plan `docs/superpowers/plans/2026-07-12-spotykach-ambient-reverb-v2.md`
(`a4e7a26`); M1.6 FX spec superseded-notes `e13f4cb`. Executed
subagent-driven, 7 fork commits `3de9002`..`84202b8`, 181/181 doctest cases
green. Delivers: vendored MIT Oliverb (Clouds Parasite) under
`third_party/oliverb/` (`stmlib_shim.h` + deterministic `RandomOscillator`
on spky::Rng/fast_sin + float-only `fx_engine.h` + `oliverb.h` — ×1.5
constants for 48 kHz, pitch shifter removed, per-sample Process,
control-rate `Prepare()`, size smoothing 0.0002 for ~100 ms Doppler rides,
slope /300); facade `AmbientReverb` (SIZE Doppler / DECAY crosses 1.0 at
0.9 cap 1.05 / TONE / DEPTH; `set_shimmer` deleted everywhere; buffer 128 KB
inline member — M6 SDRAM placement must account for the embedded buffer, no
separate FxMem pointer); DaisySP-LGPL fully unlinked, repo MIT-clean;
scenarios migrated (old `set_reverb_size` had actually meant decay —
semantics moved to `set_reverb_decay`); `ambient_wash.json` = showcase
(bloom ride 20–30 s, Doppler size ride 36–46 s, 60 s).

**Clipping saga:** the plan's showcase values clipped — bloom plateaus
near full scale at core output taps (2× tap gain + Hermite overshoot under
depth mod); fixed after 4 passes with `kWetGain = 0.40f` (−8 dB,
ear-tunable 0.40–0.50) wet trim in reverb.cpp + retuned mix (LEVELs
0.40/0.32, sends 0.20/0.18, depth 0.348, bloom decay 0.94); final peak
30853 / 0 clips / deterministic. Final Fable review verified transcription
against actual upstream: Ready to merge; a stmlib_shim MIT-notice gap
(plan defect) fixed in `84202b8`.

## M4.6 — Dynamics (2026-07-13)

Spec `docs/superpowers/specs/2026-07-13-spotykach-dynamics-design.md`
(`d2c5de7`), plan `docs/superpowers/plans/2026-07-13-spotykach-dynamics.md`
(`7730831`), shell-spec delta-3 supersession `51a6815`. Executed
subagent-driven, 7 fork commits `2cc6b2c`..`5156b96`, 199/199 doctest
green. Delivers: `Comp` one-knob compressor per part (`engine/fx/comp.*`,
end of PartFx before the reverb send tap — dry AND send compressed; knob =
loudness first: thr −32a dB / ratio 1+9a² / release 60→350 ms / auto-makeup
`−thr×(1−1/ratio)×kMakeupComp`; stereo-linked detector, gain computer
decimated ×16, amount 0 = bit-exact bypass w/ re-arm) + `Limiter`
(`engine/fx/limiter.h`, stmlib recipe stereo-linked, exactly bit-transparent
below −1 dB knee at drive 0, tanh ceiling asymptote 1.0 — delivers M6
Engine delta 3 early; vendored daisysp::Limiter rejected: unconditional
SoftLimit(x·0.7)) + `set_comp(p,n)`/`set_master_drive(n)` (pre-gain 1–4×),
boot 0/0, denormal floors 1e-9. Host: 2 scenario actions + `comp_pump.json`
showcase (RMS arc raw 2603 < glue 2703 < dense 8343 < pump 10311, peak
32766, deterministic). Final Fable review: Ready to merge = YES; pre-M4.6
bit-identity verified against a true `8fc1b1a` worktree build (14/15
scenarios byte-identical; `ambient_wash` 15 samples ≤109 LSB accepted as an
above-knee limiter touch).

**By-ear round 1 (2026-07-13):** user heard clipping at 0:26 and a 0:56
outro cliff. Diagnosis: makeup 0.9 lifted the dense/pump program envelope
to ~−4 dBFS → peaks grounded the limiter tanh continuously. Root fix
`e678de0` in the gain computer: `kEnvCeiling 0.4` (−8 dBFS post-comp
envelope cap; quiet keeps full makeup), asymmetric gain smoothing (down
0.5 ms / up 2 ms), attack scales 5→2 ms with amount (supersedes fixed
5 ms; spec amended). 200/200 tests (new env-cap test), arc
2603/2703/7056/7430 monotonic. `kMakeupComp` stays 0.9 — now safe under the
cap. Re-listen APPROVED (round 2). New dev-diary showcase `m7_bloom.json`
(`e2f45ed`): spread Am7 strum, tail 2197 → comp ride 8117 RMS (+11 dB
resurrection), zero limiter contact. Dev-diary entry "One knob louder"
published. M6 notes: GRIT layer SMOOTH→COMP, FLUX-layer TUNE (ex-shimmer)
→MASTER DRIVE (collision w/ reverb DECAY/DEPTH axes unresolved); the
limiter is load-bearing against the comp post-silence makeup burst.

## M4.7 — Melody engine rework (2026-07-14)

On fork branch `melody-engine-rework`. 15 commits `fb4f6ab`..`f77e9ca` +
post-completion `152b88e` (DRIVE warm saturation). Removes
PROBABILITY/capture/entropy APIs in favor of MELODY (bipolar VARIATION),
DENSITY, 5 phrase PRINCIPLEs, new_phrase; VCV plugin fully migrated
(`gen_panel.py` is the single source of truth for the panel). 13 old
scenarios retired (kept as mp3/ogg). Follow-ups owned by the user: audition
principles in VCV, fresh dev-diary showcase, VCV PRINCIPLE dataToJson
persistence.

### M4.8 — Reverb dry/wet MIX (2026-07-14, merged into `melody-engine-rework`, HEAD `b42327a`)

Spec `docs/superpowers/specs/2026-07-14-spotykach-reverb-drywet-design.md`,
plan `...plans/2026-07-14-spotykach-reverb-drywet.md`. 8 commits
`fef3857`..`b42327a`, 199 cases green, final Fable review Ready-to-merge
(fix applied). Delivers `set_reverb_mix` (equal-power, exact endpoints,
10 ms OnePole glide, at the master join in `Instrument::process`),
clear-on-sleep CPU bypass at MIX 0, scenario action + VCV `REV_MIX` knob.
**Default 0.25 is a by-ear choice, deliberately leaner than the old join**
— MIX multiplies on top of `kWetGain`, so the pre-M4.8 balance sits at MIX
0.5 (−3 dB overall); the original spec claim that 0.25 ≈ old balance was a
controller arithmetic error, corrected in spec/roadmap/code. Accepted
minors incl. REV_MIX param-id insertion before TEMPO shifting Rack
saved-patch ids (append-after-TEMPO in `gen_panel.py` until the M6 panel
freeze).

### M4.9 — Reverb DIFFUSION knob (2026-07-14, merged into `melody-engine-rework`, HEAD `b27052f`)

5 commits `8867021`..`b27052f`. DEPTH removed ersatzlos; `set_reverb_diffusion`:
AP coeff `0.90·n` (0 = slap echoes, boot 0.7 ≈ old stock, 1 = wash that
melts attacks — the full-wash motivation: Oliverb feeds the diffused input
straight to the output taps), line-mod weakly coupled `(0.05+0.20·n)·450`.
VCV `REV_DIFF` "DIFF" in REV_DEPTH's enum slot (param-id stable). Final
Fable review: Ready to merge = Yes. Caution carried forward:
`Part::set_depth`/`Instrument::set_depth(int,float)` is the unrelated lane
macro — never confuse with the removed reverb depth (see the gotchas
memory).

## SYNC/COUPLE redesign (2026-07-16, released v2.1.0/v2.1.1)

Spec `docs/superpowers/specs/2026-07-16-sync-couple-redesign-design.md`,
plan `...plans/2026-07-16-sync-couple-redesign.md`. Subagent-driven, 11
commits `ad06645`..`1637d07`, 216 doctest green, final Fable whole-branch
review Ready-to-merge after one polish commit (`987866e`).

Delivers: per-part `SyncMode` (Free/Sync/Triplet) removed everywhere →
global `Instrument::set_sync(bool)`; `engine/mod/divisions.h` 17-rung
speed-sorted ladder (straight+dotted+triplet, `division_index =
round(norm*16)`) + `free_hz` moved there; `engine/center/transport.h`
`Transport` beat accumulator (double; `clock_pulse()` snaps to nearest
beat, `reset()` zeroes downbeat) owned by Center; `SuperModulator::
set_rate_scale(pitch_s, mod_s)` split; Center grid world (SYNC on:
per-bank pitch servo onto transport — sin-shaped hard-lock law
`kKHard·sin(2π·err)` capped, NOT the plan's linear form — adjudicated:
linear failed the 0.02 lock bound under EVOLVE wander; COUPLE gates only
mod-lane DRIFT wander via `drift^(1−couple)`) + free world (pairwise
Kuramoto unchanged; COUPLE>0.5 smoothstep grid gravity toward nearest
ladder rung + downbeat, hard at 1.0 with the same sin law); VCV: panel
layout A (params 63→62, stride 24→23 — breaks saved 2.0.x patches), CLK
edge now also phase-aligns transport, RST jack finally live, RATE tooltip
shows division name when synced / Hz when free; plugin 2.1.0 built +
installed. Init RATE defaults remapped to the ladder.

**v2.1.1** added init part-A RANGE=1.00; user's Rack play test passed
("geht alles"). Residency-repo note: a rogue commit `8c865d0` had deleted
the whole website locally — reverted, was never on origin. Post-merge test
backlog left: Instrument-level `set_sync`/`clock_pulse`/`reset_transport`
integration test; SYNC flip mid-run continuity; free-world full-COUPLE lock
under DRIFT=1.

## Ranked-slot groove / rhythm engine (2026-07-16)

Spec `docs/superpowers/specs/2026-07-16-rhythm-groove-design.md`, plan
`...plans/2026-07-16-rhythm-groove.md`. Subagent-driven, 6 commits
`1db7458`..`f191786`, 229 doctest green, final Fable review READY TO MERGE
after one fix commit. Replaces the metric-weight gate threshold with
composed rhythm: `pg_gen_groove`/`GrooveCell` in phrase_gen.h — per-phrase
seeded firing-order ranking, period = motif length L, syncopation via
push/anticipation displacement, slot-0 anchor pinned to rank 0; DENSE =
monotonic ranking depth (`_groove_k`, k = max(1, round(density·L)); turning
the knob only adds/removes notes from the same groove, never re-rolls);
composed note durations 1..4 steps on `gate_state()`; RENEW keeps the
groove, NEW PHRASE/step-length change re-rolls it.

**GATE jack routing (final-review catch, plan defect):**
`ModLane::note_sustain()` (step+melodic qualified) →
`SuperModulator::pitch_sustain()` → OR'd into `Part::gate()` with the 5 ms
pulse; at DENSE 1 the jack is continuously high (spec'd legato). Also
fixed mid-flight: stale note state on live FLOW→STEP toggle (guarded clear
in `set_step`); 3 silence-window tests pinned to DENSE 0. Deferred to user
(by ear): Rack play test (DENSE sweep, GATE articulation, FLOW/STEP
toggle), listening pass, tuning constants in `pg_gen_groove` (sync degree
0.15–0.75, push bonus 0.05, note_len distribution 55/25/15/5).

### Groove variation zones (2026-07-16)

Spec `docs/superpowers/specs/2026-07-16-groove-variation-zones-design.md`,
plan `...plans/2026-07-16-groove-variation-zones.md`. Commits
`65b4bf6`..`5b1f985`, 235 doctest green, final Fable review READY TO MERGE
(+ follow-up fix for odd-L bounds). MELODY (VARIATION) knob is now zoned:
`|v|` 0–0.25 = melody-only (groove frozen, exactly old behavior); 0.25–1.0
= per-wrap dice `r²` (`r=(|v|−0.25)/0.75`) triggers at most one groove
mutation (GROW: adjacent-rank swap or note_len ±1; RENEW: push flip or
nudge, full re-roll only at `|v|≥0.9`). All mutations preserve permutation/
anchor/len invariants structurally → DENSE monotonicity survives. LOOP
draws nothing.

**Determinism gotcha found here:** zone-1 melodic STEP lanes draw the
(always-failing) dice each wrap → RNG stream ≠ previous release at same
seed; renders not byte-comparable across versions by design (fixed draw
count per wrap; see the gotchas memory). Also that day: `demo_step_melody.json`
retuned (was 32 notes/s straight 16ths relying on boot defaults; now a
2-bar cycle, DENSE 0.55, synth voices, DENSE-sweep tail, commit `c3cce41`).

### CHOKE event-priority knob (2026-07-16)

Spec `docs/superpowers/specs/2026-07-16-choke-priority-design.md`, plan
`...plans/2026-07-16-choke-priority.md`. Subagent-driven, commits
`7ca4ffe`..`ff9ce34`, 243 doctest green, final Fable review READY (no
must-fixes). Center control CHOKE (Trimpot at CX/y=51 between SCALE and
DRIFT, appended last — default 0 = bit-identical off): negative = A
priority/B yields, positive mirrored.

**Rev. 2** after user play-test (commit `7834fec`): the original continuous
curve "fühlt sich kaputt an" → five snapped states (off, per-side "choke",
per-side "choke thru decay"). Dice/`_claim`/choke-Rng deleted. Skip-not-
delay: `Part::set_inhibit` blocks engine trigger + gate pulse + latches the
suppressed note's STEP sustain out of `gate()`.

**Rev. 3 bugfix (commit `7291895`, tag v2.2.1, PUSHED + released):**
"choke only works with equal rates" — root causes: stage-1 window was the
literal GATE signal (FLOW 5 ms pulses ≈ never open); the yielder's FLOW
drone was immune. Fix: both stages became env windows — stage 1 = priority
LOUD (gate high or max voice env > 0.1), stage 2 = audible (> 1e-4); new
`IPartEngine::set_hold(bool)` demotes the yielder's FLOW drone click-free
while inhibited.

**Rev. 4 (commit `ebed761`, tag v2.2.2, final semantics):** rev-3's loud
window (env > 0.1) over-blocked with long decays. Final: stage 1 = while
the priority side HOLDS a note (STEP: gate high; FLOW: always counts as
held via new `Part::flow()`), stage 2 = additionally through the audible
decay (env > 1e-4). New regression test pins skip-not-delay: with choke −1
and different rates, the yielder's lanes/pitch CV/fire slots stay
bit-identical to an unchoked run. Suite 244/244. Releases v2.2.0/v2.2.1/
v2.2.2 all tagged+CI-built.

## FILT cutoff-trim knob (2026-07-17, pushed as v2.3.0, not tagged/released)

Spec `docs/superpowers/specs/2026-07-17-filt-knob-design.md` (v2 — the v1
HP-half was cut for CPU: no new filter at all), plan `...plans/2026-07-17-filt-knob.md`.
Subagent-driven, commits `a6196dc`..`1cd5e56` (base `64f1896`), 253 doctest
green, final Fable review READY TO MERGE. Bipolar FILT per part (Trimpot,
voice row now 6 knobs `ATK DEC FILT RES SUB DTUN`, FILT_A/_B appended last
— stride 23 unchanged, patches compatible): offset in normalized lane space
before the voice SVF (left ×1.25, right ×1.0), below the 60 Hz rail a
`_filt_gain` fade through the LEVEL OnePole → full left = silent for any
lane, center bit-identical, full right = 14 kHz open. Deferred to user (by
ear): FILT sweep both halves, fade constants, faded part still fires
gates/CV/CHOKE windows, high RES+COMP at full left.

## MOD & TIDE — modulation surface split (2026-07-17)

Spec `docs/superpowers/specs/2026-07-17-mod-tide-design.md` (+ errata),
plan `...plans/2026-07-17-mod-tide.md`. Subagent-driven, commits
`140e0fd`..`3f49711` (base `a1dc9fc`), 263 doctest green, final Fable
review READY TO MERGE (the 1 Important was a spec defect, resolved as
errata commit `3f49711`). Delivers "modulation first": MOD (ex-DEPTH, per
deck) now scales only the 4 texture lanes + FX targets (`Part::target_raw`
exempts LANE_PITCH); RANGE = melody ambitus only; TIDE (new global center
knob right of MORPH, default 0.5 = bit-identical) scales texture-lane rate
¼×–4× via `_tide_mult`; synced → 9-rung reciprocal ladder `kTideRatios`;
REV_MOD label → WOBL; VCV init defaults = old RANGE·DEPTH products (A 0.78,
B 0.236); plugin 2.4.0 built+installed.

**Play-test revs:** (1) LEVEL floor (commit `921ec81`) — `target_raw`
clamps LANE_LEVEL to ≥ `kLevelFloor`(0.4)·base. (2) Boot-targets (spec
`2026-07-17-boot-targets-design.md`, commit `1315319`) — `_active` boots
all-true (was PITCH+LEVEL only; root cause of "MOD reads as tremolo" in
VCV), `_tdepth` staggered boot {SOURCE 1, SIZE 0.55, PITCH 1, MOTION 0.7,
LEVEL 1}. Suite 266/266. **RELEASED 2026-07-17 as v2.4.0** (fork pushed +
tag, CI success, all 3 assets live; website downloads + diary updated).

### Step-clock — STEPS/Tempo decoupled (2026-07-17)

Spec `docs/superpowers/specs/2026-07-17-step-clock-design.md` (+
`_ev_phase` errata), plan `...plans/2026-07-17-step-clock.md`. Subagent-
driven, commits `4442794`+`052849f` (base `63d08c5`), 272 doctest green,
final Fable review READY TO MERGE. STEP mode runs RATE as a step clock with
8-step reference: `cycle_hz = rate_hz·8/steps`; at 8 steps factor exactly
1.0 = bit-identical to before. Composes multiplicatively with
COUPLE/DRIFT/TIDE/lane ratios.

**Rev. 2 bugfix (commit `e4edf87`)** after a Rack test found SYNC still
following STEPS: `Center::_grid_servo` was targeting `beats×cpb`,
overpowering the step-clock. Fix: `ModLane::clock_scale()` (8/steps STEP, 1
FLOW) scales the SYNC servo target AND the free-world grid-gravity phase
target. Suite 273/273. **Rev. 3 (commit `5dbad12`)** after another Rack
test: live-STEPS turns briefly sped/slowed the loop under SYNC — the grid
servo targeted total-steps mod NEW count while `set_step()` preserved local
position. Fix: `Center::_rebase_grid()` rebases a per-bank offset onto the
lane's phase on a clock_scale change. RST is now also the bar resync
(`Instrument::reset_transport()` clears grid offsets + calls
`SuperModulator::reset_phases()` — snap instead of servo drag). Suite
276/276.

## Chord layer — COLOR knob (spec 2026-07-17, implemented 2026-07-17) — M4.10

Spec: `docs/superpowers/specs/2026-07-17-chord-layer-color-design.md` (rev
with fork commits `2ca6ed0`+`4e4c902` perf-review amendments), plan
`docs/superpowers/plans/2026-07-17-chord-layer-color.md` (commit
`d04d8e7`). Implemented subagent-driven: commits `ac65350`..`5452c2a` (10
commits), all 7 tasks + final Fable review + fix. Suite 311/311 (6.54M
assertions).

**COLOR-0 bit-identity gate PASSED post-fix:** 4 baseline renders
byte-identical (demo_step_melody, ambient_wash, demo_density_sweep + a 4th
FLOW/overlap scenario `chord_baseline_flow.json` that lived only in the
session scratchpad). Delivers: `engine/pitch/chord.h` ChordBuilder (zones
w/ hysteresis .02, additive ladder root/fifth-down/third/seventh, ninth
swap at .85, voice-leading lay search ≤27 candidates, exact-root
passthrough); `IPartEngine::trigger_chord`/`set_chord` defaulted virtuals;
SynthEngine STEP stabs (seeded ≤8 ms micro-offsets, 1/sqrt(n) vel w/ slew) +
FLOW multi-sustain surface; Part wiring; VCV COLOR_A/B knobs appended last
(patches compatible, default 0), plugin 2.4.1 rebuilt+installed.

**Final-review catch (empirically confirmed):** collapse→re-bloom steal
cannibalized a sustaining surface voice → whole-surface re-attack; fixed
`5452c2a` (steal prefers oldest non-sustaining + n<1 guard, regression test
RED→GREEN).

### COLOR as a MOTION target (2026-07-18, extends M4.10)

Spec `docs/superpowers/specs/2026-07-18-color-motion-target-design.md`,
plan `...plans/2026-07-18-color-motion-target.md`. Subagent-driven, 3
commits `eabaee6`..`f5230b6` (base `512aad5`), suite 318 cases / 6.586M
assertions, Opus final review READY TO MERGE. MOTION becomes COLOR's third
destination (`kColorMod = 0.2f`, `kColorGate = 0.01f`, ear-tunable). Bipolar
additive (not multiplicative) so reach stays constant across the knob
range. No new surface at all: git diff over lane_id.h, instrument.h,
host/vcv/, chord.h and res/ is empty.

**Two plan defects caught in-flight:** (1) the spec's own test probe
`COLOR = 0.005` is arithmetically impossible (gate halves the swing;
2-note edge sits at 0.145) — plan probe corrected to `0.02`. (2) the plan
told a task to `git add renders/*.wav|csv`, but `/renders/` is
`.gitignore:11` — implementer substituted direct hash/byte proof instead
(stronger than the plan's `git diff --stat`, which would have silently
false-negatived on a gitignored path). **Compatibility note:** every saved
`.vcv` patch with COLOR > 0 now sounds different on reload, since
`_active[LANE_MOTION]` boots true and `_depth` boots 1.0. Deferred to user
(listening pass, engine builds only, was never heard): FLOW bloom/collapse
at COLOR ~0.35/~0.6, level pumping on sustained pads, is `kColorMod = 0.2`
the right reach, COLOR ~0.85 ninth-flip musicality, COLOR ~0.02 occasional
dyad.

## M5 sampler spec redone (2026-07-18)

New spec `docs/superpowers/specs/2026-07-18-sampler-texture-deck-design.md`
(commits `c516b0a`+`e8e066e`); the residency-repo 2026-07-12 sampler-adapter
spec is banner-superseded (residency commit `05088ab`) — its slice-player
trigger model was dead. Key decisions: sampler = granular cloud (texture,
not a second melodic instrument); live input first (IN L/R wired through
`Instrument::process`), WAV second; PITCH quantized + chord cloud (grains
round-robin over COLOR's chord notes); MOTION = scatter macro order→chaos;
STEP = groove-gated bursts; panel = per-part ENGINE switch (SYNTH/SMPL) +
latching REC button w/ LED; architecture B = fresh 8-grain scheduler +
verbatim-copied `Buffer` record core; 42 s stereo injected buffer per part;
synth-neutrality bit-identity gate (counterpart of the COLOR-0 gate).

**Critical-review amendments (commit `b6be79b`, 4-question pass):** (1) the
per-part ENG pad already existed (latched Synth↔Test tone) — remapped to
Synth↔Sampler, test tone moved to a context menu; only REC button+LED is
new panel surface. (2) voice row remapped so no knob goes dead on a
sampler part (ATK/DEC = grain-window halves, FILT/RES = one stereo Svf,
SUB = octave-down grain share, DTUN = per-grain cents spread). (3)
play-while-recording: fill-follows in the record path. (4) factory sample
auto-loads on switch-to-sampler with an empty buffer, never overwrites
content. (5) honest SDRAM caveat: scattered grain reads bypass cache,
sampler tops the hardware-benchmark list. Plan deliberately not written yet
at spec-approval time — user decided to write it in an Opus session.

## Bench firmware (spec 2026-07-18, executed 2026-07-18)

Spec `docs/superpowers/specs/2026-07-18-bench-firmware-design.md`
(commit `be30496`). Standalone `bench/` app (own main+Makefile, libDaisy
pattern, links engine/+third_party/+full DaisySP — bench never ships so
LGPL is fine; `src/` untouched). 3 workload families: (1) own system
decomposed, (2) DaisySP expansion candidates per voice vs a MorphOsc-voice
reference anchor, (3) SRAM-vs-SDRAM A/B (8-grain scattered-read proxy for
M5 risk, Oliverb 128 KB placement, shortened echo window). Hybrid method:
offline DWT enumeration (budget = 2 ms/960k cycles @ block 96/48 kHz — not
460800, a self-review-caught arithmetic error) + audible in-callback anchor
mode via CpuLoadMeter. Per-workload output checksums defeat DCE and prove
cross-run determinism. `bench/run.py`: one command builds, flashes via the
user's debug probe (openocd, prefer RAM-load), captures RTT, writes a
committable `docs/bench/YYYY-MM-DD-<hash>.md`+`.csv` with a go/no-go
verdict. Plan executed on `main` 2026-07-18.

## CPU hunt round 1 — mod-plane cut + ablation family (2026-07-19)

Merged FF from branch `cpu-hunt` into local `main`, 7 commits
`20af2b5`..`55c1cda`. Both plans in `docs/superpowers/plans/`
(`2026-07-18-mod-plane-optimization.md`, `2026-07-18-bench-ablation-family.md`
— the latter carries its `## Outcome`). Final Fable whole-branch review:
Ready to merge, zero Critical/Important. Delivers bench families `mod` (7
rows) + `abl` (14 rows); one engine edit (`waveforms.h wave_sine` →
`fast_sin`). Mod plane 33%→26% of budget (prediction ~17% fell short — the
per-lane sine-call estimate was too high; real saving ~66 cyc/lane/sample);
`instrument_worst` ~159%→~151% (avg; 156% max); budget now closes with a
7.8%-of-budget residual attributed to additive stacking.

Closure findings: Part glue = 112820 cyc/part (~23% of budget for both
parts, the single biggest cut target); FLUX coupling measured NEGATIVE
(solo rows overestimate composition); tanh ≈60% of FLUX's solo delta; GRIT
Reduce +78% vs Drive; CHOKE tax + driven-limiter tax both measured.

**Gotchas carried from this round:** `util/fast_sin.h`'s header comment
still claims "~10–15 cycles" — empirically ~50–65 at these call sites
(never fixed, a cheap follow-up flagged); `docs/bench` keeps exactly one
committed result pair at a time, so historical Outcome citations dangle by
design; `run.py` names result files by HEAD hash, so measuring before
committing mislabels them — always commit code before measuring; one-time
icache layout shifts of ~7% on small rows appear when a new translation
unit links in — same-run-only arithmetic is the defense.

## CPU hunt round 2 — independent audit + mod-plane control-rate (2026-07-19)

On branch `cpu-hunt` (shared working tree with a parallel part-glue
session; commits interleave). Independent audit ranked further findings:
(1) mod plane to control rate (~22-24 pt ceiling), (2) FLUX feedback cap
≤0.95 → delete `std::tanh` outright (~8 pts, kills the bloom feature —
needs its own spec + listening decision), (3) global voice cap 6-of-8 (~9
pts worst case), (4) DaisySP `Svf` is double-sampled (single-pass LP-only
≈2-4 pts), (5) osc B ≈ duplicate of osc A at TIMBRE≈0 (conditional skip
~⅓ voice cost).

**4 hygiene commits landed:** `7e9f924` DeLine kMaxSamples 240000→262144 +
explicit AND masks; `8723bc5` one shared L/R delay-time slew in Flux;
`f88501a` Comp curve cache (update only when the OnePole moved); `7ea004b`
Oliverb random LFOs on the /32 raster + linear interpolation on the 4 input
diffusers + 2 static loop APs. First three proven byte-identical on 4
renders; the reverb cut changes references (tails decorrelate; 0.5 s RMS
envelopes agree 0.2 dB mean / 1.4 dB max) — renders NOT re-cut, held for
the user's listening pass. Suite 319/319 green.

**Hardware bench measured** (`docs/bench/2026-07-19-c7f6a73.md`):
`instrument_worst` 150.8/156.4 → 117.4 avg / 123.1 max offline, anchored
118.4/123.2 — total −33 pts but still over budget. Row deltas vs `9be5df9`:
`part_glue_flow` 29.92→19.86, `oliverb_solo_sram` 19.44→9.52 (halved),
`fx_flux_sdram` 10.28→10.16, `mod_plane` 26.4 unchanged (expected — its cut
hadn't landed yet).

**Mod-plane control-rate cut: commits `095ef2a`..`94468af`.** Spec
`docs/superpowers/specs/2026-07-19-mod-plane-control-rate-design.md` + plan,
subagent-driven, final Fable whole-branch review READY TO MERGE (0
Critical/Important). Approach C: 4 texture lanes/part advance via new
`ModLane::tick()` (boundary replay in phase order, exact OnePole compound
coefficient); PITCH lane stays per-sample — fires/gates/pitch_cv
bit-identical, no PITCH/groove/CHOKE/center test touched. Permanent
per-sample-vs-tick equivalence suite (9 `tick:` cases). 333/333 green,
`ctrl_identity.sha256` re-pinned. Accepted asymmetries (spec'd):
engine-swap and RST leave texture lanes ≤95 samples stale/skewed until the
next tick. Measured saving ~17-19 pts as predicted (see the release entry
below for the final measured figure).

## CPU hunt CLOSED + released as v2.6.0 (2026-07-19)

`cpu-hunt` fast-forwarded into `main` (42 commits, HEAD was `69d674b`),
`plugin.json` 2.5.0 → 2.6.0 (minor: COLOR/MOTION + the control-rate rework
change behaviour, not just speed), tag `v2.6.0` pushed, CI green, GitHub
Release carries win-x64 / mac-arm64 / lin-x64. Branch `cpu-hunt` deleted.

**The fast-tanh listening pass CLEARED** (both named targets checked by
ear: echo bloom at max feedback and master DRIVE high — neither audible),
recorded in `docs/roadmap.md` and the fast-tanh spec's Outcome (commit
`507f0e0`). Final measured state: anchored max 97.69%, under the 100% gate
for the first time, margin 2.3 points — GRIT Reduce alone would eat ~2.2 of
it, so the remaining ranked cuts should be held as margin, not spent.

Still open at that point: the residency website's per-platform download
links pointed at 2.5.0 (user's own follow-up); the older per-milestone
by-ear backlog; the M4.9/M4.10-era "VCV Rack play test + audio listening
pass deferred" notes in `docs/roadmap.md`.

## DUST/ROT — rhythm-fed delay taps (2026-07-20, released v2.7.0)

Merged FF into `main` (52 commits), pushed, `plugin.json` 2.6.1 → 2.7.0
(minor: both knobs changed meaning, saved patches sound different), tag
`v2.7.0` pushed, CI green on all four jobs. Branch `dust-explore` deleted
locally and on origin. Spec `docs/superpowers/specs/2026-07-20-rhythm-fed-delay-taps-design.md`
(rev 2) + plan.

**The DUST grain cloud was CUT** — it failed the listening gate twice. The
diagnosis both revisions missed: evenly spaced taps ARE a delay (zone S
played 2/4/8/16 equal slots per beat is a short delay by construction,
however precisely gridded). Rev 2 adds the missing half: a groove is an
unequal spacing that repeats. Replaced by `TapBank` — two read taps on the
FLUX tape whose offsets are the sample distances between the last onsets
of the OTHER bank's PITCH lane, latched once per that lane's cycle.
`derive_offsets` guarantees non-uniformity by rule (uniform gaps get spread
by the MOTION lane's ×3/4) plus an exhaustive property test. No beat anchor
needed: `DeLine::Write` decrements, so a constant offset behind it is 1×
forward playback — the fact that killed the earlier revision is the
mechanism here; `Center::beat_edge`/`beat_samples`, `Flux::sync_beat` and
the seed chain were removed. DUST = tap morph (accent hierarchy), ROT =
spectral spread (0 = deliberately delay-like). New:
`engine/fx/taps.{h,cpp}`, `engine/mod/rhythm_view.h`, an onset ring on
`SuperModulator`. 384 cases green.

**Key play-test fact:** both banks boot in FLOW where onsets are cycle
wraps, so gaps are uniform and the guard always fires — irregular tap
placement needs the partner bank in STEP with DENSE < 1. The knob that
shapes the figure is the other bank's DENSE/STEPS, not DUST. DUST is also
inert (~2.6 s at default rate) until the partner publishes a valid rhythm.

**Bench measured** (`docs/bench/2026-07-20-5d53901.md`): `instrument_worst`
93.37/98.61, `instrument_worst_taps` 99.92/106.00. Taps cost +6.55/+7.39 for
both parts. User accepted being over budget at worst case — deliberate,
not to be reopened unprompted. Two measured optimisations landed after a
+3.5-point baseline regression was traced (`TapBank::active()` scanning
cold taps per sample = 1.73 pts; the onset ring living on all 10 lanes =
0.93; layout 0.81): recovering 2.77. Caveat: code layout alone moves
`instrument_worst` by ~0.8 points — it read 92.61 and 93.37 across two
commits differing only in comment text plus an added bench row.

## Spotymod faceplate redesign (2026-07-18/19, plugin.json bumped to 2.5.0, not pushed/tagged)

Spec `docs/superpowers/specs/2026-07-18-spotymod-faceplate-redesign-design.md`,
plan `...plans/2026-07-18-spotymod-faceplate-redesign.md`. Subagent-driven,
commits `0dd1483`..`d6c0d4f` (7 tasks + 2 test-guard fixes + Opus final
review). Panel-only: no DSP/parameter/behavior change, and the enum
ParamId block is byte-identical to the pre-redesign commit, so every saved
`.vcv` patch still opens. Explicitly drops the old hardware-reducibility
rule for the VCV panel specifically (all controls exposed on the panel;
the hardware shortlist comes later from live play). Delivers a 9-knob
sector orbit (MOTION/TIMBRE/PITCH, COLOR promoted from satellite into
PITCH), one shared fieldset style across VOICE|FX|PLAY per part, 5 jack
groups. Architecture: `PanelCtl` carries absolute label position/anchor/
size/colour + a `tip` column — the duplicated `glyphR` table in
Spotymod.cpp was deleted so the SVG preview and Rack runtime cannot drift.
New `res/test_panel.py` guard script freezes the enum order + geometry.

**Lesson worth carrying: two guards in that file were vacuous on
arrival** (asserted on strings the generator never emitted —
`width="42.000"` vs `42.0`, collar `r+1.0` vs `r+0.85`); both found by
review, fixed, and each fix proven falsifiable empirically. Always
red-prove a new guard. Dev-diary entry "Infinitely many knobs" published.
Deferred to user: the 4 live Rack checks (label legibility, group legends,
loading a pre-redesign patch, jack tooltips); tag `v2.5.0` is the user's
call.

## M5a — Sampler texture deck + generous parameter ranges (2026-07-21, merged commit `499e5a7`; pushed and released 2026-07-22 in v2.8.0)

Two specs, both in the fork: `2026-07-18-sampler-texture-deck-design.md`
(the deck) and `2026-07-21-sampler-generous-ranges-design.md` (the
ranges). Merged into `main`, `--no-ff`, 53 commits. 481 doctest green;
synth neutrality and determinism byte-identical. `plugin.json` stays 2.7.0,
no tag.

The ranges spec's governing rule — **a ceiling stays only if it prevents
an actual failure, never merely an unpleasant sound; where opening a path
lets it diverge, add the bounding nonlinearity the instrument already
has** — is Bastian's stated philosophy for the whole instrument, not just
the sampler (the hardware-reducibility constraint still binds the panel
independently of this rule).

**Things flagged as would-bite-next-session at the time:**
- Neutrality-gate methodology: byte-identity comparison against an older
  commit requires a matching `CMAKE_BUILD_TYPE`; a Debug-vs-Release
  mismatch once reported all 8 scenarios as "moved" — a false alarm that
  cost a cycle.
- Resonance moved DOWN to 0.90, not up. The inherited 0.95 was already
  unstable under a swept cutoff; 0.90 is a headroom limit, not a
  divergence limit — only 1.0 diverges. Not to be "restored" to 0.95.
- The tape grain-length clamp (`lenf <= _spawn_every * kGrains`) is not
  free: in a sparse pattern it trims a grain that would have sounded
  (45.6 min → 84 s). Grain-stealing is the alternative if a listen ever
  disagrees; it is a no-op in digital mode only because
  `kGrains == 2*kOverlap` today.
- MOTION/fog: `kScatterPosFrac` moved from 0.25 to 1.0. This is NOT one of
  the three options the 2026-07-18 spec had left open — it is a fourth,
  genuinely new lever. Earlier work had hunted fog in grain length and
  never questioned the position range.
- A claim that did not survive measurement: the old grain pool was NOT
  starving (1 dropped spawn in 5962). The density rise to `kOverlap=8`/
  `kGrains=16` rests on cost and headroom alone, not on a starvation fix.

**M5b (VCV host binding)** is next and had no plan yet as of this entry.
Three findings from M5a it must carry: the ~32 MB sampler buffers must be
heap-allocated (the VCV module holds echo buffers by value); `reinit()`
runs on every sample-rate change and would discard a loaded sample; and
`host/vcv/Makefile` was never build-tested (no Rack SDK at the time), only
diffed line-for-line against CMake. Also needs: ENG remap to
Synth↔Sampler, REC pad + LED via `gen_panel.py`, `dr_wav` vendored,
`dataToJson`/`dataFromJson` from scratch, factory sample + autoload.

## M5b — Sampler on the VCV panel (2026-07-21, branch `sampler-vcv`; merged into `main` and released 2026-07-22 in v2.8.0)

Plan `docs/superpowers/plans/2026-07-21-sampler-vcv-binding.md` (9 tasks,
subagent-driven, one implementer + one independent reviewer per task,
stop-on-failure). Commit range `35e7b2a`..`ee232f8` (15 commits, not the 14
an earlier draft of this entry claimed — recounted with `git rev-list
--count`) on top of the M5a merge; `plugin.json` stays `2.7.0`, not tagged,
not pushed, per the
plan's global constraints. Makes the M5a texture deck reachable and playable
from the plugin: ENG (per part, latched) now selects Synth ↔ Sampler; REC
(per part, latched) records from IN L/R into that part's buffer with an LED
that pulses while recording and shows fill level otherwise; a right-click
**Sampler A/B** submenu carries Load/Save/Clear, Speed mode (Digital/Tape),
Reverse, Overdub feedback, and the dev-only test-tone escape hatch; a factory
sample (Bastian's own recording, `res/factory.wav`) autoloads on the first
ENG flip into an empty part; and a recorded or loaded texture now survives
patch save/reopen via new `dataToJson`/`dataFromJson`. `host/render/`'s
`wav_reader.h`/`wav_writer.h` moved to `host/shared/` so both hosts share one
WAV implementation.

**Two deliberate deviations from the 2026-07-18 spec, decided in the plan:**
1. **Reuse the repo's own WAV reader/writer instead of vendoring `dr_wav`.**
   The spec (written before M5a) called for a vendored `dr_wav`; M5a had since
   shipped a hand-rolled, hardened `wav_reader.h`/`wav_writer.h` (every
   declared chunk size validated against remaining file bytes, covered by
   `tests/test_wav.cpp`, handling 16/24/32-bit PCM, float and
   `WAVE_FORMAT_EXTENSIBLE`) — vendoring a second implementation would add a
   dependency and a second code path for no gain.
2. **Sample-rate change: snapshot and restore, not `restore()`.** The plan
   originally assumed (per the spec's silence on the question) that a
   `SampleBuffer::restore()` could cheaply re-declare a buffer's frame count
   after a rate-driven re-init. **That premise is false and was caught by the
   implementer's own Task 1 test failing**, not by review: `init()` ends in
   `clear()` (`sample_buffer.cpp:33` → `179-180`), which `memset`s the whole
   injected buffer — there is nothing left to re-declare. `restore()` was
   dropped from the plan entirely; the host instead reads content out through
   the new `sample_data()`/`sampler_rec_size()` accessors before `reinit()`
   and pushes it back afterwards with the existing `load_sample()`. Accepted
   consequence: the snapshot itself is **not resampled** (tape behaviour,
   matches the instrument's idiom), which is the deliberate opposite of what
   a fresh file *load* does (always resamples — an import at the wrong pitch
   would be a bug).

**Findings a later session would not re-derive from the code:**
- `onAdd` fires **before** `onSampleRateChange` in Rack v2.6.6. Not provable
  from the SDK, which ships headers only — Task 7's reviewer confirmed it by
  reading Rack's actual `Engine.cpp` on GitHub. This is why `onAdd` must force
  its own `reinit()` rather than assume the sample-rate callback will run
  first: the brief's literal code would otherwise have written into null
  sampler buffers.
- `dataFromJson` is called on an **already-added** module for preset load
  (`ModuleWidget::loadAction`/`loadDialog`) and clipboard paste
  (`pasteJsonAction`) — neither goes through `Engine::addModule_NoLock`, so
  `onAdd` never fires again for those paths. The restore flag has to be
  consumed defensively; leaving it unconsumed on that path is a real
  (UX-only) quirk, not data loss, still open at the end of Task 9
  (`factoryTried` isn't reset on a live-module preset load, so an
  already-autoloaded part can stay silent on reload until `onReset`).
- `Slider::quantity` is annotated `/** Not owned. */` in the Rack SDK
  (`include/ui/Slider.hpp:12-14`) — a widget (`FeedbackSlider`) owning and
  destroying its own `Quantity` is therefore correct, not a double free; a
  reviewer's initial suspicion to the contrary was wrong and worth recording
  so it isn't relitigated.
- Persistence originally lost a recording made **over** a loaded file:
  `onSave` skipped any part with a non-empty `path` (on the theory it can
  reload from that file), but nothing cleared `path` when the user then
  REC'd over it — reopening silently discarded the live overdub and restored
  the original file instead. Overdub is a feature (default feedback 0.95),
  so this was a likely workflow, not an edge case. Fixed in `466c601` by
  clearing `path`/`factoryLoaded` the moment a recording actually starts
  (already documented in `Spotymod.cpp`'s REC-push comment).
- Task 3's brief predicted panel param ids 78/79 and `NUM_PARAMS` 82 for
  REC_A/REC_B; the real generator output was 76/77 and `NUM_PARAMS` 78 — an
  explorer's earlier wrong "80 params" count had been propagated without
  recounting. The implementer reported the mismatch instead of bending
  `gen_panel.py` to match a wrong prediction; `res/test_panel.py`'s
  `test_lower_half_positions` fixture needed updating for the same reason
  (the REC pad's insertion re-spaced ENGINE_A/GRITMODE_A/STEPS_A on the PLAY
  row).
- The REC LED's fill-level branch originally didn't check the part's engine
  at all: record on a Sampler part, flip ENG to Synth, and the LED stayed lit
  at the fill level on what the user now reads as a plain synth voice —
  contradicting the plan's own prose ("REC on a synth part is inert with a
  dark LED"). The record *button* was correctly gated; only the *light*
  wasn't. Fixed in `4948ec0` by gating the fill branch on the same `eng2 &&
  !testTone` condition `pushParams` already uses.
- The factory-sample first-use path originally read and decoded
  `res/factory.wav` from disk on the audio thread, on the first ENG flip —
  accepted as "low tens of ms, once" in the plan, then reviewed as a real
  ship risk (a cold-file or AV-scanner read is not bounded, and a click on
  the very first "it just works" gesture is the worst place to spend one).
  Fixed in `ee232f8`: disk read + decode moved to `onAdd()` (main thread,
  before `process()` ever runs for the instance), leaving only the
  already-decoded buffer's resample-to-current-rate in the reactive path.

**Task 9 close-out (this entry):** 484/484 doctest cases green (481 M5a
baseline + Task 1's 3 new accessor-coverage cases). Synth-neutrality gate:
the 8 pinned non-sampler scenarios (`ambient_wash`, `assets_percussive_source`,
`chord_bloom`, `ctrl_identity`, `demo_density_sweep`, `demo_step_melody`,
`reverb_delay`, `reverb_wash`) rendered byte-identical between `HEAD`
(`ee232f8`) and a `git worktree` pinned at the pre-M5b commit `35e7b2a`, both
configured `CMAKE_BUILD_TYPE=Debug` to match the existing `build/` tree
(see the CMAKE_BUILD_TYPE warning above — a Debug/Release mismatch is a false
alarm, not a real difference); `ctrl_identity.wav`'s SHA-256 also matches the
repo's pinned `ctrl_identity.sha256` independently. Determinism gate:
`sampler_texture_deck` and `sampler_extremes` each double-rendered
byte-identical. Structural corroboration: `git diff 35e7b2a..ee232f8 --
engine/` touches only `engine/instrument.h` and
`engine/sampler/sampler_engine.h` (Task 1's two read-only accessors) — no
other engine file moved. Cold plugin build (`rm -rf host/vcv/build
host/vcv/dist`, WinLibs MinGW-w64 g++ via an MSYS2 `make`, Rack SDK 2.6.6)
succeeded for both the default and `dist` targets; the produced
`Spotymod-2.7.0-win-x64.vcvplugin` contains `res/factory.wav`, and
`plugin.json` still reads `2.7.0` and is untouched in the working tree.

**Final whole-branch review — three blockers fixed on top of `62d9fd0`:**
1. **I-1, Clear sample didn't survive save/reopen (two causes).** `onSave`
   skipped writing a part with nothing to record, but left any WAV that an
   *earlier* save had written for that part sitting in patch storage — Rack
   garbage-collects patch storage per module, not per file, so a Clear ->
   Save -> reopen reloaded the deleted recording right back.
   Separately, `factoryTried[p]` was never persisted, so the same sequence
   reset it to its construction-time `false` and let the factory drone
   autoload into the freshly-cleared part on the first control tick after
   patch open, with no user gesture at all.
2. **I-2, a live preset load or module paste left stale audio playing.**
   `restoreSamplerContent()` was written for the fresh-add path, where
   `reinit()` has already zeroed the buffer, and had no branch for "neither
   a file path nor a stored WAV exists" — on the already-live path (preset
   load, Ctrl+V) the buffer kept whatever it held before, while the menu,
   the JSON and the REC LED all described the new (empty) preset.
3. **I-3, the factory autoload could stall the audio thread.** `load_sample`
   begins with `SampleBuffer::clear()`, which unconditionally `memset`s the
   whole 42 s allocation (16.1 MB) — roughly 1.5-3 ms inside one `process()`
   call against Rack's 5.3 ms budget at a 256-sample block, worse at 128/64,
   and reachable from the audio thread by the factory-drone autoload path
   (including, per I-1's second cause, at patch open with no user gesture).

Fixed together in `6137017`: `onSave` now deletes an orphaned stored WAV
when a part has nothing to write; `factoryTried` is persisted alongside
`factory` in `dataToJson`/`dataFromJson`; `restoreSamplerContent()` is now
total (`inst.sampler_clear(p)` + `factoryTried[p] = false` when neither
source exists, with the stored-WAV branch restricted to the fresh-add path
— `getPatchStorageDirectory()` is scoped to the *current patch*, not the
preset, so reading it on a live preset load would pull that patch's own
autosave into a preset that never asked for it); and `SampleBuffer::clear()`
skips its memset when the buffer is already empty (`_size == 0` going in),
which is provably safe (`init()` always ends in `clear()` before content can
exist, and `_size == 0` already means `read_linear()` returns silence
regardless of memory contents) and pinned by a new doctest in
`tests/test_sampler_engine.cpp` that inspects the raw buffer, not just
`rec_size()`, after clearing a buffer that had content. Verification re-run
in full because I-3 touches `engine/`: 485/485 doctest cases green (484 +
the new test), the same 8 pinned non-sampler scenarios still byte-identical
between `HEAD` and the `35e7b2a` worktree, `sampler_texture_deck`/
`sampler_extremes` still double-render byte-identical, and a cold plugin
build still links. Documentation fixes (this correction, the README's
persistence and memory-footprint claims) followed in a second commit.
Whole-branch commit range as of the fix commit: `35e7b2a`..`6137017`, 17
commits — recount before citing this number in a future session, since the
docs commit that lands after it adds one more.

## M5c — Morphagene control surface (2026-07-21/22, branch `sampler-controls`, merged `ec4f633`)

Spec `docs/superpowers/specs/2026-07-21-sampler-morphagene-controls.md`.
Turns the M5b deck from "a cloud with knobs" into a playable surface:
**DENS** makes grain overlap a runtime value (1..8) where it had been the
compile-time `kOverlap`; **SCAN** adds a running playhead with a real dead
zone at centre, an exponential lower segment so 1.0x realtime lands on a
findable knob position, and a fixed lag behind the write head while recording
(folding modulo content pins the head to the write head and the cloud goes
near-silent — that was found by test, not by ear); **NEW/punch** returns the
playhead to ORGANIZE and spawns immediately without killing what is already
sounding, which is what makes the long-grain end of SIZE playable at all.
LEN and ORG take over the SUB/DTUN knob positions in the sampler, so those two
stop reaching the deck entirely (`_sub_n`/`_detune_n` stay at 0).

**SIZE became live downward** (`63b7dd0`), from Bastian's own report: "wenn ich
len aufdrehe dann laeuft die Geschichte ja sehr lange, wenn ich len dann
wieder runter drehe aktualisiert er nicht die Laenge der laufenden Grains."
He was right and it was not a small window — at SIZE 1.0 a grain runs 42 s and
nothing on the panel could stop it. `Grain::trim_total` now lets the engine
shorten a running grain from outside; only shortening, so the drag-behind
character survives on the way up.

## Sampler bench family + the grain-count cap (2026-07-22)

**The bench had stopped linking** the moment `Part` began carrying a
`SamplerEngine`: `.bss` overflowed the 256K SRAM region by 6168 bytes and the
sampler sources were never in `CPP_SOURCES`. Fixed by adding an *additive*
`.sram_exec_bss` section to `alt_sram.lds` and moving the bench's 64 KB arena
into it. `SRAM_EXEC` and `SRAM` are the same physical AXI SRAM split by a
bookkeeping line, so no measurement condition changed; the shipping firmware
emits nothing into the new section and its map is unchanged (verified by
building it). `SRAM_EXEC` now sits at 93 % — the next overflow will be code,
and there is no third half.

Seven rows (`bench/workloads_sampler.cpp`) plus six ablations. Headline:
`inst_sampler_worst` ran 92 % of the block budget on the mean block and
**117 % on the worst**, where the same box on the synth ran 93 / 98.

**The first diagnosis was wrong, and the ablations are what said so.** It was
called a spawn burst; removing MOTION moved the peak by 0.3 points, and 75x
fewer spawns made the peak *worse* (141 %). The actual cause, counted exactly
rather than timed (`Grain::process` calls per 96-sample block, 1000 blocks):
the spawn *interval* carries MOTION's +-75 % jitter while grain *length* does
not, so short intervals stack grains — live count wandered 5..11 where DENS
asked for 8, spread 1.36x with the jitter and 1.01x without.

`kSpawnHeadroom` caps the live count at `ceil(overlap) + n`. Two traps it left
behind, both now in `bench/README.md`: an instrument-level `_nomotion` row
does **not** remove MOTION (`Part::_active` defaults to all-true, so zeroing a
target's base leaves its lane driving it — the first such row measured the
unablated peak and read as "not MOTION"), and after a cap a high peak-to-mean
ratio means a **low mean**, not a high peak.

Two consequences owned rather than designed away: `len_ceil` now measures the
*reachable* pool rather than `kGrains` (leaving it at `kGrains` dimensioned
grains for 16 live voices while the cap allowed 9, and the tape corner then
dropped spawns even at MOTION 0), and that shortens tape's downward smear —
a long tape grain **is** density, so both cannot be capped and let run.
Bastian chose `kSpawnHeadroom = 2` over 1 after seeing the trade table: four
semitones of tape smear instead of two, paying 1.18 instead of 1.14 solo
peak-to-mean. The table and the attribution live at the constant.

Also fixed on the way: dropping a spawn left `_spawn_jitter` frozen, so a
negative draw repeated its short interval until one got through — a symmetric
jitter turned into a one-sided **+3.5 % speed-up**, caught by the existing
F-01 test. Set to 0 rather than redrawn, because a redraw consumes an Rng
value and shifts the locked golden vector from the first drop on.

## CPU hunt round 3 (2026-07-22, subagent-driven)

Dispatched with the bench, the current numbers, the dead ends above, and the
methodology rules that came out of them. Found its consumers by **counting
call sites per block** against `setup_inst_worst`, not by timing. Three
removals, each measured before and after on the Seed:

1. **`engine/fx/part_fx.cpp:45` called libm `sinf` every sample** for the
   equal-power reverb-send law — 192 calls per block on the two-part
   instrument, about a third of the whole FX-off chain. `fast_sin` already
   existed and `fast_sin(v*0.25)` is exactly `sin(v*pi/2)`. -0.65 pp per part.
2. **`daisysp::Svf` computed five outputs to use one**, plus a provably-zero
   `drive*band^3` (both call sites `SetDrive(0.f)` once and never again), plus
   a `powf(res,0.25)` recomputed on every `SetFreq` although it depends on
   resonance alone. 768 calls per block. Replaced by `engine/util/svf_lp.h`,
   whose `Low()` is bit-identical to the original for every call sequence this
   engine makes (pinned by `tests/test_svf_lp.cpp` against the real
   `daisysp::Svf`). `synth_4_voices` -1.98 pp.
3. **Exact change guards** on `Env::set_times`, `MorphOsc::set_detune_cents`
   and `SvfLp::SetRes`, which were re-running `expf`/`powf` on unchanged
   inputs at control rate. -0.26 pp.

Measured (`docs/bench/2026-07-22-8668367.md`): `instrument_worst` 98.1 -> **93.7 %**
max, `instrument_worst_taps` 103.4 -> **99.2 %** (inside the budget for the
first time), `inst_sampler_worst` 113.1 -> **106.8 %** (still over),
`instrument_init` 74.7 -> 70.0 %. Anchored `instrument_worst` 98.1 -> 94.0 %.

**One test moved and it is a real trade:** the send-law test asserted against
libm at doctest's 1.19e-5 epsilon; `fast_sin` carries 1.2e-3, i.e. **0.009 dB**
on a reverb send. Epsilon widened to 2e-3 with the reasoning at the call site;
the mix-0 and mix-1 endpoint tests are untouched and still exact. 24 of 66
bench checksums moved as a result — expected when an approximation is swapped,
not a silent regression, and the `sampler_win_sram`/`sampler_win_sdram`
same-checksum invariant still holds.

**Two premises it checked and rejected** — both had been handed to it as
leads, and both were wrong. The "TapBank costs more in context than solo"
lead was an arithmetic error in the briefing (one bank solo, 3.49 pp, compared
against *two* banks in context, 5.29 pp — two solo would be 6.98, so the taps
are *cheaper* in context; there was no coupling to explain). And
`instrument_init` at 63 % is not a mystery but the sum of its parts.

Left as proposals because they trade something: `MorphOsc`'s `powf` -> fast
exp2 (~0.6 pp, but a tuning path), `Comp`'s `log10f`+`powf` (~0.4 pp), and the
sampler's remaining overrun.

## Released v2.8.0 (2026-07-22)

`plugin.json` 2.7.0 -> 2.8.0 (MINOR: the texture deck is new user-facing
capability), commit `5fdaafa`, annotated tag `v2.8.0`. `main` pushed to
`origin` (146 commits ahead — M5a, M5b, M5c, the sampler bench, the grain cap
and CPU round 3 had all been sitting local). CI green on all four jobs,
Release published with `win-x64`, `mac-arm64` and `lin-x64` assets.

Open at the release: the sampler's worst case is still 107 % of the block
budget against the synth's 94 %. The ablations put that on steady FX-chain
load rather than on the cloud — dropping either FLUX or the reverb from that
patch clears it — so it is a design decision, not a bug to chase.

## M5i — WAVE (2026-07-25)

Completed the four-voice PPG-style wavetable part engine after the hardware
bench gate. `WaveEngine` reuses the SYNTH allocation, FLOW/STEP, chord, CHOKE,
envelope, and voice-edit semantics, with `spky::SvfLp` retained bit-identically
from SYNTH. `ENGINE_SAMPLER = 2` remains stable and `ENGINE_WAVE = 3` is the
new engine ID.

The desktop renderer accepts `"wave"`; VCV ENG is now Synth → Sampler → Wave,
so saved values `0` and `1` retain their SYNTH and SAMPLER meanings. The
generated 16-frame, 7-mip bank is 65,024 bytes (32,512 int16 samples), linked
in `.qspiflash_data` at `0x90040000`. Keeping it in AXI SRAM overflowed that
region, while mapped QSPI passed the hardware CPU gate; no SDRAM boot copy was
needed.

The completed oscillator tests set alias energy at `<= -36.0 dB` across all
16 frames, both sides of every mip handoff, every coherent pitch through the
public `0.45 * sample_rate` ceiling, and that exact ceiling. The N/11 bake
guard retains 93, 46, 23, 11, 5, 2, and 1 partials while preserving the
16-frame, 7-mip, 65,024-byte layout. Adjacent-frame control-boundary residual
is `< 0.01`, active-mip retarget residual is `< 0.01`, and both position and
mip ramps remain exactly 96 samples. The final WAVE listening anchor,
`host/render/scenarios/wave_formant_sweep.json`, has SHA-256
`a2a2fdb22044a0554e08b4ce6145033a81f105d980bc3f125e01d7e5271dc651`; the
preserved SYNTH reference is
`659af928e1f273d9ba9619f9ad235844fec1c2277557ed81a0c2dc065c6eb336`.

Two full hardware runs recorded `synth_2x4` / `wave_2x4` average/maximum cycles
of `340347 / 346106` / `308497 / 312180` and `340342 / 346105` / `308503 /
311962`, respectively. WAVE is no slower than SYNTH in both runs and its
maximum is below the 960,000-cycle block budget. The accepted captures have
identical unique 68-row sets and checksums and report the byte-verified QSPI
payload digest
`ac234ac7f7540ed5cd0e8b8496b84fca8084a3b2c05cc513aa4dad8ed811fc27`.
Evidence: `docs/bench/2026-07-25-8c5f2e1.md` and
`docs/bench/2026-07-25-8c5f2e1.csv`.

## Renamed spotymod → FireFlow (2026-08-04)

The second public rename of this repository, after `Spotykach` → `spotymod`
(recorded above). Same day as the two changes that made it necessary: the
project left the Synthux residency and dropped the Spotykach hardware port, so
a name built on `Spotykach` no longer described anything.

`Firefly` was the first candidate and was rejected: ZetaCarinae already ships a
module of that name in the official VCV Library, and it is a phase-coupled
oscillator — the same conceptual corner as this instrument's Kuramoto COUPLE.
`FireFlow` keeps the image without the collision; no plugin in the VCV Library
manifest carries `fire`, `flow` or `fly` in its name. A `mod`-based name was
considered first and dropped once `MOD` turned out to be a printed panel
caption of its own.

**Clean slug break, deliberately.** Plugin and module slug both go
`Spotymod` → `Fireflow` rather than keeping the old slug behind a new display
name. Existing VCV patches containing the module lose it. Accepted because the
plugin is not in the official VCV Library, is distributed only through GitHub
releases, and carrying `Spotymod/` in every install path forever was judged the
higher cost. Version bumped to 2.19.0; release assets change from
`Spotymod-*.vcvplugin` to `Fireflow-*.vcvplugin`, and releases up to 2.18.x keep
the old name.

Mechanical scope: 31 live files, `Spotymod`→`Fireflow`, `spotymod`→`fireflow`,
`SPOTYMOD`→`FIREFLOW`, plus `git mv` on `host/vcv/src/Spotymod.cpp` and
`host/vcv/res/Spotymod.svg`. The wordmark is monospace on a centred anchor and
both names are eight characters, so the faceplate needed no relayout. The 314
archival files under `docs/bench/`, `docs/superpowers/`, `docs/audits/` and
`.superpowers/` were left untouched, as were the dated provenance notes in
`third_party/oliverb/` and the historical release names in this file and in
`docs/roadmap.md` — at those dates the project really was called that.

## EDGE knob removed (2026-08-20)

DPTH and EDGE shipped together 2026-08-19 (spec/plan
`2026-08-19-voice-knobs-dpth-edge`), each a VOICE knob broadcasting to all six
engines. A listening pass on EDGE (`docs/by-ear-decisions.md`) found its
negative half inaudible at neutral (≤0.08 dB at 55 Hz) and its positive
extreme worth only ~5 dB off a 110 Hz fundamental — the knob did not earn its
panel space. Plan `2026-08-20-edge-knob-removal` took it back out across
six tasks: both VCV panels, `P_EDGE_A`/`P_EDGE_B`, `Instrument::set_voice_edge`
/ `Part::set_voice_edge`, all six per-engine cells including
`engine/util/onepole_hp.h`, the bench workload built to price its filters, and
this paper trail. DPTH was untouched and stays on all six engines; the VOICE
slot EDGE occupied is free space, by decision, not re-flowed.

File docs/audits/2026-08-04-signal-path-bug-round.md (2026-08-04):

# Signal-path bug round — 2026-08-04

**Date:** 2026-08-04
**Status:** findings 1-4 + the DRIVE-smoothing observation fixed, merged to main, released as v2.18.2 (plan `docs/superpowers/plans/2026-08-04-signal-path-declick.md`); listening sign-off given 2026-08-04
**Scope:** the audio path from `Part::process` through `PartFx`
(GRIT → FLUX → FX MIX → COMP → send tap) into `Instrument::process`
(MORPH → bloom duck → reverb send/return → master limiter).
**Baseline:** 59e6dcd (`chore(release): bump plugin version to 2.18.1`)

Everything below was **measured**, not inferred from reading. Each finding
names the probe that produced its numbers; the probe sources are in the
appendix so the numbers can be reproduced or refuted. No source file was
changed to obtain them — the probes link against the engine as it stands.

Four defects and a handful of observations. Findings 2 and 3 share one root
cause. Finding 1 has the widest reach and is the only undefined behaviour in
the audio path.

---

## 1. `SoftSwitch` is hardwired to 48 kHz — OOB read at 44.1 kHz, click at 96 kHz

**Where:** `engine/fx/fx_util.h:82-106` (`SoftSwitch::process`),
`engine/fx/fx_util.h:27-34` (`hann_value_at`)

`init()` scales the step size with the sample rate — `_kof = 1/(0.004·sr)` —
but the iterator bound in `process()` is the constant `191`. The two only
agree at 48 kHz, where 4 ms *is* 192 samples. Away from that rate the ramp
either overruns the Hann table or never reaches its end.

`hann_value_at` clamps `npos` but **not `ipos`**, so an overrun is a read past
the end of the 192-entry static table, not a saturation.

Measured rise ramp (probe `sw2.cpp`):

| sample rate | largest single-sample step | highest table index touched |
|---|---|---|
| 44100 | **0.917** (ramp ends at 0.726, then jumps to 1.0) | **205** — out of bounds on a 192-entry array |
| 48000 | 0.008 | 189 ✅ |
| 96000 | **0.508** (ramp only reaches 0.492) | 94 |

At 44.1 kHz the last ~14 ramp samples are whatever floats follow the table in
memory, clamped into [0,1] by `process()`'s return. At 96 kHz the ramp is
mathematically fine but stops halfway and steps the rest.

**Reach.** Every switched block in the instrument:

- engine change — `Part::_engine_fade`, `engine/parts/part.h:444`
- GRIT on/off — `Grit::_sw`, `engine/fx/grit.h:73`
- FLUX on/off — `Flux::_sw`, `engine/fx/flux.h:53`
- sampler cut/overdub — `SampleBuffer::_cut`, `engine/sampler/sample_buffer.h:65`

44.1 kHz is a common Rack setting, so on those hosts every FX toggle and every
engine switch both clicks and reads out of bounds.

**Prior contact.** This exact out-of-bounds read has already been hit once:
`engine/sampler/sample_buffer.cpp:24-32` records it ("reproduced as an
out-of-bounds assertion under the MSVC STL") and fixes the *call site* by
adding the missing `_cut.init(sample_rate)`. That repair is correct as far as
it goes, but it addressed an uninitialised `_kof` of 1.0. The bound bug
survives a perfectly correct `init()` at any rate below 48 kHz.

**Test gap.** `tests/test_fx_util.cpp:19` exercises 48 kHz only.

**Inherited, not introduced.** `src/core/softswitch.h:56` and
`src/core/hann.h:22-32` carry the identical construction. On the Daisy the
rate was fixed at 48 kHz, so it never bit; the VCV plugin is where it does.

---

## 2. FLUX fades the wrong side of the tape line

**Where:** `engine/fx/flux.cpp:155-182`

`const float send = _sw.process();` scales only what goes **into** the delay
line (`_echo_l.Process(l * send, samples)`). The return is added ungated:
`l += wet_l * _mix_lin`. When the ramp finishes, `if (_sw.is_idle()) return;`
removes the return in one step.

So the 4 ms anti-click ramp gates a signal that is already in the past, and
leaves the one that is actually audible untouched.

Measured at 48 kHz — where finding 1 does *not* apply, so this is the fade
working as designed — with MIX 1.0, FB 0.5, a 200 Hz tone for 1 s, then
silence (probes `flux_probe.cpp`, `flux_on.cpp`):

- **Switching FLUX off:** the echo keeps playing at full level for the whole
  ramp, then steps from **−0.476 to 0.000 in one sample** at i=191. That is a
  full-scale click the ramp does nothing to prevent.
- **Switching FLUX back on**, after the block sat idle through 10 s of
  silence: the first sample out is **−0.466**, peak 0.610 over the next 2000
  samples. While idle `_echo.Process` is never called, so the line is frozen
  rather than decaying — turning FLUX on replays the take from ten seconds ago
  at full level and the 0.5 feedback keeps it alive.

**Contrast.** GRIT gets this right — `engine/fx/grit.cpp:99` crossfades the
*output*: `l = gl*k + l*(1-k)`.

**Test gap.** Every FLUX test uses `set_on(true, true)` (immediate). The
ramped path has no coverage. `tests/test_grit.cpp:103` does cover GRIT's.

---

## 3. Reverb clear-on-sleep amputates the tail — same shape as finding 2

**Where:** `engine/instrument.cpp:279-292`

The per-deck wet gains glide to zero over `kMixSmoothS` (10 ms). The instant
`wga` and `wgb` are both exactly 0, the room is cleared and `process()` is
skipped from then on. As in finding 2, the fade rides the **send**; the
**return** is cut, not faded — and a reverb return at that moment is a tail
seconds long, not a residue.

Measured against the real `AmbientReverb` with `instrument.cpp`'s own gain
logic replicated exactly (probe `rev2.cpp`), input going silent at the same
moment the knob moves:

| DECAY | MIX | cut lands | return level at the cut |
|---|---|---|---|
| 0.55 | 0.25 | 66 ms after the knob | −19.7 dBFS |
| **0.75** | **0.50** | 72 ms after the knob | **−10.5 dBFS** |
| 0.85 | 1.00 | 76 ms after the knob | −30.2 dBFS |
| 0.95 | 1.00 | 76 ms after the knob | −29.5 dBFS |

The two loud rows are the ones to read; the quiet ones are phase accidents of
where the wash happened to be when the cut landed, not evidence that a long
DECAY is safer.

Turning REVERB MIX down therefore kills the tail with an audible step about
72 ms later.

---

## 4. The COMP ceiling fires at knob 0.001

**Where:** `engine/fx/comp.cpp:70-72`

```cpp
const float cap = kEnvCeiling / std::max(_env, 1e-6f);
if (_gain_target > cap) _gain_target = cap;
```

The cap is applied unconditionally. It is not scaled by `_curve_amount`, so at
knob positions where the compressor is meant to be doing nothing it still
enforces a −8 dBFS envelope ceiling.

Measured with a 220 Hz tone at peak 0.8 (probe `comp_probe.cpp`):

```
COMP 0.000 -> out peak 0.8000   ( +0.00 dB)    bypass, bit-exact
COMP 0.001 -> out peak 0.4505   ( -4.99 dB)    <-- the first 0.1 % of the travel
COMP 0.010 -> out peak 0.4504   ( -4.99 dB)
COMP 0.050 -> out peak 0.4492   ( -5.01 dB)
COMP 0.200 -> out peak 0.4417   ( -5.16 dB)
COMP 0.500 -> out peak 0.4243   ( -5.51 dB)
COMP 1.000 -> out peak 0.4090   ( -5.83 dB)    <-- the whole rest: 0.8 dB
```

And the way back out is a step, not a glide. `Comp::process`'s disengage
branch (`comp.cpp:76-83`) snaps `_gain` to 1.0 the sample `engaged()` turns
false. Riding COMP from 0.5 to 0 on that same tone:

```
largest one-sample gain jump 0.4546 (0.5454 -> 1.0000, +5.3 dB)
```

This is the curve failure the limiter's own comment describes for the old
linear DRIVE law (`engine/fx/limiter.h:30-38`, "spent the whole knob in its
first fifth") — here compressed into the first thousandth, plus a click at the
bottom stop.

**Reachable from the panel.** COMP is a real knob (`generated_panel.hpp:144`,
`:167`), init defaults 0.630 / 0.561 (`init_patch.hpp:36`, `:59`), pushed at
`Spotymod.cpp:488`.

---

## Observations — not defects, but worth knowing

**Master DRIVE is the one unsmoothed parameter in the path.**
`Spotymod.cpp:712` pushes it on the `ctrlDiv = 16` raster (`Spotymod.cpp:263`)
and `Limiter::set_drive` (`limiter.h:39`) writes `_pre` directly. `_pre` spans
1…4, so a knob sweep steps the master gain every 16 samples. Everything else
that reaches the audio path is smoothed — LEVEL (~10 ms in `SynthEngineT`), the
five FX targets (2 ms in `PartFx`), MORPH (30 ms in `Center`), the reverb dry/wet
legs (10 ms in `Instrument`). DRIVE is the exception.

**Three level riders in series on the same signal.** The reverb's return
ceiling (`reverb.cpp:182-196`), the bloom duck (`instrument.cpp:139-155`) and
the master limiter (`limiter.h:45-61`) all act on the same sum. The duck's
envelope is `AmbientReverb::return_level()`, which is `_wet_peak * _lim_gain`
— a level the reverb's own ceiling has *already* pulled down. The harder one
rides, the less the other has to do. Each is individually justified in its own
comment block; the interaction between them is not written down anywhere, and
it is the most convoluted stretch of the path.

**The master limiter has no lookahead, and at DRIVE 0 its knee is narrow.**
A 1.4-peak tone starting after a −26 dBFS wash (probe `lim_probe.cpp`):
**24 of the first 400 samples sit at |out| ≥ 0.999** — the first crest is
flat-topped for roughly 0.5 ms while the follower (attack coefficient 0.05,
τ ≈ 20 samples) catches up. At DRIVE 0 the knee is `kKneeHi = 0.891` with a
transition only 0.109 wide, so anything the follower has not yet seen is hard
clipping in all but name.

This is the documented design (`limiter.h:16-22` voices the knee morph as a
feature), and it is bounded — `shape()` can never exceed 1.0. Noted here
because it is the most likely source of a "it crackles on transients" report,
and because it interacts with the by-ear finding already recorded in memory
that master DRIVE stops controlling dirt once the limiter rides.

---

## Suggested order, if any of this gets fixed

1. **Finding 1** — the only UB in the audio path, and the widest reach.
   Clamping `ipos` in `hann_value_at` removes the UB but leaves the click:
   the iterator bound has to come from the sample rate for the ramp to be a
   ramp at any rate but 48 kHz.
2. **Findings 2 and 3 together** — one root cause (fade the return, not the
   send), two call sites. Fixing 2 without 1 leaves FLUX still clicking at
   44.1 kHz through a different mechanism.
3. **Finding 4** — scale the cap by `_curve_amount` so knob 0 is inert, and
   glide out of the disengage instead of snapping.

Nothing here is decided. Findings 2 and 3 in particular change how the blocks
sound when switched, which is an ear call, not a code call.

---

## Appendix: probes

Sources are in `2026-08-04-signal-path-bug-round/probes/`. Built against the
tree at 59e6dcd, no source changes. From the repo root, with `env.sh` sourced:

```sh
D=docs/audits/2026-08-04-signal-path-bug-round/probes
I="-I engine -I third_party -I lib/DaisySP/Source"

clang++ -std=c++17 -O0 $I -o sw2.exe        $D/sw2.cpp
clang++ -std=c++17 -O1 $I -o flux_probe.exe $D/flux_probe.cpp engine/fx/flux.cpp \
                                            lib/DaisySP/Source/Utility/dcblock.cpp
clang++ -std=c++17 -O1 $I -o flux_on.exe    $D/flux_on.cpp    engine/fx/flux.cpp \
                                            lib/DaisySP/Source/Utility/dcblock.cpp
clang++ -std=c++17 -O1 $I -o rev2.exe       $D/rev2.cpp       engine/fx/reverb.cpp
clang++ -std=c++17 -O1 $I -o comp_probe.exe $D/comp_probe.cpp engine/fx/comp.cpp
clang++ -std=c++17 -O1 $I -o lim_probe.exe  $D/lim_probe.cpp
```

- `sw2.cpp` — `fx_util.h` only. Runs `SoftSwitch` at 44100/48000/96000 and
  reports the largest single-sample step of the rise ramp.
- `flux_probe.cpp` — `engine/fx/flux.cpp` + `dcblock.cpp`. Fills the tape line
  with a 200 Hz tone, switches FLUX off into silence, reports the step at the
  moment `is_idle()` takes over.
- `flux_on.cpp` — same link set. Same fill, switches off, waits 10 s of
  silence, switches on, reports the first samples and the peak of the
  resurrected tail.
- `rev2.cpp` — `engine/fx/reverb.cpp`. Replicates `instrument.cpp`'s wet-gain
  `OnePole` and equal-power law around the real `AmbientReverb`, sweeps
  DECAY/MIX, reports where the clear lands and at what return level.
- `comp_probe.cpp` — `engine/fx/comp.cpp`. Steady 0.8-peak tone, sweeps the
  COMP knob for steady-state output peak, then rides 0.5 → 0 and reports the
  largest one-sample gain jump.
- `lim_probe.cpp` — `limiter.h` only. Quiet wash, then a 1.4-peak onset;
  counts samples pinned at |out| ≥ 0.999.

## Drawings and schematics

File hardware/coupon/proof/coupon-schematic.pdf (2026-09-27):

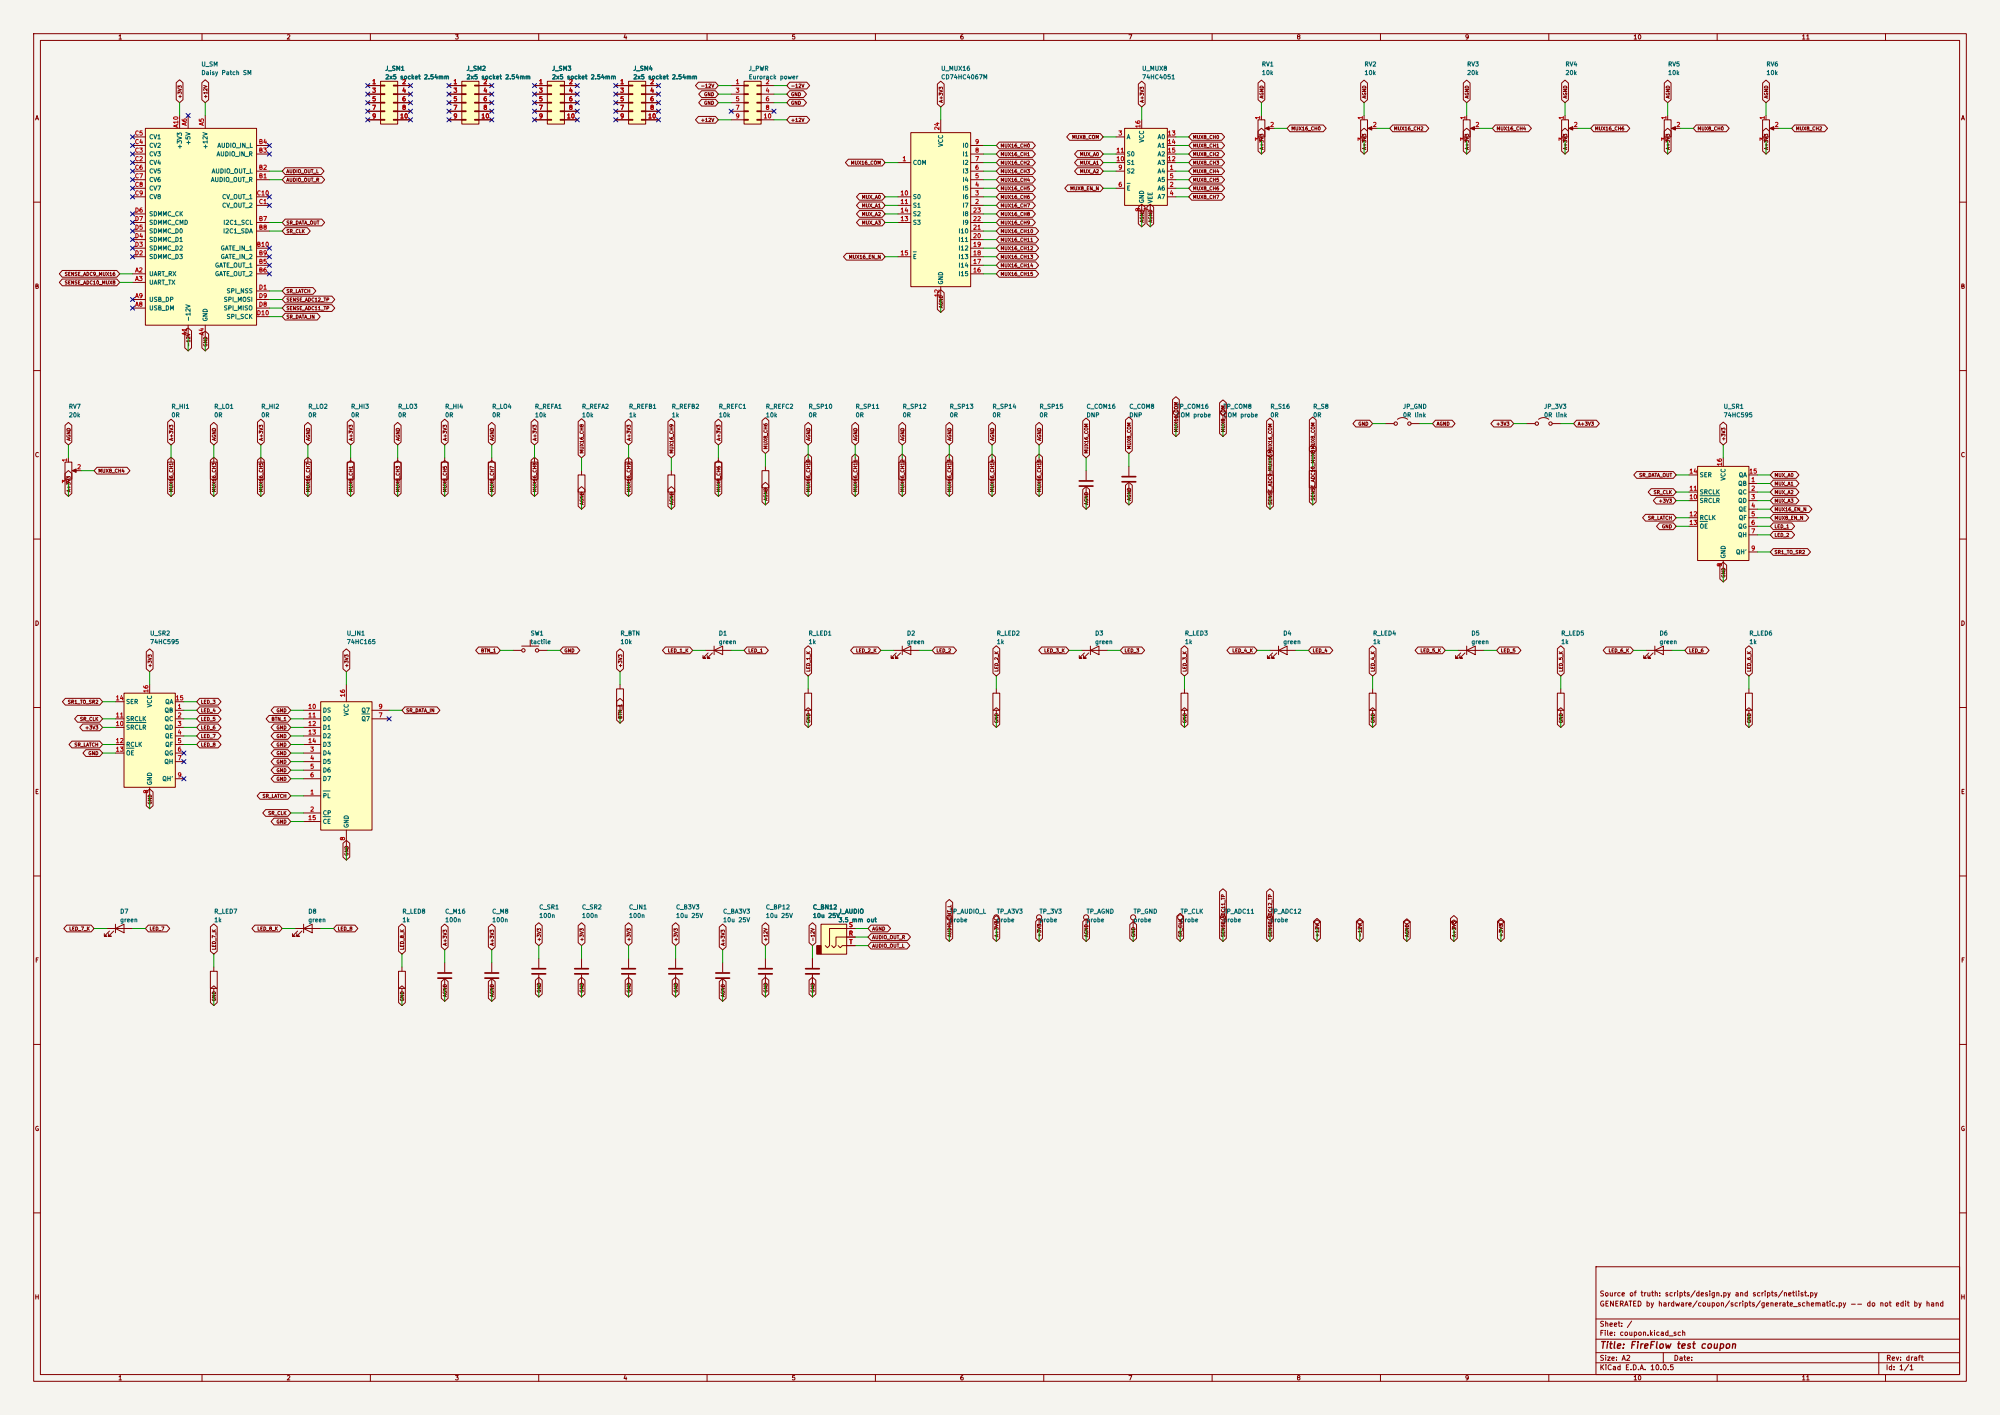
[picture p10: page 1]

SRCLR 10 SRCLK 11 RCLK 12 OE 13

Source of truth: scripts/design.py and scripts/netlist.py
GENERATED by hardware/coupon/scripts/generate_schematic.py -- do not edit by hand

Sheet: /
File: coupon.kicad_sch
Title: FireFlow test coupon

Size: A2 | Rev: draft
KiCad E.D.A. 10.0.5 | Id: 1/1

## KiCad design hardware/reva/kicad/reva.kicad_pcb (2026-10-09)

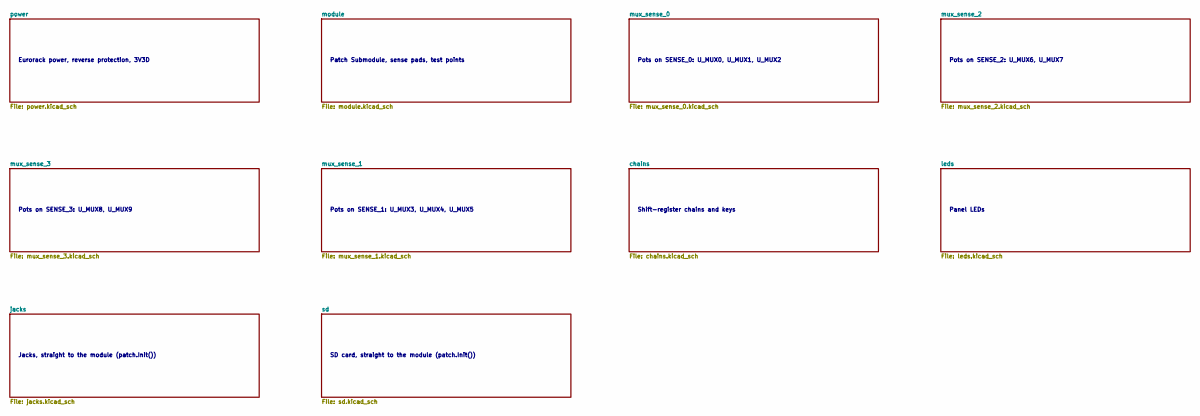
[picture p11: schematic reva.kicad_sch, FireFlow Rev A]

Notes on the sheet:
Eurorack power, reverse protection, 3V3D
Patch Submodule, sense pads, test points
Pots on SENSE_0: U_MUX0, U_MUX1, U_MUX2
Pots on SENSE_2: U_MUX6, U_MUX7
Pots on SENSE_3: U_MUX8, U_MUX9
Pots on SENSE_1: U_MUX3, U_MUX4, U_MUX5
Shift-register chains and keys
Panel LEDs
Jacks, straight to the module (patch.Init())
SD card, straight to the module (patch.Init())

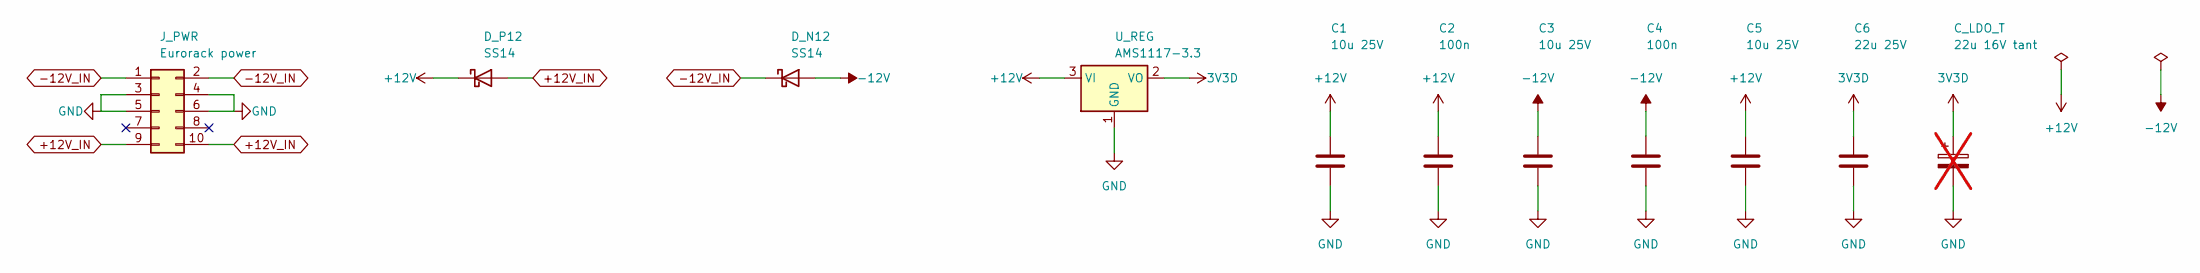
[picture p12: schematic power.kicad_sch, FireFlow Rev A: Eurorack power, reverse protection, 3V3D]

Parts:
C1, C3, C5: 10u 25V; C_0805_2012Metric; LCSC C15850
C2, C4: 100n; C_0603_1608Metric; LCSC C14663
C6: 22u 25V; C_0805_2012Metric; LCSC C45783
C_LDO_T: 22u 16V tant; CP_EIA-6032-28_Kemet-C; LCSC C1967941; not fitted
D_N12: SS14; D_SMA; LCSC C2480
D_P12: SS14; D_SMA; LCSC C2480
J_PWR: Eurorack power; IDC-Header_2x05_P2.54mm_Vertical
U_REG: AMS1117-3.3; SOT-223-3_TabPin2; LCSC C6186

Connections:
3V3D: C6.1, C_LDO_T.1, U_REG.2 (VO); also elsewhere on the board
+12V: C1.1, C2.1, C5.1, D_P12.1 (K), U_REG.3 (VI); also elsewhere on the board
+12V_IN: D_P12.2 (A), J_PWR.9, J_PWR.10
-12V: C3.1, C4.1, D_N12.2 (A); also elsewhere on the board
-12V_IN: D_N12.1 (K), J_PWR.1, J_PWR.2
GND: C1.2, C2.2, C3.2, C4.2, C5.2, C6.2, C_LDO_T.2, J_PWR.3, J_PWR.4, J_PWR.5, J_PWR.6, U_REG.1 (GND); also elsewhere on the board

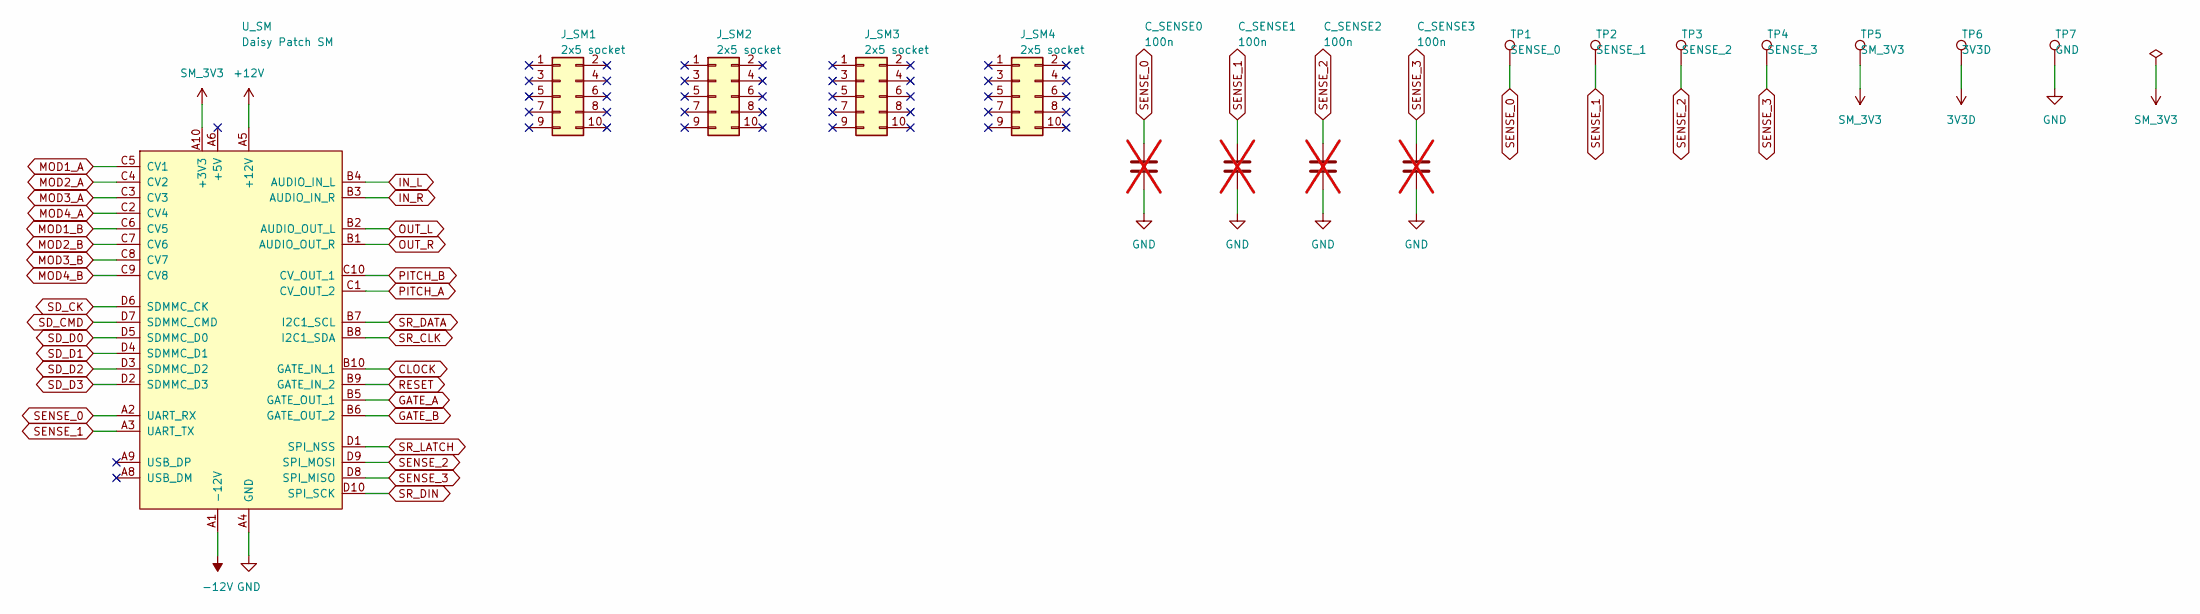
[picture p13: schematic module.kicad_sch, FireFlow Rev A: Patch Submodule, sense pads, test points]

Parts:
C_SENSE0, C_SENSE1, C_SENSE2, C_SENSE3: 100n; C_0603_1608Metric; LCSC C14663; not fitted
J_SM1, J_SM2, J_SM3, J_SM4: 2x5 socket
TP1: SENSE_0; TestPoint_Pad_D1.5mm
TP2: SENSE_1; TestPoint_Pad_D1.5mm
TP3: SENSE_2; TestPoint_Pad_D1.5mm
TP4: SENSE_3; TestPoint_Pad_D1.5mm
TP5: SM_3V3; TestPoint_Pad_D1.5mm
TP6: 3V3D; TestPoint_Pad_D1.5mm
TP7: GND; TestPoint_Pad_D1.5mm
U_SM: Daisy Patch SM; DAISY_PATCH_SM

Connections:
3V3D: TP6.1; also elsewhere on the board
+12V: U_SM.A5 (+12V); also elsewhere on the board
-12V: U_SM.A1 (-12V); also elsewhere on the board
CLOCK: U_SM.B10 (GATE_IN_1); also elsewhere on the board
GATE_A: U_SM.B5 (GATE_OUT_1); also elsewhere on the board
GATE_B: U_SM.B6 (GATE_OUT_2); also elsewhere on the board
GND: C_SENSE0.2, C_SENSE1.2, C_SENSE2.2, C_SENSE3.2, TP7.1, U_SM.A4 (GND), U_SM.A7 (GND); also elsewhere on the board
IN_L: U_SM.B4 (AUDIO_IN_L); also elsewhere on the board
IN_R: U_SM.B3 (AUDIO_IN_R); also elsewhere on the board
MOD1_A: U_SM.C5 (CV1); also elsewhere on the board
MOD1_B: U_SM.C6 (CV5); also elsewhere on the board
MOD2_A: U_SM.C4 (CV2); also elsewhere on the board
MOD2_B: U_SM.C7 (CV6); also elsewhere on the board
MOD3_A: U_SM.C3 (CV3); also elsewhere on the board
MOD3_B: U_SM.C8 (CV7); also elsewhere on the board
MOD4_A: U_SM.C2 (CV4); also elsewhere on the board
MOD4_B: U_SM.C9 (CV8); also elsewhere on the board
OUT_L: U_SM.B2 (AUDIO_OUT_L); also elsewhere on the board
OUT_R: U_SM.B1 (AUDIO_OUT_R); also elsewhere on the board
PITCH_A: U_SM.C1 (CV_OUT_2); also elsewhere on the board
PITCH_B: U_SM.C10 (CV_OUT_1); also elsewhere on the board
RESET: U_SM.B9 (GATE_IN_2); also elsewhere on the board
SD_CK: U_SM.D6 (SDMMC_CK); also elsewhere on the board
SD_CMD: U_SM.D7 (SDMMC_CMD); also elsewhere on the board
SD_D0: U_SM.D5 (SDMMC_D0); also elsewhere on the board
SD_D1: U_SM.D4 (SDMMC_D1); also elsewhere on the board
SD_D2: U_SM.D3 (SDMMC_D2); also elsewhere on the board
SD_D3: U_SM.D2 (SDMMC_D3); also elsewhere on the board
SENSE_0: C_SENSE0.1, TP1.1, U_SM.A2 (UART_RX); also elsewhere on the board
SENSE_1: C_SENSE1.1, TP2.1, U_SM.A3 (UART_TX); also elsewhere on the board
SENSE_2: C_SENSE2.1, TP3.1, U_SM.D9 (SPI_MOSI); also elsewhere on the board
SENSE_3: C_SENSE3.1, TP4.1, U_SM.D8 (SPI_MISO); also elsewhere on the board
SM_3V3: TP5.1, U_SM.A10 (+3V3); also elsewhere on the board
SR_CLK: U_SM.B8 (I2C1_SDA); also elsewhere on the board
SR_DATA: U_SM.B7 (I2C1_SCL); also elsewhere on the board
SR_DIN: U_SM.D10 (SPI_SCK); also elsewhere on the board
SR_LATCH: U_SM.D1 (SPI_NSS); also elsewhere on the board

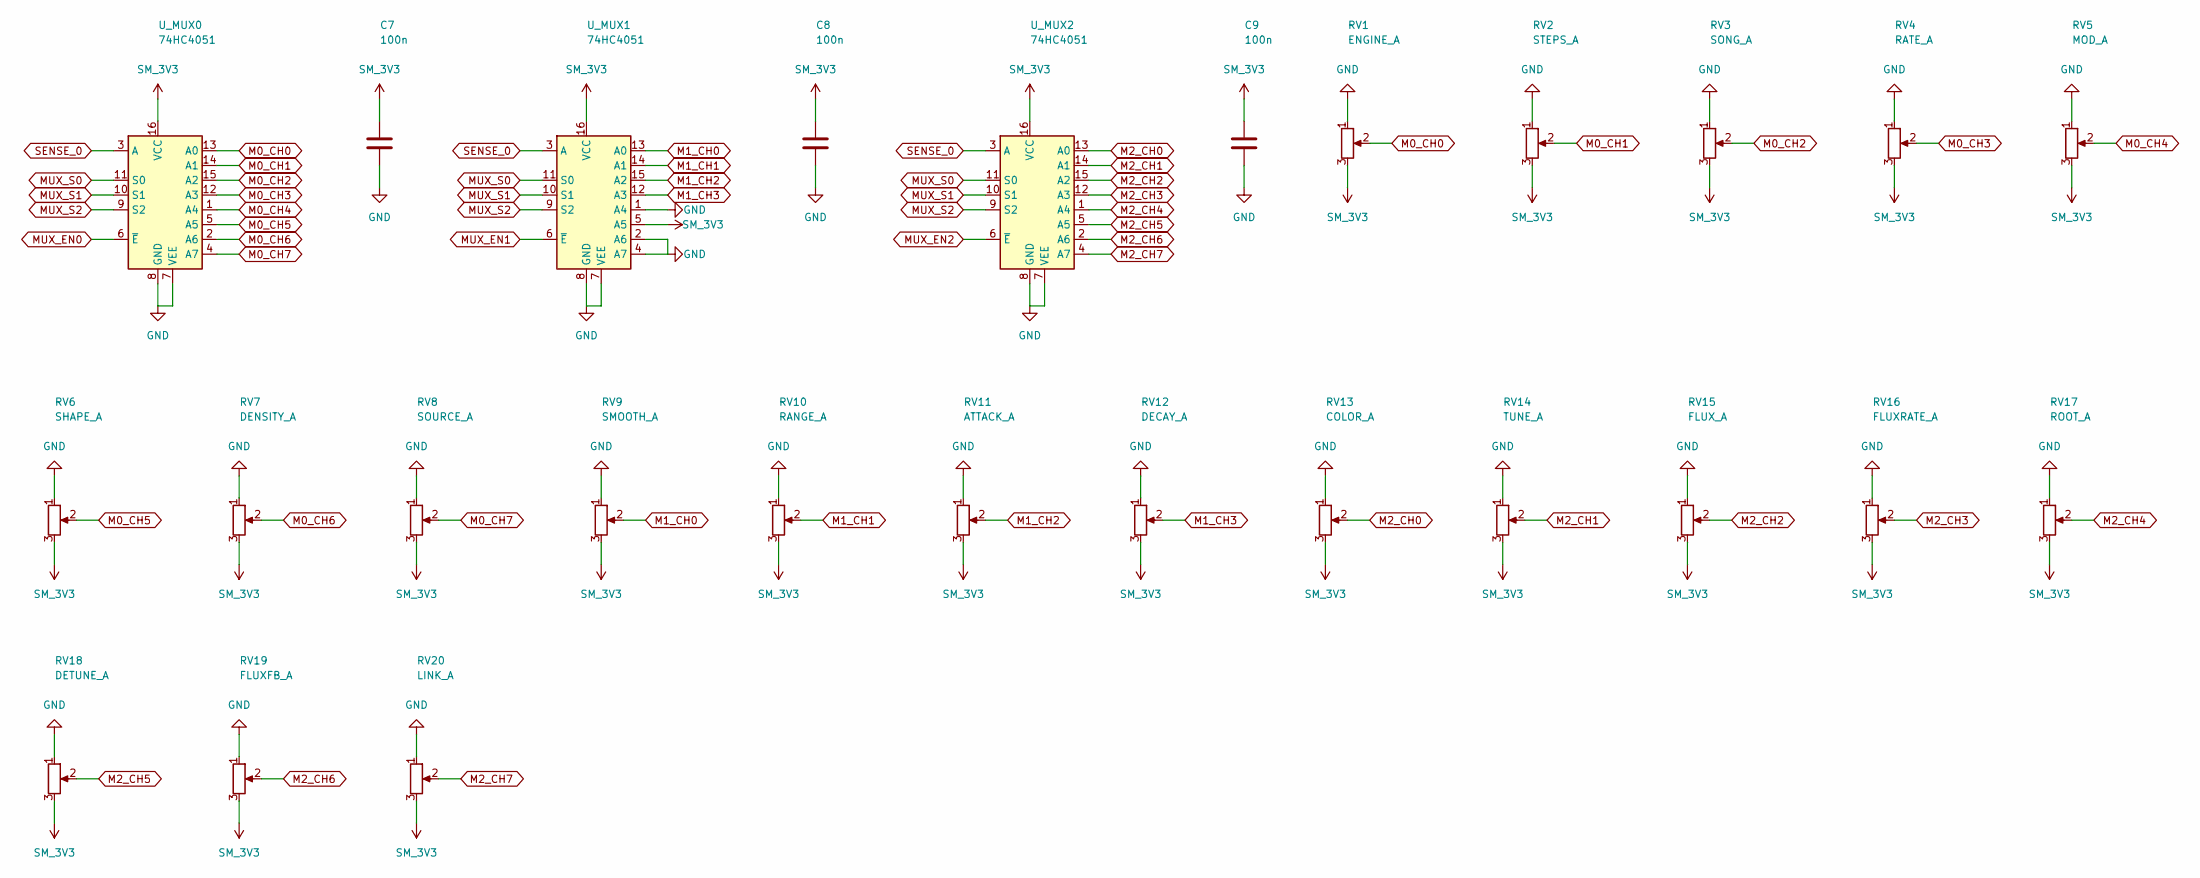
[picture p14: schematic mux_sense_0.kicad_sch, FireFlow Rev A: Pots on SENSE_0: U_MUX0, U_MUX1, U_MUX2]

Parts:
C7, C8, C9: 100n; C_0603_1608Metric; LCSC C14663
RV1: ENGINE_A; Potentiometer_Alpha_RD901F-40-00D_Single_Vertical
RV2: STEPS_A; Potentiometer_Alpha_RD901F-40-00D_Single_Vertical
RV3: SONG_A; Potentiometer_Alpha_RD901F-40-00D_Single_Vertical
RV4: RATE_A; Potentiometer_Alpha_RD901F-40-00D_Single_Vertical
RV5: MOD_A; Potentiometer_Alpha_RD901F-40-00D_Single_Vertical
RV6: SHAPE_A; Potentiometer_Alpha_RD901F-40-00D_Single_Vertical
RV7: DENSITY_A; Potentiometer_Alpha_RD901F-40-00D_Single_Vertical
RV8: SOURCE_A; Potentiometer_Alpha_RD901F-40-00D_Single_Vertical
RV9: SMOOTH_A; Potentiometer_Alpha_RD901F-40-00D_Single_Vertical
RV10: RANGE_A; Potentiometer_Alpha_RD901F-40-00D_Single_Vertical
RV11: ATTACK_A; Potentiometer_Alpha_RD901F-40-00D_Single_Vertical
RV12: DECAY_A; Potentiometer_Alpha_RD901F-40-00D_Single_Vertical
RV13: COLOR_A; Potentiometer_Alpha_RD901F-40-00D_Single_Vertical
RV14: TUNE_A; Potentiometer_Alpha_RD901F-40-00D_Single_Vertical
RV15: FLUX_A; Potentiometer_Alpha_RD901F-40-00D_Single_Vertical
RV16: FLUXRATE_A; Potentiometer_Alpha_RD901F-40-00D_Single_Vertical
RV17: ROOT_A; Potentiometer_Alpha_RD901F-40-00D_Single_Vertical
RV18: DETUNE_A; Potentiometer_Alpha_RD901F-40-00D_Single_Vertical
RV19: FLUXFB_A; Potentiometer_Alpha_RD901F-40-00D_Single_Vertical
RV20: LINK_A; Potentiometer_Alpha_RD901F-40-00D_Single_Vertical
U_MUX0, U_MUX1, U_MUX2: 74HC4051; SOIC-16_3.9x9.9mm_P1.27mm; LCSC C9386

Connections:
GND: C7.2, C8.2, C9.2, RV1.1, RV2.1, RV3.1, RV4.1, RV5.1, RV6.1, RV7.1, RV8.1, RV9.1, RV10.1, RV11.1, RV12.1, RV13.1, RV14.1, RV15.1, RV16.1, RV17.1, RV18.1, RV19.1, RV20.1, U_MUX0.7 (VEE), U_MUX0.8 (GND), U_MUX1.1 (A4), U_MUX1.2 (A6), U_MUX1.4 (A7), U_MUX1.7 (VEE), U_MUX1.8 (GND), U_MUX2.7 (VEE), U_MUX2.8 (GND); also elsewhere on the board
M0_CH0: RV1.2, U_MUX0.13 (A0)
M0_CH1: RV2.2, U_MUX0.14 (A1)
M0_CH2: RV3.2, U_MUX0.15 (A2)
M0_CH3: RV4.2, U_MUX0.12 (A3)
M0_CH4: RV5.2, U_MUX0.1 (A4)
M0_CH5: RV6.2, U_MUX0.5 (A5)
M0_CH6: RV7.2, U_MUX0.2 (A6)
M0_CH7: RV8.2, U_MUX0.4 (A7)
M1_CH0: RV9.2, U_MUX1.13 (A0)
M1_CH1: RV10.2, U_MUX1.14 (A1)
M1_CH2: RV11.2, U_MUX1.15 (A2)
M1_CH3: RV12.2, U_MUX1.12 (A3)
M2_CH0: RV13.2, U_MUX2.13 (A0)
M2_CH1: RV14.2, U_MUX2.14 (A1)
M2_CH2: RV15.2, U_MUX2.15 (A2)
M2_CH3: RV16.2, U_MUX2.12 (A3)
M2_CH4: RV17.2, U_MUX2.1 (A4)
M2_CH5: RV18.2, U_MUX2.5 (A5)
M2_CH6: RV19.2, U_MUX2.2 (A6)
M2_CH7: RV20.2, U_MUX2.4 (A7)
MUX_EN0: U_MUX0.6 (~E); also elsewhere on the board
MUX_EN1: U_MUX1.6 (~E); also elsewhere on the board
MUX_EN2: U_MUX2.6 (~E); also elsewhere on the board
MUX_S0: U_MUX0.11 (S0), U_MUX1.11 (S0), U_MUX2.11 (S0); also elsewhere on the board
MUX_S1: U_MUX0.10 (S1), U_MUX1.10 (S1), U_MUX2.10 (S1); also elsewhere on the board
MUX_S2: U_MUX0.9 (S2), U_MUX1.9 (S2), U_MUX2.9 (S2); also elsewhere on the board
SENSE_0: U_MUX0.3 (A), U_MUX1.3 (A), U_MUX2.3 (A); also elsewhere on the board
SM_3V3: C7.1, C8.1, C9.1, RV1.3, RV2.3, RV3.3, RV4.3, RV5.3, RV6.3, RV7.3, RV8.3, RV9.3, RV10.3, RV11.3, RV12.3, RV13.3, RV14.3, RV15.3, RV16.3, RV17.3, RV18.3, RV19.3, RV20.3, U_MUX0.16 (VCC), U_MUX1.5 (A5), U_MUX1.16 (VCC), U_MUX2.16 (VCC); also elsewhere on the board

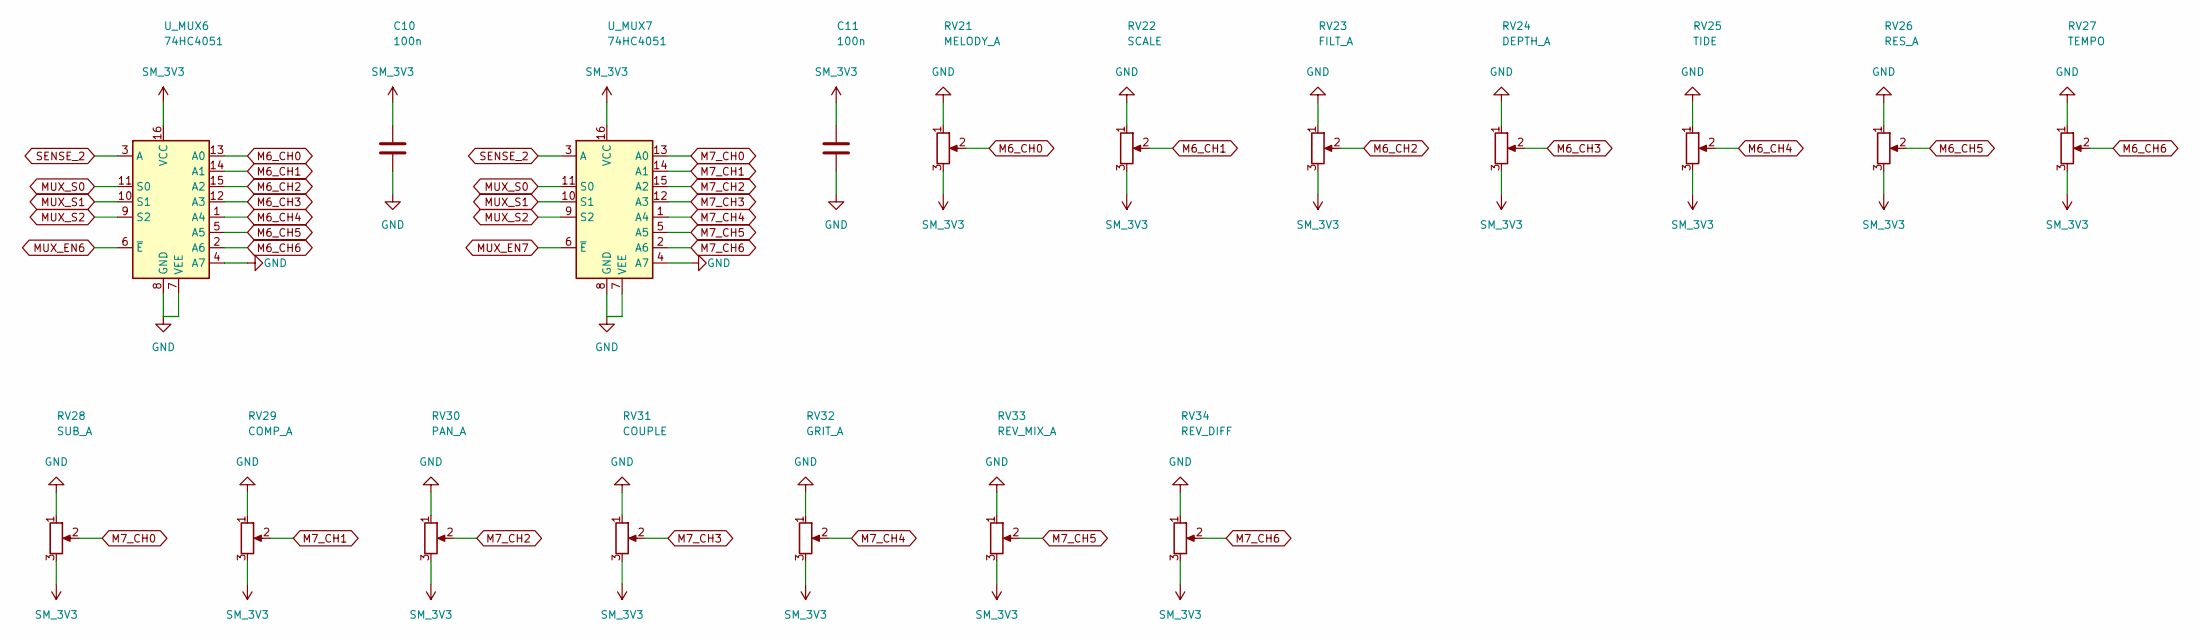
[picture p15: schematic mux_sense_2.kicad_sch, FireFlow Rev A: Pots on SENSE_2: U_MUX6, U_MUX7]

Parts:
C10, C11: 100n; C_0603_1608Metric; LCSC C14663
RV21: MELODY_A; Potentiometer_Alpha_RD901F-40-00D_Single_Vertical
RV22: SCALE; Potentiometer_Alpha_RD901F-40-00D_Single_Vertical
RV23: FILT_A; Potentiometer_Alpha_RD901F-40-00D_Single_Vertical
RV24: DEPTH_A; Potentiometer_Alpha_RD901F-40-00D_Single_Vertical
RV25: TIDE; Potentiometer_Alpha_RD901F-40-00D_Single_Vertical
RV26: RES_A; Potentiometer_Alpha_RD901F-40-00D_Single_Vertical
RV27: TEMPO; Potentiometer_Alpha_RD901F-40-00D_Single_Vertical
RV28: SUB_A; Potentiometer_Alpha_RD901F-40-00D_Single_Vertical
RV29: COMP_A; Potentiometer_Alpha_RD901F-40-00D_Single_Vertical
RV30: PAN_A; Potentiometer_Alpha_RD901F-40-00D_Single_Vertical
RV31: COUPLE; Potentiometer_Alpha_RD901F-40-00D_Single_Vertical
RV32: GRIT_A; Potentiometer_Alpha_RD901F-40-00D_Single_Vertical
RV33: REV_MIX_A; Potentiometer_Alpha_RD901F-40-00D_Single_Vertical
RV34: REV_DIFF; Potentiometer_Alpha_RD901F-40-00D_Single_Vertical
U_MUX6, U_MUX7: 74HC4051; SOIC-16_3.9x9.9mm_P1.27mm; LCSC C9386

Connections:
GND: C10.2, C11.2, RV21.1, RV22.1, RV23.1, RV24.1, RV25.1, RV26.1, RV27.1, RV28.1, RV29.1, RV30.1, RV31.1, RV32.1, RV33.1, RV34.1, U_MUX6.4 (A7), U_MUX6.7 (VEE), U_MUX6.8 (GND), U_MUX7.4 (A7), U_MUX7.7 (VEE), U_MUX7.8 (GND); also elsewhere on the board
M6_CH0: RV21.2, U_MUX6.13 (A0)
M6_CH1: RV22.2, U_MUX6.14 (A1)
M6_CH2: RV23.2, U_MUX6.15 (A2)
M6_CH3: RV24.2, U_MUX6.12 (A3)
M6_CH4: RV25.2, U_MUX6.1 (A4)
M6_CH5: RV26.2, U_MUX6.5 (A5)
M6_CH6: RV27.2, U_MUX6.2 (A6)
M7_CH0: RV28.2, U_MUX7.13 (A0)
M7_CH1: RV29.2, U_MUX7.14 (A1)
M7_CH2: RV30.2, U_MUX7.15 (A2)
M7_CH3: RV31.2, U_MUX7.12 (A3)
M7_CH4: RV32.2, U_MUX7.1 (A4)
M7_CH5: RV33.2, U_MUX7.5 (A5)
M7_CH6: RV34.2, U_MUX7.2 (A6)
MUX_EN6: U_MUX6.6 (~E); also elsewhere on the board
MUX_EN7: U_MUX7.6 (~E); also elsewhere on the board
MUX_S0: U_MUX6.11 (S0), U_MUX7.11 (S0); also elsewhere on the board
MUX_S1: U_MUX6.10 (S1), U_MUX7.10 (S1); also elsewhere on the board
MUX_S2: U_MUX6.9 (S2), U_MUX7.9 (S2); also elsewhere on the board
SENSE_2: U_MUX6.3 (A), U_MUX7.3 (A); also elsewhere on the board
SM_3V3: C10.1, C11.1, RV21.3, RV22.3, RV23.3, RV24.3, RV25.3, RV26.3, RV27.3, RV28.3, RV29.3, RV30.3, RV31.3, RV32.3, RV33.3, RV34.3, U_MUX6.16 (VCC), U_MUX7.16 (VCC); also elsewhere on the board

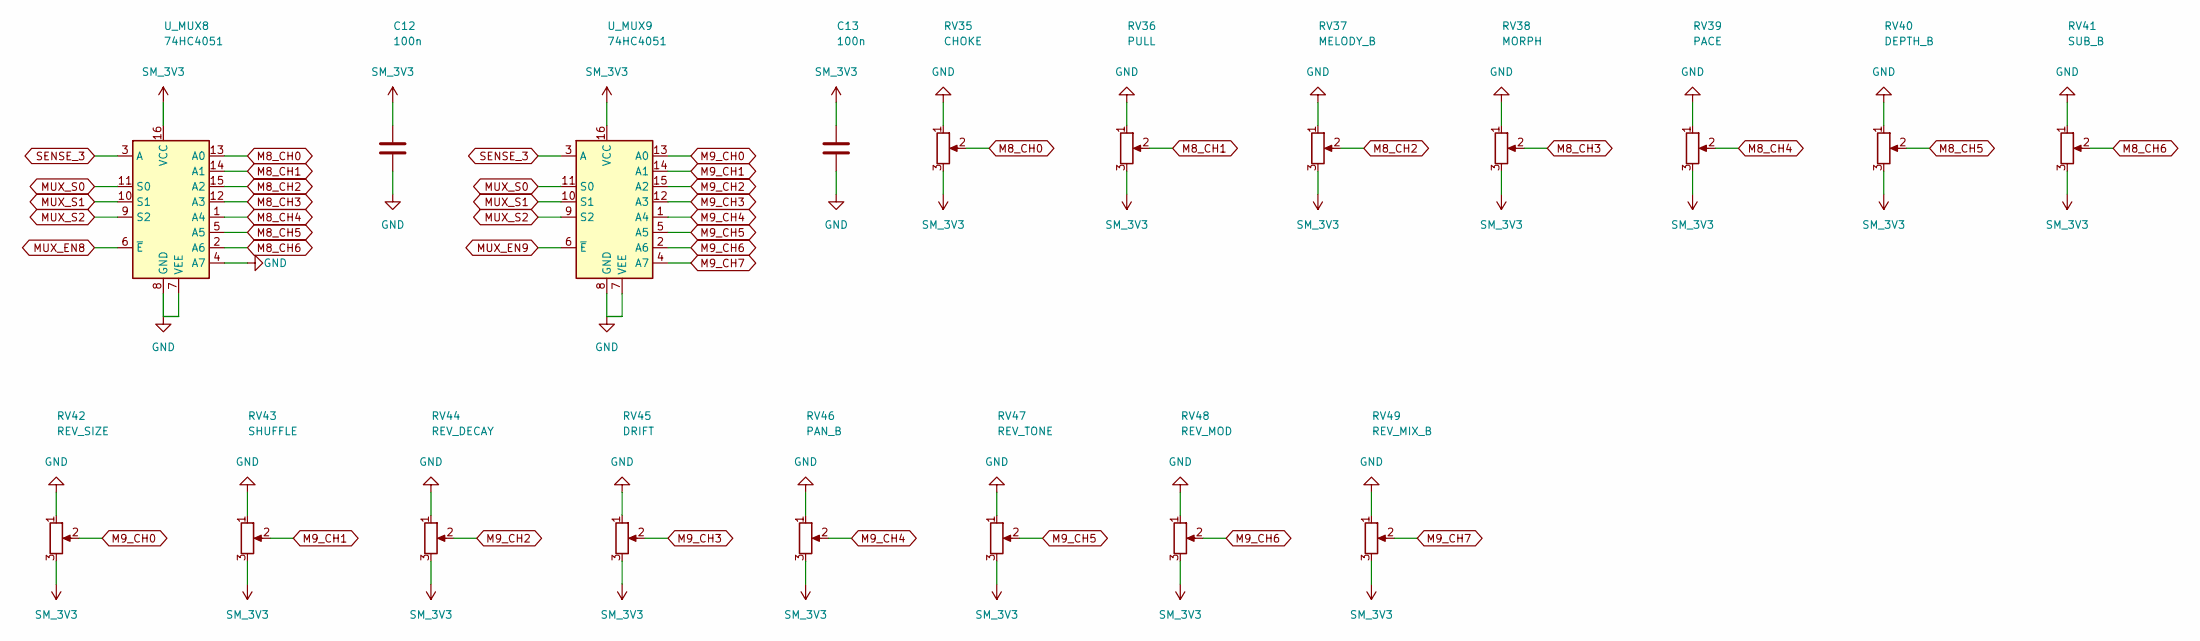
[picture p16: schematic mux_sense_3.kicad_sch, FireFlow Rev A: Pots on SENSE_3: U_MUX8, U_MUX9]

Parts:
C12, C13: 100n; C_0603_1608Metric; LCSC C14663
RV35: CHOKE; Potentiometer_Alpha_RD901F-40-00D_Single_Vertical
RV36: PULL; Potentiometer_Alpha_RD901F-40-00D_Single_Vertical
RV37: MELODY_B; Potentiometer_Alpha_RD901F-40-00D_Single_Vertical
RV38: MORPH; Potentiometer_Alpha_RD901F-40-00D_Single_Vertical
RV39: PACE; Potentiometer_Alpha_RD901F-40-00D_Single_Vertical
RV40: DEPTH_B; Potentiometer_Alpha_RD901F-40-00D_Single_Vertical
RV41: SUB_B; Potentiometer_Alpha_RD901F-40-00D_Single_Vertical
RV42: REV_SIZE; Potentiometer_Alpha_RD901F-40-00D_Single_Vertical
RV43: SHUFFLE; Potentiometer_Alpha_RD901F-40-00D_Single_Vertical
RV44: REV_DECAY; Potentiometer_Alpha_RD901F-40-00D_Single_Vertical
RV45: DRIFT; Potentiometer_Alpha_RD901F-40-00D_Single_Vertical
RV46: PAN_B; Potentiometer_Alpha_RD901F-40-00D_Single_Vertical
RV47: REV_TONE; Potentiometer_Alpha_RD901F-40-00D_Single_Vertical
RV48: REV_MOD; Potentiometer_Alpha_RD901F-40-00D_Single_Vertical
RV49: REV_MIX_B; Potentiometer_Alpha_RD901F-40-00D_Single_Vertical
U_MUX8, U_MUX9: 74HC4051; SOIC-16_3.9x9.9mm_P1.27mm; LCSC C9386

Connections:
GND: C12.2, C13.2, RV35.1, RV36.1, RV37.1, RV38.1, RV39.1, RV40.1, RV41.1, RV42.1, RV43.1, RV44.1, RV45.1, RV46.1, RV47.1, RV48.1, RV49.1, U_MUX8.4 (A7), U_MUX8.7 (VEE), U_MUX8.8 (GND), U_MUX9.7 (VEE), U_MUX9.8 (GND); also elsewhere on the board
M8_CH0: RV35.2, U_MUX8.13 (A0)
M8_CH1: RV36.2, U_MUX8.14 (A1)
M8_CH2: RV37.2, U_MUX8.15 (A2)
M8_CH3: RV38.2, U_MUX8.12 (A3)
M8_CH4: RV39.2, U_MUX8.1 (A4)
M8_CH5: RV40.2, U_MUX8.5 (A5)
M8_CH6: RV41.2, U_MUX8.2 (A6)
M9_CH0: RV42.2, U_MUX9.13 (A0)
M9_CH1: RV43.2, U_MUX9.14 (A1)
M9_CH2: RV44.2, U_MUX9.15 (A2)
M9_CH3: RV45.2, U_MUX9.12 (A3)
M9_CH4: RV46.2, U_MUX9.1 (A4)
M9_CH5: RV47.2, U_MUX9.5 (A5)
M9_CH6: RV48.2, U_MUX9.2 (A6)
M9_CH7: RV49.2, U_MUX9.4 (A7)
MUX_EN8: U_MUX8.6 (~E); also elsewhere on the board
MUX_EN9: U_MUX9.6 (~E); also elsewhere on the board
MUX_S0: U_MUX8.11 (S0), U_MUX9.11 (S0); also elsewhere on the board
MUX_S1: U_MUX8.10 (S1), U_MUX9.10 (S1); also elsewhere on the board
MUX_S2: U_MUX8.9 (S2), U_MUX9.9 (S2); also elsewhere on the board
SENSE_3: U_MUX8.3 (A), U_MUX9.3 (A); also elsewhere on the board
SM_3V3: C12.1, C13.1, RV35.3, RV36.3, RV37.3, RV38.3, RV39.3, RV40.3, RV41.3, RV42.3, RV43.3, RV44.3, RV45.3, RV46.3, RV47.3, RV48.3, RV49.3, U_MUX8.16 (VCC), U_MUX9.16 (VCC); also elsewhere on the board

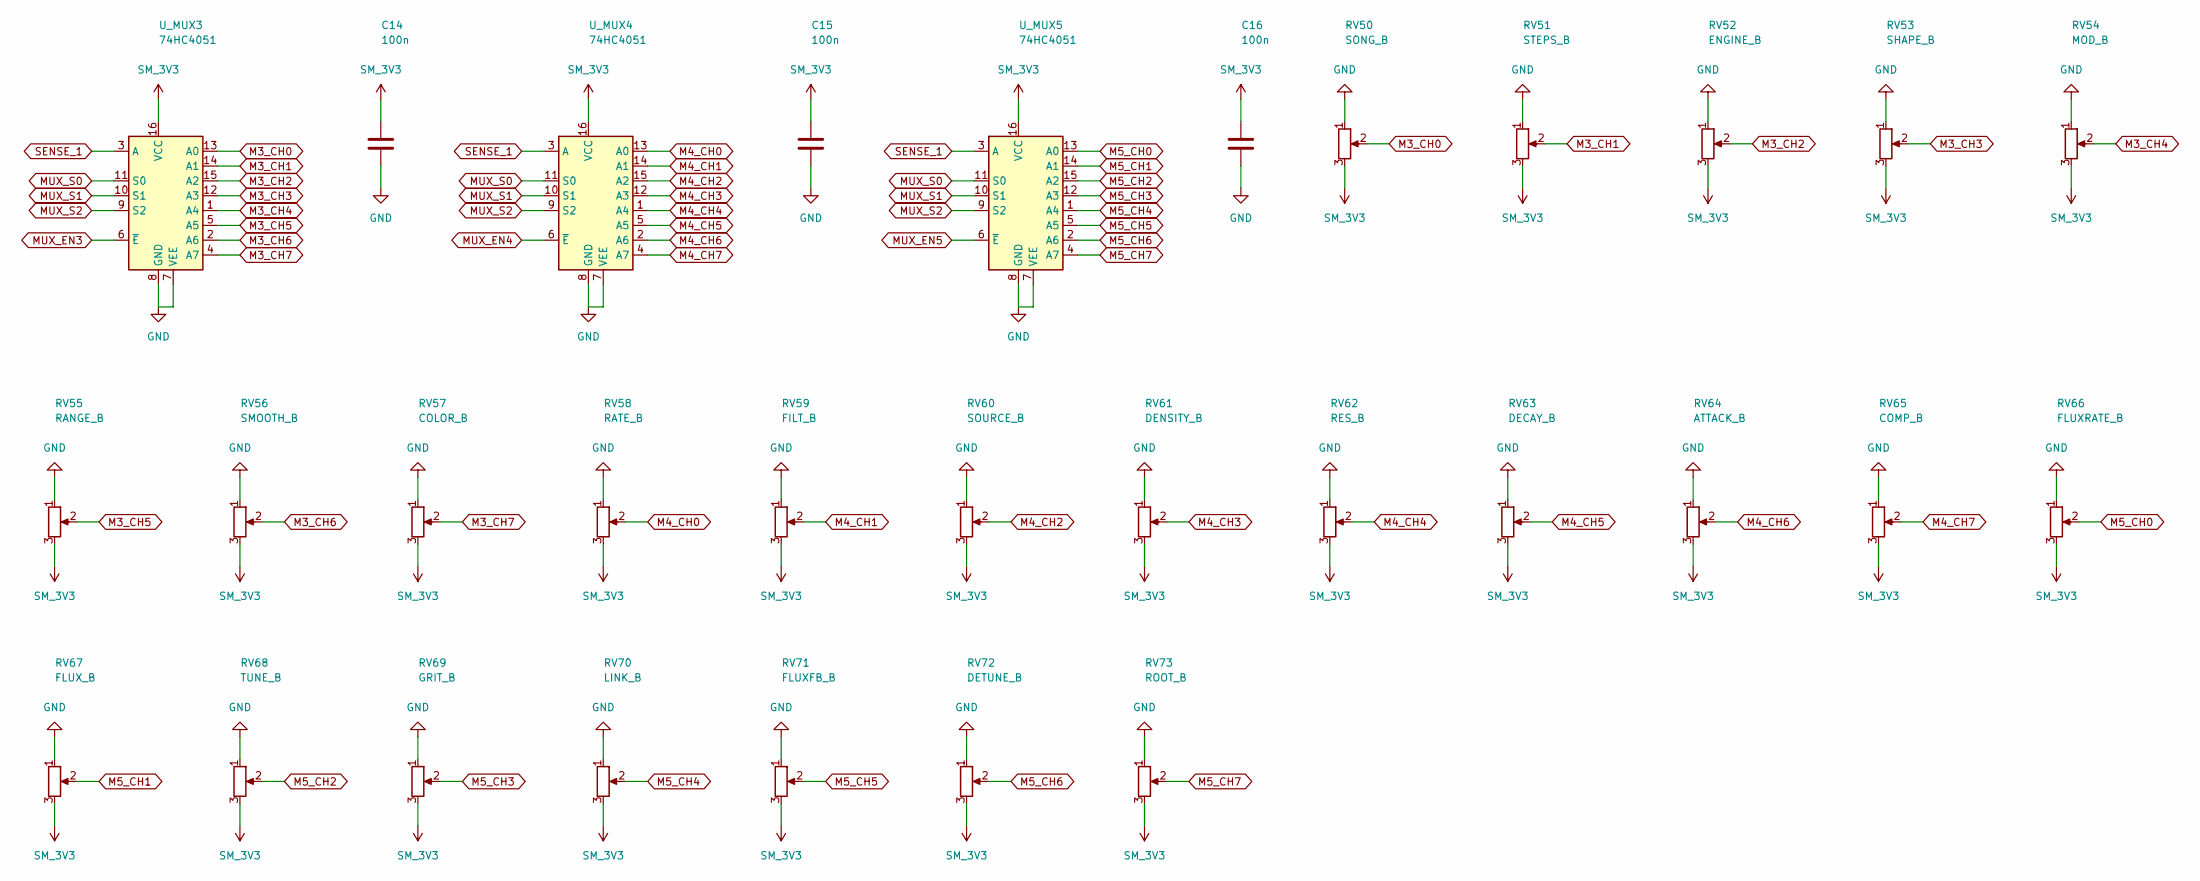
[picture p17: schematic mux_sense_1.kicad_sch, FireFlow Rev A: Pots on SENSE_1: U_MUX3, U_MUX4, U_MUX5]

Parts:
C14, C15, C16: 100n; C_0603_1608Metric; LCSC C14663
RV50: SONG_B; Potentiometer_Alpha_RD901F-40-00D_Single_Vertical
RV51: STEPS_B; Potentiometer_Alpha_RD901F-40-00D_Single_Vertical
RV52: ENGINE_B; Potentiometer_Alpha_RD901F-40-00D_Single_Vertical
RV53: SHAPE_B; Potentiometer_Alpha_RD901F-40-00D_Single_Vertical
RV54: MOD_B; Potentiometer_Alpha_RD901F-40-00D_Single_Vertical
RV55: RANGE_B; Potentiometer_Alpha_RD901F-40-00D_Single_Vertical
RV56: SMOOTH_B; Potentiometer_Alpha_RD901F-40-00D_Single_Vertical
RV57: COLOR_B; Potentiometer_Alpha_RD901F-40-00D_Single_Vertical
RV58: RATE_B; Potentiometer_Alpha_RD901F-40-00D_Single_Vertical
RV59: FILT_B; Potentiometer_Alpha_RD901F-40-00D_Single_Vertical
RV60: SOURCE_B; Potentiometer_Alpha_RD901F-40-00D_Single_Vertical
RV61: DENSITY_B; Potentiometer_Alpha_RD901F-40-00D_Single_Vertical
RV62: RES_B; Potentiometer_Alpha_RD901F-40-00D_Single_Vertical
RV63: DECAY_B; Potentiometer_Alpha_RD901F-40-00D_Single_Vertical
RV64: ATTACK_B; Potentiometer_Alpha_RD901F-40-00D_Single_Vertical
RV65: COMP_B; Potentiometer_Alpha_RD901F-40-00D_Single_Vertical
RV66: FLUXRATE_B; Potentiometer_Alpha_RD901F-40-00D_Single_Vertical
RV67: FLUX_B; Potentiometer_Alpha_RD901F-40-00D_Single_Vertical
RV68: TUNE_B; Potentiometer_Alpha_RD901F-40-00D_Single_Vertical
RV69: GRIT_B; Potentiometer_Alpha_RD901F-40-00D_Single_Vertical
RV70: LINK_B; Potentiometer_Alpha_RD901F-40-00D_Single_Vertical
RV71: FLUXFB_B; Potentiometer_Alpha_RD901F-40-00D_Single_Vertical
RV72: DETUNE_B; Potentiometer_Alpha_RD901F-40-00D_Single_Vertical
RV73: ROOT_B; Potentiometer_Alpha_RD901F-40-00D_Single_Vertical
U_MUX3, U_MUX4, U_MUX5: 74HC4051; SOIC-16_3.9x9.9mm_P1.27mm; LCSC C9386

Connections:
GND: C14.2, C15.2, C16.2, RV50.1, RV51.1, RV52.1, RV53.1, RV54.1, RV55.1, RV56.1, RV57.1, RV58.1, RV59.1, RV60.1, RV61.1, RV62.1, RV63.1, RV64.1, RV65.1, RV66.1, RV67.1, RV68.1, RV69.1, RV70.1, RV71.1, RV72.1, RV73.1, U_MUX3.7 (VEE), U_MUX3.8 (GND), U_MUX4.7 (VEE), U_MUX4.8 (GND), U_MUX5.7 (VEE), U_MUX5.8 (GND); also elsewhere on the board
M3_CH0: RV50.2, U_MUX3.13 (A0)
M3_CH1: RV51.2, U_MUX3.14 (A1)
M3_CH2: RV52.2, U_MUX3.15 (A2)
M3_CH3: RV53.2, U_MUX3.12 (A3)
M3_CH4: RV54.2, U_MUX3.1 (A4)
M3_CH5: RV55.2, U_MUX3.5 (A5)
M3_CH6: RV56.2, U_MUX3.2 (A6)
M3_CH7: RV57.2, U_MUX3.4 (A7)
M4_CH0: RV58.2, U_MUX4.13 (A0)
M4_CH1: RV59.2, U_MUX4.14 (A1)
M4_CH2: RV60.2, U_MUX4.15 (A2)
M4_CH3: RV61.2, U_MUX4.12 (A3)
M4_CH4: RV62.2, U_MUX4.1 (A4)
M4_CH5: RV63.2, U_MUX4.5 (A5)
M4_CH6: RV64.2, U_MUX4.2 (A6)
M4_CH7: RV65.2, U_MUX4.4 (A7)
M5_CH0: RV66.2, U_MUX5.13 (A0)
M5_CH1: RV67.2, U_MUX5.14 (A1)
M5_CH2: RV68.2, U_MUX5.15 (A2)
M5_CH3: RV69.2, U_MUX5.12 (A3)
M5_CH4: RV70.2, U_MUX5.1 (A4)
M5_CH5: RV71.2, U_MUX5.5 (A5)
M5_CH6: RV72.2, U_MUX5.2 (A6)
M5_CH7: RV73.2, U_MUX5.4 (A7)
MUX_EN3: U_MUX3.6 (~E); also elsewhere on the board
MUX_EN4: U_MUX4.6 (~E); also elsewhere on the board
MUX_EN5: U_MUX5.6 (~E); also elsewhere on the board
MUX_S0: U_MUX3.11 (S0), U_MUX4.11 (S0), U_MUX5.11 (S0); also elsewhere on the board
MUX_S1: U_MUX3.10 (S1), U_MUX4.10 (S1), U_MUX5.10 (S1); also elsewhere on the board
MUX_S2: U_MUX3.9 (S2), U_MUX4.9 (S2), U_MUX5.9 (S2); also elsewhere on the board
SENSE_1: U_MUX3.3 (A), U_MUX4.3 (A), U_MUX5.3 (A); also elsewhere on the board
SM_3V3: C14.1, C15.1, C16.1, RV50.3, RV51.3, RV52.3, RV53.3, RV54.3, RV55.3, RV56.3, RV57.3, RV58.3, RV59.3, RV60.3, RV61.3, RV62.3, RV63.3, RV64.3, RV65.3, RV66.3, RV67.3, RV68.3, RV69.3, RV70.3, RV71.3, RV72.3, RV73.3, U_MUX3.16 (VCC), U_MUX4.16 (VCC), U_MUX5.16 (VCC); also elsewhere on the board

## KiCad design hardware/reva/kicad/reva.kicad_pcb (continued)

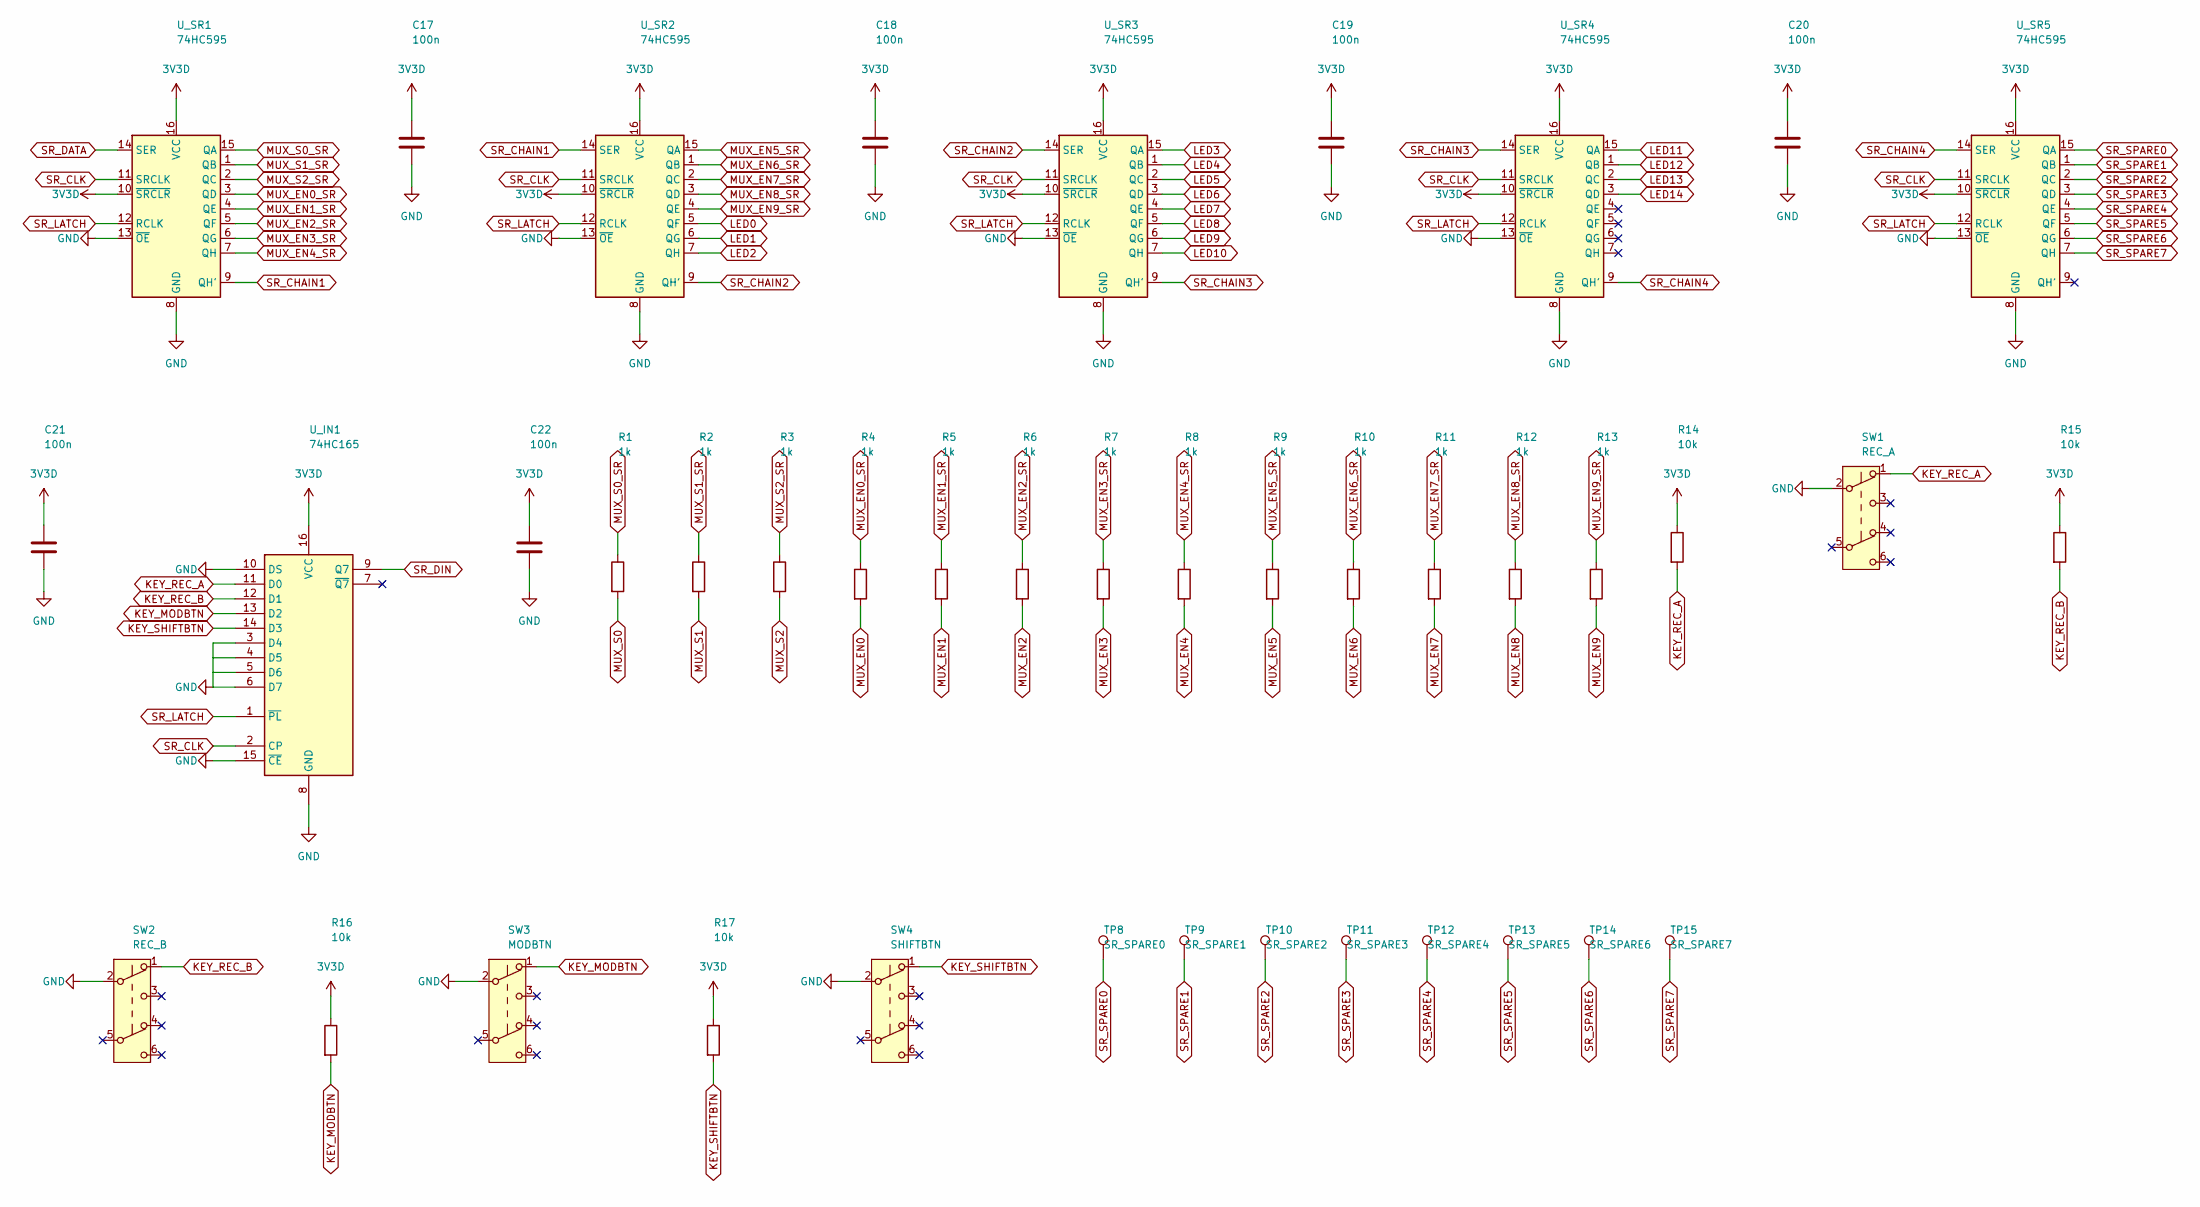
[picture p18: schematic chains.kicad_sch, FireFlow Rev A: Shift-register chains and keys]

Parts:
C17, C18, C19, C20, C21, C22: 100n; C_0603_1608Metric; LCSC C14663
R1, R2, R3, R4, R5, R6, R7, R8, R9, R10, R11, R12, R13: 1k; R_0603_1608Metric; LCSC C21190
R14, R15, R16, R17: 10k; R_0603_1608Metric; LCSC C25804
SW1: REC_A; SW_Push_LP_Button
SW2: REC_B; SW_Push_LP_Button
SW3: MODBTN; SW_Push_LP_Button
SW4: SHIFTBTN; SW_Push_LP_Button
TP8: SR_SPARE0; TestPoint_Pad_D1.5mm
TP9: SR_SPARE1; TestPoint_Pad_D1.5mm
TP10: SR_SPARE2; TestPoint_Pad_D1.5mm
TP11: SR_SPARE3; TestPoint_Pad_D1.5mm
TP12: SR_SPARE4; TestPoint_Pad_D1.5mm
TP13: SR_SPARE5; TestPoint_Pad_D1.5mm
TP14: SR_SPARE6; TestPoint_Pad_D1.5mm
TP15: SR_SPARE7; TestPoint_Pad_D1.5mm
U_IN1: 74HC165; SOIC-16_3.9x9.9mm_P1.27mm; LCSC C5613
U_SR1, U_SR2, U_SR3, U_SR4, U_SR5: 74HC595; SOIC-16_3.9x9.9mm_P1.27mm; LCSC C5947

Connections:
3V3D: C17.1, C18.1, C19.1, C20.1, C21.1, C22.1, R14.1, R15.1, R16.1, R17.1, U_IN1.16 (VCC), U_SR1.10 (~SRCLR), U_SR1.16 (VCC), U_SR2.10 (~SRCLR), U_SR2.16 (VCC), U_SR3.10 (~SRCLR), U_SR3.16 (VCC), U_SR4.10 (~SRCLR), U_SR4.16 (VCC), U_SR5.10 (~SRCLR), U_SR5.16 (VCC); also elsewhere on the board
GND: C17.2, C18.2, C19.2, C20.2, C21.2, C22.2, SW1.2 (B), SW2.2 (B), SW3.2 (B), SW4.2 (B), U_IN1.3 (D4), U_IN1.4 (D5), U_IN1.5 (D6), U_IN1.6 (D7), U_IN1.8 (GND), U_IN1.10 (DS), U_IN1.15 (~CE), U_SR1.8 (GND), U_SR1.13 (~OE), U_SR2.8 (GND), U_SR2.13 (~OE), U_SR3.8 (GND), U_SR3.13 (~OE), U_SR4.8 (GND), U_SR4.13 (~OE), U_SR5.8 (GND), U_SR5.13 (~OE); also elsewhere on the board
KEY_MODBTN: R16.2, SW3.1 (A), U_IN1.13 (D2)
KEY_REC_A: R14.2, SW1.1 (A), U_IN1.11 (D0)
KEY_REC_B: R15.2, SW2.1 (A), U_IN1.12 (D1)
KEY_SHIFTBTN: R17.2, SW4.1 (A), U_IN1.14 (D3)
LED0: U_SR2.5 (QF); also elsewhere on the board
LED1: U_SR2.6 (QG); also elsewhere on the board
LED2: U_SR2.7 (QH); also elsewhere on the board
LED3: U_SR3.15 (QA); also elsewhere on the board
LED4: U_SR3.1 (QB); also elsewhere on the board
LED5: U_SR3.2 (QC); also elsewhere on the board
LED6: U_SR3.3 (QD); also elsewhere on the board
LED7: U_SR3.4 (QE); also elsewhere on the board
LED8: U_SR3.5 (QF); also elsewhere on the board
LED9: U_SR3.6 (QG); also elsewhere on the board
LED10: U_SR3.7 (QH); also elsewhere on the board
LED11: U_SR4.15 (QA); also elsewhere on the board
LED12: U_SR4.1 (QB); also elsewhere on the board
LED13: U_SR4.2 (QC); also elsewhere on the board
LED14: U_SR4.3 (QD); also elsewhere on the board
MUX_EN0: R4.2; also elsewhere on the board
MUX_EN0_SR: R4.1, U_SR1.3 (QD)
MUX_EN1: R5.2; also elsewhere on the board
MUX_EN1_SR: R5.1, U_SR1.4 (QE)
MUX_EN2: R6.2; also elsewhere on the board
MUX_EN2_SR: R6.1, U_SR1.5 (QF)
MUX_EN3: R7.2; also elsewhere on the board
MUX_EN3_SR: R7.1, U_SR1.6 (QG)
MUX_EN4: R8.2; also elsewhere on the board
MUX_EN4_SR: R8.1, U_SR1.7 (QH)
MUX_EN5: R9.2; also elsewhere on the board
MUX_EN5_SR: R9.1, U_SR2.15 (QA)
MUX_EN6: R10.2; also elsewhere on the board
MUX_EN6_SR: R10.1, U_SR2.1 (QB)
MUX_EN7: R11.2; also elsewhere on the board
MUX_EN7_SR: R11.1, U_SR2.2 (QC)
MUX_EN8: R12.2; also elsewhere on the board
MUX_EN8_SR: R12.1, U_SR2.3 (QD)
MUX_EN9: R13.2; also elsewhere on the board
MUX_EN9_SR: R13.1, U_SR2.4 (QE)
MUX_S0: R1.2; also elsewhere on the board
MUX_S0_SR: R1.1, U_SR1.15 (QA)
MUX_S1: R2.2; also elsewhere on the board
MUX_S1_SR: R2.1, U_SR1.1 (QB)
MUX_S2: R3.2; also elsewhere on the board
MUX_S2_SR: R3.1, U_SR1.2 (QC)
SR_CHAIN1: U_SR1.9 (QH'), U_SR2.14 (SER)
SR_CHAIN2: U_SR2.9 (QH'), U_SR3.14 (SER)
SR_CHAIN3: U_SR3.9 (QH'), U_SR4.14 (SER)
SR_CHAIN4: U_SR4.9 (QH'), U_SR5.14 (SER)
SR_CLK: U_IN1.2 (CP), U_SR1.11 (SRCLK), U_SR2.11 (SRCLK), U_SR3.11 (SRCLK), U_SR4.11 (SRCLK), U_SR5.11 (SRCLK); also elsewhere on the board
SR_DATA: U_SR1.14 (SER); also elsewhere on the board
SR_DIN: U_IN1.9 (Q7); also elsewhere on the board
SR_LATCH: U_IN1.1 (~PL), U_SR1.12 (RCLK), U_SR2.12 (RCLK), U_SR3.12 (RCLK), U_SR4.12 (RCLK), U_SR5.12 (RCLK); also elsewhere on the board
SR_SPARE0: TP8.1, U_SR5.15 (QA)
SR_SPARE1: TP9.1, U_SR5.1 (QB)
SR_SPARE2: TP10.1, U_SR5.2 (QC)
SR_SPARE3: TP11.1, U_SR5.3 (QD)
SR_SPARE4: TP12.1, U_SR5.4 (QE)
SR_SPARE5: TP13.1, U_SR5.5 (QF)
SR_SPARE6: TP14.1, U_SR5.6 (QG)
SR_SPARE7: TP15.1, U_SR5.7 (QH)

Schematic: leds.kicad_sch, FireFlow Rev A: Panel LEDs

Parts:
D1: SHIFTBTN_L; LED_D3.0mm
D2: SONG_A_L; LED_D3.0mm
D3: GATE_A_L; LED_D3.0mm
D4: FTIME_A_L; LED_D3.0mm
D5: LVL_A_L; LED_D3.0mm
D6: REC_A_L; LED_D3.0mm
D7: CLK_L; LED_D3.0mm
D8: TEMPO_L; LED_D3.0mm
D9: RST_L; LED_D3.0mm
D10: REC_B_L; LED_D3.0mm
D11: LVL_B_L; LED_D3.0mm
D12: FTIME_B_L; LED_D3.0mm
D13: SONG_B_L; LED_D3.0mm
D14: GATE_B_L; LED_D3.0mm
D15: MODBTN_L; LED_D3.0mm
R18, R19, R20, R21, R22, R23, R24, R25, R26, R27, R28, R29, R30, R31, R32: 1k; R_0603_1608Metric; LCSC C21190

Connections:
GND: D1.1 (K), D2.1 (K), D3.1 (K), D4.1 (K), D5.1 (K), D6.1 (K), D7.1 (K), D8.1 (K), D9.1 (K), D10.1 (K), D11.1 (K), D12.1 (K), D13.1 (K), D14.1 (K), D15.1 (K); also elsewhere on the board
LED0: R18.1; also elsewhere on the board
LED0_A: D1.2 (A), R18.2
LED1: R19.1; also elsewhere on the board
LED1_A: D2.2 (A), R19.2
LED2: R20.1; also elsewhere on the board
LED2_A: D3.2 (A), R20.2
LED3: R21.1; also elsewhere on the board
LED3_A: D4.2 (A), R21.2
LED4: R22.1; also elsewhere on the board
LED4_A: D5.2 (A), R22.2
LED5: R23.1; also elsewhere on the board
LED5_A: D6.2 (A), R23.2
LED6: R24.1; also elsewhere on the board
LED6_A: D7.2 (A), R24.2
LED7: R25.1; also elsewhere on the board
LED7_A: D8.2 (A), R25.2
LED8: R26.1; also elsewhere on the board
LED8_A: D9.2 (A), R26.2
LED9: R27.1; also elsewhere on the board
LED9_A: D10.2 (A), R27.2
LED10: R28.1; also elsewhere on the board
LED10_A: D11.2 (A), R28.2
LED11: R29.1; also elsewhere on the board
LED11_A: D12.2 (A), R29.2
LED12: R30.1; also elsewhere on the board
LED12_A: D13.2 (A), R30.2
LED13: R31.1; also elsewhere on the board
LED13_A: D14.2 (A), R31.2
LED14: R32.1; also elsewhere on the board
LED14_A: D15.2 (A), R32.2

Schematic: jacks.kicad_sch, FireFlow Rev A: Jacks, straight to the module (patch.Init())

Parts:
J1: IN_L; Jack_3.5mm_QingPu_WQP-PJ398SM_Vertical_CircularHoles
J2: IN_R; Jack_3.5mm_QingPu_WQP-PJ398SM_Vertical_CircularHoles
J3: PITCH_A; Jack_3.5mm_QingPu_WQP-PJ398SM_Vertical_CircularHoles
J4: GATE_A; Jack_3.5mm_QingPu_WQP-PJ398SM_Vertical_CircularHoles
J5: MOD1_A; Jack_3.5mm_QingPu_WQP-PJ398SM_Vertical_CircularHoles
J6: MOD2_A; Jack_3.5mm_QingPu_WQP-PJ398SM_Vertical_CircularHoles
J7: MOD3_A; Jack_3.5mm_QingPu_WQP-PJ398SM_Vertical_CircularHoles
J8: MOD4_A; Jack_3.5mm_QingPu_WQP-PJ398SM_Vertical_CircularHoles
J9: CLOCK; Jack_3.5mm_QingPu_WQP-PJ398SM_Vertical_CircularHoles
J10: RESET; Jack_3.5mm_QingPu_WQP-PJ398SM_Vertical_CircularHoles
J11: MOD4_B; Jack_3.5mm_QingPu_WQP-PJ398SM_Vertical_CircularHoles
J12: MOD3_B; Jack_3.5mm_QingPu_WQP-PJ398SM_Vertical_CircularHoles
J13: MOD2_B; Jack_3.5mm_QingPu_WQP-PJ398SM_Vertical_CircularHoles
J14: MOD1_B; Jack_3.5mm_QingPu_WQP-PJ398SM_Vertical_CircularHoles
J15: GATE_B; Jack_3.5mm_QingPu_WQP-PJ398SM_Vertical_CircularHoles
J16: PITCH_B; Jack_3.5mm_QingPu_WQP-PJ398SM_Vertical_CircularHoles
J17: OUT_L; Jack_3.5mm_QingPu_WQP-PJ398SM_Vertical_CircularHoles
J18: OUT_R; Jack_3.5mm_QingPu_WQP-PJ398SM_Vertical_CircularHoles

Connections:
CLOCK: J9.T; also elsewhere on the board
GATE_A: J4.T; also elsewhere on the board
GATE_B: J15.T; also elsewhere on the board
GND: J1.S, J2.S, J3.S, J4.S, J5.S, J6.S, J7.S, J8.S, J9.S, J10.S, J11.S, J12.S, J13.S, J14.S, J15.S, J16.S, J17.S, J18.S; also elsewhere on the board
IN_L: J1.T, J2.TN; also elsewhere on the board
IN_R: J2.T; also elsewhere on the board
MOD1_A: J5.T; also elsewhere on the board
MOD1_B: J14.T; also elsewhere on the board
MOD2_A: J6.T; also elsewhere on the board
MOD2_B: J13.T; also elsewhere on the board
MOD3_A: J7.T; also elsewhere on the board
MOD3_B: J12.T; also elsewhere on the board
MOD4_A: J8.T; also elsewhere on the board
MOD4_B: J11.T; also elsewhere on the board
OUT_L: J17.T; also elsewhere on the board
OUT_R: J18.T; also elsewhere on the board
PITCH_A: J3.T; also elsewhere on the board
PITCH_B: J16.T; also elsewhere on the board
RESET: J10.T; also elsewhere on the board

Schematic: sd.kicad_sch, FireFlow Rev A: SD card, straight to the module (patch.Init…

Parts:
C_SD1: 100n; C_0603_1608Metric; LCSC C14663
C_SD2: 10u 25V; C_0805_2012Metric; LCSC C15850; not fitted
J_SD: microSD; SD_Yamaichi_PJS008U-3000-0

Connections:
GND: C_SD1.2, C_SD2.2, J_SD.6 (VSS), J_SD.SH (SHIELD); also elsewhere on the board
SD_CK: J_SD.5 (CLK); also elsewhere on the board
SD_CMD: J_SD.3 (CMD); also elsewhere on the board
SD_D0: J_SD.7 (DAT0); also elsewhere on the board
SD_D1: J_SD.8 (DAT1); also elsewhere on the board
SD_D2: J_SD.1 (DAT2); also elsewhere on the board
SD_D3: J_SD.2 (DAT3/CD); also elsewhere on the board
SM_3V3: C_SD1.1, C_SD2.1, J_SD.4 (VDD); also elsewhere on the board

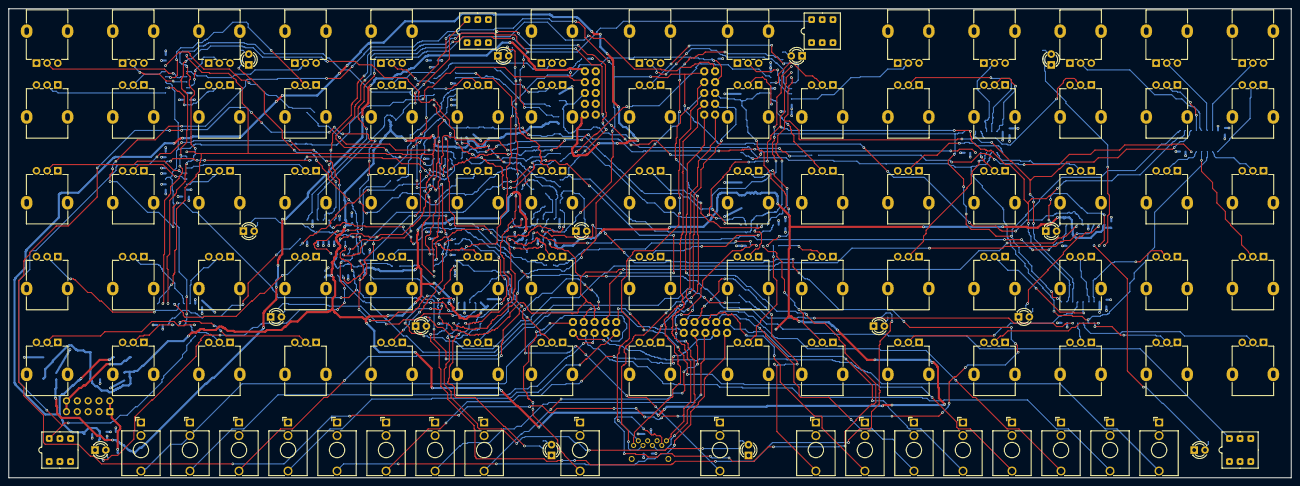
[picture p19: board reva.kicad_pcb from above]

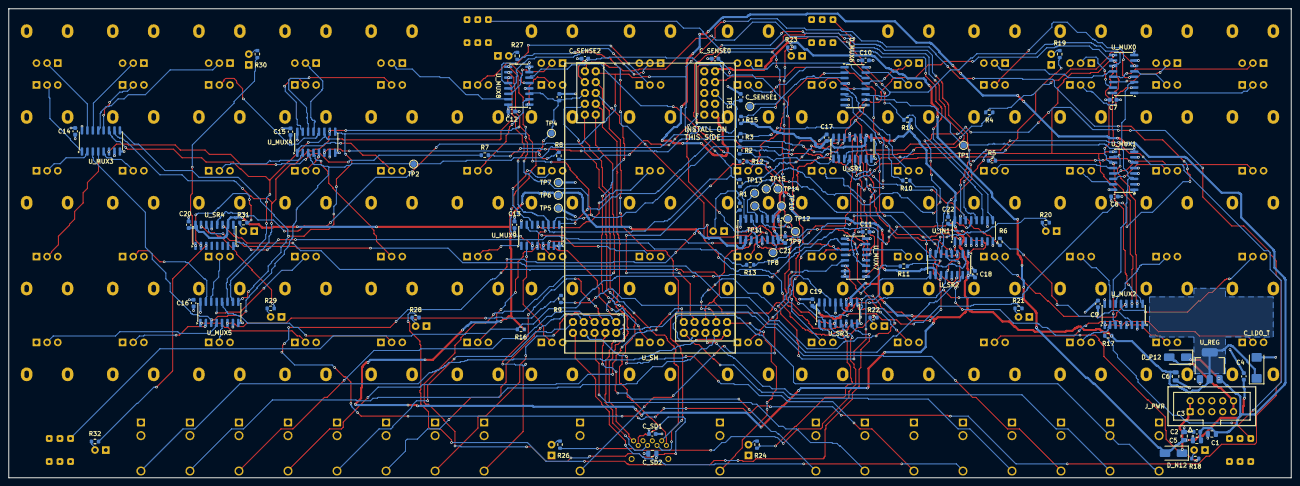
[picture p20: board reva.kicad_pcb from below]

Board: 4 copper layers, 300.8 x 110.0 mm, 208 parts (97 on the bottom side), 184 nets.

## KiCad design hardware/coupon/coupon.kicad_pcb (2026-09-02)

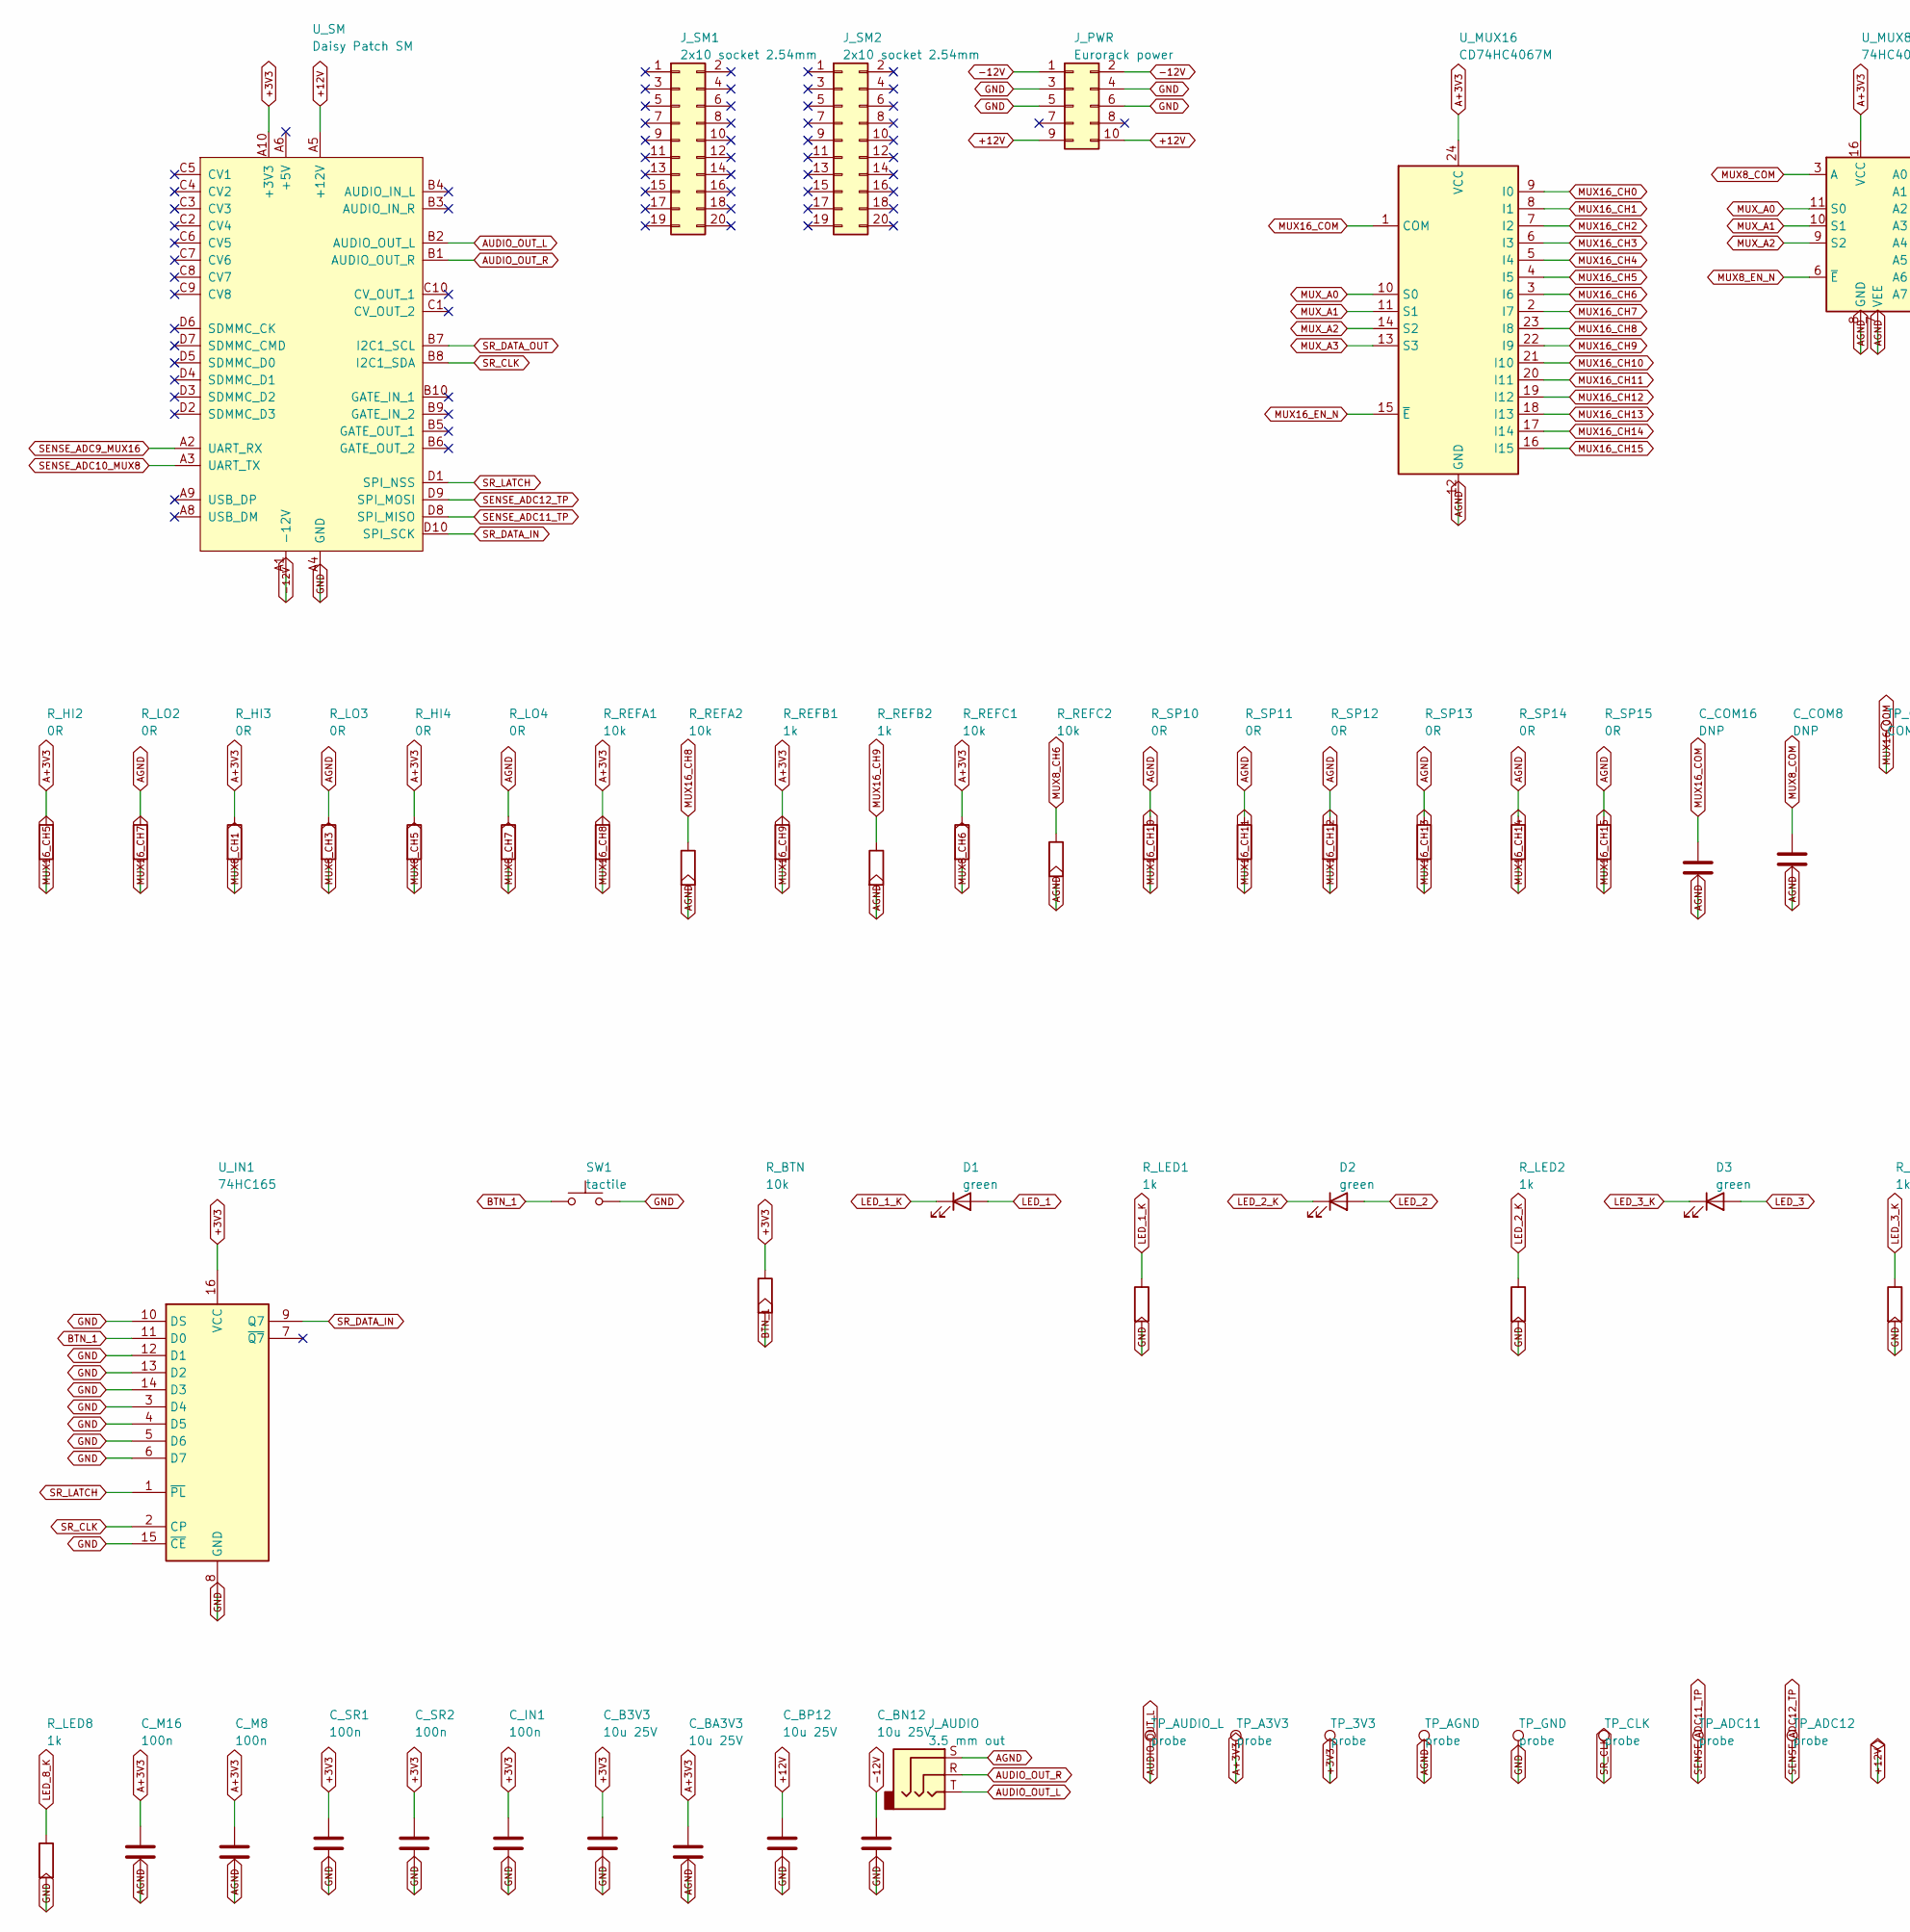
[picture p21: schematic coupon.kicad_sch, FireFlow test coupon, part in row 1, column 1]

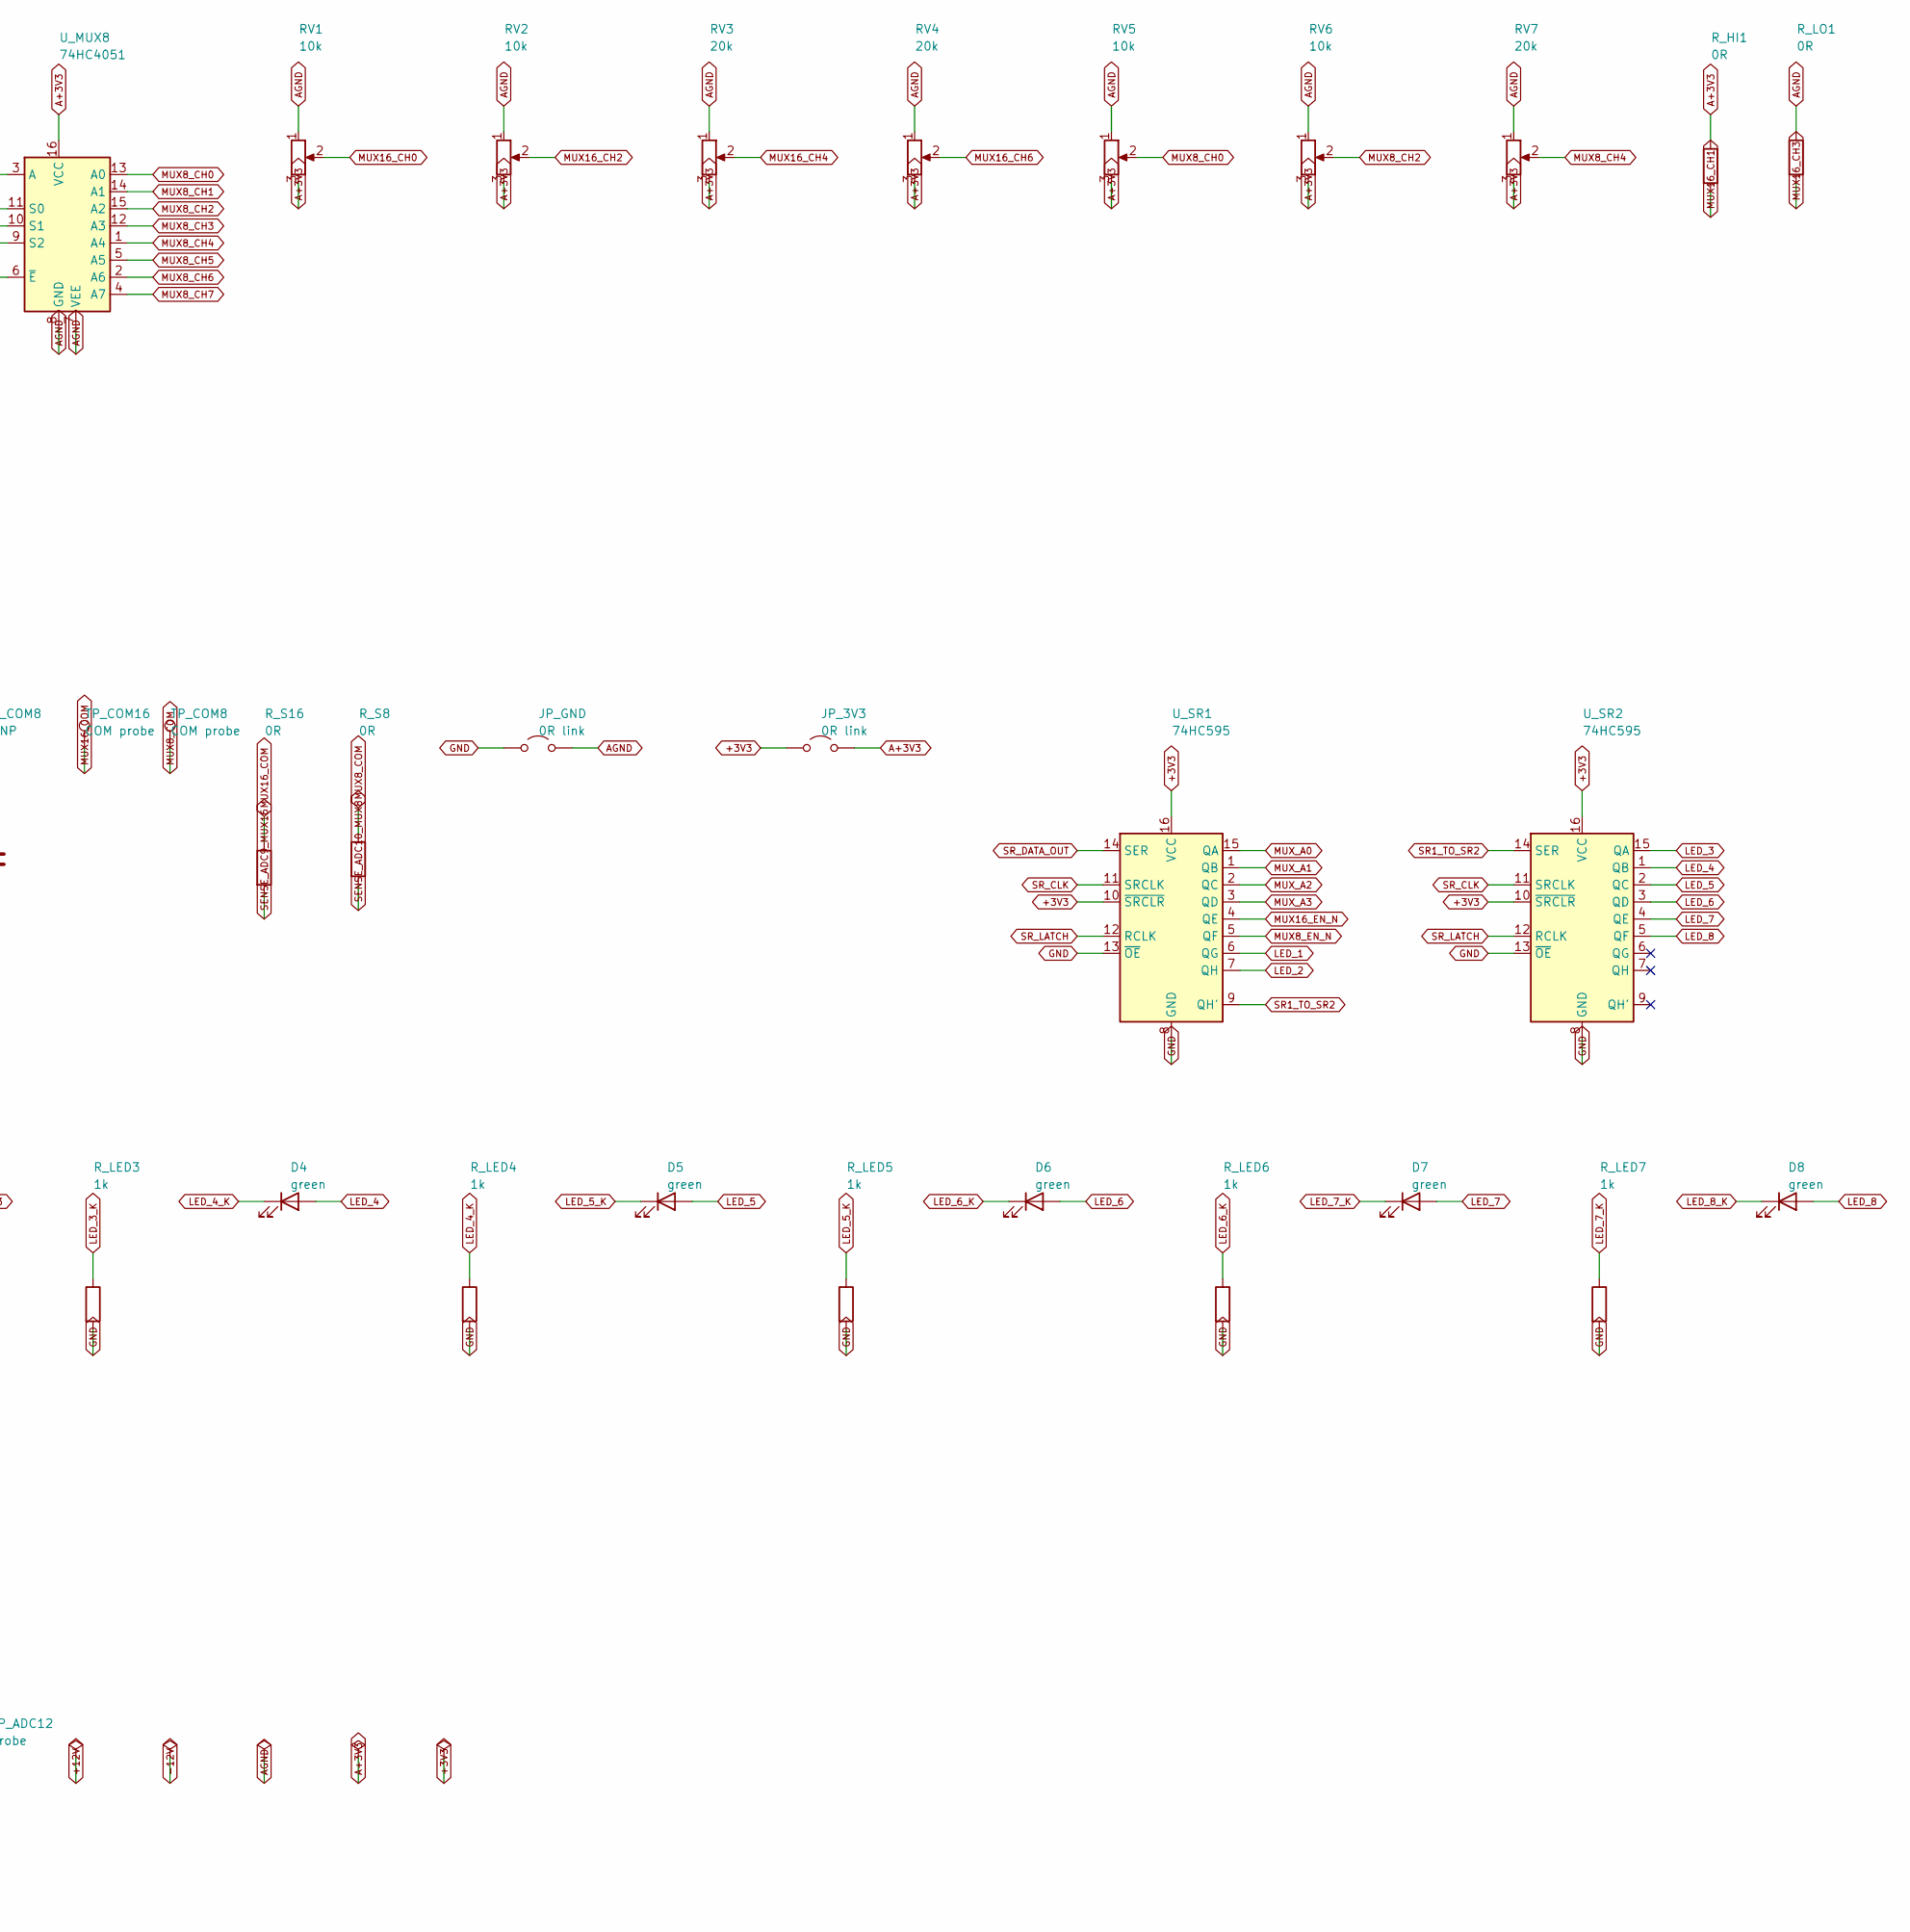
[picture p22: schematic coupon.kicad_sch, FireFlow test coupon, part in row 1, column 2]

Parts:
C_B3V3: 10u 25V; C_0805_2012Metric_Pad1.18x1.45mm_HandSolder
C_BA3V3: 10u 25V; C_0805_2012Metric_Pad1.18x1.45mm_HandSolder
C_BN12: 10u 25V; C_0805_2012Metric_Pad1.18x1.45mm_HandSolder
C_BP12: 10u 25V; C_0805_2012Metric_Pad1.18x1.45mm_HandSolder
C_COM8, C_COM16: DNP; C_0805_2012Metric_Pad1.18x1.45mm_HandSolder
C_IN1: 100n; C_0805_2012Metric_Pad1.18x1.45mm_HandSolder
C_M8, C_M16: 100n; C_0805_2012Metric_Pad1.18x1.45mm_HandSolder
C_SR1, C_SR2: 100n; C_0805_2012Metric_Pad1.18x1.45mm_HandSolder
D1, D2, D3, D4, D5, D6, D7, D8: green; LED_0805_2012Metric_Pad1.15x1.40mm_HandSolder
JP_3V3: 0R link; SolderJumper-2_P1.3mm_Open_Pad1.0x1.5mm
JP_GND: 0R link; SolderJumper-2_P1.3mm_Open_Pad1.0x1.5mm
J_AUDIO: 3.5 mm out; Jack_3.5mm_CUI_SJ1-3513N_Horizontal
J_PWR: Eurorack power; IDC-Header_2x05_P2.54mm_Vertical
J_SM1, J_SM2: 2x10 socket 2.54mm
RV1, RV2, RV5, RV6: 10k; Potentiometer_Alpha_RD901F-40-00D_Single_Vertical
RV3, RV4, RV7: 20k; Potentiometer_Alpha_RD901F-40-00D_Single_Vertical
R_BTN: 10k; R_0805_2012Metric_Pad1.20x1.40mm_HandSolder
R_HI1, R_HI2, R_HI3, R_HI4: 0R; R_0805_2012Metric_Pad1.20x1.40mm_HandSolder
R_LED1, R_LED2, R_LED3, R_LED4, R_LED5, R_LED6, R_LED7, R_LED8: 1k; R_0805_2012Metric_Pad1.20x1.40mm_HandSolder
R_LO1, R_LO2, R_LO3, R_LO4: 0R; R_0805_2012Metric_Pad1.20x1.40mm_HandSolder
R_REFA1, R_REFA2: 10k; R_0805_2012Metric_Pad1.20x1.40mm_HandSolder
R_REFB1, R_REFB2: 1k; R_0805_2012Metric_Pad1.20x1.40mm_HandSolder
R_REFC1, R_REFC2: 10k; R_0805_2012Metric_Pad1.20x1.40mm_HandSolder
R_S8, R_S16: 0R; R_0805_2012Metric_Pad1.20x1.40mm_HandSolder
R_SP10, R_SP11, R_SP12, R_SP13, R_SP14, R_SP15: 0R; R_0805_2012Metric_Pad1.20x1.40mm_HandSolder
SW1: tactile; SW_PUSH_6mm
TP_3V3: probe; TestPoint_Pad_D1.5mm
TP_A3V3: probe; TestPoint_Pad_D1.5mm
TP_ADC11, TP_ADC12: probe; TestPoint_Pad_D1.5mm
TP_AGND: probe; TestPoint_Pad_D1.5mm
TP_AUDIO_L: probe; TestPoint_Pad_D1.5mm
TP_CLK: probe; TestPoint_Pad_D1.5mm
TP_COM8, TP_COM16: COM probe; TestPoint_Pad_D1.5mm
TP_GND: probe; TestPoint_Pad_D1.5mm
U_IN1: 74HC165; SOIC-16_3.9x9.9mm_P1.27mm
U_MUX8: 74HC4051; SOIC-16_3.9x9.9mm_P1.27mm
U_MUX16: CD74HC4067M; SOIC-24W_7.5x15.4mm_P1.27mm
U_SM: Daisy Patch SM; DAISY_PATCH_SM
U_SR1, U_SR2: 74HC595; SOIC-16_3.9x9.9mm_P1.27mm

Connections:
+3V3: C_B3V3.1, C_IN1.1, C_SR1.1, C_SR2.1, JP_3V3.1 (A), R_BTN.1, TP_3V3.1, U_IN1.16 (VCC), U_SM.A10 (+3V3), U_SR1.10 (~SRCLR), U_SR1.16 (VCC), U_SR2.10 (~SRCLR), U_SR2.16 (VCC)
+12V: C_BP12.1, J_PWR.9, J_PWR.10, U_SM.A5 (+12V)
-12V: C_BN12.1, J_PWR.1, J_PWR.2, U_SM.A1 (-12V)
A+3V3: C_BA3V3.1, C_M8.1, C_M16.1, JP_3V3.2 (B), RV1.3, RV2.3, RV3.3, RV4.3, RV5.3, RV6.3, RV7.3, R_HI1.1, R_HI2.1, R_HI3.1, R_HI4.1, R_REFA1.1, R_REFB1.1, R_REFC1.1, TP_A3V3.1, U_MUX8.16 (VCC), U_MUX16.24 (VCC)
AGND: C_BA3V3.2, C_COM8.2, C_COM16.2, C_M8.2, C_M16.2, JP_GND.2 (B), J_AUDIO.S, RV1.1, RV2.1, RV3.1, RV4.1, RV5.1, RV6.1, RV7.1, R_LO1.1, R_LO2.1, R_LO3.1, R_LO4.1, R_REFA2.2, R_REFB2.2, R_REFC2.2, R_SP10.1, R_SP11.1, R_SP12.1, R_SP13.1, R_SP14.1, R_SP15.1, TP_AGND.1, U_MUX8.7 (VEE), U_MUX8.8 (GND), U_MUX16.12 (GND)
AUDIO_OUT_L: J_AUDIO.T, TP_AUDIO_L.1, U_SM.B2 (AUDIO_OUT_L)
AUDIO_OUT_R: J_AUDIO.R, U_SM.B1 (AUDIO_OUT_R)
BTN_1: R_BTN.2, SW1.1, U_IN1.11 (D0)
GND: C_B3V3.2, C_BN12.2, C_BP12.2, C_IN1.2, C_SR1.2, C_SR2.2, JP_GND.1 (A), J_PWR.3, J_PWR.4, J_PWR.5, J_PWR.6, R_LED1.2, R_LED2.2, R_LED3.2, R_LED4.2, R_LED5.2, R_LED6.2, R_LED7.2, R_LED8.2, SW1.2, TP_GND.1, U_IN1.3 (D4), U_IN1.4 (D5), U_IN1.5 (D6), U_IN1.6 (D7), U_IN1.8 (GND), U_IN1.10 (DS), U_IN1.12 (D1), U_IN1.13 (D2), U_IN1.14 (D3), U_IN1.15 (~CE), U_SM.A4 (GND), U_SM.A7 (GND), U_SR1.8 (GND), U_SR1.13 (~OE), U_SR2.8 (GND), U_SR2.13 (~OE)
LED_1: D1.2 (A), U_SR1.6 (QG)
LED_1_K: D1.1 (K), R_LED1.1
LED_2: D2.2 (A), U_SR1.7 (QH)
LED_2_K: D2.1 (K), R_LED2.1
LED_3: D3.2 (A), U_SR2.15 (QA)
LED_3_K: D3.1 (K), R_LED3.1
LED_4: D4.2 (A), U_SR2.1 (QB)
LED_4_K: D4.1 (K), R_LED4.1
LED_5: D5.2 (A), U_SR2.2 (QC)
LED_5_K: D5.1 (K), R_LED5.1
LED_6: D6.2 (A), U_SR2.3 (QD)
LED_6_K: D6.1 (K), R_LED6.1
LED_7: D7.2 (A), U_SR2.4 (QE)
LED_7_K: D7.1 (K), R_LED7.1
LED_8: D8.2 (A), U_SR2.5 (QF)
LED_8_K: D8.1 (K), R_LED8.1
MUX8_CH0: RV5.2, U_MUX8.13 (A0)
MUX8_CH1: R_HI3.2, U_MUX8.14 (A1)
MUX8_CH2: RV6.2, U_MUX8.15 (A2)
MUX8_CH3: R_LO3.2, U_MUX8.12 (A3)
MUX8_CH4: RV7.2, U_MUX8.1 (A4)
MUX8_CH5: R_HI4.2, U_MUX8.5 (A5)
MUX8_CH6: R_REFC1.2, R_REFC2.1, U_MUX8.2 (A6)
MUX8_CH7: R_LO4.2, U_MUX8.4 (A7)
MUX8_COM: C_COM8.1, R_S8.1, TP_COM8.1, U_MUX8.3 (A)
MUX8_EN_N: U_MUX8.6 (~E), U_SR1.5 (QF)
MUX16_CH0: RV1.2, U_MUX16.9 (I0)
MUX16_CH1: R_HI1.2, U_MUX16.8 (I1)
MUX16_CH2: RV2.2, U_MUX16.7 (I2)
MUX16_CH3: R_LO1.2, U_MUX16.6 (I3)
MUX16_CH4: RV3.2, U_MUX16.5 (I4)
MUX16_CH5: R_HI2.2, U_MUX16.4 (I5)
MUX16_CH6: RV4.2, U_MUX16.3 (I6)
MUX16_CH7: R_LO2.2, U_MUX16.2 (I7)
MUX16_CH8: R_REFA1.2, R_REFA2.1, U_MUX16.23 (I8)
MUX16_CH9: R_REFB1.2, R_REFB2.1, U_MUX16.22 (I9)
MUX16_CH10: R_SP10.2, U_MUX16.21 (I10)
MUX16_CH11: R_SP11.2, U_MUX16.20 (I11)
MUX16_CH12: R_SP12.2, U_MUX16.19 (I12)
MUX16_CH13: R_SP13.2, U_MUX16.18 (I13)
MUX16_CH14: R_SP14.2, U_MUX16.17 (I14)
MUX16_CH15: R_SP15.2, U_MUX16.16 (I15)
MUX16_COM: C_COM16.1, R_S16.1, TP_COM16.1, U_MUX16.1 (COM)
MUX16_EN_N: U_MUX16.15 (~E), U_SR1.4 (QE)
MUX_A0: U_MUX8.11 (S0), U_MUX16.10 (S0), U_SR1.15 (QA)
MUX_A1: U_MUX8.10 (S1), U_MUX16.11 (S1), U_SR1.1 (QB)
MUX_A2: U_MUX8.9 (S2), U_MUX16.14 (S2), U_SR1.2 (QC)
MUX_A3: U_MUX16.13 (S3), U_SR1.3 (QD)
SENSE_ADC9_MUX16: R_S16.2, U_SM.A2 (UART_RX)
SENSE_ADC10_MUX8: R_S8.2, U_SM.A3 (UART_TX)
SENSE_ADC11_TP: TP_ADC11.1, U_SM.D8 (SPI_MISO)
SENSE_ADC12_TP: TP_ADC12.1, U_SM.D9 (SPI_MOSI)
SR1_TO_SR2: U_SR1.9 (QH'), U_SR2.14 (SER)
SR_CLK: TP_CLK.1, U_IN1.2 (CP), U_SM.B8 (I2C1_SDA), U_SR1.11 (SRCLK), U_SR2.11 (SRCLK)
SR_DATA_IN: U_IN1.9 (Q7), U_SM.D10 (SPI_SCK)
SR_DATA_OUT: U_SM.B7 (I2C1_SCL), U_SR1.14 (SER)
SR_LATCH: U_IN1.1 (~PL), U_SM.D1 (SPI_NSS), U_SR1.12 (RCLK), U_SR2.12 (RCLK)


Board: 4 copper layers, 100.0 x 80.0 mm, 78 parts (0 on the bottom side), 66 nets.

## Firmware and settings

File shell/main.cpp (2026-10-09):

// Die erste FireFlow-Firmware, die engine/ enthaelt.
//
// Was sie ist: Board hoch, Speicher injizieren, process() im Audio-Callback.
// Was sie ausdruecklich nicht ist: kein UI, keine Panel-Logik, kein Preset.
// The line against bench/ is drawn in shell/README.md.
// shell_selftest.h vor allem anderen: der generierte Header traegt das
// SHELL_SELFTEST-Define, und das Makefile gibt ihm eine echte
// Abhaengigkeitskante auf dieses Objekt (siehe dort, "Selbsttest").
#include "shell_selftest.h"
#include "shell_cpu_probe.h"
#include "shell_mux_probe.h"
#include "shell_idle_fill.h"
#include "shell_coupon_probe.h"
#include "shell_settle_probe.h"
#include "shell_xtalk_probe.h"
#include "shell_tone_probe.h"
#include "shell_wait_probe.h"
#include "shell_scan_check.h"
#include "shell_panel_scan.h"
#include "hw/board.h"
#include "sdram_mem.h"
#include "instrument.h"

static bench::Board    hw;
static spky::Instrument inst;

#if SHELL_MUX_PROBE
#include "mux_scan.h"
static shell::MuxScan g_mux;
namespace {
// Ticked by the callback, read by the foreground. The foreground variant has
// to do the SAME number of steps per unit time as the callback variant, or
// the two numbers are not comparable -- pacing it off the audio block is the
// only clock both share.
volatile uint32_t g_block_tick = 0;
}
#endif

#if SHELL_COUPON_PROBE
#include "coupon_scan.h"
#endif

#if SHELL_SETTLE_PROBE
#include "settle_probe.h"
#endif

#if SHELL_XTALK_PROBE
#include "xtalk_probe.h"
#endif

#if SHELL_TONE_PROBE
#include "tone_probe.h"
#endif

#if SHELL_WAIT_PROBE
#include "wait_probe.h"
#endif

#if SHELL_SCAN_CHECK
#include "scan_check.h"
#endif

#if SHELL_PANEL_SCAN
#include "panel_scan.h"
#endif

#if defined(SHELL_CPU_PROBE)
#include <cstdint>
#include "util/CpuLoadMeter.h"
#endif

#if defined(SHELL_CPU_PROBE) || SHELL_COUPON_PROBE || SHELL_SETTLE_PROBE || SHELL_XTALK_PROBE || SHELL_TONE_PROBE || SHELL_WAIT_PROBE || SHELL_PANEL_SCAN
// libDaisy deklariert diese beiden in src/usbd/usbd_desc.c als
// `extern const char*` und definiert sie nie -- die Anwendung besitzt ihre
// eigene USB-Identitaet. Ohne sie scheitert der USB-Zweig beim LINKEN, nicht
// zur Laufzeit, was das gute Ende ist. `extern "C"`, sonst mangelt C++ die
// Namen und der C-Code findet sie nicht. Gleiche Stelle, gleicher Grund wie
// bench/report.cpp:19.
extern "C" {
const char* USBD_MANUFACTURER_STRING = "FireFlow";
const char* USBD_PRODUCT_STRING_HS   = "FireFlow Shell";
}
#endif

#if defined(SHELL_CPU_PROBE)
namespace {

// Wie lange gemessen wird. In BLOECKEN, nicht in Millisekunden, und das ist
// der Kern der Sache: ein Callback ueber Budget dehnt die Wanduhr, weil der
// naechste Block faellig ist, bevor der laufende fertig war. Eine
// Zeitschranke im Vordergrund wuerde von genau der Last verhungern, die sie
// begrenzen soll -- bench/anchor.cpp hat das 2026-07-18 auf Hardware
// erlebt: ein "4-Sekunden"-Abschnitt lief minutenlang. Blockzaehlung kann
// dieselbe Last nicht aushebeln.
constexpr float kProbeSeconds = 5.f;

daisy::CpuLoadMeter g_meter;
volatile uint32_t   g_probe_blocks = 0;
volatile bool       g_probe_done   = false;
uint32_t            g_probe_limit  = 0;

} // namespace
#endif

#if defined(SHELL_SELFTEST)
#include <cstdint>
namespace {

// Eine Sekunde: 48000 / 96 = 500 Bloecke. Grosszuegig gewaehlt. Derselbe
// Betriebspunkt erreicht auf dem Desktop seinen vollen Pegel schon in den
// ersten 0,25 s (build/render.exe, gemessen 2026-08-08: Peak 0,42371 ueber
// jedes Fenster von 0,25 s aufwaerts), es wird hier also nicht knapp.
constexpr uint32_t kSelfTestBlocks = 500;

// -60 dBFS. Weit unter den erwarteten 0,42 und weit ueber allem, was
// Rundung oder ein stehengebliebener Denormal beitragen koennten -- die
// Schwelle trennt also "Engine laeuft" von "Engine liefert nichts" und
// nicht zwei Pegel voneinander.
constexpr float kSilenceFloor = 0.001f;

volatile uint32_t g_blocks = 0;
volatile float    g_peak   = 0.f;

} // namespace
#endif

// Nur fuer die Leerlauf-Ablation (SHELL_IDLE_FILL). g_idle_never ist immer
// false und wird nie geschrieben; es steht da, damit die Schleife pro
// Iteration einen echten Ladezugriff macht, den der Compiler nicht
// wegoptimieren darf. g_idle_sink nimmt in Stellung 2 das Ergebnis auf, aus
// demselben Grund.
static volatile bool     g_idle_never = false;
static volatile uint32_t g_idle_sink  = 0;
static void AudioCallback(daisy::AudioHandle::InputBuffer  in,
                          daisy::AudioHandle::OutputBuffer out,
                          size_t                           size)
{
#if defined(SHELL_CPU_PROBE)
    // DER CALLBACK BEGRENZT SICH SELBST. Ist das Kontingent erreicht, wird er
    // schlagartig billig (Stille, sofortiges return) und gibt die CPU frei --
    // erst dadurch kommt der Vordergrund ueberhaupt wieder zum Zug und kann
    // das Ergebnis ausgeben. Ohne das bliebe eine Firmware ueber Budget im
    // Interruptkontext gesaettigt und saegte weiter DMA-Muell an die
    // Ausgaenge, ohne je etwas zu melden (bench/anchor.cpp, 2026-07-18).
    if(g_probe_done)
    {
        for(size_t i = 0; i < size; ++i) { out[0][i] = 0.f; out[1][i] = 0.f; }
        return;
    }

    g_meter.OnBlockStart();
    inst.process(in[0], in[1], out[0], out[1], size);
#if SHELL_MUX_PROBE == 1
    g_mux.step(hw);            // INSIDE the meter: that is the point
#endif
    g_meter.OnBlockEnd();

#if SHELL_MUX_PROBE == 2
    g_block_tick = g_block_tick + 1;   // outside the meter, on purpose
#endif

    if(++g_probe_blocks >= g_probe_limit) g_probe_done = true;
    return;
#endif

#if SHELL_SCAN_CHECK
    // FIRST, before process(): the read and the next select must be exactly
    // one block apart. After process() the interval would carry the
    // difference between two process() durations, and across the engine's
    // load range that eats the ~300 us of slack scan-budget.md section 3
    // found (spec 2026-09-28-coupon-panel-scan-design.md section 2).
    shell::scan_check_tick(hw);
#endif

#if SHELL_PANEL_SCAN
    // FIRST, before process(), for the same reason as the scan check above.
    shell::panel_scan_tick(hw, inst);
#endif

    inst.process(in[0], in[1], out[0], out[1], size);

#if SHELL_MUX_PROBE == 1
    g_mux.step(hw);
#endif
#if SHELL_MUX_PROBE == 2
    g_block_tick = g_block_tick + 1;
#endif

#if defined(SHELL_SELFTEST)
    // Laeuft nur die erste Sekunde und danach nie wieder -- aber der
    // Vergleich davor bleibt fuer immer im Callback stehen, und genau
    // deshalb ist der ganze Block per Default ausgeschaltet.
    if(g_blocks < kSelfTestBlocks)
    {
        float pk = g_peak;
        for(size_t i = 0; i < size; ++i)
        {
            const float a = out[0][i] < 0.f ? -out[0][i] : out[0][i];
            if(a > pk) pk = a;
        }
        g_peak   = pk;
        g_blocks = g_blocks + 1;
    }
#endif
}

// libDaisy brings every ADC channel up at SPEED_8CYCLES_5 -- the default of
// AdcChannelConfig::InitSingle(), which DaisyPatchSM::Init() takes without
// asking (daisy_patch_sm.cpp:319) and offers no way to override.
//
// Measured on the coupon, 2026-09-18: at that window a 5150 ohm source -- a
// 20k pot at mid travel -- reads 19 counts low, and SPEED_16CYCLES_5 recovers
// 18 of them. Nothing longer buys anything, and that is the half of the
// measurement worth having: 31736 counts at 16.5 cycles against 31738 at
// 387.5, over a 23x range of window, is the reading standing still. The full
// ladder is in docs/hardware/settle-measured.md section 7. The error is small
// -- about 1.2 LSB of 12 bit -- but it is systematic and in the same direction
// for every pot on the panel, and it costs one rung to remove.
//
// Re-initialising after Init() rather than patching the submodule: the pin set
// and its ORDER are repeated verbatim from daisy_patch_sm.cpp:303-317, because
// AdcHandle::GetPtr(i) hands out &dma_buffer[i] (per/adc.cpp:401) and the
// AnalogControls bound during Init() keep those pointers. The array is static,
// so the addresses survive a re-Init -- but reorder the pins here and every
// control silently reads a different pin.
//
// Not in bench::board_init(), although that is where the rest of the board
// setup lives: the bench compares CPU numbers against a history of runs, and a
// longer conversion means more DMA traffic beside the measured workload. The
// shipping firmware is where this belongs; the measuring tool keeps the board
// it has always had.
#if defined(BENCH_BOARD_PATCH_SM)
static void adc_use_measured_sampling_time(bench::Board& board)
{
    using daisy::AdcChannelConfig;
    constexpr int kAdcCount = daisy::patch_sm::ADC_LAST;

    const daisy::Pin pins[kAdcCount] = {
        daisy::patch_sm::DaisyPatchSM::C5, daisy::patch_sm::DaisyPatchSM::C4,
        daisy::patch_sm::DaisyPatchSM::C3, daisy::patch_sm::DaisyPatchSM::C2,
        daisy::patch_sm::DaisyPatchSM::C9, daisy::patch_sm::DaisyPatchSM::C8,
        daisy::patch_sm::DaisyPatchSM::C6, daisy::patch_sm::DaisyPatchSM::C7,
        daisy::patch_sm::DaisyPatchSM::A2, daisy::patch_sm::DaisyPatchSM::A3,
        daisy::patch_sm::DaisyPatchSM::D9, daisy::patch_sm::DaisyPatchSM::D8,
    };

    AdcChannelConfig cfg[kAdcCount];
    for(int i = 0; i < kAdcCount; ++i)
        cfg[i].InitSingle(pins[i], AdcChannelConfig::SPEED_16CYCLES_5);

    board.StopAdc();
    board.adc.Init(cfg, kAdcCount);
    board.StartAdc();
}
#endif

int main(void)
{
    // Takt, Caches, SDRAM und das Audioformat, dazu der boot_info-Stempel,
    // ohne den der erste SDRAM-Zugriff HardFaultet. Alles davon und die
    // Begruendung fuer den Stempel steht in src/hw/board.h -- derselbe
    // Aufruf, den auch die Bench macht, und das ist der Punkt: haetten die
    // beiden je eine eigene Init-Sequenz, waere jeder Vergleich zwischen
    // ihren Zahlen wertlos.
    bench::board_init(hw);

#if defined(BENCH_BOARD_PATCH_SM)
    // Right after the board is up and before anything reads a control: the
    // ADC is already converting by then, so this is a restart, not a setup.
    adc_use_measured_sampling_time(hw);
#endif

    // REIHENFOLGE: erst board_init(), dann init(). fx_mem() selbst ist reine
    // Zeigerarbeit, aber Instrument::init() laeuft bis in TapeEcho::Init und
    // BbdLine::Init durch, und die nullen ihre Puffer -- also echte Schreiber
    // in SDRAM, das vor board_init() noch keinen FMC hinter sich hat.
    inst.init(shell::kSampleRate, shell::fx_mem());

#if SHELL_XTALK_PROBE
    // The board under test is the coupon, and the question is whether the
    // board's own digital side moves a settled pot reading. No engine, no
    // audio: StartAudio is deliberately never called here, because the codec
    // is round two's aggressor and an image that runs it cannot measure
    // round one's floor.
    shell::run_xtalk_probe(hw);   // never returns
#endif

#if SHELL_TONE_PROBE
    // The board under test is the coupon, and the aggressor is the codec.
    // Unlike every other probe image here, this one DOES start audio -- with
    // a callback that writes a tone and nothing else. No engine: the
    // operating point has to be "the codec, and only the codec".
    shell::run_tone_probe(hw);   // never returns
#endif

#if SHELL_WAIT_PROBE
    // The board under test is the coupon, and the question is how long the
    // converter waited. The codec runs only inside the probe's arm C, with a
    // callback that writes zeros; no engine.
    shell::run_wait_probe(hw);   // never returns
#endif

#if SHELL_SETTLE_PROBE
    // The board under test is the coupon, and the question is time, not
    // wiring. No engine, no audio: this image exists to say how long a mux
    // channel takes to settle to within half an LSB.
    shell::run_settle_probe(hw);   // never returns
#endif

#if SHELL_COUPON_PROBE && !SHELL_SCAN_CHECK && !SHELL_PANEL_SCAN
    // The board under test is the coupon, not an instrument. No engine, no
    // audio, no operating point: this image exists to say whether the thing
    // is wired the way the netlist claims.
    shell::run_coupon_bringup(hw);   // never returns
#endif

    inst.set_tempo_bpm(96.0f);

    // Fester Betriebspunkt, damit ohne Bedienelemente ueberhaupt etwas
    // klingt. Task 6 ersetzt die feste Zeile durch einen echten Poti.
    //
    // Dass diese zwei Zeilen reichen, ist nicht geraten: derselbe
    // Betriebspunkt als Szenario durch build/render.exe gibt ueber 5 s
    // Peak -7,5 dBFS und RMS -26,9 dBFS (gemessen 2026-08-08). Die
    // Boot-Default-Engine ist ENGINE_SYNTH (engine/parts/part.h:107), es
    // muss also keine Klangquelle erst ausgewaehlt werden. Bleibt das Board
    // trotzdem stumm, liegt es NICHT an diesen Werten -- dann zuerst Audio-
    // Routing und Ausgangspegel pruefen, nicht an den Knoepfen drehen.
    inst.set_rate(spky::PART_A, 0.4f);
    inst.set_density(spky::PART_A, 0.6f);

#if SHELL_SCAN_CHECK
    // The engine plays at the fixed operating point above; nothing the scan
    // reads reaches it, so the point stays fixed through the run, as in every
    // earlier coupon round.
    shell::scan_check_init();
    hw.StartAudio(AudioCallback);
    shell::run_scan_check_report(hw);   // never returns
#endif

#if SHELL_PANEL_SCAN
    // The fixed point above lasts one block: from the second block on, the
    // shared control law sets every parameter from the init patch's knob
    // vector, and a pot overrides its knob with its first emission once the
    // span is valid (spec 2026-10-09-rev-a-p6b1 section 4.2).
    shell::panel_scan_init();
    hw.StartAudio(AudioCallback);
    shell::run_panel_scan_report(hw);   // never returns
#endif

#if SHELL_MUX_PROBE
    // Vier Pins als Ausgang, einer als Eingang -- mehr passiert hier nicht.
    // Die Werte, die der Scan liest, gehen ABSICHTLICH nicht in die Engine:
    // der Betriebspunkt muss derselbe bleiben wie im Basis-Image, sonst
    // vergleicht die Audiomessung zwei verschiedene Instrumente.
    g_mux.init();
#endif

#if defined(SHELL_CPU_PROBE)
    // Die Blockgroesse wird NICHT angenommen, sondern beim Board erfragt und
    // mitgemeldet. Am 8. August ist genau diese Annahme einmal schiefgegangen
    // (aus Phasendauern auf 48 Samples geschlossen, tatsaechlich 96), und
    // eine Last in Prozent ist ohne die Blockgroesse, gegen die sie gerechnet
    // wurde, ohnehin bedeutungslos.
    const float  probe_sr = hw.AudioSampleRate();
    const size_t probe_bs = hw.AudioBlockSize();
    g_meter.Init(probe_sr, static_cast<int>(probe_bs));
    g_probe_limit  = static_cast<uint32_t>((kProbeSeconds * probe_sr)
                                           / static_cast<float>(probe_bs));
    g_probe_blocks = 0;
    g_probe_done   = false;

    hw.StartAudio(AudioCallback);
#if SHELL_MUX_PROBE == 2
    // Der Vordergrund-Scan, getaktet am Audioblock. NICHT freilaufend: er
    // muss pro Zeiteinheit genau so viele Schritte schaffen wie die
    // Callback-Variante, sonst vergleicht die Runde zwei Arbeitsmengen und
    // nicht zwei Platzierungen.
    uint32_t last_tick = 0;
    while(!g_probe_done)
    {
        const uint32_t t = g_block_tick;
        if(t != last_tick)
        {
            last_tick = t;
            g_mux.step(hw);
        }
    }
#else
    while(!g_probe_done) { }          // der Callback begrenzt sich selbst
#endif
    hw.StopAudio();

    // USB ERST JETZT hochfahren, nach der Messung. USB-CDC kostet auf diesem
    // Board 6370 Zyklen pro Block (0,66 %) durch den SOF-Interrupt
    // (docs/bench/2026-08-07-transport-semihost-vs-usb.md). Waere der Log
    // vorher offen, stuende dieser Aufschlag in der Zahl, die er melden soll.
    hw.StartLog(false);

    const uint32_t avg = static_cast<uint32_t>(g_meter.GetAvgCpuLoad() * 10000.f);
    const uint32_t mx  = static_cast<uint32_t>(g_meter.GetMaxCpuLoad() * 10000.f);
    const uint32_t mn  = static_cast<uint32_t>(g_meter.GetMinCpuLoad() * 10000.f);

    // Endlos wiederholt, damit ein Host, der den Port erst spaeter oeffnet,
    // das Ergebnis trotzdem bekommt -- es gibt hier keinen Handshake.
    while(1)
    {
        // steps= ist kein Beiwerk: die Vordergrund-Variante ist nur dann
        // gratis, wenn sie MITKOMMT. Ein Rueckstand gegen blocks= ist der
        // eigentliche Befund und darf nicht als Prozentzahl unsichtbar sein.
        hw.PrintLine("SHELL_CPU sr=%d block=%d blocks=%d avg=%d max=%d min=%d "
                     "mux=%d steps=%d hundredths_pct",
                     static_cast<int>(probe_sr), static_cast<int>(probe_bs),
                     static_cast<int>(g_probe_limit),
                     static_cast<int>(avg), static_cast<int>(mx),
                     static_cast<int>(mn),
                     static_cast<int>(SHELL_MUX_PROBE),
#if SHELL_MUX_PROBE
                     static_cast<int>(g_mux.steps()));
#else
                     0);
#endif
        hw.Delay(500);
    }
#endif

    hw.StartAudio(AudioCallback);

    // Kein Rueckweg in den Bootloader von hier aus, anders als in der Bench:
    // die Bench springt nach BENCH_END selbst nach DFU, weil sie wiederholt
    // geflasht wird. Der Shell soll laufen. Neu flashen heisst deshalb
    // RESET, dann BOOT im Zwei-Sekunden-Fenster -- steht auch im README.

#if defined(SHELL_SELFTEST)
    // Das Submodule hat keine Klinkenbuchse, also kann niemand hoeren, ob
    // die Engine Ton macht. Die User-LED sagt es stattdessen, und zwar in
    // vier unterscheidbaren Zustaenden -- der Grund fuer vier statt zwei
    // ist, dass "LED dunkel" sonst gleichzeitig "still" und "haengt beim
    // Booten" hiesse, und das waere kein Beweis, sondern ein Raetsel:
    //
    //   dunkel und bleibt dunkel  -> main() kam nie bis hierher.
    //                                Init, SDRAM oder StartAudio.
    //   schnelles Flackern (10 Hz) -> wir warten, der Callback kommt nicht
    //                                oder nicht oft genug durch.
    //   Dauerlicht                 -> Callback lief 500 Bloecke und der
    //                                Ausgang fuehrte Signal. Das ist der
    //                                Beweis, um den es geht.
    //   langsames Blinken (2 Hz)   -> Callback lief, Ausgang war still.
    //
    // Das Flackern waehrend des Wartens ist nicht Dekoration: ohne es
    // waere die Wartephase von "nie angekommen" nicht zu unterscheiden.
    while(g_blocks < kSelfTestBlocks)
    {
        hw.SetLed(true);
        hw.Delay(50);
        hw.SetLed(false);
        hw.Delay(50);
    }

    const bool signal = (g_peak > kSilenceFloor);
    while(1)
    {
        if(signal)
        {
            hw.SetLed(true);
            hw.Delay(1000);
        }
        else
        {
            hw.SetLed(true);
            hw.Delay(250);
            hw.SetLed(false);
            hw.Delay(250);
        }
    }
#elif SHELL_MUX_PROBE == 2
    // Ohne diese Schleife scannt das Audio-Image in Stellung 2 gar nichts --
    // und eine Aufnahme, die nichts misst, sieht aus wie eine, die nichts
    // findet.
    uint32_t idle_tick = 0;
    while(1)
    {
        const uint32_t t = g_block_tick;
        if(t != idle_tick)
        {
            idle_tick = t;
            g_mux.step(hw);
        }
    }
#else
#if SHELL_IDLE_FILL == 0
    // Sprung auf sich selbst. Der Kern fasst hier keinen Speicher an und
    // holt nach dem ersten Durchlauf nicht einmal mehr eine Instruktion --
    // das ist der leiseste Leerlauf, den dieses Board haben kann, und es
    // ist der, mit dem alle Audio-Bilder dieses Tages gemessen wurden.
    while(1) {}
#elif SHELL_IDLE_FILL == 1
    // Die Form, die das CPU-Sonden-Bild hat: pro Iteration ein Ladezugriff
    // auf ein volatile. Kein Rechenaufwand, nur Speicherverkehr. Wenn die
    // 15,5 dB Unterschied zwischen den beiden Bildern daran haengen, muss
    // DIESE Stellung sie reproduzieren -- und zwar ohne dass sich am
    // Callback ein Byte geaendert hat.
    while(!g_idle_never) { }
#else
    // Speicherverkehr plus echte ALU-Arbeit. Nicht als Betriebsmodus
    // gedacht, sondern als drittes Stuetzpunkt: liegt 2 noch tiefer als 1,
    // skaliert der Effekt mit der Leerlaufauslastung, statt nur zwischen
    // "leer" und "nicht leer" zu springen.
    uint32_t acc = 1u;
    while(!g_idle_never)
    {
        for(int i = 0; i < 64; ++i) acc = acc * 1664525u + 1013904223u;
        g_idle_sink = acc;
    }
#endif
#endif
}

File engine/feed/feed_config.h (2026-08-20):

#pragma once

namespace spky {
namespace feed_cfg {

// --- PHASE UNITS ----------------------------------------------------------
//
// fast_sin(p) == sin(2*pi*p) (engine/util/fast_sin.h), so EVERY quantity in
// this engine that is added to a phase is in CYCLES, not radians. One cycle is
// the 2*pi of the classical FM literature: an "index of 6" from a DX7 table is
// kIndexMaxCycles ~= 0.95 here. The three constants this applies to are
// kIndexMaxCycles, kFbBaseCycles and everything the DAMP one-pole carries,
// because it filters a cycles-valued signal.

// --- P, the one number here that is not a taste decision ------------------
//
// P is MEASURED, on a Daisy Patch Submodule over USB at -O2, AXI layout, three
// sweep points at kPairs 2 / 4 / 8. `-O3` did not enter it and cannot: the
// `system` family overflows SRAM_EXEC by 2844 B there, and did so before FEED
// existed. No Seed figure entered it either.
//
// **18 655 cycles per pair**, from a least-squares fit over the three
// `feed_pairs` points (39 110 / 77 176 / 151 190 average cycles), with about
// 2 100 cycles of fixed overhead -- so the row is very nearly pure per-pair
// cost. The two adjacent slopes are 19 033 and 18 504, a ratio of 0.972, which
// is what makes the fit worth quoting at all. The whole-engine row agrees
// independently: `inst_feed_engine_worst` fits 18 708 cycles per pair per deck.
//
// P follows from the 960 000-cycle block budget as measured on
// `inst_feed_engine_worst` -- BOTH decks on FEED, worst-case knobs -- whose
// maximum fits 39 904*P + 634 516. Measured: P=2 74.0 %, P=4 83.3 %, P=8
// 99.2 %. A ~9 % reserve puts the ceiling at 6.95 pairs, and rounding DOWN to
// a multiple of kPairsPerTone gives 6.
//
// The reserve is not a formality. The worst-case row runs with **FLUX off**
// (as the BBD row does), so none of those percentages include stereo tape,
// which is one switch away and prices at 10.3 % on its own. P=8 measured 99.2 %
// and would have had no room for it at all.
//
// CONFIRMED by its own run rather than left on the interpolation, because 6 is
// not one of the sweep points: `inst_feed_engine_worst` measures **92.51 %**
// against the fit's 91.04 %, so the linear fit runs about 1.6 % optimistic
// between its points. The reserve that actually survives is therefore **7.5 %**,
// not the 9 % the derivation aimed at -- and the number to quote is 92.51.
// FEED still sits far under the same image's `instrument_worst` (102.76 %),
// which is Task 11's gate.
//
// P=6 also decides how much of a chord is heard: the bank voices
// kPairs/kPairsPerTone tones, capped at ChordBuilder::kMaxNotes = 4. So 6 pairs
// sound 3 of the 4 tones COLOR reaches at its top -- a complete triad, with
// only the fourth note dropped at the very end of the knob. P=4 would have
// sounded two.
constexpr int kPairs = 6;

// Set 2026-08-19 by the sweep cited above.
// docs/bench/2026-08-19-f836a32-feed-axi-o2-patch_sm-usb.md   (P=2)
// docs/bench/2026-08-19-500775c-feed-axi-o2-patch_sm-usb.md   (P=4)
// docs/bench/2026-08-19-ab0a6bf-feed-axi-o2-patch_sm-usb.md   (P=8)
// The gate "feed G8" in tests/test_feed_engine.cpp failed while this was
// false, so an undecided P could not reach main.
constexpr bool kPDecided = true;

// --- structure ------------------------------------------------------------

// The control-rate raster. Must equal SynthEngine::kCtrlInterval; the
// static_assert lives in feed_engine.cpp, where both headers are visible.
constexpr int kCtrlInterval = 96;

// How many chord tones the bank voices. SPREAD detunes the pairs sharing one
// tone against each other, so a tone holding a single pair has nothing to beat
// against and SPREAD would go dead at exactly the chord size COLOR reaches
// (plan open point 4). Every voiced tone keeps a group of at least two.
constexpr int kPairsPerTone = 2;
static_assert(kPairs >= kPairsPerTone,
              "a bank must hold at least one full tone group");
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

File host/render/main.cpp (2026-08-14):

#include <cstdio>
#include <cstddef>
#include <string>
#include <vector>
#include "instrument.h"
#include "render/scenario.h"
#include "shared/wav_reader.h"
#include "shared/wav_writer.h"

using namespace spky;

// FX memory, injected per the engine's no-heap contract (FxMem pattern).
static float s_echo[spky::PART_COUNT][2][spky::Flux::kMaxSamples];
// The BBD part engine's two lines per deck, same static idiom as the echo
// buffer above: 32 KB per line, 128 KB in total.
static float s_bbd[spky::PART_COUNT][2][spky::BbdEngine::kCells];
static spky::AmbientReverb s_reverb;

// M5 texture deck: one 42 s stereo record buffer per part (spec 2026-07-18
// sampler-texture-deck-design.md: "Sizing follows the original: 42 s stereo
// per part... Desktop: heap"). Left unallocated, FxMem::sampler_buf stays
// nullptr and every part's sampler runs silent -- the render host would
// "succeed" while recording nothing, which is exactly the silent-failure
// shape this task is supposed to avoid. Heap (not the echo idiom's static
// arrays): two of these are ~32 MB, too large to want living in the binary.
static constexpr double kSamplerBufferSeconds = 42.0;

int main(int argc, char** argv) {
    if (argc < 2) {
        std::printf("usage: render <scenario.json> [out.wav] [mods.csv]\n");
        return 1;
    }
    std::string scen_path = argv[1];
    std::string wav_path  = argc > 2 ? argv[2] : "out.wav";
    std::string csv_path  = argc > 3 ? argv[3] : "mods.csv";

    Scenario scen;
    std::string err;
    if (!load_scenario(scen_path, scen, err)) {
        std::printf("scenario error: %s\n", err.c_str());
        return 2;
    }

    Instrument inst;
    FxMem fx_mem;
    for (int p = 0; p < PART_COUNT; ++p) {
        fx_mem.echo[p][0] = s_echo[p][0];
        fx_mem.echo[p][1] = s_echo[p][1];
        fx_mem.bbd[p][0] = s_bbd[p][0];
        fx_mem.bbd[p][1] = s_bbd[p][1];
    }
    fx_mem.reverb = &s_reverb;

    const size_t sampler_frames =
        static_cast<size_t>(kSamplerBufferSeconds * scen.sample_rate);
    std::vector<SampleBuffer::Frame> sampler_mem[PART_COUNT];
    for (int p = 0; p < PART_COUNT; ++p) {
        sampler_mem[p].assign(sampler_frames, SampleBuffer::Frame{ 0.f, 0.f });
        fx_mem.sampler_buf[p] = sampler_mem[p].data();
    }
    fx_mem.sampler_frames = sampler_frames;

    inst.init(static_cast<float>(scen.sample_rate), fx_mem);
    inst.set_tempo_bpm(scen.bpm);

    for (const auto& e : scen.init_events) apply_event(inst, e);

    WavData in_wav;
    if (!scen.input_wav.empty()) {
        std::string in_err;
        if (!read_wav(scen.input_wav, in_wav, in_err)) {
            std::printf("input_wav: %s\n", in_err.c_str());
            return 4;
        }
        // Fix 5: samples are fed in per-sample below with no resampling, so
        // a rate mismatch silently plays the input at the wrong pitch.
        // Resampling is out of scope here -- just make the mismatch loud.
        if (in_wav.sample_rate != scen.sample_rate) {
            std::fprintf(stderr,
                "warning: input_wav %s is %d Hz but the scenario runs at %d Hz; "
                "no resampling is performed, so the input will play at the wrong pitch\n",
                scen.input_wav.c_str(), in_wav.sample_rate, scen.sample_rate);
        }
    }

    WavWriter wav(scen.sample_rate);
    FILE* csv = std::fopen(csv_path.c_str(), "wb");
    if (csv) {
        std::fprintf(csv, "t,"
            "a_src,a_size,a_pitch,a_motion,a_level,a_pcv,a_gate,"
            "a_fx0,a_fx1,a_fx2,a_fx3,a_fx4,a_voices,a_v0,a_v1,a_v2,a_v3,a_pgate,a_fill,a_grains,a_slices,a_exc,a_matl,"
            "a_fclk,a_stages,a_div,a_frz,a_tclamp,a_strunc,"
            "b_src,b_size,b_pitch,b_motion,b_level,b_pcv,b_gate,"
            "b_fx0,b_fx1,b_fx2,b_fx3,b_fx4,b_voices,b_v0,b_v1,b_v2,b_v3,b_pgate,b_fill,b_grains,b_slices,b_exc,b_matl,"
            "b_fclk,b_stages,b_div,b_frz,b_tclamp,b_strunc,"
            "morph,couple,drift,weather,phase_err\n");
    }

    const size_t total = static_cast<size_t>(scen.duration_s * scen.sample_rate);
    const int    csv_decim = 64;
    size_t next_event = 0;

    for (size_t i = 0; i < total; ++i) {
        double t = static_cast<double>(i) / scen.sample_rate;
        while (next_event < scen.events.size() && scen.events[next_event].time_s <= t) {
            apply_event(inst, scen.events[next_event]);
            ++next_event;
        }

        const float in_l = i < in_wav.l.size() ? in_wav.l[i] : 0.f;
        const float in_r = i < in_wav.r.size() ? in_wav.r[i] : 0.f;
        float l = 0.f, r = 0.f;
        inst.process(&in_l, &in_r, &l, &r, 1);
        wav.push(l, r);
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

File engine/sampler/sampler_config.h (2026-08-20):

#pragma once
#include <cstddef>

// Tuning constants for the M5 texture deck (spec 2026-07-18
// sampler-texture-deck-design.md). Values marked "ear-tunable" are taste,
// not contract -- changing them changes the sound, not the correctness.
namespace spky {
namespace sampler_cfg {

// --- record core (carried over from src/core/config.h:57,73) ---
// 192 samples == 4 ms @ 48 kHz, and == the hann table size in fx_util.h, so
// the fade counter indexes the curve 1:1. TRAGEND ist die zweite Gleichung:
// die Tabellengroesse. Die 4 ms gelten nur bei 48 kHz -- dies ist eine
// Sample-Zahl, waehrend _cut (SoftSwitch) ueber init(sample_rate) echte 4 ms
// haelt, sodass die beiden bei anderen Raten auseinanderlaufen.
constexpr size_t kRecordFade      = 192;
// Knob position. NOTE: this sits ABOVE kFbKnee, so it means something
// slightly different than it did in M5a -- about -1.8 dB (linear ~0.817)
// rather than -3 dB, but ONLY once something calls set_feedback(0.95) and
// runs it through the post-knee curve above. SampleBuffer::init() does not:
// it computes _feedback directly with the pre-knee formula
// (60*(kDefaultFeedback - 1) dB, i.e. -3 dB / ~0.708 linear) and never calls
// set_feedback() itself, so the actual boot state -- before any host pushes
// the knob -- is still the M5a -3 dB, unchanged. -1.8 dB / 0.817 is what the
// knob reads once a host (or a test, see F-06 below) explicitly sets it to
// this position; it is not what plays on power-up.
constexpr float  kDefaultFeedback = 0.95f;

// Record-feedback knee. Below this the mapping is the M5a one exactly:
// knob n gives -60 + 60*n dB, so 0.9 is -6 dB. Above it, travel runs from
// -6 dB on to kFbMaxDb, and the buffer saturates into itself.
//
// Unity is consequently NOT at the top of travel but at knob ~0.971 -- a
// narrow but findable spot where the loop sustains forever. Ear-tunable:
// lowering kFbMaxDb widens that spot, raising it narrows it.
constexpr float  kFbKnee   = 0.9f;
constexpr float  kFbMaxDb  = 2.5f;
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

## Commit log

2026-08-04 bench(bbd): a row whose stage count walks, so the crossfade is priced
    Every existing row holds its division fixed and never enters the
    transition branch. Appended, not inserted. The walk period is 24 samples
    because sixteen read events is about 24 samples at the ceiling clock.
    Also corrects the write-ring comment a183852 invalidated.
    [run.py]
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2026-08-04 rename: spotymod becomes FireFlow, with a clean slug break
    Firefly was the first candidate and lost to a collision: ZetaCarinae already
    ships a Firefly in the VCV Library, and it is a phase-coupled oscillator — the
    same corner this instrument's Kuramoto COUPLE lives in. FireFlow keeps the
    image without the neighbour. A mod-based name was the earlier plan and died
    once MOD turned out to be a printed panel caption of its own.
    The slug break is deliberate: plugin and module both go Spotymod -> Fireflow
    rather than hiding the old slug behind a new display name, so existing VCV
    patches containing the module will lose it. Accepted because the plugin is not
    in the official Library, ships only th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
    [run.py, sampler_config.h]
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2026-08-05 feat(render): scenarios learn to ride the flow layer
    Wires host/render/main.cpp and scenario.{h,cpp} up to the Task 6/7 Flow
    runtime: any scenario containing a flow_* action gets a live Flow ticked
    once per control block (ctrl_hz = sample_rate / Center::kCtrlInterval,
    the same 96-sample raster the rest of the engine already ticks on), fed
    through a new apply_event(Instrument&, flow::Flow*, const Event&)
    overload. flow_wake decodes a terrain code (hard error on a malformed
    one, never a silent fallback seed); flow_macro/flow_cv/flow_new/
    flow_new_partial/flow_undo/flow_lock drive the rest. A scenario with no
    flow_* action never constructs a Flow, so its render stays byte-for-byte
    identical (co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
    [main.cpp]
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2026-08-06 fix(flow): mode and step count are one push, so steps can never run without a grid
    Glow shipped with apply_param hardcoding STEP mode on (the P_STEPS_A/B cases
    passed a literal true) while nothing ever called Instrument::set_sync -- every
    terrain ran a step sequencer at a free-running rate, with no clock grid.
    set_step() takes mode AND count together and set_sync() is global across both
    parts, so routing them correctly needs all three values at once, which a
    per-param stateless apply_param cannot see.
    Moved P_MODE + P_STEPS_A/B out of apply_param into a new
    Flow::push_mode_and_steps(bool force), called from the tail of
    recompute_and_push once all three are in _pushed[]. Added Instrument::st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
    [instrument.h]
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2026-08-06 test(flow): the step counts were never watched arriving at the instrument
    push_mode_and_steps is the only path by which P_STEPS_A/B reach the engine
    now -- apply_param drops them on the floor. Nothing observed the far side of
    that boundary: test_flow_new and test_flow_audio read param_now(P_STEPS_*),
    which is the Flow side. Swapping sa and sb, or pushing a constant 8, left the
    whole suite green. The gap pre-dates the branch, but the branch is what moved
    this wire.
    Instrument gets deck_steps(p) beside step_on/synced, and a new case asserts
    both decks' counts against int(param_now + 0.5f) over 200 masters. It tracks
    saw_differing, because while both decks agree the equality holds just as well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
    [instrument.h]
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2026-08-07 bench(qspi): the bank stops squatting on the bootloader's app address
    0x90040000 is where dfu-util puts a BOOT_SRAM image. The wave bank has
    been sitting there since the beginning and nobody noticed, because with
    a probe attached openocd loads SRAM directly and QSPI belongs to the
    bank alone. Without a probe the two collide.
    The bank moves to 0x90100000. The shipping firmware links the same
    script and had the same defect.
    The address turned out to live in nine files, not the three the plan
    listed: the programmer writes it as a chip offset, the audition config
    verifies against it, and three test files assert on it as a literal.
    All of them moved together -- a partial move would have left th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
    [audition.cfg]
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2026-08-07 bench(run): find the port by what was not there a moment ago
    The board is in DFU while it is being written and enumerates as CDC only
    once the loaded image runs, so the port cannot be named in advance. This
    desk already has a COM5 that is not the board, so "the only port" and
    "the lowest port" both pick wrong. What is left is: whatever appeared
    after the image started.
    Failure to appear is now a distinct, named error rather than a confusing
    open() failure -- it is exactly what a CDC buffer sitting in DTCM would
    look like, and that is the failure this stage exists to catch early.
    [run.py]
2026-08-07 bench(qspi): prove the bank by reading it back, when there is no probe
    Stage two refused to start, correctly: the receipt binds the bank to the
    ELF that was measured, and the USB branch is a different ELF. The bank on
    the chip was already right -- it was unprovable, which is the same thing
    as wrong for a fail-closed gate.
    verify_qspi_over_dfu uploads the bank and compares on the host. It reads
    and never writes, so a bad compare costs nothing but the refusal. The
    receipt now records WHICH evidence it holds: the SWD path still reports
    an MCU UID read out of the silicon, the DFU path can only offer the
    bootloader's serial. Both are accepted; neither is silently mistaken for
    the other.
    This wa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
    [qspi_tools.py, run.py]
2026-08-07 Revert "bench(qspi): prove the bank by reading it back, when there is no probe"
    This reverts commit d5a1cfa4cc36f29723fc63d2a9c8d3420c391ec4.
    [qspi_tools.py, run.py]
2026-08-07 bench(run): without a probe, the firmware is the witness
    The DFU readback the spec planned does not exist. The Daisy bootloader
    answers an upload from QSPI with one 4 KB block repeated over the whole
    range -- read at 0x90000000, 0x90040000 and 0x90100000 and you get the
    same bytes three times. It is not weak evidence, it is no evidence, and
    the commit that built on it was reverted.
    What replaces it was already there and is stronger: the firmware hashes
    the bank in place and prints the digest in BENCH_BEGIN. That is the
    digest of the bytes the measured code actually read -- not of a host
    file, not of a readback taken at another moment. run_once_usb now checks
    it as line one arrives, so a wro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
    [run.py]
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2026-08-07 bench(run): wait for the board to come back before writing to it
    Repeat 1 completed cleanly over USB -- header, rows, BENCH_END, digest
    checked. Repeat 2 died instantly: after BENCH_END the board jumps into
    the bootloader and re-enumerates, and dfu-util called into that
    second-or-two gap exits 74.
    The self-reset is what makes an unattended repeat possible; it just
    needs the host to notice that USB takes a moment. Also covers the first
    run, where "no board in DFU" now says which two buttons to press instead
    of surfacing a CalledProcessError traceback.
    [run.py]
2026-08-07 bench: the same seed, down a wire it has never used
    Stage two of three, and the answer is not the one the plan hoped for.
    The transport is NOT neutral: USB-CDC costs 6370 cycles per block, 0.79
    percentage points of the budget, in both repeats.
    That is not noise. Within a transport the spread is 3 cycles (usb) and
    23 (semihost). Between them it is 6370 -- two hundred times the noise,
    and identical across repeats. Checksums match on all four runs and match
    2026-08-04, so the arithmetic never changed.
    The memory map was the obvious suspect and is innocent. The USB branch
    costs 7224 more bytes of SRAM_EXEC, but g_axi_layout_guard holds: all
    six measurement-object symbols sit at identical addre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
    [2026-08-07-a74c876-regress-axi-o3-usb.csv]
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2026-08-07 bench: the harness learns there is a second board
    BENCH_BOARD=seed|patch_sm and run.py --board, plus the board in the capture
    filename and in every CSV row. The evidence document stops saying "Measured
    on a Daisy Seed" as a constant -- the first submodule capture would have
    claimed it came off the board it exists to be compared against.
    The define goes through a generated header like the transport, not through
    C_DEFS: a bare -D is invisible to Make, and switching boards in an existing
    build directory would relink a stale main.o or anchor.o carrying the other
    board's init -- a wrong number wearing a right label.
    The board enters the filename only when it is not `seed`, the same rule the
    tra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
    [main.cpp, run.py, write_bench_board.py]
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2026-08-09 grit: cover the bipolar mapping with tests, not just source-text greps
    Add doctest coverage of the sign/magnitude/dead-zone mapping (negative
    engages Reduce, positive engages Drive, both stay engaged; the dead-zone
    boundary is off with zero mix on both signs; full deflection reaches mix
    1.0) via new grit_*_for_test() observers on Instrument/Grit. Proved RED by
    temporarily restoring the raw-value fx_on gate the previous commit fixed.
    Also close the drift risk between the two duplicated host-mapping copies
    (Fireflow.cpp, bench/audition/init_patch.cpp): a scraper test in
    test_panel.py asserts the kGritDead constant and the mix formula agree
    verbatim across both files, proved RED both by a valu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
    [instrument.h]
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2026-08-09 feat(vcv): FF_hw_Init replaces the drone.vcvm factory patch
    54 of the 68 values move, including both ENG selections: deck A boots WAVE
    against SYNTH on deck B, where the old snapshot paired SYNTH with BODY.
    This is a different instrument at boot, not a retune, so the per-value
    notes that justified individual numbers by what they preserved from
    drone.vcvm are gone with the numbers they defended.
    Two consequences worth naming. Both decks now boot INSIDE the compressor
    zone (amount 0.406 and 0.525, roughly +7.1 and +10.9 dB of make-up), which
    no earlier factory patch did -- set by ear on the reshaped kCompShape
    taper, so the values only mean what they mean with that taper. And no deck
    boots BO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
    [instrument.h]
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2026-08-12 fix(flow): COLOR is the chord size, and half the terrains could not reach it
    Playing a real transferred patch found two audible losses the converter
    could not see, because both live downstream of it.
    COLOR is not a timbre tint. ChordBuilder::set_color counts the chord's
    tones over fixed zone edges, so under kEdge2 = 0.125 a deck voices
    exactly one note. It was a target of M_DENSITY's "thick" variant alone;
    M_DENSITY had two variants and generate() picks one uniformly. On the
    losing half, terrain.cpp's stage-4 else-branch left COLOR at its curve's
    bp[0] -- drawn from the {0, .1} band, entirely below the edge -- with
    storied[] false, so no macro, no weather offset and no veto could reach
    it.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
    [instrument.h]
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2026-08-12 fix(center): the external clock snap anchors on the previous pulse
    clock_pulse() encoded "one pulse == one transport beat" as round(_beats).
    Once the transport is paced that is wrong twice over: at x1/32 the beats
    advance 0.03125 between pulses and round() snaps them back, freezing the
    transport at beat 0 while the lanes keep running.
    Snapping to a multiple of pace fixes that but not the second half --
    _beats is the integral of bpm*pace, so after a pace change _beats/pace is
    not the real beat count and a zero-anchored grid jumps on every pulse
    while the knob moves. The anchor is the previous pulse. At pace 1 the
    expression is bit-identical to what it replaced.
    The pace is passed, never sto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
    [instrument.h]
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2026-08-12 test(engine): gate PACE against a compounding set_tempo_bpm, fix two stale comments
    Review of 6e605ec found the invariant the whole task rests on had no gate:
    every pace test case runs set_tempo_bpm only once (or at pace x1, where
    folding pace into _bpm is a no-op), so an implementation that writes
    `_bpm = bpm * _pace;` inside set_tempo_bpm passed all four existing cases
    and every pre-existing tempo test. Added a case that pushes the same raw
    bpm twice at pace x4 and checks the transport BPM does not move between
    calls -- a compounding implementation fails immediately (this stub in fact
    already misses on the FIRST call, landing at 1600 instead of 400, not just
    drifting further on the second;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
    [instrument.h]
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2026-08-12 test(engine): gate PACE on wraps per unit time, not on Hz
    Every rate observer in the engine reports the COMMANDED rate, which stays
    perfectly correct while a lane is frozen -- so a stalled accumulator
    would pass every other gate in this design green. This one drives it
    through the whole fan-out (Instrument::process()), not a bare lane, so a
    missing set_pace fan-out or a grid-servo fight would show too.
    It compares TURNS (wraps + the fractional phase remainder), not raw wrap
    counts: raw wraps are integers, and at the low end of PACE that loses too
    much resolution for a relative tolerance to mean anything -- knob 0.f owes
    well under one full wrap in the test window, and a stalled lane reports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
    [instrument.h]
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2026-08-12 docs(flow): the fix wave for the whole-branch PACE review
    Six comment/doc/metadata-only fixes from the final whole-branch review of
    2026-08-12-modulation-pace: the twelfth stale-comment finding
    (_apply_tempo() still described FLUX as mis-tracked at PACE != 1, three
    lines above the fix that landed in 5bf62f3), a missing direct include for
    pace_mult(), two VCV tooltip comments that invited multiplying PACE into a
    grid branch that must not have it, an honest BLEND/CLOCK grouping comment
    in the hardware panel generator (regenerated artefacts confirmed
    byte-identical), a documented dependency on Flow's change guard in two
    render scenarios, and a param-map wording fix. No behaviour changed.
    Co-Au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
    [instrument.h]
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2026-08-13 fix(mod): make both FLOW-melody mode-entry paths agree
    set_step() and set_flow_melody() are twins -- either can change what
    _effective_length() returns and either can leave a slot index behind -- but
    they had drifted apart at the seam between tasks 2 and 8.
    set_flow_melody(false) changed the effective length without flagging
    length_pending, which is precisely the premise set_step()'s length check
    depends on: that check is a DELTA (old_len captured before its assignments),
    so it is only meaningful while old_len is the length the pattern was last
    generated at. A note deck in FLOW swapped to SAMPLER/BBD and then put into
    STEP at an unchanged STEPS therefore kept its 8-slot melody groove: the
    r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
    [instrument.h]
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2026-08-16 feat(engine): expose the modulation excursion for the LED law
    target_raw() computed the modulation term inline and threw it away into
    base + mod. The LED display needs that term alone -- showing target_value()
    would show the knob, which is what the design explicitly rejects. Extracted
    as Part::_mod_term() and exposed as lane_excursion() on both Part and
    Instrument, so the display and the audio path read one expression and cannot
    drift apart. No behaviour change: all six tests green, both render hashes
    unmoved.
    [instrument.h]
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2026-08-16 feat(vcv): drive the hardware panel's 21 lamps
    The widget now does nothing but call the law and copy the result, at a
    64-sample divider so the update rate is close to the 500 Hz block rate the
    hardware will have. Brightness is quantised to 16 steps in Rack too, via one
    kLedSteps constant shared by the fill() call and the setBrightness divisor
    so the two can't drift apart -- that raster is what the mux scan gives the
    hardware for free, and a module that breathes more finely than the panel
    can is validating itself against the wrong instrument.
    REC keeps its 2 Hz pulse and three-state behaviour (ruling R16: blink itself
    runs at 1 Hz for the phrase lamps' windows, so REC reads it at double rate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
    [instrument.h]
2026-08-16 fix(vcv): the REC lamp's fill states were darkened, not preserved
    Withdrawing task 7's report claim that the REC lamp "kept its behaviour" and
    had "no visible change" -- that was wrong. duty() is a quantiser AND a
    perceptual gamma (pow(v, 2.2)); the REC lamp's three constants (1.f dim
    pulse 0.25f, fill range 0.15f..0.70f) were tuned by eye as Rack setBrightness
    LIGHT values, long before this law existed. Feeding them through duty()
    reinterpreted them as perceptual values and darkened them: the dim half of
    the recording pulse (0.25) and "just started recording" (fill 0.15) both
    landed on the same single step, and the fill meter read flat from 0% to 37%
    of the buffer.
    Added duty_from_light(),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
    [instrument.h]
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2026-08-16 feat(hw): SONG flashes the A/B switch; STEPS lamp leaves the plate
    The double-pulse on snapshot B was unreadable once FLOW melody started
    advancing SONG. The lamp now fires a 150 ms flash on the edge and stays
    dark otherwise. FLOW_* keep their LightIds but are no longer drawn.
    TEMPO ticks the transport beat. Knob lamps sit in the caption cluster;
    the limiter lamp sits outboard of OUT R.
    [instrument.h]
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2026-08-19 feat(feed): ENGINE_FEED = 6, a silent engine and its tripwires
    The sixth part engine's id, config header and shell. Appended before the
    ENGINE_COUNT sentinel, which fired the build-time tripwire in
    tests/test_deck_bus.cpp as designed -- recorded in the task report.
    kPairs carries a placeholder and kPDecided is false: P is the feed_pairs
    bench's to decide (spec section 8), and feed G8 fails until it has.
    [feed_config.h]
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2026-08-19 docs(engine-map): FEED's regime map -- where the coupling tips
    BOND x DEPTH x RATIO x SPREAD on FeedBank at 48 kHz, measured, not inferred.
    Gives section 9.9 its BOND threshold (0.7) and cent tolerance (2.0 ct) and
    confirms SPREAD's knee; three later tasks read their constants off this section
    rather than inventing them.
    Three findings the map was not looking for, all of them load-bearing:
    - kFbBaseCycles was past the edge. At its first-try 0.30 cycles (1.885 rad)
    the pitch centre is already gone at BOND 0 -- +49.6 ct on ONE pair with no
    coupling and no spread, because a feedback-FM operator stops being periodic
    at its carrier past beta = 1 rad and the two-sample average lifts that l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
    [feed_config.h]
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2026-08-19 test(feed): red-proof the gate set, and fix the three that could not go red
    Task 12 Step 3, run as an automated mutation sweep: patch one source, rebuild,
    run the NAMED gate, revert. 21 mutations. The harness itself needed fixing
    first -- its initial run reported all 20 "still green", which was subprocess
    shell=True resolving to cmd.exe so every `bash -lc` failed with empty stdout
    that the detector read as a pass. It now runs Git Bash explicitly (a bare
    `bash` here is WSL, whose /mnt/c paths make CMake refuse the build directory)
    and treats a missing doctest summary as a harness error rather than a green.
    18 of 21 mutations redden their named gate, 2 at compile time (G1's census
    under a ren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
    [feed_config.h]
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2026-08-19 bench(feed): first hardware figures, on the Patch Submodule over USB
    Two runs, every gate green, profile `feed` at -O2/AXI. FEED is the cheapest
    engine in the instrument: both decks on FEED cost 77.52 % of the block budget
    at peak against 102.59 % for both on SYNTH. The ring alone (`feed_pairs`,
    4 pairs, worst case) reads 8.14 %.
    What this does NOT settle is P. 8.14/4 = 2.03 % per pair is an upper bound on
    the slope, not a measurement of it -- one point cannot separate a linear loop
    from one with a fixed overhead, which is why the row is documented as one row
    across several builds. `kPDecided` stays false and G8 stays red.
    Taken over the USB transport, so every row carries the +0.66 % surc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
    [2026-08-19-3bdcb17-feed-axi-o2-usb.csv]
2026-08-19 feat(feed): a real filter, a harder drive, and level parity
    Three findings from a listening session, each measured before it was changed.
    FILT was not a filter. It drove a one-pole INSIDE the feedback path, and
    Bastian reported the knob as doing nothing. Three reasons, each sufficient:
    it never touches the carrier, the signal it filtered peaks at kFbBaseCycles,
    and its coefficient was already 0.34 at the detent and 0.98 at the top, so the
    upper third of the travel was indistinguishable from wide open. It is an SvfLp
    on the deck output now, after the tanh -- upstream, the saturator would
    regenerate exactly the partials the low-pass removed. The in-loop pole is
    fixed at kDampFixedHz: it is ha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
    [feed_config.h]
2026-08-19 bench(feed): the FEED worst case was pricing a silent deck
    The new FILT mapping fades the deck to silence over the last fifth of the
    left half, and `inst_feed_engine_worst` sat at exactly -1. The ring, the
    tanh and the SVF still ran, but Grit, Comp, the center reverb and the
    master limiter were all priced on zeros. Moved to -0.4, the darkest
    cutoff that does not fade -- the SVF costs the same at every cutoff, so
    the value is chosen for the deck emitting, not for the filter.
    Also commits the capture that found it, stale headline row and all: it
    is what the clean-tree guard had to swallow to get here, and the drift
    it shows (unchanged-checksum rows moving -4.59% to +2.33% on a relink)
    is the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
    [2026-08-19-5130bd2-feed-axi-o2-patch_sm-usb.csv]
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2026-08-19 fix(feed): the glide arrives at zero, and the filter stops ringing on nothing
    Two denormal sources on FEED's path, both permanent while a deck is quiet,
    and neither visible from reading the code.
    FeedBank's glide. set_target recomputes the slope from the CURRENT value
    and re-arms _slope_left, and FeedEngine pushes it every control tick --
    so the snap at the end of process() never fires and the amplitude
    converges geometrically instead of arriving. Heading for zero that lands
    in the subnormal range and stays. kArriveEps snaps it when the remaining
    travel falls under 1e-9, at the control rate, so the audio path is
    untouched. The increments went subnormal with it, which is why a
    SOUNDING deck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
    [run.py]
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2026-08-19 bench(feed): silence is now the cheap state, measured on the board
    inst_feed_engine_idle 75.64 % / 76.77 % against inst_feed_engine_worst
    77.70 % / 83.32 % in the same image. Silence below sound is what a
    working engine looks like; the avg-to-max spread says the same thing
    from the other side, 1.5 % on the idle row against 7.2 % on the
    sounding one.
    The ARM factor for the DEFECT stays unmeasured and the doc says so:
    1.65x is a desktop number and this image has no broken engine to
    compare against. It would cost a commit of a deliberately reverted
    engine plus a board round, and the fix does not need it.
    [2026-08-19-500775c-feed-axi-o2-patch_sm-usb.csv]
2026-08-19 bench(feed): P sweep point 3/3 -- kPairs = 8, and point 1's capture
    P=2 read feed_pairs 39110 avg / 40354 max, inst_feed_engine_worst
    69.00 % / 74.00 %. With the P=4 capture already in the tree that is
    19033 cycles per pair and ~1000 fixed, so the row is very nearly pure
    per-pair cost. P=8 is the linearity check.
    [2026-08-19-f836a32-feed-axi-o2-patch_sm-usb.csv]
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
